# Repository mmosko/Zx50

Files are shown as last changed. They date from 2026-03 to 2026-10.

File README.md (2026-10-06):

# Zx50 Distributed Computer

> **A retro-modern, modular computing platform built around the Zilog Z80 microprocessor — featuring paged virtual
memory, high-speed Shadow DMA, and FPGA coprocessing.**

---

## 1. Welcome to the Zx50

The **Zx50** is a custom, modular computing architecture that marries the classic 8-bit computing ethos of the
late-1970s and 1980s with modern high-speed digital engineering.

At the heart of the system is the **Zilog Z80** microprocessor (inducted into
the [IEEE Spectrum Chip Hall of Fame](https://spectrum.ieee.org/chip-hall-of-fame-zilog-z80-microprocessor),
see the official [Zilog Z80 Datasheet](https://www.zilog.com/docs/z80/um0080.pdf)). 
The Zx50 reimagines the Z80 as a modern distributed computing workstation.

### What makes the Zx50 "Retro-Modern"?

* **Bare-Metal Simplicity**: The CPU executes pure, unadulterated Z80 machine code. You can program it in assembly, C,
  or native BASIC just like classic machines.
* **Breaking the 64KB Limit**: A custom hardware Memory Management Unit (MMU) implemented in a CPLD provides 4KB paged
  virtual memory across 1MB+ of physical SRAM.
* **Dual-Bus Highway**: In addition to the standard Z80 bus, a dedicated **40 MHz Shadow DMA Bus** streams data (network
  packets, disk blocks, and peer-to-peer memory transfers) in the background without halting the Z80.
* **Hardware Acceleration**: A modern FPGA coprocessor offloads 32-bit and 64-bit floating-point math, emulating the
  vintage AMD Am9511 APU with single-cycle lookups.
* **Deep Visibility**: Built-in microcontroller instrumentation (RP2040 and Microchip PIC) allows real-time bus
  snooping, cycle-by-cycle single stepping, and telemetry via an active front panel and bus probe.

Zx50 Bush Architecture

---

## 2. Core Silicon & Chip Manifest

The Zx50 blends period-accurate Zilog NMOS/CMOS silicon with modern programmable logic and companion microcontrollers:

| Chip / Component | Technology | Primary Role in Zx50 |
|:---|:---|:---|
| **Zilog Z84C0020** | CMOS CPU | **Central Processor**: Runs at 8 MHz – 10 MHz with 16-bit addressing and an 8-bit data path. |
| **Zilog Z84C30** | CMOS CTC | **Counter/Timer Circuit**: 4 independent channels generating periodic system ticks and baud rate clocks. |
| **Zilog Z84C40** | CMOS DART/SIO | **Dual Serial Controller**: Dual-channel serial communications (Port 0 for USB console, Port 1 for RS-232) supporting IM 2 vectored interrupts. |
| **Microchip ATF1508** | 5V CPLD | **Memory Controller & MMU**: Address Translation Latch (ATL) mapping 64KB logical address space into 16 independent 4KB pages backed by 1MB+ SRAM. |
| **Lattice MachXO2 / MachXO3** | Flash FPGA | **Math Coprocessor & SmartNIC**: 32-bit/64-bit floating point APU emulation, fast BRAM LUT math, and future LVDS RDMA distributed clustering. |
| **WIZnet W5300** | Hardwired TCP/IP | **10/100 Ethernet Controller**: Memory-mapped window for wire-speed network packet streaming via Z80 `LDIR`/`LDDR` block transfers. |
| **WCH CH376S** | Mass Storage IC | **USB Host & SD Card Controller**: Hardware FAT16/FAT32 file manager mapped into the Z80 I/O space. |
| **Raspberry Pi RP2040** | Dual ARM Cortex-M0+ | **Instrumentation & Display**: Drives the Front Panel display/switches and coordinates circular trace buffers on the Bus Probe. |
| **Microchip PIC18F4620** | 8-bit MCU | **Real-Time Bus Interface**: Works alongside the RP2040 on the Bus Probe for cycle sampling, pin toggling, and non-intrusive bus analysis. |

---

## 3. System Topology & Card Placement

The Zx50 chassis utilizes an 8-slot passive backplane bus.

### Chassis Slot Tour

* **Card 0: Front Panel**: System human interface featuring a 20x4 LCD, step/run switches, bus activity
  LEDs, and an RP2040 controller mapped to I/O port `0x50`.
* **Card 1: CPU, Clock & FPU FPGA**: Houses the 10 MHz Z80 CPU, the Clock Mezzanine (generating system `ZCLK` and
  `MCLK`), and the FPGA floating-point coprocessor.
* **Card 2: Timer + Serial**: Combines the Z80 CTC and Z80 DART with a dedicated 7.3728 MHz baud oscillator, providing
  dual serial channels (FTDI USB and MAX232 RS-232).
* **Card 3: Memory 0 (Boot / Primary)**: Contains the ATF1508 CPLD MMU, 1MB fast 12ns SRAM, 512KB Flash boot ROM (with
  automatic ROM kill-switch upon boot jump), and Shadow Bus DMA interface.
* **Card 4: Memory 1 (Secondary / NUMA)**: Secondary memory card providing an additional 1MB SRAM and participating in
  peer-to-peer Shadow Bus memory transfers.
* **Card 5: NetStorage (Future)**: Dual-purpose network and storage adapter combining W5300 10/100 Ethernet and CH376S
  USB/SD mass storage with direct 40 MHz Shadow DMA support.
* **Card 6: Expansion Slot (Future)**: Dedicated slot for secondary CPU compute tiles, multi-node LVDS RDMA clustering
  (PGAS), or audio/video synthesizers.
* **Card 7: Bus Probe (Rev B)**: Diagnostic and telemetry card featuring CBT3251 high-speed multiplexers for
  non-intrusive bus snooping, an RP2040 trace analyzer, and a color LCD.

---

## 4. The Backplane Bus & Signals

The passive backplane links all cards across a single multi-conductor bus trunk:

| Bus Group | Width | Signals | Description |
|:---|:---|:---|:---|
| **Address** | 16-bit  | `A[15:0]` | Primary Z80 address bus. Snooped by memory card MMUs for 4KB page translations. |
| **Data** | 8-bit | `D[7:0]` | Primary Z80 bidirectional data bus. |
| **Control** | 15-bit  | `C[14:0]` | `~MREQ`, `~IORQ`, `~RD`, `~WR`, `~M1`, `~WAIT`, `~INT`, `~NMI`, `~RESET`, `~BUSRQ`, `~BUSAK`, `~HALT`, `~RFSH`, `IEI`, `IEO`. |
| **Shadow Data** | 9-bit | `SD[8:0]` | High-speed DMA data bus (8 data bits + 1 parity bit). |
| **Shadow Control** | 6-bit | `SC[5:0]` | `~S_EN` (Bus claim), `SRW` (Read/Write), `~SSTB` (Strobe), `~SINC` (Increment), `~S_BUSY` (Target stall), `~S_DONE` (Terminal count). |
| **GPIO** | 16-bit  | `GPIO[15:0]` | General purpose high-speed interconnect and node synchronization lines. |
| **Clocks** | 2 lines | `ZCLK`, `MCLK` | `ZCLK` (8–10 MHz) and `MCLK` (4x ZCLK = 32–40 MHz). |

### AC Bus Termination

To preserve signal integrity at high frequencies without the continuous DC power draw of passive pull-up resistors, all
signal lines are **AC terminated** at both physical ends of the backplane using RC networks tied to GND.

---

## 5. Synchronized Clock Domains

The Zx50 operates across three harmonic clock domains:

```
+-------------------------------------------------------------+
|  Oscillator (32 MHz - 40 MHz)                               |
+-------------------------------------------------------------+
         |                                           |
         v (divide by 4)                             v (direct)
+-------------------------+                 +-------------------------+
|  ZCLK (8 MHz - 10 MHz)  |                 |  MCLK (32 MHz - 40 MHz) |
|  Z80 CPU, CTC, DART     |                 |  Shadow DMA, MMU Timing |
+-------------------------+                 +-------------------------+
                                                         |
                                                         v (PLL / 3x - 4x)
                                            +-------------------------+
                                            |  FPGA (96 MHz - 160 MHz)|
                                            |  FPU Coprocessor Math   |
                                            +-------------------------+
```

1. **`ZCLK` (8 MHz – 10 MHz)**: The fundamental processor clock driving CPU instruction fetch and peripheral cycles.
2. **`MCLK` (32 MHz – 40 MHz = 4x `ZCLK`)**: The synchronous master clock coordinating high-speed burst DMA and CPLD
   state machines.
3. **`FPGA Clock` (96 MHz – 160 MHz = 3x to 4x `MCLK`)**: Synthesized internally inside FPGA coprocessors for
   single-cycle math and DSP acceleration.

---

## 6. High-Speed Shadow DMA

The **Shadow Bus** runs in parallel with the primary Z80 bus to eliminate I/O bottlenecks:

* **Cycle-Stealing Transfers**: Using fast 12ns SRAM, memory cards can service a DMA burst during intervals when the Z80
  is not accessing memory, avoiding `~BUSRQ`/`~BUSAK` pauses.
* **Direct Peer-to-Peer Streaming**: NetStorage can stream Ethernet packets or USB file blocks directly into memory card
  SRAM at **40 MHz** without routing bytes through CPU registers.
* **Deterministic Handshaking**: Uses hardware-level strobes (`~SSTB`, `~SINC`) with target stall flow control
  (`~S_BUSY`).

---

## 7. Software Ecosystem

* **[`zx50_monitor/`](file:///Users/marc/Documents/z80/Zx50/zx50_monitor)**: The self-hosting OS kernel and monitor.
  Transitions from SST39SF040 Flash ROM to SRAM via a hardware "Phantom Jump", featuring interrupt-driven asynchronous
  I/O and lock-free Single-Producer / Single-Consumer (SPSC) ring buffers.
* **[`msbasic/`](file:///Users/marc/Documents/z80/Zx50/msbasic)**: Microsoft BASIC adapted to run natively with full
  terminal, file, and hardware integration.
* **[`z80pack/`](file:///Users/marc/Documents/z80/Zx50/z80pack)**: Full emulator and development testbed for running and
  testing Zx50 software without physical hardware.

---

## 8. Repository Layout

* [`boards/`](file:///Users/marc/Documents/z80/Zx50/boards): KiCad hardware schematics, PCB layouts, and exported
  netlists.
* [`docs/hardware/`](file:///Users/marc/Documents/z80/Zx50/docs/hardware): Detailed hardware subsystem specifications,
  errata, and pinouts.
* [`firmware/`](file:///Users/marc/Documents/z80/Zx50/firmware): Microcontroller firmware for the RP2040 and Microchip
  PIC.
* [`mmu/`](file:///Users/marc/Documents/z80/Zx50/mmu): Verilog HDL code for the ATF1508 CPLD memory controller.
* [`fpu/`](file:///Users/marc/Documents/z80/Zx50/fpu): Verilog HDL and simulation testbenches for the MachXO FPGA math
  coprocessor.
* [`AGENTS.md`](file:///Users/marc/Documents/z80/Zx50/AGENTS.md): Architecture guidelines, design philosophy, and coding
  standards for AI assistants.

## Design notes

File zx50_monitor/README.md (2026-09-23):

# Zx50 Monitor - Session Summary & Resume State

## Programming EEPROM

Remember to add the `-s` flag so minipro will write an undersized ROM image.

```bash
minipro -p SST39SF040 -w monitor.bin -s
```

## 1. Accomplished

We have successfully transitioned from a basic ROM monitor to a stable, self-hosting Operating System kernel capable of downloading, verifying, and executing third-party user-space applications.

* **Dedicated Hardware Clock:** Upgraded the system clock from an Arbitrary Function Generator (AFG) to a dedicated 20MHz oscillator mezzanine. A hardware counter divides this to provide a mathematically perfect 50% duty cycle, 5.000 MHz `ZCLK` baseline.
* **Interrupt-Driven I/O Planning:** Designed a lock-free Single-Producer/Single-Consumer (SPSC) ring buffer architecture to transition the OS from polled serial I/O to fully asynchronous background processing. Engineered a solution to the "Lost Wakeup" race condition using the Z80's native `EI` delay and `HALT` instructions (Detailed in `TTY.md`).
* **Hardware Boot & Memory Paging:** Fixed the `LDIR` register clobbering bug. The physical silicon now successfully maps a 16KB copy window, copies the ROM to SRAM, and executes the "Phantom Jump" to swap out the ROM completely.
* **XMODEM Native File Transfer:** Built a robust, state-machine-driven XMODEM receiver (`apps/xmodem.z80`). It features hardware-accurate polling, adjustable timeout loops to prevent USB NAK-storms, and real-time padding.
* **The PCB & Memory Auditing:** Implemented a Process Control Block (PCB) table in Logical Page 0. When an app is downloaded, the kernel calculates a 16-bit cumulative checksum and logs its exact memory footprint.
* **Kernel Memory Protection:** The XMODEM loader now strictly enforces boundary checks. It actively rejects any attempt to load an executable below `0x2000`, safeguarding the kernel and stack from user-space corruption.
* **The `verify` Command:** Abstracted the checksum math into `pcb_verify.z80`. The CLI `v[erify] <name>` command seamlessly recalculates the payload in SRAM and compares it against the PCB to detect bit-rot or memory corruption before execution.
* **The Zx50 SDK:** Established a formal Page 0 jump table (`syscall.z80`) and wrote the `DEVGUIDE.md`. Developers can write hardware-agnostic standalone `.bin` applications (like `hello.z80`) that compile entirely outside the kernel tree.

## 2. Current System Architecture

### Hardware

Netlists are available under individual card projects in `zx50/boards/`.

| Slot | Card |
|:----:|:---:|
| n/a  | Zx50_Backplane_RevD | 
| n/a  | Zx50_FrontPanelDisplay |
| 1 | Zx50_Cpu_RevB1 + Zx50_Clock_Mezzanine_RevC |
| 2 | Zx50_Serial_RevB |
| 3 | Zx50_MemoryCard_RevA1 (with EEPROM) |
| 4 | (reserved 2nd memory card) |
| 5 | empty |
| 6 | Zx50_FrontPanelCard_RevB |
| 7 | Zx50_Bus_Probe_RevB |
| 8 | empty |

Note: 
- slot 8 has some oscilliscope probes on ZCLK and MCLK. 
- Bus Analyzer is connected to bus probe Z80 Data (J16) and Z80 Contro (J17)l

* **System Clock:** 10.000 MHz `ZCLK` (Divided from 40MHz `MCLK`).
* **Console SIO (Port A):** Command `0x86`, Data `0x84`.
* **Debug SIO (Port B):** Command `0x87`, Data `0x85`. 
* **LCD Front Panel:** Port `0x50`. Mapped to the blue UI display.
* **MMU (Port 0x30):** 4KB physical pages mapped to 16 logical windows.
* **Kernel RAM Layout:** * `0x0000 - 0x0FFF`: The Operating System, PCB Table, and Jump Table API.
  * `0x1000 - 0x1FFF`: The Stack (grows downward from `0x2000`).
  * `0x2000 - 0xFFFF`: User Space / Transient Program Area (TPA).

## 3. Code Layout

The project enforces a strict separation of concerns between the kernel, the shell, built-in apps, and user-space binaries.

```text
zx50_monitor/
├── apps/               # Third-party user-space programs
│   ├── DEVGUIDE.md     # SDK documentation and memory contracts
│   └── hello.z80       # Example standalone application
├── kernel/             # Core OS components
│   ├── apps/           # Built-in kernel utilities
│   │   ├── ddt.z80     # Debugger
│   │   └── xmodem.z80  # Serial file transfer protocol
│   ├── io/             # I/O related activities
│   |   ├── io.z80      # Hardware drivers (SIO, LCD)
│   |   └── ring_buffer.z80 # Lock-free SPSC memory queues
│   ├── pcb/            # Process Control Block logic
│   │   ├── pcb_verify.z80
│   │   └── pcb.z80
│   ├── defines.z80     # System-wide memory & port constants
│   ├── hex.z80         # Hexadecimal parsing & math
│   └── strings.z80     # String manipulation
├── shell/              # Command Line Interface
│   ├── cli.z80         # Main prompt and routing loop
│   ├── cmd_list.z80    # 'l' command
│   ├── cmd_run.z80     # 'r' command
│   ├── cmd_verify.z80  # 'v' command
│   └── readline.z80    # Buffer and backspace handling
├── monitor.z80         # Main bootloader, MMU init, and API Jump Table
├── syscall.z80         # The SDK include file for user apps
├── sio_emulator.js     # DeZog hardware simulation logic
├── sio_ui.html         # DeZog interactive terminal UI
├── README.md           # This file
└── TTY.md              # OS Asynchronous Serial / TTY Architecture Plan
```

## 4. Next Steps (When Resuming)

1. **Implement Ring Buffers:** Integrate the `ring_buffer.z80` logic into the kernel, allocate the 4 instances in Page 0 RAM, and update the syscalls (`Sys_ReadChar`, `Sys_PrintChar`) to use the blocking `HALT` wrappers.
2. **SIO Interrupt Configuration:** Refactor SIO initialization (`io.z80`) to enable IM2 interrupts with the "Status Affects Vector" routing.
3. **ISRs & Line Disciplines:** Write the SIO Rx/Tx Interrupt Service Routines. Implement the Raw/Cooked mode state tracking to allow the Rx ISR to intercept `0x03` (Ctrl+C) and forcibly break infinite loops, returning to the CLI.
4. **PCB Paging (Virtual Memory):** Add a `Page` byte to the `PCB_Entry`. Modify the `xm` and `run` commands to dynamically allocate free physical memory pages, map them into the `0x4000` execution window, and unmap them upon exit to achieve true process isolation.
5. **Multitasking Scheduler:** Leverage the CTC Channel 3 (100Hz) interrupt and the isolated physical pages to implement CP/M 3.0 / UNIX-style preemptive context switching between multiple concurrent applications.

# More on paging

* PCB Paging (Virtual Memory)

This is the holy grail. It turns your simple DOS into a true paged OS (like CP/M 3.0).

How it works: We add a Page byte to PCB_Entry. We write a simple memory manager that knows which of the 16 physical pages are in use.

The architecture: Every single app can be compiled to ORG 0x4000.

When you run xm, the OS finds a free physical page (e.g., Page 4), maps it to the 0x4000 window, downloads the file, and then unmaps it.

When you run the app, the OS looks at the PCB, maps physical Page 4 back into the 0x4000 slot, and CALLs it. When the app RETurns, the OS unmaps it.

The benefit: You never have to worry about memory address collisions again, and apps are completely sandboxed from one another.

## 5. Change History

### 2026-09-13: Serial Driver & Boot Interrupt Fixes
* **Decoupled RTS/CTS Hardware Handshaking:** Removed `SIO_WR3_AUTO_EN` (Auto Enables) from Channel A (Console) and Channel B (Debug) receiver configurations in `kernel/io/serial.z80`. The SIO transmitter now operates freely without requiring an external active-low assertion on `~CTS`, and the receiver does not require `~DCD`.
* **Resolved Premature Boot Interrupts:** Removed `DI` and `EI` instructions from `PrintStringLCD` and `PrintNullStringLCD` in `kernel/io/lcd.z80`. Previously, printing the initial memory boot banner triggered `EI` before the Interrupt Vector Table (`I`), `IM 2`, CTC, and SIO vector base were initialized.
* **Added `SIO_CMD_RST_TX_INT` to `SIO_A_Tx_ISR`:** Added WR0 command `0x28` (`SIO_CMD_RST_TX_INT`) to the `.buffer_empty` handler in `SIO_A_Tx_ISR` to formally reset the SIO's internal transmit interrupt pending latch when the ring buffer runs dry.
* **Dynamic Tx Interrupt Enabling:** Changed `Init_SIO` and `SetTermMode_Inner` so Channel A starts with Tx interrupts disabled in WR1. `Console_Tx` dynamically enables `SIO_WR1_TX_INT_EN` only when bytes are queued in `PORT_A_TX_RB`, and `SIO_A_Tx_ISR` disables it upon draining.
* **Disabled Unused Channel B Tx Interrupts:** Cleared `SIO_WR1_TX_INT_EN` from Channel B, as debug output is synchronously polled via `Debug_Tx`.

## 6. Hardware TODOs & Board Rework

* [ ] **Zx50_Serial_RevB RTS/CTS Handshake Support:**
  * **`DCDA` (Pin 19):** Currently unconnected/floating on `IC2`. Tie to GND or add a 10k pull-down to prevent the receiver from stalling when `Auto Enables` is active.
  * **`CTSA` (Pin 18):** Currently routed only to header `J4 pin 5` and `J3 pin 7` without a pull-down resistor. Add a 10k pull-down so the transmitter remains enabled when connecting via simple 3-wire serial cables (TX/RX/GND).
  * **Firmware Auto-Enables:** Once the pull-downs or jumper options are verified on the board, restore `SIO_WR3_AUTO_EN` in `kernel/io/serial.z80` to re-enable optional hardware flow control.

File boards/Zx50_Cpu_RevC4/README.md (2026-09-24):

# Zx50 CPU Card (Rev C2)

## 1. Overview

This is the primary CPU board for the Zx50 8-slot passive backplane system. It hosts the Z80 microprocessor (running at 5 MHz to 10 MHz) and acts as the master controller for the primary bus.

Revision C2 updates the design with an upgraded **Math and Stack Coprocessor Cluster** mounted on the bottom side beneath the clock mezzanine shield, expanding private coprocessor memory to **32 KB** and introducing a **12 ns high-speed SRAM** to guarantee single-cycle memory operations at 40 MHz.

Crucially, this board coexists with the **Zx50 Shadow Bus** architecture. It features a hardware-level "firewall" that allows a secondary master (like a Pi Pico on the Bus Probe or Front Panel card) to request the bus via `~BUSRQ`. When the Z80 yields (`~BUSAK`), the CPU card instantly severs itself from the backplane, allowing the secondary master to perform high-speed 40 MHz DMA transfers without electrical contention.

---

## 2. Core Architecture & Logic Families

### The CPU

* **Z80 Microprocessor (`U4`):** Zilog `Z84C00xxP` CMOS variant in a 40-pin DIP package (socketed).

### The Transceiver Firewall (`SN74ABT245BN`)

To drive the heavy capacitance of the 8-slot backplane, this board uses four **`SN74ABT245BN`** octal bus transceivers (`U2`, `U3`, `U5`, `U7`) with high-drive capability. A unified BOM of four '245s optimizes PCB trace routing across all 32 backplane lines.

* **Convention:** "A-Ports" face the Z80; "B-Ports" face the Backplane.
* **Address Bus (`U2`, `U3`):** Direction (`DIR`) is hardwired to `+5V` (A $\rightarrow$ B only).
* **Control Bus (`U7`):** Direction (`DIR`) is hardwired to `+5V` (A $\rightarrow$ B only). *(Unused input `A8` is tied to GND via a 10k$\Omega$ resistor `R2` to prevent CMOS floating-gate oscillation)*.
* **Data Bus (`U5`):** Direction (`DIR`) is dynamically controlled by read/acknowledge steering logic (`D_DIR` driven by `U8` / `R8`). This switches the transceiver to an input state (B $\rightarrow$ A) during standard memory/IO reads or Interrupt Acknowledge (`INTA`) cycles.
* **Isolation (`~OE`):** The `~OE` pins of all four transceivers are driven by inverted `~BUSAK` (`/BUSAK` from `U1` pin 4).

### Glue Logic & Bus Coordination

Discrete "Little Logic" and micro-logic ICs handle high-speed signal translation:

* **`74AHC1G14` (`U1` - Schmitt Inverter):** Inverts the Z80's active-low `~BUSAK` signal to drive the active-low `~OE` pins of the transceiver wall.
* **`74AHCT74` (`U9` - Dual D Flip-Flop):** Latches timing states for wait-state generation.
* **`74AHCT132` (`U10` - Quad Schmitt NAND):** Handles pulse shaping and step-logic gating for debugging.
* **`74LVC1G3208` (`U8` - 3-Input OR-AND Combo):** Manages direction and enable logic for auxiliary bus controls.

---

## 3. Hardware Wait-State Generator (`wait_gen`) Subsystem

The board incorporates a dedicated hardware wait-state generator to support single-step debugging and cycle stretching during fast coprocessor or backplane operations:

* **Dual D Flip-Flop (`SN74AHCT74DRG4` / `U9`):** Latches bus cycle transitions relative to `ZCLK` and `~M1`/`~IORQ`/`~MREQ` edges.
* **Quad Schmitt-Trigger NAND (`74AHCT132` / `U10`):** Provides noise-tolerant pulse shaping and single-step gate logic.
* **Open-Drain Output (`2N7002-7-F` N-Channel MOSFET / `Q2`):** Drives the active-low `~WAIT` line without contention, allowing other cards or the CPLD to safely assert `~WAIT`.
* **Modes Supported:**
1. **Single-Step Execution:** Holds `~WAIT` low at $T_2$/$T_3$ until a manual step pulse is received from the Clock Mezzanine (`J3`) or Front Panel (`J4`).
2. **Programmable Cycle Stretching:** Generates accurate 1-cycle hold states for memory or I/O windows.

---

## 4. Integrated Math & Stack Coprocessor Cluster (Bottom Layer)

Mounted entirely on the back side of the board beneath the Clock Mezzanine copper shield, a high-performance CPLD cluster operates on a dedicated private memory bus.

```text
                  +-----------------------------------+
                  |   ATF1508AS CPLD (PLCC-84 / U11)  |
                  |   Dual Clocks: 20MHz MCLK / 5MHz ZCLK|
                  +-----+-----------------------+-----+
                        |                       |
           CA0-CA14     |                       |  CD0-CD7
         Private Address|                       |  Private Data
                        v                       v
            +-----------+-----------------------+-----------+
            |                                               |
            |   +-------------------+   +---------------+   |
            |   | SST39SF040 Flash  |   | IS61C256AL    |   |
            |   | 32KB Active (55ns)|   | 32KB Active   |   |
            |   | PLCC-32 (U13)     |   | SRAM 28-TSOP1 |   |
            |   +---------+---------+   +-------+-------+   |
            |             |                     |           |
            |             |     ~C_OE / ~C_WE   |           |
            |             +----------+----------+           |
            |                        |                      |
            |               ~F_CE <--+--> ~M_CE             |
            +-----------------------------------------------+

```

### 1. Central Controller (`ATF1508ASx-xxJx84` / `U11`)

* **Package:** 128-macrocell CPLD in an 84-pin PLCC surface-mount socket.
* **Dual Clock Architecture:** Driven by both **20/40 MHz `MCLK**` (`GCLK1`, Pin 83) and **5/10 MHz `ZCLK**` (`CLK`, Pin 2) from the clock mezzanine (`J3`). The internal state machine executes at `MCLK` speed, enabling sub-cycle arithmetic and table lookups before the Z80 samples data.
* **Features:** Hardware multiplication (Quarter-Square algorithm), fast division seed generation, 16.16 fixed-point ALU, trigonometric LUT queries, and custom DMA/stack frame acceleration.

### 2. Private Memory Architecture (Zero `~BUSREQ` Contention)

The CPLD manages its own dedicated private address (`CA0`–`CA14`) and data (`CD0`–`CD7`) buses, isolating coprocessor memory operations from the primary Z80 system bus:

* **Expanded Private Address Space (32 KB):** A full 15-bit address bus (`CA0`–`CA14`) provides **32 KB** of addressable private memory. Upper unused address lines (`A15`–`A18`) on the Flash ROM (`U13`) are tied directly to **`GND`** to guarantee static CMOS levels.
* **Private Flash/EEPROM (`SST39SF040` / `U13`):** 32 KB active window (55 ns NOR Flash) in a 32-pin PLCC footprint (`CONN_PLCC-32-AT-SMT_ADM`). Stores non-volatile lookup tables (Quarter-Square $f(n)=\lfloor n^2/4 \rfloor$, sine/cosine maps, logarithmic tables, reciprocal seeds).
* **Private High-Speed SRAM (`IS61C256AL-12TLI` / `U12`):** 32 KB active window (12 ns High-Speed Static RAM) in a 28-pin TSOP-I footprint. Operates as a private scratchpad, hardware stack frame storage, or modifiable shadow RAM.
* **Consolidated Control Busses:** Read enable (`~C_OE`, Pin 45) and write strobe (`~C_WE`, Pin 46) are shared across both memory ICs. Access targeting is handled via dedicated Chip Enable lines (`~M_CE` on Pin 44 for SRAM; `~F_CE` on Pin 68 for Flash).
* **Pull-Up Protection:** `~M_CE` and `~F_CE` lines are fitted with $10\text{ k}\Omega$ pull-up resistors (`R7`, `R10`) to $+5\text{V}$ to keep both memory chips deselected and High-Z during power-up or CPLD JTAG re-programming.

### 3. Private Memory Access Speed Selector (`J8` - `MEM SPD`)

To support both 20 MHz and 40 MHz `MCLK` speeds without requiring CPLD bitstream re-flashing:

* **Header (`J8`):** 2-pin (1x2) 2.54mm pin header connected to CPLD Pin 81 (`I/O/GCLK3`) with a $10\text{ k}\Omega$ pull-up resistor (`R5`) to $+5\text{V}$.
* **Jumper Open (High / Default):** Standard mode.
* **Jumper Shorted to GND (Low):** High-speed 1-cycle pipeline selection.

### 4. JTAG In-System Programming

* **Header (`J7`):** 6-pin (1x6) 2.54mm male header.
* **Pinout:** $+5\text{V}$ (Pin 1), `GND` (Pin 2), `TMS` (Pin 3), `TDO` (Pin 4), `TDI` (Pin 5), `TCLK` (Pin 6). Compatible with Waveshare USB-JTAG converters and OpenOCD.
* **Offline Option:** The PLCC-32 Flash chip can be extracted and programmed offline using a T48 / TL866-3G universal programmer.

---

## 5. Power-On Reset (POR) Subsystem

Handled by a **Microchip `MCP1316MT-46LE/OT**` Supervisor IC (SOT-23-5, `U6`).

* **Boot Delay:** Imposes a ~200 ms delay on power-up to allow bulk capacitors ($100\,\mu\text{F}$ `C9`) to charge and peripheral clock sources/Picos to initialize before releasing `~RESET`.
* **Threshold:** 4.6V trip point for brown-out protection.
* **Open-Drain Output:** Safely drives the shared `~RESET` rail (`Pin 1`).
* **Manual Reset (`SW1`):** Tactile button connected to `~MR` (`Pin 3`) for debounced hardware reset during bench testing.

---

## 6. 6-Layer Stackup & PCB Routing Strategy

Revision C2 uses a **6-layer stackup** to accommodate the high-density coprocessor cluster beneath the top-side clock shield without interfering with front-side copper:

| Layer | Type | Dedicated Function |
| --- | --- | --- |
| **Layer 1 (Top)** | Signal / Plane | Primary Z80 component traces, Clock Mezzanine RF shield copper ground pour |
| **Layer 2 (GND)** | Power Plane | Continuous $GND$ reference plane |
| **Layer 3 (Inner 1)** | Signal | **Private Coprocessor Bus:** `CA0`–`CA14`, `CD0`–`CD7`, and private control lines (`~M_CE`, `~F_CE`, `~C_OE`, `~C_WE`) |
| **Layer 4 (Inner 2)** | Signal | **Z80 Bus Ingest:** Taps `A0`–`A15`, `D0`–`D7`, and control lines from `U4` to the CPLD |
| **Layer 5 (VCC)** | Power Plane | Continuous $+5\text{V}$ power distribution plane |
| **Layer 6 (Bottom)** | Signal / SMT | Bottom-mounted SMT footprints: ATF1508AS PLCC-84 (`U11`), SST39SF040 PLCC-32 (`U13`), IS61C256AL TSOP-I-28 (`U12`) |

---

## 7. Interfaces & Connectors

| Connector | Type | Description |
| --- | --- | --- |
| **`J1` - Backplane** | 80-Pin Edge Connector | Standard Zx50 2.54mm bus interface. |
| **`J2` - Bus Connect / Step Tap** | 2x2 Pin Socket | Tap for `AUX` (Pin 80), `GPIO15`, `~STEP`, and `~RUN` signals. |
| **`J3` - Clock Mezzanine** | 2x5 Socket (2.54mm) | Ingests `MCLK` (20/40 MHz), `CLK` (5/10 MHz ZCLK), and `~STEP` signals. |
| **`J4` - Front Panel** | 2x5 Right-Angle IDC | Interfaces status LEDs (`RUN`, `HALT`), `~RESET`, `~STEP`, and power lines. |
| **`J5` - TP_D_DIR Debug** | 1x2 Header (2.54mm) | Hardware tap for Data Bus Direction monitoring and GND test point. |
| **`J6` - TP_BUSAK Debug** | 1x2 Header (2.54mm) | Hardware tap for `~BUSAK` signal observation. |
| **`J7` - Coprocessor JTAG** | 1x6 Header (2.54mm) | In-System Programming header for the ATF1508AS CPLD (`+5V`, `GND`, `TMS`, `TDO`, `TDI`, `TCLK`). |
| **`J8` - MEM SPD Jumper** | 1x2 Header (2.54mm) | Hardware jumper for private memory access speed selection (`Pin 81` / `R5`). |

---

## 8. Estimated Power Consumption Analysis

Operating at $5\text{V}$, the Rev C2 CPU card draws a typical active current of **~170 mA (~0.85 W)** and a worst-case peak switching current of **~280 mA (~1.40 W)**. The power load is split between the primary Z80 CPU subsystem and the high-speed coprocessor cluster.

### A. Primary CPU & Bus Interface Subsystem

| Component | Part Number | Qty | Typ. Current | Max Current | Notes |
| --- | --- | --- | --- | --- | --- |
| **Z80 CPU (10 MHz)** | `Z84C00xxP` | 1 | 10 mA | 20 mA | CMOS low-power core |
| **Bus Transceivers** | `SN74ABT245BN` | 4 | 15 mA | 40 mA | Drives 8-slot backplane capacitance |
| **Wait-State Logic** | `74AHCT74` / `132` | 2 | 8 mA | 15 mA | Dual D-FF & Schmitt NAND gates |
| **Glue Logic & Supervisor** | `74AHC1Gxx` / `MCP1316` | 5 | 3 mA | 5 mA | SOT-23 micro-logic & reset controller |
| **Status LEDs & Pull-ups** | `PWR`, `HALT` LEDs | 2 | 8 mA | 10 mA | ~$470\Omega$ current limiting |
| **Subtotal (CPU Side)** |  |  | **~44 mA** | **~90 mA** | **~0.22 W Typ / 0.45 W Max** |

### B. Coprocessor Cluster Subsystem (Bottom Layer)

| Component | Part Number | Qty | Typ. Current | Max Current | Notes |
| --- | --- | --- | --- | --- | --- |
| **CPLD (20/40 MHz MCLK)** | `ATF1508ASx-xxJx84` | 1 | 65 mA | 100 mA | Dynamic $I_{CC}$ scales with MCLK frequency |
| **Private SRAM (12 ns)** | `IS61C256AL-12TLI` | 1 | 15 mA | 30 mA | Active read/write state |
| **Private Flash (55 ns)** | `SST39SF040` | 1 | 15 mA | 30 mA | Active table read state |
| **Subtotal (Coprocessor)** |  |  | **~95 mA** | **~160 mA** | **~0.48 W Typ / 0.80 W Max** |

### C. Total Card Power Summary

* **Typical Active Load:** **139 mA – 170 mA** (~0.70 W – 0.85 W @ 5V)
* **Maximum Peak Load:** **250 mA – 280 mA** (~1.25 W – 1.40 W @ 5V)

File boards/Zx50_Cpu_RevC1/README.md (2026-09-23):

# Zx50 CPU Card (Rev C1)

## 1. Overview

This is the primary CPU board for the Zx50 8-slot passive backplane system. It hosts the Z80 microprocessor (running at 5 MHz to 10 MHz) and acts as the master controller for the primary bus.

Revision C1 updates the design to a **6-layer stackup**, integrating a high-performance **Math and Stack Coprocessor Cluster** mounted on the bottom side beneath the clock mezzanine shield, along with a dedicated hardware **Wait-State Generator (`wait_gen`)**.

Crucially, this board coexists with the **Zx50 Shadow Bus** architecture. It features a hardware-level "firewall" that allows a secondary master (like a Pi Pico on the Bus Probe or Front Panel card) to request the bus via `~BUSRQ`. When the Z80 yields (`~BUSAK`), the CPU card instantly severs itself from the backplane, allowing the secondary master to perform high-speed 40 MHz DMA transfers without electrical contention.

---

## 2. Core Architecture & Logic Families

### The CPU
* **Z80 Microprocessor (`U4`):** Zilog `Z84C00xxP` CMOS variant in a 40-pin DIP package (socketed).

### The Transceiver Firewall (`SN74ABT245BN`)
To drive the heavy capacitance of the 8-slot backplane, this board uses four **`SN74ABT245BN`** octal bus transceivers (`U2`, `U3`, `U5`, `U7`) with high-drive capability. A unified BOM of four '245s optimizes PCB trace routing across all 32 backplane lines.
* **Convention:** "A-Ports" face the Z80; "B-Ports" face the Backplane.
* **Address Bus (`U2`, `U3`):** Direction (`DIR`) is hardwired to `+5V` (A $\rightarrow$ B only).
* **Control Bus (`U7`):** Direction (`DIR`) is hardwired to `+5V` (A $\rightarrow$ B only). *(Unused input `A8` is tied to GND via a 10k$\Omega$ resistor `R2` to prevent CMOS floating-gate oscillation)*.
* **Data Bus (`U5`):** Direction (`DIR`) is dynamically controlled by read/acknowledge steering logic (`D_DIR` driven by `U8` / `R8`). This switches the transceiver to an input state (B $\rightarrow$ A) during standard memory/IO reads or Interrupt Acknowledge (`INTA`) cycles.
* **Isolation (`~OE`):** The `~OE` pins of all four transceivers are driven by inverted `~BUSAK` (`/BUSAK` from `U1` pin 4).

### Glue Logic & Bus Coordination
Discrete "Little Logic" and micro-logic ICs handle high-speed signal translation:
* **`74AHC1G14` (`U1` - Schmitt Inverter):** Inverts the Z80's active-low `~BUSAK` signal to drive the active-low `~OE` pins of the transceiver wall.
* **`74AHCT74` (`U9` - Dual D Flip-Flop):** Latches timing states for wait-state generation.
* **`74AHCT132` (`U10` - Quad Schmitt NAND):** Handles pulse shaping and step-logic gating for debugging.
* **`74LVC1G3208` (`U8` - 3-Input OR-AND Combo):** Manages direction and enable logic for auxiliary bus controls.

---

## 3. Hardware Wait-State Generator (`wait_gen`) Subsystem

The board incorporates a dedicated hardware wait-state generator to support single-step debugging and cycle stretching during fast coprocessor or backplane operations:
* **Dual D Flip-Flop (`SN74AHCT74DRG4` / `U9`):** Latches bus cycle transitions relative to `ZCLK` and `~M1`/`~IORQ`/`~MREQ` edges.
* **Quad Schmitt-Trigger NAND (`74AHCT132` / `U10`):** Provides noise-tolerant pulse shaping and single-step gate logic.
* **Open-Drain Output (`2N7002-7-F` N-Channel MOSFET / `Q2`):** Drives the active-low `~WAIT` line without contention, allowing other cards or the CPLD to safely assert `~WAIT`.
* **Modes Supported:**
  1. **Single-Step Execution:** Holds `~WAIT` low at $T_2$/$T_3$ until a manual step pulse is received from the Clock Mezzanine (`J3`) or Front Panel (`J4`).
  2. **Programmable Cycle Stretching:** Generates accurate 1-cycle hold states for memory or I/O windows.

---

## 4. Integrated Math & Stack Coprocessor Cluster (Bottom Layer)

Mounted entirely on the back side of the board beneath the Clock Mezzanine copper shield, a high-performance CPLD cluster operates on a dedicated private memory bus.

```text
                  +-----------------------------------+
                  |   ATF1508AS CPLD (PLCC-84 / U11)  |
                  |   Dual Clocks: 20MHz MCLK / 5MHz ZCLK|
                  +-----+-----------------------+-----+
                        |                       |
           CA0-CA13     |                       |  CD0-CD7
         Private Address|                       |  Private Data
                        v                       v
            +-----------+-----------------------+-----------+
            |                                               |
            |   +-------------------+   +---------------+   |
            |   | SST39SF040 Flash  |   | IS61C5128AS   |   |
            |   | 16KB Active (55ns)|   | 16KB Active   |   |
            |   | PLCC-32 (U13)     |   | SRAM 32-SOP   |   |
            |   +---------+---------+   +-------+-------+   |
            |             |                     |           |
            |             | ~F_CE / ~F_OE / ~F_WE| ~M_CE / ~M_OE / ~M_WE
            +-------------+---------------------+-----------+
```

### 1. Central Controller (`ATF1508ASx-xxJx84` / `U11`)
* **Package:** 128-macrocell CPLD in an 84-pin PLCC surface-mount socket.
* **Dual Clock Architecture:** Driven by both **20/40 MHz `MCLK`** (`GCLK1`, Pin 83) and **5/10 MHz `ZCLK`** (`CLK`, Pin 2) from the clock mezzanine (`J3`). The internal state machine executes at `MCLK` speed, enabling sub-cycle arithmetic and table lookups before the Z80 samples data.
* **Features:** Hardware multiplication (Quarter-Square algorithm), fast division seed generation, 16.16 fixed-point ALU, trigonometric LUT queries, and custom DMA/stack frame acceleration.

### 2. Private Memory Architecture (Zero `~BUSREQ` Contention)
The CPLD manages its own dedicated private address (`CA0`–`CA13`) and data (`CD0`–`CD7`) buses, isolating coprocessor memory operations from the primary Z80 system bus:
* **Private Address Space (16 KB):** A 14-bit address bus (`CA0`–`CA13`) provides 16 KB of addressable private memory space. Upper address lines (`A14`–`A18`) on both memory ICs are tied directly to **`GND`** to guarantee static CMOS levels and prevent floating pin oscillations.
* **Private Flash/EEPROM (`SST39SF040` / `U13`):** 16 KB active window (55 ns NOR Flash) in a 32-pin PLCC socket. Stores non-volatile lookup tables (Quarter-Square $f(n)=\lfloor n^2/4 \rfloor$, sine/cosine maps, logarithmic tables, reciprocal seeds).
* **Private SRAM (`IS61C5128AS-25QLI` / `U12`):** 16 KB active window (25 ns High-Speed Static RAM) in a 32-pin SOP footprint. Serves as private scratchpad, hardware stack frame storage, or modifiable shadow RAM.
* **Pull-up Protection:** `~M_CE` and `~F_CE` lines are fitted with $10\text{ k}\Omega$ pull-up resistors (`R7`, `R10`) to $+5\text{V}$ to keep both memory chips deselected and High-Z during power-up or CPLD JTAG re-programming.

### 3. Private Memory Access Speed Selector (`J8` - `MEM SPD`)
To support both 20 MHz and 40 MHz `MCLK` speeds without requiring CPLD bitstream re-flashing:
* **Header (`J8`):** 2-pin (1x2) 2.54mm pin header connected to CPLD Pin 81 (`I/O/GCLK3`) with a $10\text{ k}\Omega$ pull-up resistor (`R5`) to $+5\text{V}$.
* **Jumper Open (High / Default):** Selects **2-cycle private access pipeline** (safe access window for 40 MHz `MCLK` with 25 ns SRAM).
* **Jumper Shorted to GND (Low):** Selects **1-cycle private access pipeline** (fast mode for 20 MHz `MCLK`).

### 4. JTAG In-System Programming
* **Header (`J7`):** 6-pin (1x6) 2.54mm male header.
* **Pinout:** $+5\text{V}$ (Pin 1), `GND` (Pin 2), `TMS` (Pin 3), `TDO` (Pin 4), `TDI` (Pin 5), `TCLK` (Pin 6). Compatible with Waveshare USB-JTAG converters and OpenOCD.
* **Offline Option:** The PLCC-32 Flash chip can be extracted and programmed offline using a T48 / TL866-3G universal programmer.

---

## 5. Power-On Reset (POR) Subsystem

Handled by a **Microchip `MCP1316MT-46LE/OT`** Supervisor IC (SOT-23-5, `U6`).
* **Boot Delay:** Imposes a ~200 ms delay on power-up to allow bulk capacitors ($100\,\mu\text{F}$ `C9`) to charge and peripheral clock sources/Picos to initialize before releasing `~RESET`.
* **Threshold:** 4.6V trip point for brown-out protection.
* **Open-Drain Output:** Safely drives the shared `~RESET` rail (`Pin 1`).
* **Manual Reset (`SW1`):** Tactile button connected to `~MR` (`Pin 3`) for debounced hardware reset during bench testing.

---

## 6. 6-Layer Stackup & PCB Routing Strategy

Revision C1 uses a **6-layer stackup** to accommodate the high-density coprocessor cluster beneath the top-side clock shield without interfering with front-side copper:

| Layer | Type | Dedicated Function |
| :--- | :--- | :--- |
| **Layer 1 (Top)** | Signal / Plane | Primary Z80 component traces, Clock Mezzanine RF shield copper ground pour |
| **Layer 2 (GND)** | Power Plane | Continuous $GND$ reference plane |
| **Layer 3 (Inner 1)** | Signal | **Private Coprocessor Bus:** `CA0`–`CA13`, `CD0`–`CD7`, and private control lines (`~M_CE`, `~M_OE`, `~M_WE`, `~F_CE`, `~F_OE`, `~F_WE`) |
| **Layer 4 (Inner 2)** | Signal | **Z80 Bus Ingest:** Taps `A0`–`A15`, `D0`–`D7`, and control lines from `U4` to the CPLD |
| **Layer 5 (VCC)** | Power Plane | Continuous $+5\text{V}$ power distribution plane |
| **Layer 6 (Bottom)** | Signal / SMT | Bottom-mounted SMT footprints: ATF1508AS PLCC-84 (`U11`), SST39SF040 PLCC-32 (`U13`), IS61C5128AS SOP-32 (`U12`) |

---

## 7. Interfaces & Connectors

| Connector | Type | Description |
| :--- | :--- | :--- |
| **`J1` - Backplane** | 80-Pin Edge Connector | Standard Zx50 2.54mm bus interface. |
| **`J2` - Bus Connect / Step Tap** | 2x2 Pin Socket | Tap for `AUX` (Pin 80), `GPIO15`, `~STEP`, and `~RUN` signals. |
| **`J3` - Clock Mezzanine** | 2x5 Socket (2.54mm) | Ingests `MCLK` (20/40 MHz), `CLK` (5/10 MHz ZCLK), and `~STEP` signals. |
| **`J4` - Front Panel** | 2x5 Right-Angle IDC | Interfaces status LEDs (`RUN`, `HALT`), `~RESET`, `~STEP`, and power lines. |
| **`J5` - TP_D_DIR Debug** | 1x2 Header (2.54mm) | Hardware tap for Data Bus Direction monitoring and GND test point. |
| **`J6` - TP_BUSAK Debug** | 1x2 Header (2.54mm) | Hardware tap for `~BUSAK` signal observation. |
| **`J7` - Coprocessor JTAG** | 1x6 Header (2.54mm) | In-System Programming header for the ATF1508AS CPLD (`+5V`, `GND`, `TMS`, `TDO`, `TDI`, `TCLK`). |
| **`J8` - MEM SPD Jumper** | 1x2 Header (2.54mm) | Hardware jumper for 1-cycle vs 2-cycle private memory access speed selection (`Pin 81` / `R5`). |

---

## 8. Estimated Power Consumption Analysis

Operating at $5\text{V}$, the Rev C1 CPU card draws a typical active current of **~170 mA (~0.85 W)** and a worst-case peak switching current of **~280 mA (~1.40 W)**. The power load is split between the primary Z80 CPU subsystem and the high-speed coprocessor cluster.

### A. Primary CPU & Bus Interface Subsystem

| Component | Part Number | Qty | Typ. Current | Max Current | Notes |
| :--- | :--- | :---: | :---: | :---: | :--- |
| **Z80 CPU (10 MHz)** | `Z84C00xxP` | 1 | 10 mA | 20 mA | CMOS low-power core |
| **Bus Transceivers** | `SN74ABT245BN` | 4 | 15 mA | 40 mA | Drives 8-slot backplane capacitance |
| **Wait-State Logic** | `74AHCT74` / `132` | 2 | 8 mA | 15 mA | Dual D-FF & Schmitt NAND gates |
| **Glue Logic & Supervisor** | `74AHC1Gxx` / `MCP1316` | 5 | 3 mA | 5 mA | SOT-23 micro-logic & reset controller |
| **Status LEDs & Pull-ups** | `PWR`, `HALT` LEDs | 2 | 8 mA | 10 mA | ~$470\Omega$ current limiting |
| **Subtotal (CPU Side)** | | | **~44 mA** | **~90 mA** | **~0.22 W Typ / 0.45 W Max** |

### B. Coprocessor Cluster Subsystem (Bottom Layer)

| Component | Part Number | Qty | Typ. Current | Max Current | Notes |
| :--- | :--- | :---: | :---: | :---: | :--- |
| **CPLD (20/40 MHz MCLK)** | `ATF1508ASx-xxJx84` | 1 | 65 mA | 100 mA | Dynamic $I_{CC}$ scales with MCLK frequency |
| **Private SRAM (25 ns)** | `IS61C5128AS-25QLI` | 1 | 15 mA | 30 mA | Active read/write state |
| **Private Flash (55 ns)** | `SST39SF040` | 1 | 15 mA | 30 mA | Active table read state |
| **Subtotal (Coprocessor)** | | | **~95 mA** | **~160 mA** | **~0.48 W Typ / 0.80 W Max** |

### C. Total Card Power Summary
* **Typical Active Load:** **139 mA – 170 mA** (~0.70 W – 0.85 W @ 5V)
* **Maximum Peak Load:** **250 mA – 280 mA** (~1.25 W – 1.40 W @ 5V)

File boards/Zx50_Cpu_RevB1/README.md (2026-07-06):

# Zx50 CPU Card

## 1. Overview

This is the primary CPU board for the Zx50 8-slot passive backplane system. It hosts the Z80 microprocessor (running at
8 to 10 MHz) and acts as the master controller for the primary bus.

Crucially, this board is designed to coexist with the **Zx50 Shadow Bus** architecture. It features a hardware-level "
firewall" that allows a coprocessor (like a Pi Pico on the Bus Probe or Front Panel card) to request the bus via
`~BUSRQ`. When the Z80 yields (`~BUSAK`), the CPU card instantly severs itself from the backplane, allowing the Pico to
perform high-speed 40MHz DMA transfers without electrical contention.

## 2. Core Architecture & Logic Families

### The CPU

* **Z80 Microprocessor:** Zilog `Z84C00xxP` CMOS variant in a 40-pin DIP package.

### The Transceiver Firewall (`74AHCT245`)

To drive the heavy capacitance of the 8-slot backplane, standard `74HC` logic is insufficient. This board uses *
*`74AHCT245`** octal bus transceivers (±8mA drive current) for all bus interfacing.
To optimize PCB trace routing, a unified BOM of four '245s is used (rather than mixing in '244s).

* **Convention:** "A-Ports" face the Z80; "B-Ports" face the Backplane.
* **Address Bus (x2):** `DIR` is hardwired to `+5V` (A -> B only).
* **Control Bus (x1):** `DIR` is hardwired to `+5V` (A -> B only). *(Note: The unused `A8` input on this buffer is tied
  to GND via a 10kΩ pull-up to prevent CMOS floating-gate oscillation)*.
* **Data Bus (x1):** `DIR` is dynamically controlled by a dedicated read/acknowledge logic steering circuit. This
  ensures that the transceiver switches to an input state (B -> A) during standard memory/IO reads **or** during an
  Interrupt Acknowledge (INTA) cycle, preventing backplane bus contention.
* **Isolation (`~OE`):** The `~OE` pins of all four transceivers are driven by an inverted `~BUSAK` signal.

### Glue Logic & Bus Coordination

"Little Logic" SOT-23-5 discrete gates are used to handle high-speed bus control signal translation without the
footprint of full-sized DIP packages:

* **`74AHC1G14` (Schmitt-Trigger Inverter):** Inverts the Z80's active-low `~BUSAK` signal to correctly drive the
  active-low `~OE` pins of the transceiver wall.
* **`74AHC1G32` (2-Input OR Gate):** Monitors `~M1` and `~IORQ`. Its output drops LOW exclusively during an Interrupt
  Acknowledge (INTA) cycle.
* **`74AHC1G08` (2-Input AND Gate):** Compares the INTA state with the Z80's `~RD` line. The output connects directly to
  Pin 1 (`DIR`) of the Data Bus Transceiver, dropping the bus into Input mode whenever a hardware vector or memory read
  is requested.

## 3. Power-On Reset (POR) Subsystem

The Master Reset logic is completely handled by a **Microchip `MCP1318MT-46LE/OT`** Supervisor IC (SOT-23-5, Digi-Key:
`MCP1318MT-46LE/OTCT-ND`).

* **The Boot Delay:** It imposes a strict ~200ms delay on power-up. This guarantees the 1000µF backplane bulk
  capacitance is fully charged, the clock oscillators are stable, and the Pi Pico bootloaders on the peripheral cards
  have fully initialized before the Z80 takes its first step.
* **Voltage Threshold:** Trips at 4.6V to prevent brown-out corruption.
* **Open-Drain Output:** Safely shares the backplane's `~RESET` line with other cards that may pull the line low.
* **No Watchdog:** The `1318M` specifically omits the hardware watchdog timer (unlike the 1316M), preventing accidental
  Z80 reboots during extended Pi Pico DMA operations.
* **Local Button:** A right-angle tactile switch (`Omron B3F` / Digi-Key: `SW402-ND`) is wired to the `~MR` (Manual
  Reset) pin, providing perfect, capacitor-free hardware debouncing for bench testing.

## 4. Interfaces

* **J1 - Backplane:** Standard Zx50 80-pin Edge Connector.
* **J3 - Clock Mezzanine (2x5 Socket):** Receives `MCLK` (40MHz), `CLK` (10MHz ZCLK), and manages the async-latched
  `~STEP` signals from the Zx50 Clock Mezzanine module.
* **J4 - Front Panel (2x5 Header):** Mirrors the signals sent to the system Front Panel. Includes `RUN`, `~STEP`,
  `~RESET`, and `TX`/`RX` paths. The `~STEP` signal is routed down to the backplane's `AUX` pin (Pin 80) to coordinate
  with the Clock Mezzanine and Bus Probe.

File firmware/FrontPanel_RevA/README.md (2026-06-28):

# Zx50 Front Panel Firmware

## 1. Overview

This directory contains the MicroPython firmware for the Raspberry Pi Pico on the Zx50 Front Panel Controller card.

The firmware's primary responsibilities are:

- **Passive Bus Monitoring:** Reading the Z80's address, data, and status buses without halting the CPU and displaying
  this information in real-time on the front panel's dot-matrix displays.
- **Active I/O Device:** Acting as a target for Z80 `OUT` instructions, specifically capturing high-speed `OTIR` block
  transfers to a FIFO buffer for display on the character LCD.
- **Hardware Control:** Managing the front panel switches (`RUN`, `STEP`, `DISP_EN`) to control the display's behavior
  and, in the future, to control the Z80's `~WAIT` and `~RESET` lines.

## 2. Code Structure

The firmware is organized into several modules:

- `main.py`: The main application entry point. It contains the primary control loop, state management for the front
  panel switches, and orchestrates calls to the other modules.
- `pins.py`: Centralized definitions for all GPIO pin assignments and SPI bus configurations. This is the canonical
  source for hardware connections.
- `lcd.py`: Driver for the 4x20 character LCD. It handles the unique, bit-reversed, LSB-first SPI protocol required by
  the EA DIP205G-4NLED display.
- `leds.py`: Driver for the HCMS dot-matrix displays and the discrete status LEDs (driven by a 74HC595 shift register).
- `font.py`: Contains the 5x7 font data for rendering both standard ASCII characters and custom status glyphs on the
  HCMS displays.
- `z80_io.py`: Manages the high-speed interaction with the Z80 bus. It contains the interrupt service routine (`IRQ`)
  that captures data from `OTIR` instructions and places it into a shared FIFO.

## 3. Key Implementation Details & Maintenance Notes

This firmware has several particularities that are critical for maintenance and future development:

### Dynamic SPI Bus Configuration

The SPI bus (`SPI(0)`) is shared by two devices with incompatible SPI modes:

1. **LCD Display:** Requires `baudrate=500,000`, `polarity=1`, `phase=1`.
2. **HCMS Displays & LED Driver:** Require `baudrate=5,000,000`, `polarity=0`, `phase=0`.

To solve this, the `pins.py` module contains two functions, `setup_spi_for_lcd()` and `setup_spi_for_hcms_and_leds()`.
The respective driver modules (`lcd.py`, `leds.py`) are responsible for calling the appropriate setup function **before
** every SPI transaction to ensure the bus is in the correct mode.

### LCD Bit-Reversal Logic

The EA DIP205G-4NLED character display uses a non-standard, LSB-first serial protocol. The `lcd.py` driver emulates this
in software by using a pre-computed lookup table (`BIT_REVERSE_TABLE`) to reverse the bits of every byte before sending
it to the Pico's standard MSB-first SPI hardware. This is a critical piece of "twisted logic" that must be preserved for
the LCD to function.

### Switch-Based Display Logic

The main loop in `main.py` implements specific rules for updating the passive bus monitor displays:

- The `~DISP_EN` switch acts as a master enable. If high, no updates occur.
- When the `~RUN` switch is active (low), the display updates at a regular interval (`passive_update_interval`).
- When the `~RUN` switch is inactive (high), the system is in "Step Mode". The display updates only once when the mode
  is first entered, and thereafter only when the momentary `~STEP` switch is pressed.

## 4. Current Status

**Firmware Version:** 0.7

The firmware is considered feature-complete for its initial goals and is ready for hardware testing.

- **Immediate Next Step:** Board assembly needs to be completed to load and test the firmware on the physical hardware.

## 5. Future Work & Ideas

- **Remote Bus Monitoring via Wi-Fi:**
    - Enable the Pico's Wi-Fi module to connect to the local network.
    - Stream the bus status over a simple TCP socket (e.g., for `nc` or a custom client) or create a small embedded web
      page that mirrors the physical LCD and LEDs. This would allow for remote, headless monitoring of the Z80 system.
- **Z80 Control Implementation:**
    - Implement the logic to drive the Z80's `~WAIT` line based on the `RUN`/`STEP` switches to allow for true
      single-stepping and pausing of the CPU.
- **Full HCMS Display Implementation:**
    - Expand the `leds.py` and `font.py` modules to render the full Z80 address and data bus values on the dot-matrix
      displays, not just the status codes.

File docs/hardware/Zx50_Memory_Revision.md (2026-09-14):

# Architecture Transition: Moving to Lattice MachXO2

For a "V2" board revision, transitioning from a legacy 5V CPLD (like the Atmel ATF1508AS) to a modern 3.3V FPGA
architecture provides massive benefits in logic capacity, routing resources, and toolchain reliability. The recommended
upgrade path is the **Lattice MachXO2** family.

## 1. The Hardware: Lattice MachXO2

* **Target Part:** LCMXO2-1200HC (or similar).
* **Footprint:** Available in hand-solderable TQFP-100 or TQFP-144 packages, keeping PCB assembly accessible.
* **Logic Capacity:** Provides thousands of LUTs (Look-Up Tables) compared to the 128 macrocells of the ATF1508AS. This
  eliminates the routing congestion and pin-starvation issues encountered with the full DMA/Arbiter architecture.

## 2. 5V to 3.3V Level Shifting

The MachXO2 is strictly a **3.3V** device and is *not* 5V tolerant on its own.

* **The Solution:** Because the design already isolates the Z80 bus using 74ABT245 transceivers, transitioning to 3.3V
  is straightforward.
* By swapping the `74ABT245` chips for **`74LVC245`** or **`74ALVC164245`** transceivers, the buffers natively handle
  the 5V (Z80) to 3.3V (FPGA/SRAM) level translation. The FPGA safely operates entirely within a 3.3V domain.

## 3. The Toolchain: Open-Source Perfection

Moving to Lattice completely eliminates the reliance on 20-year-old proprietary DOS executables and Wine wrappers.

* **Synthesis & Routing:** The MachXO2 is fully supported by the modern open-source **Yosys + NextPNR (Project Trellis)
  ** toolchain.
* **Environment:** Native support for Linux and macOS.
* **Speed:** Lightning-fast synthesis and predictable, modern routing algorithms that do not crash on undefined states (
  `1'x`).

## 4. Architectural Consolidation (Bonus Benefit)

Because the MachXO2 contains dedicated internal Block RAM (BRAM), **the external ISSI SRAM chip used for the MMU Page
LUT can be completely eliminated**.

* The MMU translation tables can be mapped directly into the FPGA's internal memory.
* This frees up significant PCB real estate, removes an entire parallel memory bus (the `atl_data` and `atl_addr`
  traces), and dramatically simplifies the internal multiplexing logic.

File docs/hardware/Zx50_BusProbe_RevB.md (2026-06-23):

# Zx50 Bus Probe Rev B: Hardware Evolution & Optimization

This document outlines the transition from the Rev A "Breadboard-style" prototype to a high-performance Rev B production
card. The primary goals are to resolve the **10 MHz signal collapse** caused by high-resistance multiplexers and to
optimize the board footprint using Surface Mount Technology (SMT).

---

## 1. The Core Performance Fix: 5 $\Omega$ Switching

The Rev A prototype used **74HC4051** multiplexers, which exhibit an internal "On-Resistance" ($R_{on}$) of
approximately **80–100 $\Omega$**. When combined with bus and cable capacitance, this created an $RC$ low-pass filter
that "rounded" 10 MHz square waves into unusable "shark fins".

**Rev B Solution:**

* **Component:** **SN74CBT3251** (Digital Bus Switch).
* **Impact:** Reduces $R_{on}$ to **5 $\Omega$**, effectively eliminating the bottleneck and restoring sharp signal
  edges at 10 MHz.

---

## 2. Option A: The "Hand-Solder" Rev B

Designed for manual assembly using a standard soldering iron. This option uses **SOIC** packages with a **1.27mm pin
pitch**, which are significantly easier to handle than the high-density TQFP or QFN alternatives.

### Chip Selection (Hand-Solder)

| Function | Component | Package | Note |
|:---|:---|:---|:---|
| **Main MCU** | **PIC18F27Q43-I/SO** | 28-SOIC | 64MHz, Master Clock Generator, DMA. |
| **I/O Expander** | **MCP23S17-E/SO** | 28-SOIC | Uses 3 units to offload Z80 Address and Data buses. |
| **Bus MUX** | **SN74CBT3251DR** | 16-SOIC | Provides 5 $\Omega$ high-speed signal path. |
| **Transceiver**  | **74ABT245DW** | 20-SOIC | SOIC version of the ABT logic used in Rev A. |

**Architecture Change:** Since the 28-pin SOIC PIC has fewer pins than the 40-pin DIP, the **Z80 Data Bus**
is moved to a third SPI-based MCP23S17 expander.

---

## 3. Option B: The "Ultra-Compact" Rev B (JLC PCBA)

If utilizing professional PCBA services (like JLC), we can exploit high-density packaging to drastically reduce the card
size and potentially eliminate the need for multiple I/O expanders.

### Chip Selection (PCBA Optimized)

| Function | Component | Package | Advantage |
|:---|:---|:---|:---|
| **Main MCU** | **PIC18F47Q43-I/PT** | **44-TQFP**  | Restores full 40+ I/O pins in a 10x10mm area; eliminates 3rd expander. |
| **I/O Expander** | **MCP23S17-E/SS** | **28-SSOP**  | 0.65mm pitch; roughly 50% smaller than the SOIC version. |
| **Bus MUX** | **SN74CBT3251PWR** | **16-TSSOP** | Ultra-thin package; allows MUXes to be grouped tightly near the bus. |
| **Passives** | **0603 Metric** | SMD | Replaces bulky axial resistors/tantalums. |

**Size Reduction:** This move reduces the vertical height of the card by $\sim$40% and allows for a 4-layer PCB design,
providing a dedicated ground plane to further reduce the "Ghost Mode" ringing observed in Rev A.

---

## 4. Hardware Logic & Master Clock Master

In Rev B, the PIC moves from a "passive listener" to a **Clock Master**.

* **NCO/PWM:** The PIC generates `MCLK` and `CLK` natively, allowing the Python host to request "Step" or "Slo-Mo"
  execution.
* **Wait-State Insertion:** The PIC can monitor `~WAIT` and hold the clock automatically during slow SPI
  snapshots.

---

## 5. Software Compatibility

The MicroPython `Zx50Console` class remains largely the same, with minor adjustments to the `pin_map.py` to reflect the
new SPI Chip Select (CS) logic for the third expander (in the SOIC version).

```python
# Revised SPI Map for Rev B (SOIC Option)
CS_PINS = {
    "ADDR_LOW": "GPA0",  # Expander 1
    "ADDR_HIGH": "GPA1",  # Expander 2
    "DATA_BUS": "GPA2",  # Expander 3 (New)
    "DISPLAY":   "GPIO17"  # Pico Native [cite: 222]
}
```

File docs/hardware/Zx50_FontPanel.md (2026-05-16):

# Zx50 Front Panel & Controller Card Architecture

## 1. Introduction

### What It Is

The Zx50 Front Panel system is a modular, microcontroller-driven diagnostic and display interface for a custom Z80-based
retrocomputer. It consists of two physical printed circuit boards:

1. **The Brain Card:** A Raspberry Pi Pico-based controller that interfaces directly with the 5V Z80 bus via high-speed
   logic level shifters and transceivers.
2. **The Faceplate:** A "dead-front" aesthetic UI board featuring vintage HCMS dot-matrix displays, an EA DIP205 LCD,
   discrete LEDs, and heavy-duty NKK toggle switches.

### Purpose

The system provides real-time visibility into the Z80's internal state without imposing wait states or halting the CPU
during normal execution. It acts as both a passive bus monitor (displaying current addresses and data) and an active I/O
peripheral capable of receiving high-speed block data transfers (`OTIR`) directly from the Z80 for terminal output.
Additionally, it provides hardware-level debugging controls (Run/Halt/Step) via the front panel switches.

### Overview of Operation

Because the Pi Pico lacks the physical pins required to monitor the entire Z80 bus simultaneously, the Brain Card
utilizes a **Multiplexed 8-bit Data Bus**. Three 74LVC245 transceivers isolate the Z80's lower address, upper address,
and data lines. The Pico systematically toggles the Output Enable (`~OE`) lines of these transceivers to read or write
specific segments of the bus onto its own internal GP0-GP7 pins.

---

## 2. Hardware Architecture

The core of the design relies on safely bridging the 5V Z80 backplane to the 3.3V Pi Pico while managing pin
constraints.

```plantuml
@startuml
skinparam componentStyle rectangle

node "Z80 CPU Backplane (5V)" {
  [A0-A7 (Lower Addr)] as AL
  [A8-A15 (Upper Addr)] as AH
  [D0-D7 (Data Bus)] as D
  [Control (IORQ, WR, RD...)] as CTRL
}

node "Brain Card (3.3V Translation)" {
  [U1: 74LVC245] as U1
  [U3: 74LVC245] as U3
  [U4: 74LVC245] as U4
  [U5: Level Shifters] as U5
  
  component "Pi Pico Controller" as Pico {
    portin "GP0-GP7 (Shared Bus)" as P_BUS
    portin "GP12-GP16" as P_CTRL
    portout "GP8-GP11" as P_OE
  }
}

node "Faceplate (UI)" {
  [SPI Displays & LEDs] as DISP
  [Hardware Switches] as SW
}

AL --> U1
AH --> U3
D <--> U4
CTRL --> U5

U1 ..> P_BUS : OE = ~RD_AL
U3 ..> P_BUS : OE = ~RD_AH
U4 <..> P_BUS : OE = ~RD_D\nDIR = DIR_D
U5 --> P_CTRL : 3.3V Priority Interrupts
P_OE --> U1
P_OE --> U3
P_OE --> U4

Pico --> DISP : SPI (MOSI, SCLK, CS, Latch)
SW --> Pico : ~RUN, ~STEP
Pico --> CTRL : ~WAIT (Pause CPU)
@enduml
```

---

## 3. Operation Modes & Workflow

The Pi Pico firmware utilizes two distinct operational modes to balance high-speed Z80 communication with visual UI
updates.

### Mode A: Priority Transfer Mode (`OTIR` Catch)

When the Z80 executes an `OUT` or block `OTIR` instruction, the Pico relies on Programmable I/O (PIO) or high-speed
hardware interrupts to catch the data at full bus speed. During an `OTIR` block transfer, the Z80 places the I/O port
address on the lower address bus (`C` register) and the remaining byte count on the upper address bus (`B` register).

### Mode B: Passive Polling & Display Updates

Outside of priority data bursts, the Pico acts as a classic front-panel observer. The logic for updating the HCMS and LED displays is governed by the front panel switches.

1.  **Display Enable (`~DISP_EN`):** This signal acts as a master gate. If it is inactive (high), no display updates are performed at all.
2.  **Run Mode (`~RUN` is active/low):** When the Z80 is running, a timer triggers updates at a regular frequency (e.g., 10Hz). On each tick, the Pico latches a snapshot of the Z80 buses and sends it to the displays.
3.  **Halt Mode (`~RUN` is inactive/high):** When the Z80 is halted, the display logic changes significantly:
    *   An immediate, single update is performed the moment the system enters the halt state to show the exact state at the time of the halt.
    *   After that, updates only occur when the user manually triggers a `~STEP` signal. This allows for single-stepping the Z80 and seeing the result of each instruction on the display.

### Mode C: Switch State Monitoring

In the background, the Pico monitors the physical Faceplate switches (`~RUN`, `~STEP`). State changes trigger immediate
updates to the Z80 control lines (e.g., pulling `~WAIT` low) to pause, step, or release the CPU execution.

## 4. Pi Pico GPIO Pin Mapping

This table reflects the final netlist routing on the Brain Card (`Zx50_FrontPanelCard.net`).

| Pico Pin | GPIO | Net Name | Function | Hardware Routing |
|:---|:---|:---|:---|:---|
| 1, 2, 4-7, 9, 10 | GP0-GP7 | `D0`-`D7`  | Multiplexed Shared Bus  | U1, U3, U4 (B-Sides) |
| 11 | GP8 | `~RD_AL` | Read Lower Address | `~OE` for U1 (A0-A7) |
| 12 | GP9 | `~RD_AH` | Read Upper Address | `~OE` for U3 (A8-A15) |
| 14 | GP10 | `~RD_D` | Read Data Bus | `~OE` for U4 (Z80_D0-D7) |
| 15 | GP11 | `DIR_D` | Data Bus Direction | `DIR` for U4 (Low = Read Z80) |
| 16 | GP12 | `~WR_3V` | Z80 Write (3.3V) | U5 Level Shifter |
| 17 | GP13 | `~RD_3V` | Z80 Read (3.3V) | U5 Level Shifter |
| 19 | GP14 | `~IORQ_3V` | Z80 I/O Request (3.3V)  | U5 Level Shifter |
| 20 | GP15 | `~M1_3V` | Z80 Machine Cycle 1 | U5 Level Shifter |
| 21 | GP16 | `~MREQ_3V` | Z80 Mem Request (3.3V)  | U5 Level Shifter |
| 22 | GP17 | `REG_SEL`  | SPI Reg Select (LCD RS) | to Faceplate J3 |
| 24 | GP18 | `~LCD_CS`  | SPI Chip Select (LCD) | to Faceplate J3 |
| 25 | GP19 | `MOSI` | SPI Data Out | to Faceplate J3 |
| 26 | GP20 | `~LED_CE`  | SPI Latch (595 RCLK) | to Faceplate J3 |
| 27 | GP21 | `SCLK` | SPI Clock | to Faceplate J3 |
| 29 | GP22 | `~RUN` | Switch Input (RUN) | to Faceplate J4 |
| 31 | GP26 | `~STEP` | Switch Input (STEP) | to Faceplate J4 |
| 32 | GP27 | `~DISP_EN` | Z80 IO Address Select | to Faceplate J4 |
| 34 | GP28 | `~WAIT` | Z80 Wait (Output) | to Faceplate J4 |

## 5. Physical Connectors (Faceplate to Brain Card)

The system uses two 10-pin (2x5) 2.54mm pitch IDC ribbon cables to bridge the Faceplate to the Brain Card and Z80
backplane.

### J3: Display & SPI Bus Cable

This cable strictly handles the 3.3V logic SPI bus and the isolated power domains for the displays to prevent noise from
polluting the Z80 logic.

| Pin | Signal | Source / Destination | Description |
|:---|:---|:---|:---|
| **1**  | `+3.3V_SW` | Faceplate LDO | Clean 3.3V logic power |
| **2**  | `+5VD` | Brain Card / PSU | Isolated Display & Backlight Power |
| **3**  | `GND` | Common Ground | Reference |
| **4**  | `SCLK` | Pico **GP21** | SPI Clock |
| **5**  | `MOSI` | Pico **GP19** | SPI Data Out (to HCMS & 595) |
| **6**  | `~LCD_CS`  | Pico **GP18** | EA DIP205 Chip Select (Active Low) |
| **7**  | `REG_SEL`  | Pico **GP17** | EA DIP205 Register Select (0=Cmd, 1=Data) |
| **8**  | `~LED_CE`  | Pico **GP20** | 74HC595 Latch / RCLK (Active Low) |
| **9**  | *Open* | - | - |
| **10** | `GND` | Common Ground | Ground shield / Reference |

### J4: Switches & Z80 Control Cable

This cable mirrors the standard Zx50 CPU card front-panel header. It handles the 5V system power and the physical UI
switch states.

| Pin | Signal | Source / Destination | Description |
|:---|:---|:---|:---|
| **1**  | `+5VA` | Z80 Backplane | Raw system 5V power (Feeds Faceplate LDO) |
| **2**  | `GND` | Common Ground | Reference |
| **3**  | `~DISP_EN` | Z80 IO Decoder / Pico **GP27** | Faceplate Update Enable (Active Low) |
| **4**  | `~WAIT` | Pico **GP28** -> Z80 | Pauses CPU execution (Active Low) |
| **5**  | `~RUN` | Faceplate Switch -> Pico **GP22** | Run/Stop Toggle |
| **6**  | `~STEP` | Faceplate Switch -> Pico **GP26** | Single-step clock trigger |
| **7**  | `~RESET` | Faceplate Switch -> Z80 | System Reset |
| **8**  | *Open* | - | - |
| **9**  | *Open* | - | - |
| **10** | `GND` | Common Ground | Ground shield / Reference |

---

## 6. Transceiver Multiplexing Map (U1, U3, U4)

To facilitate the shared 8-bit bus, three 74LVC245 octal bus transceivers sit between the 5V Z80 bus (A-Side) and the
3.3V Pi Pico (B-Side).

* **U1 (Lower Address):** `~OE` controlled by Pico **GP8** (`~RD_AL`). `DIR` hardwired to `B` (Z80 -> Pico).
* **U3 (Upper Address):** `~OE` controlled by Pico **GP9** (`~RD_AH`). `DIR` hardwired to `B` (Z80 -> Pico).
* **U4 (Data Bus):** `~OE` controlled by Pico **GP10** (`~RD_D`). `DIR` controlled by Pico **GP11** (`DIR_D`).

### Shared GP0-GP7 Pin Mapping

| Pico Shared Bus | GP0 | GP1 | GP2 | GP3 | GP4 | GP5 | GP6 | GP7 |
|:---|:---|:---|:---|:---|:---|:---|:---|:---|
| **LVC245 B-Side Pin**  | Pin 18 | Pin 17 | Pin 16 | Pin 15 | Pin 14 | Pin 13 | Pin 12 | Pin 11 |
| **U1 Signal (Addr L)** | `A0` | `A1` | `A2` | `A3` | `A4` | `A5` | `A6` | `A7` |
| **U3 Signal (Addr H)** | `A8` | `A9` | `A10`  | `A11`  | `A12`  | `A13`  | `A14`  | `A15`  |
| **U4 Signal (Data)** | `D0` | `D1` | `D2` | `D3` | `D4` | `D5` | `D6` | `D7` |
| **LVC245 A-Side Pin**  | Pin 2  | Pin 3  | Pin 4  | Pin 5  | Pin 6  | Pin 7  | Pin 8  | Pin 9  |

*(Note: During an `OTIR` burst, U1 holds the Target I/O Port, U3 holds the remaining byte counter, and U4 holds the
payload data).*

## 7. HCMS Display Layout

The front panel features two separate dot-matrix displays for at-a-glance status.

*   **U1 (Green, 8-Char):** Displays the primary Z80 Bus information.
*   **U2 (Red, 4-Char):** Displays the status of the secondary Shadow Bus.

### U1 - Z80 Bus Display

This 8-character display is formatted to show the most critical Z80 signals during passive monitoring.

`[Data] [St] [Addr]`

*   **Data:** `D0-D7` shown as a 2-digit hexadecimal value (e.g., `3E`).
*   **St (Status):** A 2-character field showing the state of `~RD`, `~WR`, `~MREQ`, and `~IORQ`.
*   **Addr:** `A0-A15` shown as a 4-digit hexadecimal value (e.g., `F00D`).

**Example:** `3E RM F00D`

#### Z80 Status Codes

The two-character status field displays a human-readable code representing the current machine cycle.

| Code | Meaning | Signals Active |
| :--- | :--- | :--- |
| **RM** | Read Memory | `~RD` and `~MREQ` |
| **WM** | Write Memory | `~WR` and `~MREQ` |
| **RI** | Read I/O | `~RD` and `~IORQ` |
| **WI** | Write I/O | `~WR` and `~IORQ` |
| **HL** | Halted | `~HALT` |
| **(space)** | Idle / Other | None of the above |

*Note: `~RESET` is not displayed, as this signal resets the Pico controller itself.*

### U2 - Shadow Bus Display

This 4-character display shows the state of the high-speed shadow bus used for out-of-band data transfers.

`[St] [Data]`

*   **St (Status):** A 2-character field showing the state of the 6 shadow bus control lines.
*   **Data:** The `SD0-SD7` value as a 2-digit hexadecimal value.

#### Shadow Bus Status Glyphs

The two status characters are divided into quadrants and halves to represent the 6 control signals. A lit block indicates the signal is active.

**Left Character (2x3 Quadrants):**
```
  C1  C2   C4  C5
+---+---+ +---+---+  (Row A)
| 1 | 1 | | 2 | 2 |  (Row B)
+---+---+ +---+---+  (Row C)
                     (Row D)
+---+---+ +---+---+  (Row E)
| 3 | 3 | | 4 | 4 |  (Row F)
+---+---+ +---+---+  (Row G)

1: SH_EN_N (Active Low)
2: SH_BUSY_N (Active Low)
3: WRITE (Active High)
4: SH_DONE_N (Active Low)
```

**Right Character (2x3 Halves):**
```
  C1  C2  C3  C4  C5
+---+---+---+---+---+ (Row A)
| 5 | 5 | 5 | 5 | 5 | (Row B)
+---+---+---+---+---+ (Row C)
                      (Row D)
+---+---+---+---+---+ (Row E)
| 6 | 6 | 6 | 6 | 6 | (Row F)
+---+---+---+---+---+ (Row G)

5: SH_STB_N (Active Low)
6: SH_INC_N (Active Low)
```

### A. Bill of Materials (Front Panel Bus Card)

To safely interface the 3.3V Pi Pico with the 5V Zx50 backplane and supply enough current for the faceplate displays,
the card requires the following core components:

**Logic & Control:**

1. **1x Raspberry Pi Pico** (The core state machine and SPI master).
2. **7x 74LVC573A** (Octal Transparent D-Type Latches). *Must be LVC family for 5V input tolerance while powered at
   3.3V.*
3. **1x 74AHCT1G04** (Optional single inverter for hardware interrupt conditioning, if needed).

**Power Supply:**
Because the HCMS-39xx dot-matrix displays on the faceplate can draw upwards of 150mA at full brightness, the system
bypasses the Pico's internal 300mA regulator in favor of a dedicated high-current LDO.

4. **1x AMS1117-3.3** (or equivalent 3.3V, 1A LDO Linear Regulator in SOT-223).
    * **Input:** Powered directly from the Zx50 5V rail.
    * **Output:** Supplies the 3.3V rail for the Pi Pico (`VSYS`), the seven `74LVC573A` latches, and Pin 1 of the SPI
      Ribbon Cable.
5. **Capacitors:**
    * 1x `100µF` to `220µF` Electrolytic (Bulk input decoupling on the 5V rail).
    * 1x `10µF` Ceramic (LDO Input stability).
    * 1x `22µF` Ceramic (LDO Output stability).
    * 8x `0.1µF` Ceramic (Bypass capacitors for the Pico and the 7 latches).

**Connectors:**

6. **1x Zx50 Edge Connector** (Backplane interface).
7. **2x 2x5 IDC Headers** (Ribbon cable interfaces to the Faceplate).

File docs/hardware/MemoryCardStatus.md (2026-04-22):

# Project Checkpoint: Z80 Universal Shadow Bus CPLD

## 1. The Hardware Status: VERIFIED
* **The Problem:** The CPLD was pulling 0.5A, getting dangerously hot, and causing bus contention.
* **The Fix:** The 0805 LEDs on the `~CE` lines were preventing the 10k pull-ups from pulling the bus to a solid 5V. We bodged 10k resistors directly across the outermost pads of the LED/Resistor pairs, bypassing the diode drop.
* **The Litmus Test:** Flashing a "blank slate" (all pins input/tri-stated) dropped the board's current draw to a cool, healthy **114mA**. The physical hardware, memory chips, and CPLD silicon are 100% healthy.

## 2. The Logic Pivot: Centralized Master State Machine
* **The Old Architecture:** Decentralized logic. The DMA, MMU, and Bus Arbiter were independent modules using combinatorial flags (`dma_is_active`, `sh_busy_n`) to negotiate control.
* **The Bug:** This caused nanosecond race conditions (e.g., the "Elevator Deadlock," where yielding the local bus accidentally cancelled the backplane request), leading to the transceivers staying closed and yielding `0xFF` data corruption during card-to-card DMA transfers.
* **The New Architecture:** We are abandoning whack-a-mole patching. We are building a strict, top-down **Master State Machine (Moore Machine)**. The sub-modules (DMA, MMU) will be stripped of their internal state machines and reduced to "dumb" datapaths. A single top-level controller will dictate exactly what every transceiver and memory pin is doing at any given time.

## 3. The State Table Rules
We are defining a CSV matrix of pin invariants *before* writing any Verilog.
* **No Blanks:** Every cell must be explicitly defined to prevent the synthesizer from inferring latches.
* **`OUT (value)` vs. `OUT`:** * `OUT (1b0)` means the pin is hardcoded to `0` for that entire state.
    * `OUT` means the Master State Machine claims ownership of the pin, but delegates the exact value (0, 1, or Z) to the underlying datapath logic.
* **Break-Before-Make:** Transitions between bus owners must pass through `MUTE` states to prevent physical transceiver shoot-through.

## 4. Current Matrix Progress: Group 1 (Locked)
We have successfully defined the **Open-Drain / Backplane Control Group** (`INT_N`, `WAIT_N`, `SH_BUSY_N`):
* **`MUTE_PASSIVE`:** All open-drain lines yield to `Z`. The card drops off the bus silently and instantly.
* **`MUTE_ACTIVE`:** The card asserts `WAIT_N = 0` and `SH_BUSY_N = 0` (the "brick wall") to freeze the Z80 and the Shadow Bus while its transceivers spin up.
* **Master vs. Slave Handoff:** During a DMA transfer, the Master listens (`IN`) to `SH_BUSY_N`, while the Slave drives (`OUT`) `SH_BUSY_N` to stall the Master if it needs to refresh or wait.
* **Interrupts:** `INT_N` is asserted via `OUT (1b0)` and cleanly released via `Z`.

## 5. Next Steps (Upon Resume)
When we return to the CSV, we need to fill in the invariant states for the remaining pin groups:
1.  **Group 2 (Address & LUT Routing):** `L_A`, `ATL_A`, `ATL_D`, `ATL_OE_N`. Define when the Z80 drives the addresses versus when the internal DMA counter drives them.
2.  **Group 3 (Local Memory Controls):** `CE_N`, `OE_N`, `WE_N`. Define exact chip-select logic to ensure internal SRAMs don't fight the backplane transceivers.

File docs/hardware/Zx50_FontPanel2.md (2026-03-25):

Here is the complete, consolidated `Zx50_FrontPanel.md` file. I have removed the redundancies, added a clear introductory overview, mapped out the system architecture with a PlantUML diagram, and included the pseudo-code for the high-speed `OTIR` state machine.

```markdown
# Zx50 Front Panel & Controller Card Architecture

## 1. Introduction

### What It Is
The Zx50 Front Panel system is a modular, microcontroller-driven diagnostic and display interface for a custom Z80-based retrocomputer. It consists of two physical printed circuit boards:
1. **The Brain Card:** A Raspberry Pi Pico-based controller that interfaces directly with the 5V Z80 bus via high-speed logic level shifters and transceivers.
2. **The Faceplate:** A "dead-front" aesthetic UI board featuring vintage HCMS dot-matrix displays, an EA DIP205 LCD, discrete LEDs, and heavy-duty NKK toggle switches.

### Purpose
The system provides real-time visibility into the Z80's internal state without imposing wait states or halting the CPU during normal execution. It acts as both a passive bus monitor (displaying current addresses and data) and an active I/O peripheral capable of receiving high-speed block data transfers (`OTIR`) directly from the Z80 for terminal output. Additionally, it provides hardware-level debugging controls (Run/Halt/Step) via the front panel switches.

### Overview of Operation
Because the Pi Pico lacks the physical pins required to monitor the entire Z80 bus simultaneously, the Brain Card utilizes a **Multiplexed 8-bit Data Bus**. Three 74LVC245 transceivers isolate the Z80's lower address, upper address, and data lines. The Pico systematically toggles the Output Enable (`~OE`) lines of these transceivers to read or write specific segments of the bus onto its own internal GP0-GP7 pins. 

---

## 2. Hardware Architecture

The core of the design relies on safely bridging the 5V Z80 backplane to the 3.3V Pi Pico while managing pin constraints.

```plantuml
@startuml
skinparam componentStyle rectangle

node "Z80 CPU Backplane (5V)" {
  [A0-A7 (Lower Addr)] as AL
  [A8-A15 (Upper Addr)] as AH
  [D0-D7 (Data Bus)] as D
  [Control (IORQ, WR, RD...)] as CTRL
}

node "Brain Card (3.3V Translation)" {
  [U1: 74LVC245] as U1
  [U3: 74LVC245] as U3
  [U4: 74LVC245] as U4
  [U5: Level Shifters] as U5
  
  component "Pi Pico Controller" as Pico {
    portin "GP0-GP7 (Shared Bus)" as P_BUS
    portin "GP12-GP16" as P_CTRL
    portout "GP8-GP11" as P_OE
  }
}

node "Faceplate (UI)" {
  [SPI Displays & LEDs] as DISP
  [Hardware Switches] as SW
}

AL --> U1
AH --> U3
D <--> U4
CTRL --> U5

U1 ..> P_BUS : OE = ~RD_AL
U3 ..> P_BUS : OE = ~RD_AH
U4 <..> P_BUS : OE = ~RD_D\nDIR = DIR_D
U5 --> P_CTRL : 3.3V Priority Interrupts
P_OE --> U1
P_OE --> U3
P_OE --> U4

Pico --> DISP : SPI (MOSI, SCLK, CS, Latch)
SW --> Pico : ~RUN, ~STEP
Pico --> CTRL : ~WAIT (Pause CPU)
@enduml
```

---

## 3. Operation Modes & Workflow

The Pi Pico firmware utilizes two distinct operational modes to balance high-speed Z80 communication with visual UI updates.

### Mode A: Priority Transfer Mode (`OTIR` Catch)
When the Z80 executes an `OUT` or block `OTIR` instruction, the Pico relies on Programmable I/O (PIO) or high-speed hardware interrupts to catch the data at full bus speed. During an `OTIR` block transfer, the Z80 places the I/O port address on the lower address bus (`C` register) and the remaining byte count on the upper address bus (`B` register).

```python
# Pseudo-code for PIO / Interrupt High-Speed Catch
def handle_z80_write_irq():
    # Triggered by FALLING edge of ~WR (while ~IORQ is low)
    
    # 1. Verify target Port (Read A0-A7)
    assert_low(OE_U1_RD_AL)
    target_port = read_shared_bus(GP0_GP7)
    assert_high(OE_U1_RD_AL)
    
    if target_port != PICO_PORT_ADDRESS:
        return # Ignore, not for us
        
    # 2. Enter High-Speed Block Transfer Loop
    while True:
        # Read the Data Bus (D0-D7)
        assert_low(OE_U4_RD_D)
        data_byte = read_shared_bus(GP0_GP7)
        assert_high(OE_U4_RD_D)
        
        fifo_buffer.push(data_byte)
        
        # Read the Upper Address Bus (A8-A15) to check the B-Register Counter
        assert_low(OE_U3_RD_AH)
        bytes_remaining = read_shared_bus(GP0_GP7)
        assert_high(OE_U3_RD_AH)
        
        # OTIR completes when the B register hits 0
        if bytes_remaining == 0:
            break
            
        wait_for_next_WR_falling_edge()
```

### Mode B: Passive Polling (10Hz - 20Hz)
Outside of priority data bursts, the Pico acts as a classic front-panel observer.
1. A timer interrupt triggers 10 to 20 times per second.
2. The Pico sequentially latches `U1`, `U3`, and `U4` to capture a snapshot of the current Address and Data buses.
3. If the `~DISP_EN` control signal is active, the Pico formats this snapshot and shifts it out over the SPI bus to the Faceplate's HCMS displays and discrete LEDs.

### Mode C: Switch State Monitoring
In the background, the Pico monitors the physical Faceplate switches (`~RUN`, `~STEP`). State changes trigger immediate updates to the Z80 control lines (e.g., pulling `~WAIT` low) to pause, step, or release the CPU execution.

---

## 4. Pi Pico GPIO Pin Mapping

This table reflects the final netlist routing on the Brain Card (`Zx50_FrontPanelCard.net`).

| Pico Pin | GPIO | Net Name | Function | Hardware Routing |
| :--- | :--- | :--- | :--- | :--- |
| 1, 2, 4-7, 9, 10 | GP0-GP7 | `D0`-`D7` | Multiplexed Shared Bus | U1, U3, U4 (B-Sides) |
| 11 | GP8 | `~RD_AL` | Read Lower Address | `~OE` for U1 (A0-A7) |
| 12 | GP9 | `~RD_AH` | Read Upper Address | `~OE` for U3 (A8-A15) |
| 14 | GP10 | `~RD_D` | Read Data Bus | `~OE` for U4 (Z80_D0-D7) |
| 15 | GP11 | `DIR_D` | Data Bus Direction | `DIR` for U4 (Low = Read Z80) |
| 16 | GP12 | `~WR_3V` | Z80 Write (3.3V) | U5 Level Shifter |
| 17 | GP13 | `~RD_3V` | Z80 Read (3.3V) | U5 Level Shifter |
| 19 | GP14 | `~IORQ_3V` | Z80 I/O Request (3.3V) | U5 Level Shifter |
| 20 | GP15 | `~M1_3V` | Z80 Machine Cycle 1 | U5 Level Shifter |
| 21 | GP16 | `~MREQ_3V`| Z80 Mem Request (3.3V) | U5 Level Shifter |
| 22 | GP17 | `REG_SEL` | SPI Reg Select (LCD RS) | to Faceplate J3 |
| 24 | GP18 | `~LCD_CS` | SPI Chip Select (LCD) | to Faceplate J3 |
| 25 | GP19 | `MOSI` | SPI Data Out | to Faceplate J3 |
| 26 | GP20 | `~LED_CE` | SPI Latch (595 RCLK) | to Faceplate J3 |
| 27 | GP21 | `SCLK` | SPI Clock | to Faceplate J3 |
| 29 | GP22 | `~RUN` | Switch Input (RUN) | to Faceplate J4 |
| 31 | GP26 | `~STEP` | Switch Input (STEP) | to Faceplate J4 |
| 32 | GP27 | `~DISP_EN`| Z80 IO Address Select | to Faceplate J4 |
| 34 | GP28 | `~WAIT` | Z80 Wait (Output) | to Faceplate J4 |
```

## 5. Physical Connectors (Faceplate to Brain Card)

The system uses two 10-pin (2x5) 2.54mm pitch IDC ribbon cables to bridge the Faceplate to the Brain Card and Z80 backplane. 

### J3: Display & SPI Bus Cable
This cable strictly handles the 3.3V logic SPI bus and the isolated power domains for the displays to prevent noise from polluting the Z80 logic.

| Pin | Signal | Source / Destination | Description |
| :--- | :--- | :--- | :--- |
| **1** | `+3.3V_SW`| Faceplate LDO | Clean 3.3V logic power |
| **2** | `+5VD` | Brain Card / PSU | Isolated Display & Backlight Power |
| **3** | `GND` | Common Ground | Reference |
| **4** | `SCLK` | Pico **GP21** | SPI Clock |
| **5** | `MOSI` | Pico **GP19** | SPI Data Out (to HCMS & 595) |
| **6** | `~LCD_CS` | Pico **GP18** | EA DIP205 Chip Select (Active Low) |
| **7** | `REG_SEL` | Pico **GP17** | EA DIP205 Register Select (0=Cmd, 1=Data) |
| **8** | `~LED_CE` | Pico **GP20** | 74HC595 Latch / RCLK (Active Low) |
| **9** | *Open* | - | - |
| **10**| `GND` | Common Ground | Ground shield / Reference |

### J4: Switches & Z80 Control Cable
This cable mirrors the standard Zx50 CPU card front-panel header. It handles the 5V system power and the physical UI switch states.

| Pin | Signal | Source / Destination | Description |
| :--- | :--- | :--- | :--- |
| **1** | `+5VA` | Z80 Backplane | Raw system 5V power (Feeds Faceplate LDO) |
| **2** | `GND` | Common Ground | Reference |
| **3** | `~DISP_EN`| Z80 IO Decoder / Pico **GP27**| Faceplate Update Enable (Active Low) |
| **4** | `~WAIT` | Pico **GP28** -> Z80 | Pauses CPU execution (Active Low) |
| **5** | `~RUN` | Faceplate Switch -> Pico **GP22**| Run/Stop Toggle |
| **6** | `~STEP` | Faceplate Switch -> Pico **GP26**| Single-step clock trigger |
| **7** | `~RESET` | Faceplate Switch -> Z80 | System Reset |
| **8** | *Open* | - | - |
| **9** | *Open* | - | - |
| **10**| `GND` | Common Ground | Ground shield / Reference |

---

## 6. Transceiver Multiplexing Map (U1, U3, U4)

To facilitate the shared 8-bit bus, three 74LVC245 octal bus transceivers sit between the 5V Z80 bus (A-Side) and the 3.3V Pi Pico (B-Side). 

* **U1 (Lower Address):** `~OE` controlled by Pico **GP8** (`~RD_AL`). `DIR` hardwired to `B` (Z80 -> Pico).
* **U3 (Upper Address):** `~OE` controlled by Pico **GP9** (`~RD_AH`). `DIR` hardwired to `B` (Z80 -> Pico).
* **U4 (Data Bus):** `~OE` controlled by Pico **GP10** (`~RD_D`). `DIR` controlled by Pico **GP11** (`DIR_D`).

### Shared GP0-GP7 Pin Mapping

| Pico Shared Bus | GP0 | GP1 | GP2 | GP3 | GP4 | GP5 | GP6 | GP7 |
| :--- | :--- | :--- | :--- | :--- | :--- | :--- | :--- | :--- |
| **LVC245 B-Side Pin**| Pin 18 | Pin 17 | Pin 16 | Pin 15 | Pin 14 | Pin 13 | Pin 12 | Pin 11 |
| **U1 Signal (Addr L)**| `A0` | `A1` | `A2` | `A3` | `A4` | `A5` | `A6` | `A7` |
| **U3 Signal (Addr H)**| `A8` | `A9` | `A10` | `A11` | `A12` | `A13` | `A14` | `A15` |
| **U4 Signal (Data)** | `D0` | `D1` | `D2` | `D3` | `D4` | `D5` | `D6` | `D7` |
| **LVC245 A-Side Pin**| Pin 2 | Pin 3 | Pin 4 | Pin 5 | Pin 6 | Pin 7 | Pin 8 | Pin 9 |

*(Note: During an `OTIR` burst, U1 holds the Target I/O Port, U3 holds the remaining byte counter, and U4 holds the payload data).*

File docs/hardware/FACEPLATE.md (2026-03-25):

# Zx50 Enclosure & Faceplate Fabrication Guide

## 1. The KiCad to VCarve Pipeline
To guarantee your physical faceplate perfectly matches your PCB, the design must originate in KiCad.

* **Prep the KiCad Canvas:** Switch to the `User.Drawings` layer. Draw exact rectangles over your HCMS and LCD displays. Draw 3mm circles over every single LED. Add your UI text labels. 
* **Add Alignment Dowel Holes:** Place four 1/4" (or 6mm) circles outside the main 7x7" faceplate boundary. These will be your alignment dowel holes for the CNC "flip jig."
* **Export the DXF:** Go to `File -> Export -> DXF`. Select *only* the `Edge.Cuts` and `User.Drawings` layers. Check the box for **"Use drill/place file origin"**.
* **Import to VCarve:** Import the DXF. Double-check the dimensions to ensure it imported at exactly 100% scale (no metric/imperial conversion scaling errors).
* **Set Up the Two-Sided Job:** Use VCarve’s two-sided machining setup. Center the job on your dowel hole vectors so the front and back toolpaths are mathematically locked together.

## 2. Faceplate Fabrication (Smoked Acrylic)
*Material: 7" x 7" Smoked Cast Acrylic (1/8" or 1/4" thick)*

### Front-Side Machining (The Stealth UI)
* **Masking:** Apply standard blue painter's tape or paper transfer tape across the entire top surface.
* **Alignment Holes:** Mill the 4 outer dowel holes completely through the stock and into your CNC spoilboard. 
* **V-Carving:** Use a 60° or 90° V-bit to engrave your UI text (`RUN`, `STEP`, `POWER`, etc.) right through the tape, about 0.5mm to 1.0mm deep.
* **Paint Fill:** Before removing the tape, smear white acrylic paint or enamel into the engraved text. Scrape the excess off with a plastic card. Let it dry, then peel the tape.

### Rear-Side Machining (The Pockets & Mounting)
* **The Flip:** Remove the acrylic, tap your wooden dowels into the spoilboard, flip the acrylic left-to-right, and press it onto the dowels.
* **Display Windows:** Use a flat-bottom end mill to cut the rectangular pockets for the HCMS and LCD displays. **Cut 1.0mm deep** into the rear. *Leave the bottom frosted—it acts as a perfect light diffuser!*
* **LED Locking Pockets:** Use a 3.0mm end mill (or standard 1/8" bit) to plunge a 1.0mm deep pocket for each of your THT LEDs. 
* **Through-Holes:** Drill the 6.5mm (1/4") holes for the four NKK switches, and the 3.2mm (1/8") holes for the left-side M3 standoffs.
* **Perimeter Cut:** Run the final profile cutout to free the 7x7" faceplate from the stock.

## 3. Chassis Fabrication (Clear Acrylic)
*Material: Clear Cast Acrylic*

### Bottom Plate (The Foundation)
* **Cut Outline:** Mill the bottom plate to accommodate your 6.75" internal width requirement (final width depends on your chosen wall thickness). Target a minimum internal depth of 10.0".
* **Backplane Mounting:** Mill the M3 standoff mounting holes for the 8.5" x 6.5" backplane. Ensure the front edge of the backplane is offset at least 1.5" from the faceplate to allow the IDC ribbon cable to make its "U-turn."

### Side & Rear Plates
* **Interlocking:** If using the CNC, design box joints or tab-and-slot geometry in VCarve to make the clear acrylic box self-squaring.
* **Rear I/O:** Mill the cutout for your Mean Well power entry connector and any external serial/expansion ports. 
* **Top Clearance:** Verify the side walls are tall enough that a 5" tall CPU card sitting in the backplane slot clears the roof of the enclosure (target ~6.0" internal height).

## 4. CNC Pro-Tips for Acrylic
1.  **Use an O-Flute Bit:** Standard wood end-mills will melt acrylic, wrapping molten plastic around the bit until it snaps. Use a **Single-Flute O-Flute upcut bit**. 
2.  **Cast vs. Extruded:** Always buy *Cast* acrylic for CNC routing. Extruded acrylic has a lower melting point and cuts terribly. 
3.  **Feeds and Speeds:** Acrylic needs a high chip load to carry heat away from the cut. Keep your spindle RPM relatively low (10k-14k) and your feed rate fast (60-100 inches per minute) to ensure you are making chips, not dust or melted slag.

***

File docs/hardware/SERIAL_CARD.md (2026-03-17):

# Zx50 Serial I/O & Timer Card (CTC + DART)

**Current Status:** Schematic and netlist verified. PCB trace routing in progress.

## 1. Overview
This card provides the Zx50 system with its primary human-machine interface (via two serial ports) and precision hardware timing. It combines a **Z80 DART** (Dual Asynchronous Receiver/Transmitter) for serial communications and a **Z80 CTC** (Counter/Timer Circuit) for programmable baud rate generation and system tick interrupts.

## 2. Core Chip Manifest
1. **Z80 DART (Z84C4010PEC):** 10MHz CMOS dual serial controller.
2. **Z80 CTC (Z84C30):** The 4-channel timer (provides baud rate clocks to the DART and system ticks).
3. **74AHCT138:** 3-to-8 line decoder (Address slicing for the Z80 I/O space).
4. **MAX232ACPE+:** High-speed RS-232 level shifter charge-pump (Requires only 0.1 µF caps; dedicated to Serial Port 1).
5. **7.3728 MHz Oscillator:** A standard 4-pin active crystal oscillator can (feeds the CTC's clock inputs for baud rate division).
6. **FTDI DB9-USB-D5:** Standalone USB-to-TTL module (Physical connector and level translator for Serial Port 0).

## 3. The Output Stages (The Split Design)
* **Serial 0 (USB via FTDI):**
  * **Source:** Z80 DART Channel A.
  * **Connector:** FTDI DB9-USB-D5 module (`J3`).
  * **Voltages:** 5V TTL logic. The DART's logic lines are crossed over to interface correctly with the module: `TXDA` connects to `RXD`, `RXDA` connects to `TXD`, `RTSA` connects to `CTS`, and `CTSA` connects to `RTS`.
* **Serial 1 (Classic RS-232):**
  * **Source:** Z80 DART Channel B.
  * **Connector:** Standard Right-Angle DB9 Female (PCB Mount, wired as DCE).
  * **Voltages:** True RS-232 (±10V). The DART's `TxDB`, `RxDB`, `~RTSB~`, and `~CTSB~` pins route through the `MAX232ACPE+` level-shifting IC before hitting the DB9.
  * **Charge Pump:** Uses standard charge-pump topology with unpolarized 0.1 µF ceramic capacitors (DigiKey BC1101CT-ND).

## 4. Hardware Activity LEDs
To provide immediate visual feedback during data transmission, the board features hardware-driven activity LEDs:
* **Implementation:** High-efficiency LEDs (`D1`, `D2`) are connected to the `TxDA` and `TxDB` output pins of the DART, pulled to ground through 1KΩ current-limiting resistors (`R1`, `R2`).
* **Result:** The LEDs will naturally flicker exactly when bytes are being shifted out of the UART, requiring zero software overhead.

## 5. The Direct-Drive Baud Rate Engine
Because the system backplane runs at 8-10 MHz, the 7.3728 MHz oscillator connects directly to the CTC without violating Zilog timing limits.
* **The Clock:** The 7.3728 MHz oscillator feeds the CTC's clock inputs (`CLK/TRG0` and `CLK/TRG1`). 
* **The Routing:** * CTC Channel 0 Output (`ZC/TO0`) -> DART Channel A `RxCA` and `TxCA` pins.
  * CTC Channel 1 Output (`ZC/TO1`) -> DART Channel B `RxTxCB` pin.
* **Software Math:** By placing the CTC in "Counter Mode" and the DART in x16 multiplier mode, a CTC divisor of 4 yields 115,200 baud, and a divisor of 48 yields 9,600 baud.

## 6. Interrupt Priority & The Daisy Chain
Both the CTC and the DART utilize Z80 Mode 2 Vectored Interrupts. Because they sit on the same physical card, their interrupt priority is hardwired using the Zx50 Backplane's `IEI` and `IEO` lines.
* **Routing Path:** Backplane `IEI` -> CTC `IEI` | CTC `IEO` -> DART `IEI` | DART `IEO` -> Backplane `IEO`.
* **Priority:** The CTC has a higher interrupt priority than the DART. 

## 7. Addressing Configuration
Both chips connect directly to the unbuffered `D0-D7` backplane data bus, tri-stating themselves automatically.
* **Decoder (74AHCT138):** Slices the lower 8 bits of the address bus using `A2`, `A3`, and `A4`. Assuming a base address of `0x80`:
  * `0x80 - 0x83`: Mapped to the CTC `~CE`.
  * `0x84 - 0x87`: Mapped to the DART `~CE`.
* **Sub-Addressing:** `A0` and `A1` connect directly to the CTC (`CS0`, `CS1`) and DART (`B/~A`, `C/~D`) to select internal registers.
* **Address Mirroring Note:** Because address line `A5` is not connected to the decoder, it acts as a "don't care" bit. As a result, the CTC and DART will also mirror their addresses at `0xA0 - 0xA7`.

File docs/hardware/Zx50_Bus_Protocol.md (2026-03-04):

# Zx50 Shadow Bus Protocol Specification

The Shadow Bus is a secondary, high-speed DMA (Direct Memory Access) backplane designed to operate parallel to the primary Z80 bus. It allows coprocessors (Masters) to rapidly stream data to and from memory or peripherals (Targets) using a hardware-level cycle-stealing and burst protocol.

## 1. Signal Definitions

| Signal | Name | Direction | Active | Description |
| :--- | :--- | :--- | :--- | :--- |
| `~S_EN` | Shadow Enable | Master -> Target | LOW | Claims the bus and wakes up the Target. |
| `SRW` | Shadow Read/Write | Master -> Target | HIGH/LOW | Defines data direction (0 = Write to Target, 1 = Read from Target). |
| `~SSTB` | Shadow Strobe | Master -> Target | LOW | The primary data clock. Validates data on the bus. |
| `~SINC` | Shadow Increment | Master -> Target | LOW | Commands the Target to advance its internal address pointer. |
| `~S_BUSY` | Shadow Busy | Target -> Master | LOW | Asynchronous stall. Tells the Master to freeze its strobes. |
| `~S_DONE` | Shadow Done | Master -> Target | LOW | Terminal count flag. Indicates the current byte is the final byte. |

---

## 2. Phases of a Transfer

### Phase 1: The Setup (Master Driven)
To initiate a transfer, the Master must physically claim the bus:
1. The Master drives the initial address onto the Shadow Address bus.
2. The Master asserts `SRW` to declare the direction of the burst.
3. The Master asserts `~S_EN` LOW. It remains LOW for the entire duration of the burst block.

### Phase 2: The Data Pump (Master Driven)
Once the bus is claimed, the Master dictates the speed of the transfer using the strobe pins.
* **On a DMA Write (`SRW=0`):** The Master places data on the bus, then pulses `~SSTB` LOW to signal the Target to latch the data.
* **On a DMA Read (`SRW=1`):** The Master pulses `~SSTB` LOW to command the Target to drive data onto the bus. The Master latches the data on the rising edge of `~SSTB`.
* **Pointer Math:** The Master pulses `~SINC` LOW to tell the Target to increment its internal address tracker for the next byte. *(Note: `~SSTB` and `~SINC` can be pulsed simultaneously, but keeping them independent allows for error recovery or repeated reads).*

### Phase 3: Flow Control (Target Driven)
The Target uses `~S_BUSY` to prevent the Master from overrunning it (e.g., if the Target is a memory card currently serving a Z80 read cycle).
* **The Master's Golden Rule:** The Master MUST continuously sample `~S_BUSY`. 
* If `~S_BUSY` is pulled LOW by the Target, the Master must instantly freeze its state machine. It cannot issue any further `~SSTB` or `~SINC` pulses until the Target releases `~S_BUSY` back to HIGH.

### Phase 4: Termination (Master Driven)
When the Master reaches the end of its programmed transfer block:
1. During the `~SSTB` pulse of the **final byte**, the Master concurrently asserts `~S_DONE` LOW.
2. The Target latches the final byte, detects the `~S_DONE` flag, and triggers any necessary internal interrupts (e.g., "Buffer Full").
3. The Master releases `~S_EN` HIGH, returning the Shadow Bus to an idle (High-Z) state.

---

## 3. The Rules of Engagement (Summary)
1. **The Master dictates the pace, but the Target grants permission.** 2. A Master must never step on an active `~S_BUSY` line.
3. Transceivers on inactive cards must yield all Shadow Bus lines to `Z` (High-Impedance) to allow the backplane pull-up resistors to hold the bus in a clean, idle HIGH state.

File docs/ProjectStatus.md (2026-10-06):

# ZX50 Project Status & Architecture Checkpoint

*Last Updated: October 5, 2026*

---

## 1. Executive Summary

The Zx50 project is a custom, multi-node Z80 distributed computing cluster featuring custom KiCad hardware cards, CPLD/FPGA memory controllers, a microcoded floating-point coprocessor, and a self-hosting modular operating system.

Since the March 2026 checkpoint, major milestones have been achieved across hardware, firmware, and emulation:
- **Physical Silicon Bring-Up**: The physical backplane (`RevD`), CPU (`RevB1`), clock mezzanine (`RevC`), memory card (`RevA1`), serial card (`RevB`), front panel (`RevB`), and bus probe (`RevB`) are operational in the chassis.
- **Operating System Kernel**: The Z80 monitor has evolved into a self-hosting OS with interrupt-driven ring buffers, an XMODEM binary loader, Process Control Block (PCB) memory auditing, and a formal Page 0 syscall SDK.
- **Microcoded FPU Architecture (`fpu_rev2`)**: Designed and fully verified a custom 32/64-bit IEEE-754 floating-point coprocessor emulator in Python with **486 unit/integration tests** and **98% code coverage**, complete with 3-operand instruction execution and an assembler specification (`SystemAssembler.md`).

---

## 2. Live System Configuration & Physical Slot Map

The active hardware test chassis is populated as follows:

| Slot | Card / Module | Status / Notes |
|:---:|:---|:---|
| **Backplane** | `Zx50_Backplane_RevD` | Operational; updated resistive termination. |
| **Display** | `Zx50_FrontPanelDisplay` | Blue LCD + rotary/switches driven by Front Panel Card. |
| **Slot 1** | `Zx50_Cpu_RevB1` + `Zx50_Clock_Mezzanine_RevC` | Z80 CPU running at 5.0 MHz / 10.0 MHz (divided from 20MHz/40MHz oscillator). |
| **Slot 2** | `Zx50_Serial_RevB` | Dual Z80 SIO channels: Port A (Console 0x84/0x86) and Port B (Debug 0x85/0x87). |
| **Slot 3** | `Zx50_MemoryCard_RevA1` | 512KB SST39SF040 Flash + SRAM; ATF1508 CPLD with boot bypass & write protection. |
| **Slot 4** | *(Reserved)* | Reserved for secondary memory card / NUMA node. |
| **Slot 5** | *(Reserved)* | Target slot for FPGA FPU Coprocessor card. |
| **Slot 6** | `Zx50_FrontPanelCard_RevB` | RP2040-driven front panel bus interface (Port 0x50). |
| **Slot 7** | `Zx50_BusProbe_RevB` | RP2040 Pico + PIC18F4620 dual-core real-time bus snooper and injector. |
| **Slot 8** | *(Empty / Probing)* | Oscilloscope probes attached to `ZCLK`, `MCLK`, and bus analyzer. |

---

## 3. Subsystem Achievements & Current Status

### 3.1 Zx50 Operating System & Monitor Kernel (`zx50_monitor`)
- **Self-Hosting OS Kernel**: Transitions seamlessly from SST39SF040 boot ROM to SRAM via a 16KB copy window and a hardware "Phantom Jump" that trips the MMU ROM kill-switch.
- **Interrupt-Driven Asynchronous I/O**:
  - IM 2 vector table with SIO Channel A/B and CTC channels.
  - Single-Producer / Single-Consumer (SPSC) lock-free ring buffers (`ring_buffer.z80`) for low-overhead serial RX and TX.
  - Dynamically enabled SIO TX interrupts (`SIO_WR1_TX_INT_EN`) and formal TX buffer reset (`SIO_CMD_RST_TX_INT`).
- **File Transfer & Application Loading**:
  - Native XMODEM receiver (`apps/xmodem.z80`) with hardware polling and timeout protection.
  - Kernel memory protection preventing loads below `0x2000`.
- **Process Control Block (PCB) & Auditing**:
  - Process table in Page 0 tracking binary names, execution entry points, page mappings, and 16-bit cumulative checksums.
  - CLI `verify <name>` command (`pcb_verify.z80`) validates in-memory integrity against bit rot before execution.
- **Developer SDK**:
  - Formal jump table (`syscall.z80`) providing OS services (`Sys_PrintString`, `Sys_ReadChar`, `Sys_PrintChar`, `Sys_Yield`, etc.).
  - Standalone app development documentation (`DEVGUIDE.md`) with example binaries (`hello.z80`).

### 3.2 FPU Math Coprocessor Subsystem (`fpu/fpu_rev2`)
- **Architecture**: Custom microcoded 32-bit / 64-bit coprocessor modeled for Lattice MachXO3 / MachXO2 FPGA implementation.
- **Python Hardware Emulator (`fpu_emu`)**:
  - **486 passed tests** with **98% overall line coverage**.
  - Cycle-accurate models for all hardware blocks:
    - **ALU Block (`adder_block.py`)**: 32-bit adder/subtractor, signed/unsigned comparisons, Booth 32x32 multiplier (`booth_mul.py`), non-restoring divider (`div_core.py`), and exponent add/subtract (`EXP_ADD`, `EXP_SUB`).
    - **Shifter Block (`shifter_block.py`)**: 64-bit barrel shifter (`LSL`, `LSR`, `ASR`), leading zero counter / priority encoder (`LZC`), float `PACK` and `UNPACK`.
    - **Logic Block (`logic_block.py`)**: 32-bit AND, OR, XOR, NOT, ABS, and CHS.
    - **Memory/Stack Block (`memory_block.py`)**: 32-bit hardware stack (`PUSH`, `POP`, `SWAP`), scratch SRAM transfer (`_LD`, `_STO`, `CP_MEM`).
    - **Control Block (`control_block.py`)**: Sequencer, `UPC`, flag branching (`JZ`, `JNZ`, `DJNZ`), and 1-level hardware `CALL` / `RET` subroutine mechanism.
- **Instruction Set Enhancements**:
  - Widened `ha_mux` to 8 inputs (including `BL` and `BH`).
  - Widened `reg_file.instr` to 21 bits (`inst_21[20:0]`), supporting canonical 3-address operations (e.g. `EXP_SUB C, EA, EB` executing $C \leftarrow EA - EB$ in 1 cycle without register destruction).
  - Floating-point microcode routines for IEEE-754 single-precision operations (`ADD_F32`, `SUB_F32`, `MUL_F32`, `DIV_F32`).
- **Assembler Specification (`SystemAssembler.md`)**:
  - Detailed design for the microcode assembler (`fasm`).
  - Always-ternary machine word synthesis (`assign ha_mux_sel = instr_reg[13:11]` in pure FPGA wires).
  - Automatic branch delay-slot `NOP` insertion and instruction scheduling.
  - Decoupled `User.<Name>` labels with an external `user_opcodes.def` mapping to initialize the EBR 7 dispatch lookup table.
  - Outputs: `.hex` (Verilog `$readmemh`), `.bin`, `.sym` (symbol & opcode dispatch tables), and `.map`.

### 3.3 Memory Subsystem Generations
- **RevA1 (Current Physical Hardware)**:
  - ATF1508AS CPLD fitted at 96% macrocell utilization (124/128).
  - Bodge fix applied to LED pull-up drops, dropping standby current from 500mA to a healthy 114mA.
  - Linear 32KB boot ROM bypass and hardware EEPROM write protection verified.
- **RevB (Lattice MachXO2 Design)**:
  - Transition to 3.3V FPGA in TQFP-100/144 package using 74LVC245 level translators.
  - Eliminates external ISSI SRAM by placing the MMU page table directly into FPGA Block RAM (BRAM).
  - Supported by open-source Yosys + NextPNR (Project Trellis) toolchain.
- **RevC (Lattice MachXO3 NUMA/PGAS Architecture)**:
  - Fast-path data plane: Zero-contention cycle-stealing DMA over 12ns SRAM, ~WAIT generation, custom 8b/10b physical packet framing over LVDS.
  - Control plane: Embedded RISC-V softcore SmartNIC managing dynamic PGAS routing, mailbox interrupts, and lock arbitration.

### 3.4 Bus Probe & Diagnostics (`Zx50_BusProbe_RevB`)
- **Hardware**: RP2040 Pico paired with PIC18F4620 interface chip snooping backplane buses via high-speed multiplexers.
- **Firmware**:
  - Modular Pico firmware (`bus.py`, `pic18_link.py`, `pins.py`) with non-blocking interactive command REPL.
  - 1 Mbps binary RPC UART link to the PIC18F4620 supporting single-step, bus sniffing, and memory snapshot commands.
  - Direct memory access (`machine.mem32[0xd0000004]`) for single-cycle 8-bit bus acquisition.
- **Host Software & RF Analysis**:
  - SCPI control driver (`scope_control.py`) over LAN for Tektronix MDO3034 oscilloscope.
  - Automated sweep orchestrator (`test_runner.py`) logging voltage and phase sweeps across TX/RX lines.
  - Jupyter workflow (`backplane_analysis.ipynb`) analyzing signal integrity and crosstalk against TTL thresholds.

---

## 4. Hardware Rework & Board Tasks

### 4.1 Zx50_Serial_RevB
- [ ] **DCDA (Pin 19):** Pull down to GND (or add 10k resistor) on `IC2` to allow enabling `Auto Enables` without receiver stalling.
- [ ] **CTSA (Pin 18):** Add 10k pull-down so transmissions flow when using standard 3-wire serial cables (TX/RX/GND).
- [ ] **Firmware Flow Control:** Re-enable `SIO_WR3_AUTO_EN` in `kernel/io/serial.z80` once physical pull-downs are confirmed.

### 4.2 Zx50_BusProbe_RevB
- [ ] **Display Integration:** Complete `display.py` integration to drive the onboard OLED/LCD diagnostics readout.
- [ ] **Live Backplane Sweep:** Execute `test_runner.py` across all slots on `Zx50_Backplane_RevD` to measure RF crosstalk under high-speed switching.

---

## 5. Next Steps & Active Development

### Phase 1: FPU Microcode Assembler (`fasm`)
1. Implement the multi-pass microcode assembler in Python using a maintainable grammar parser (`lark` / `ply`) per [SystemAssembler.md](file:///Users/marc/Documents/z80/Zx50/fpu/fpu_rev2/SystemAssembler.md).
2. Support decoupled `user_opcodes.def` mapping to automatically generate the EBR 7 dispatch lookup table.
3. Implement delay slot management (automatic `NOP` insertion after `JMP`, `JZ`, `JNZ`, `DJNZ`, `CALL`, `RET`).
4. Emit `.hex`, `.bin`, `.sym`, and `.map` files, and test with the existing test suite and `fpu_emu`.

### Phase 2: FPU Status Save/Restore (`SSAV` / `SRES`) & Microcode Optimization
1. Implement 1-depth status register save (`SSAV`) and restore (`SRES`) opcodes in `ControlBlock` and `Registers`.
2. Optimize the `ADD_F32` microcode sequence in `micro_code.py` using 3-address `EXP_SUB C, EA, EB` (saving 4 cycles and eliminating `FL` register stashing).
3. Port complete transcendental and floating-point subroutines (`MUL_F32`, `DIV_F32`) to `.fasm` source files.

### Phase 3: Zx50 OS Kernel Virtual Memory & Multitasking
1. **Paging Manager**: Add `Page` allocation tracking in `PCB_Entry` to dynamically assign physical 4KB memory pages to transient applications.
2. **Standard Application Window (`0x4000`)**: Compile all user applications to `ORG 0x4000`; map application pages into `0x4000` on launch and unmap on exit.
3. **Preemptive Multitasking**: Connect CTC Channel 3 timer interrupts (100 Hz) to a context-switching scheduler to run concurrent isolated tasks.

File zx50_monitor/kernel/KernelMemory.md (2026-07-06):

# Zx50 Kernel Memory Architecture

N.B. This is a design document, not what is currently implemented

This document defines the memory management system for the Zx50 Operating System, including physical page allocation, MMU hardware interaction, and context switching.

## 1. Hardware MMU & Physical Addressing

The Zx50 utilizes a hardware Memory Management Unit (MMU) capable of mapping 4KB physical memory pages into any 4KB logical window of the Z80's 64KB address space.

To future-proof the OS for up to 16 expansion cards (16MB total RAM), physical pages are identified internally as a 16-bit `WORD`:
* **Upper Byte (Port):** The hardware I/O port of the memory card (`0x30` to `0x3F`). 
* **Lower Byte (Page):** The specific physical page on that card (`0x00` to `0xFF`).

*Note: The ROM card is permanently assigned to port `0x30`.*

## 2. Logical Memory Map

The Z80's 64KB logical address space is divided strictly between Kernel Space and User Space.

* **`0x0000 - 0x3FFF` (16KB Kernel Space):** Reserved for the OS ROM, Kernel RAM, OS Variables, and the Kernel Stack. 
  * Physical pages `0x3000` through `0x3003` are permanently reserved for this space.
* **`0x4000 - 0xFFFF` (48KB User Space):** The application execution window. Apps are compiled with `ORG 0x4000` and are swapped in and out of this space by the scheduler.

## 3. The Allocator (`PAGE_OWNERSHIP`)

The OS tracks physical memory usage via a flat 1KB byte-array named `PAGE_OWNERSHIP`. This table tracks 1024 physical pages (representing 4 memory cards).

**Byte Values:**
* `0x00` = Free
* `0xFF` = System / Kernel Reserved
* `0x01` to `0x0A` = Owned by a specific application (represented by its `PROG_TABLE` PID).

### Allocation Strategies
* **Version 1 (Current): Linear Scan.** The OS uses the Z80's hardware-accelerated `CPIR` instruction to perform a rapid linear scan of `PAGE_OWNERSHIP` to find the first `0x00` byte, claim it with the requesting PID, and calculate the resulting Port/Page `WORD`.
* **Version 2 (Future): Free-List Ring Buffer.** To achieve `O(1)` allocation, the OS will eventually maintain a 2KB FIFO ring buffer of free physical pages. 

## 4. Application Tracking (PCB)

The Program Control Block (`PCB_Entry`) manages the execution state and physical memory footprint of each loaded application.

```assembly
; Run States
STATE_EMPTY     EQU 0x00
STATE_ACTIVE    EQU 0x01
STATE_PAUSED    EQU 0x02    ; Swapped out

STRUCT PCB_Entry
    Name        TEXT 8      ; App Name
    Base        WORD        ; Logical entry address (e.g., 0x4000)
    Size        WORD        ; App footprint in bytes
    Chksum      WORD        ; 16-bit validation checksum
    RunState    BYTE        ; EMPTY, ACTIVE, or PAUSED
    AppSP       WORD        ; Saved Stack Pointer
    PageMap     BLOCK 24    ; Array of up to 12 physical Port/Page WORDs
ENDS
```
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

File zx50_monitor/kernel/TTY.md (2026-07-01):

# Zx50 Operating System: Interrupt-Driven Serial I/O Architecture

This document outlines the architectural plan for transitioning the Zx50 OS from a blocking, polled serial I/O model to a fully interrupt-driven, non-blocking asynchronous model. This design supports dual independent serial ports (Port A and Port B) and abstracts the hardware from user-space applications using memory-based ring buffers.

---

## 1. Core Concepts
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

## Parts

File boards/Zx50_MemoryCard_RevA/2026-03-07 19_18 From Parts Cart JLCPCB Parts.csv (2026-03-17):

Parts Type | JLCPCB Part # | MFR Part # | Description | Unit Price | Qty | Total Price
stock | C14663 | CC0603KRX7R9BB104 | 100nF 50V X7R ±10% 0603 Multilayer Ceramic Capacitors MLCC - SMD/SMT ROHS | 0.0026 | 24 | 0.07
stock | C2062861 | IS61C256AL-12JLI-TR | -40℃~+85℃ 12ns 256Kbit 4.5V~5.5V 40mA 450uA Parallel Port (Parallel) SOJ-28 SRAM ROHS | 1.7867 | 1 | 1.79
stock | C3018881 | CY7C1049DV33-10ZSXIT | -40℃~+85℃ 10mA 10ns 3V~3.6V 4Mbit 90mA TSOPII-44-10.2mm SRAM ROHS | 9.0217 | 2 | 18.05
stock | C131956 | SN74ABT541BPWR | -40℃~+85℃ 1 250uA 2ns@5V,50pF 32mA 4.5V~5.5V 64mA 74ABT 8 Tri-State TSSOP-20 Buffers, Drivers, Receivers, Transceivers ROHS | 1.0957 | 2 | 2.2
stock | C1548132 | SN74ABT245BDW | -40℃~+85℃ 250uA 2ns@5V,50pF 32mA 4.5V~5.5V 64mA 74ABT Bidirectional Tri-State SOIC-20-300mil Buffers, Drivers, Receivers, Transceivers ROHS | 0.8491 | 3 | 2.55
stock | C2676105 | SN74ABT16244ADGGR | -40℃~+85℃ 32mA 3mA 4 4 4.5V~5.5V 64mA 74ABT Tri-State TSSOP-48-6.1mm Buffers, Drivers, Receivers, Transceivers ROHS | 1.3661 | 1 | 1.37
stock | C31179 | ATF1508AS-10AU100 | TQFP-100(14x14) Programmable Logic Device (CPLDs/FPGAs) ROHS | 20.8308 | 1 | 20.84

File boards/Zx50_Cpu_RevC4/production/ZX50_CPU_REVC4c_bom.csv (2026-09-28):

Designator | Footprint | Quantity | Value | LCSC Part #
C1, C10, C11, C12, C2, C3, C4, C5, C6, C7, C8 | 0805 | 11 | 0.1uF | C1525
C13 | CP_EIA-3216-10_Kemet-I_HandSolder | 1 | 10u | C7171
C14, C15, C16, C18, C19, C20, C21, C22, C23, C25, C26, C27, C28, C29, C30, C31 | 0805 | 16 | 100nF | C28233
C17 | 0805 | 1 | 100n | C1525
C24 | 1206 | 1 | 10u | C7171
C33 | 0805 | 1 | 100n | C49678
C9 | C_Radial_D8.0mm_H7.0mm_P3.50mm | 1 | 100uF
D1 | LED_D5.0mm | 1 | PWR
D2 | LED_D5.0mm | 1 | HALT
D4 | 0805 | 1 | DONE | C2297
J1 | PinHeader_2x40_P2.54mm_Horizontal_Edge | 1 | Zx50_EdgeConnector
J2 | PinHeader_1x02_P2.54mm_Vertical | 1 | STEP_N
J3 | PinSocket_2x05_P2.54mm_Horizontal | 1 | Clock Mezzanine
J4 | IDC-Header_2x05_P2.54mm_Horizontal_Edge | 1 | Front Panel
J5 | PinHeader_1x02_P2.54mm_Vertical | 1 | TP_D_DIR
J6 | PinHeader_1x02_P2.54mm_Vertical | 1 | TP_BUSAK
J7 | PinHeader_1x06_P2.54mm_Vertical | 1 | JTAG
J8 | PinHeader_1x02_P2.54mm_Vertical | 1 | DBG_EN
J9 | PinHeader_1x06_P2.54mm_Vertical | 1 | DEBUG
Q1 | SOT-23 | 1 | BSS84
Q2, Q4 | SOT-23-3 | 2 | 2N7002-7-F | C8545
R1, R4 | 0805 | 2 | 470 | C17710
R10, R11, R15, R16, R17, R19, R6, R9 | 0805 | 8 | 4k7 | C17713
R12, R13, R14, R2, R7 | 0805 | 5 | 10k | C17414
R3 | 0805 | 1 | 47K | C17713
R8 | 0805 | 1 | 33R | C17634
SW1 | SW_PUSH_6mm_H7.3mm | 1 | RESET
SW2 | SW_SPST_PTS645Sx43SMTR92 | 1 | RESET
U1 | SOT-23-5_HandSoldering | 1 | 74AHC1G14
U10 | SOIC-14_3.9x8.7mm_P1.27mm | 1 | 74ACHT132
U11 | SOT-223-3_TabPin2 | 1 | AMS1117-3.3 | C6186
U12, U13, U14 | DB24 | 3 | 74CBTD3861 | C11617
U15, U16 | SOT-753 | 2 | 74LVC1G17 | C7836
U17 | TQFP100_LAT | 1 | LCMXO2-2000HC-4TG100I | C1521620
U18 | SOP50P1400X120-32N | 1 | IS61WV1288EEBLL-10HLI | C1349956
U19 | SOIC127P600X88-8N | 1 | IS25LP080D-JNLE-TR | C521286
U2, U3, U5, U7 | SOIC-20W_7.5x12.8mm_P1.27mm | 4 | SN74ABT245BN
U4 | DIP-40_W15.24mm | 1 | Z84C00xxP
U6 | SOT-23-5_HandSoldering | 1 | MCP1316MT-46LE/OT
U8 | SOT-23-6_Handsoldering | 1 | 74LVC1G3208
U9 | SOIC-14_3.9x8.7mm_P1.27mm | 1 | SN74AHCT74DRG4

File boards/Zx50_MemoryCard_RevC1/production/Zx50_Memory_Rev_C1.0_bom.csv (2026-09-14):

Designator | Footprint | Quantity | Value | LCSC Part #
C1, C2, C3, C6, C77, C78, C79, C8, C80, C85 | 1206 | 10 | 10u | C7171
C10, C11, C12, C13, C14, C15, C16, C17, C18, C22, C23, C24, C28, C29, C30, C31, C32, C33, C34, C35, C36, C37, C38, C39, C4, C40, C41, C42, C43, C48, C49, C5, C54, C58, C59, C60, C61, C62, C63, C64, C65, C66, C67, C68, C7, C74, C75, C76, C81, C82, C83, C84, C9 | 0402 | 53 | 100n | C1525
C44, C45, C46, C47, C50, C51, C52, C53 | 0402 | 8 | 220nF | C16772
C55 | 0402 | 1 | 200n | C1525
C56, C57 | 1206 | 2 | 1n 2kV | C9196
C69 | 0402 | 1 | 1uF | C52923
D10 | LED_D3.0mm | 1 | DONE
D11 | LED_D3.0mm | 1 | JTAG ACT
D12 | LED_D3.0mm | 1 | RS232 ACT
D7 | LED_D3.0mm | 1 | INIT
D8, D9 | D_SOD-323 | 2 | 1N5819 | C191023
FB1 | 0805 | 1 | 600R | C1017
J1 | PinHeader_1x01_P2.54mm_Vertical | 1 | 2.5V
J10 | IDC-Header_2x03_P2.54mm_Horizontal | 1 | RS232 5V
J11, J12 | HANRUN_HR911130A | 2 | RJ45_RB1-125B8G1A | C50933
J2 | PinHeader_1x01_P2.54mm_Vertical | 1 | 3.3V
J3 | PinSocket_2x40_P2.54mm_Horizontal_Edge | 1 | Zx50_EdgeConnector
J4 | PinHeader_1x01_P2.54mm_Vertical | 1 | TP_CLK
J5 | PinHeader_1x01_P2.54mm_Vertical | 1 | TP_MCLK
J6, J7 | PinHeader_1x01_P2.54mm_Vertical | 2 | GND
J8 | IDC-Header_2x09_P2.54mm_Vertical | 1 | DEBUG
J9 | IDC-Header_2x06_P2.54mm_Horizontal | 1 | JTAG 5V
R1, R2, R3, R68, R69, R70, R71, R72, R73, R76 | 0805 | 10 | 10k | C17414
R102, R107, R108, R113, R118, R119, R120, R121, R122, R123, R124, R125, R23, R28, R30, R32, R35, R40, R66, R74, R75, R84, R85, R86, R87 | 0402 | 25 | 10k | C25744
R24, R25, R26, R27, R29, R31, R34, R37 | 0402 | 8 | 4k7 | C25900
R38, R39 | 0805 | 2 | 470R | C17710
R4, R5 | 0603 | 2 | 33R | C23140
RN1 | R_Array_SIP6 | 1 | 10K | 4606X-AP1-103LF
RN2, RN3, RN4 | R_Array_Convex_8x0602 | 3 | 33R | C422182
SW1 | SW_DIP_SPSTx05_Slide_9.78x14.88mm_W7.62mm_P2.54mm | 1 | SW_DIP_x05 | 208-5
U1 | SOT-223-3_TabPin2 | 1 | AMS1117-2.5 | C347221
U10 | VSSOP-8_2.3x2mm_P0.5mm | 1 | 74LVC3G07 | C131955
U11, U21, U23, U24, U3, U4, U5, U6, U9 | TSSOP-20_4.4x6.5mm_P0.65mm | 9 | 74LVC245 | C7848
U12 | CABGA400_LAT | 1 | LCMXO3LF-6900C-5BG400C
U13 | TSSOP14_PW_TEX | 1 | TXU0204PWR | C4363888
U14 | TSSOP14_PW_TEX | 1 | TXU0304PWR | C4364118
U15, U16, U17, U18 | TSOP-44_11P9X18P5_ISI | 4 | IS61WV10248EDBLL | C1349228
U19, U20 | SOIC127P600X88-8N | 2 | IS25LP080D-JNLE-TR | C521286
U2 | SOT-223-3_TabPin2 | 1 | AMS1117-3.3 | C6186
U22 | SOT-753 | 1 | SN74LVC1G17DBVR | SN74LVC1G17DBVR
U7, U8 | SOT-753 | 2 | 74LVC1G17 | C7836
Y1 | Crystal_SMD_3225-4Pin_3.2x2.5mm | 1 | 25 MHz | C669088

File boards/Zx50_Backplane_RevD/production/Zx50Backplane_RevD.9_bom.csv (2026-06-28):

Designator | Footprint | Quantity | Value | LCSC Part #
C10, C12, C13, C14 | 0805 | 4 | 47pF | C14857
C11 | 0805 | 1 | 27pF | C49326673
C2, C3, C4, C5, C6, C7, C8, C9 | 0805 | 8 | 0.1uF | C28233
CN1, CN10, CN11, CN12, CN13, CN14, CN15, CN16, CN2, CN3, CN4, CN5, CN6, CN7, CN8, CN9 | CAP_CA0612_3P2X1P6_YAG | 16 | 47pF | C22446551
R1, R11, R12, R5, R6, R7 | 0805 | 6 | 10K | C237755
R10, R2, R3, R8, R9 | 0805 | 5 | 100R | C17408
R4 | 0805 | 1 | 470 | C17710
RN1, RN11, RN13, RN15, RN3, RN4, RN8, RN9 | SOIC-16W_5.3x10.2mm_P1.27mm | 8 | 100R | C1358123

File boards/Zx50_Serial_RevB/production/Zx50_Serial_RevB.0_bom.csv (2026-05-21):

Designator | Footprint | Quantity | Value | LCSC Part #
C1, C10, C11, C12, C13, C2, C3_2, C3, C6, C8 | C_Disc_D5.0mm_W2.5mm_P5.00mm | 10 | 0.1uF
C9 | CP_Radial_Tantal_D5.0mm_P2.50mm | 1 | 10uF
D1 | LED_D5.0mm | 1 | TXB
D2 | LED_D5.0mm | 1 | TXA
IC1 | DIP-28_W15.24mm_Socket | 1 | Z80CTC
IC2 | DIP-40_W15.24mm_Socket | 1 | Z80DART
J1 | PinSocket_2x40_P2.54mm_Vertical_Oval | 1 | Zx50_EdgeConnector
J2 | DSUB-9_Receptical_A-DF_09_A_KG-T2S | 1 | DE9_Socket
J3 | DSUB-9_Receptical_A-DF_09_A_KG-T2S | 1 | DB9-USB-D5-F
J4 | PinHeader_1x05_P2.54mm_Horizontal | 1 | PortA
J5 | PinHeader_1x05_P2.54mm_Horizontal | 1 | PortB
R1, R2 | R_Axial_DIN0207_L6.3mm_D2.5mm_P10.16mm_Horizontal | 2 | 1K
U1 | DIP-16_W7.62mm_Socket | 1 | 74AHCT138
U4 | DIP-16_W7.62mm_Socket | 1 | MAX232ACPE
Y1 | Oscillator_DIP-8 | 1 | 7.3728 MHz

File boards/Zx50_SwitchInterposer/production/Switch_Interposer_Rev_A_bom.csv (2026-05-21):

Designator | Footprint | Quantity | Value | LCSC Part #
C2 | C_Disc_D5.0mm_W2.5mm_P5.00mm | 1 | 0.1uF
J1 | PinSocket_2x05_P2.54mm_Vertical | 1 | To Switches
J2 | PinHeader_1x06_P2.54mm_Horizontal_EDGE | 1 | PIC PGM
J3 | IDC-Header_2x05_P2.54mm_Vertical | 1 | To CPU
R1 | R_Axial_DIN0207_L6.3mm_D2.5mm_P10.16mm_Horizontal | 1 | 10k
U1 | DIP-8_W7.62mm | 1 | PIC16F18015-I/P
U2 | SOT-23-5 | 1 | TLV73333PDBV

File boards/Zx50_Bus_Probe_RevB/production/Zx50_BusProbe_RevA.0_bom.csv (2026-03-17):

Designator | Footprint | Quantity | Value | LCSC Part #
A1 | RaspberryPi_Pico_Common_Unspecified | 1 | RaspberryPi_Pico
C1, C10, C11, C12, C13, C14, C15, C16, C17, C18, C19, C2, C20, C3, C4, C5, C6, C7, C8, C9 | C_Disc_D5.0mm_W2.5mm_P2.50mm | 20 | .1uF
C21 | CP_Radial_Tantal_D5.0mm_P2.50mm | 1 | 10uF
D1 | LED_D5.0mm_Horizontal_O1.27mm_Z3.0mm | 1 | MCLK
D2 | LED_D5.0mm_Horizontal_O1.27mm_Z3.0mm | 1 | CLK
D3 | LED_D5.0mm_Horizontal_O1.27mm_Z3.0mm | 1 | PWR
J1 | PinSocket_2x40_P2.54mm_Horizontal_Edge | 1 | Zx50_EdgeConnector
J10 | PinHeader_1x03_P2.54mm_Vertical | 1 | CH1
J11 | PinHeader_1x03_P2.54mm_Vertical | 1 | CH2
J12 | PinHeader_1x03_P2.54mm_Vertical | 1 | CH3
J15 | PinHeader_2x16_P2.54mm_Vertical_Row_Letter_Last | 1 | Z80_Addr
J16 | PinHeader_2x08_P2.54mm_Vertical_Row_Letter_Last | 1 | Z80_Data
J17 | PinHeader_2x08_P2.54mm_Vertical_Row_Letter_Last | 1 | Z80_Ctrl
J18 | PinHeader_2x02_P2.54mm_Vertical_Row_Letter_Last | 1 | Clock
J19 | PinHeader_2x08_P2.54mm_Vertical_Row_Letter_Last | 1 | SH_Data
J2 | BNC_Amphenol_B6252HB-NPP3G-50_Horizontal | 1 | OUT
J20 | PinHeader_2x08_P2.54mm_Vertical_Row_Letter_Last | 1 | SH_Ctrl
J3 | BNC_Amphenol_B6252HB-NPP3G-50_Horizontal | 1 | IN
J4 | PinHeader_1x06_P2.54mm_Horizontal_EDGE | 1 | PIC PGM
J5 | PinHeader_1x03_P2.54mm_Vertical | 1 | P0
J6 | PinHeader_1x03_P2.54mm_Vertical | 1 | P1
J7 | PinHeader_1x03_P2.54mm_Vertical | 1 | P2
J8 | IDC-Header_2x05_P2.54mm_Horizontal_Edge | 1 | Send/Recv Card
J9 | PinHeader_1x03_P2.54mm_Vertical | 1 | CH0
LCD1 | EA_DIG205G-4NLED | 1 | EA 205G-4NLED
R1, R2 | R_Axial_DIN0207_L6.3mm_D2.5mm_P10.16mm_Horizontal | 2 | 49.9R 1W 1%
R10 | R_Axial_DIN0207_L6.3mm_D2.5mm_P5.08mm_Vertical | 1 | 33R
R3, R4 | R_Axial_DIN0207_L6.3mm_D2.5mm_P10.16mm_Horizontal | 2 | 10k
R5 | R_Axial_DIN0207_L6.3mm_D2.5mm_P10.16mm_Horizontal | 1 | 2.2k
R6 | R_Axial_DIN0207_L6.3mm_D2.5mm_P10.16mm_Horizontal | 1 | 3.3k
R7, R8 | R_Axial_DIN0207_L6.3mm_D2.5mm_P5.08mm_Vertical | 2 | 2.2K
R9 | R_Axial_DIN0207_L6.3mm_D2.5mm_P5.08mm_Vertical | 1 | 470
U1, U13 | DIP-28_W7.62mm_Socket | 2 | MCP23S17_SP
U10, U11, U12, U2, U3, U4, U5, U8, U9 | DIP-16_W7.62mm_Socket | 9 | CD74HC4051E
U14 | SOIC-24W_7.5x15.4mm_P1.27mm | 1 | CD74HC154M96
U15, U16 | SOIC-8_3.9x4.9mm_P1.27mm | 2 | OPA356xxD
U17 | DIP-40_W15.24mm_Socket | 1 | PIC18F4620-I_P
U18 | DIP-20_W7.62mm_Socket | 1 | 74AHCT541
U6, U7 | DIP-20_W7.62mm_Socket | 2 | SN74ABT245BN

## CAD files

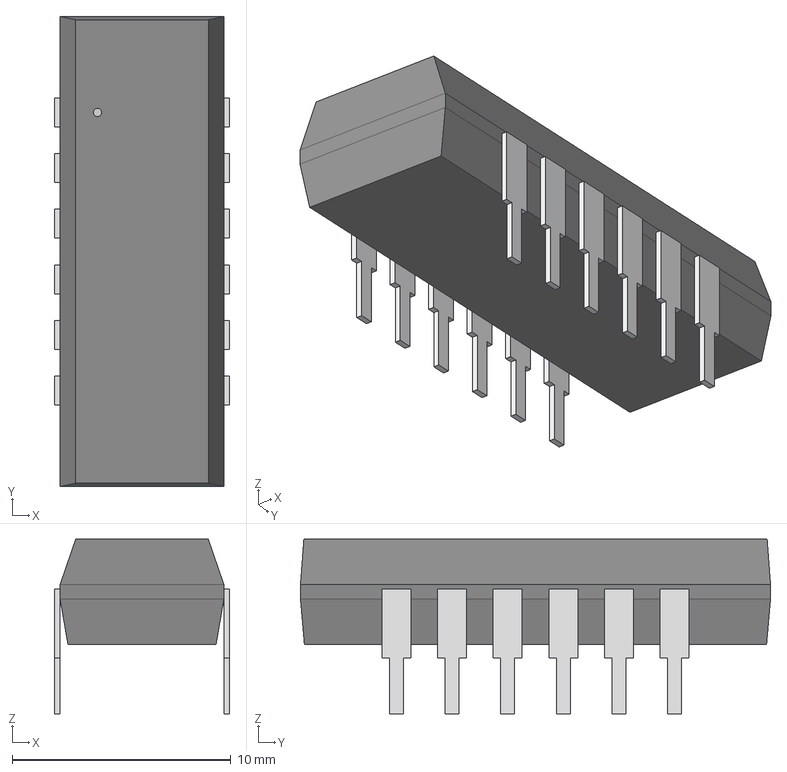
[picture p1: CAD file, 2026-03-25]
boards/3dmodels/DIP12_HCMS-396X_BRA.step
7.99 x 21.5 x 7.98 mm

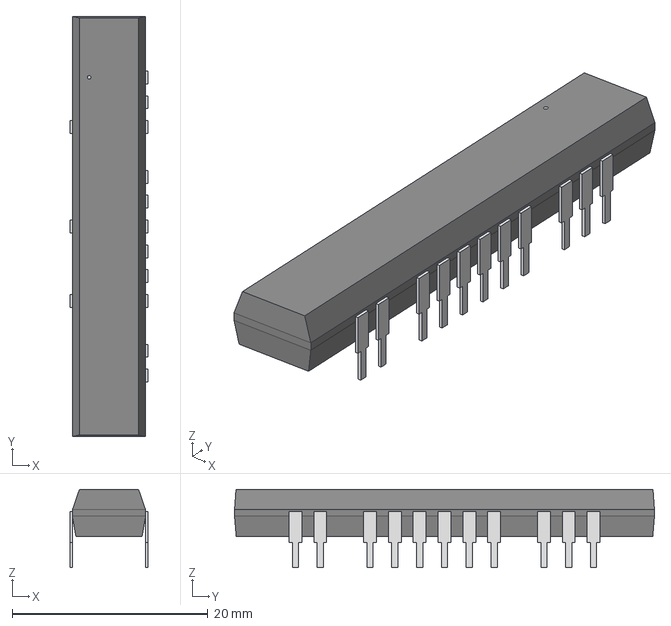
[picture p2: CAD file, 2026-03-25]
boards/3dmodels/DIP12_HCMS-397X_BRA.step
7.99 x 42.9 x 7.98 mm

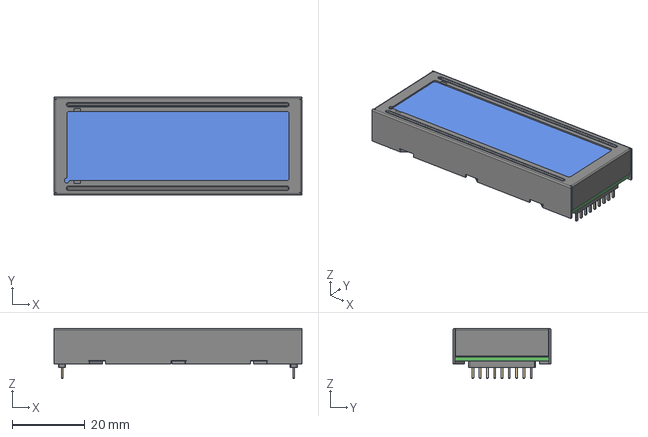
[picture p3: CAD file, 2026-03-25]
boards/3dmodels/EA_DIP205G-4NLED.stp
68.0 x 26.8 x 13.8 mm

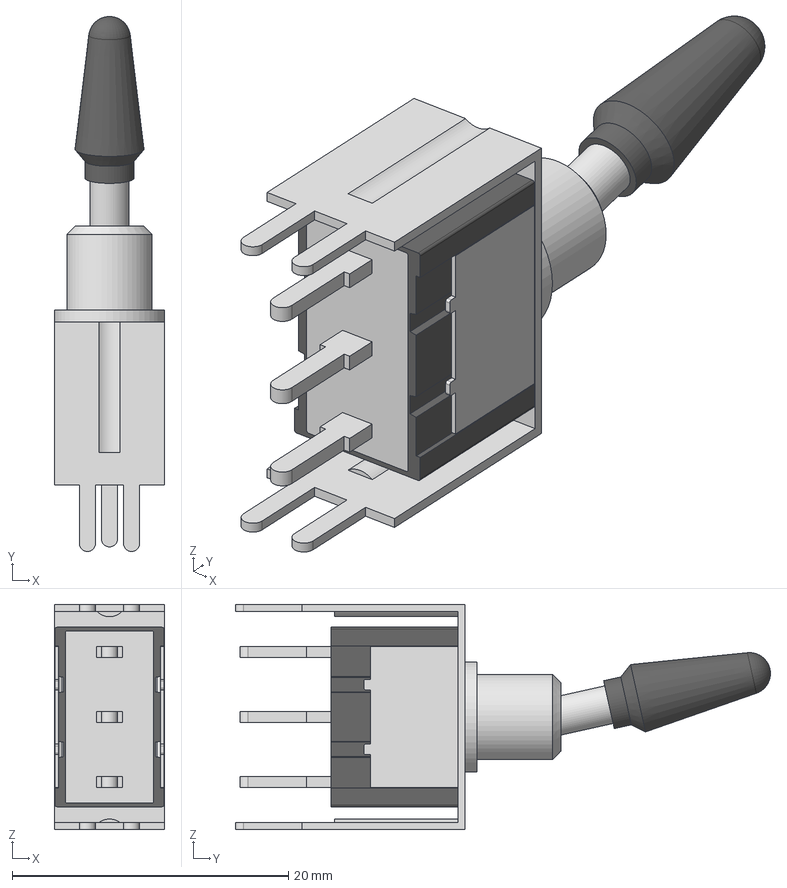
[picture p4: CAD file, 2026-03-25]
boards/3dmodels/MN15SA2W13-BA.stp
8.00 x 38.8 x 16.3 mm
M20151SA2W13-BABR-switch
BBRACKET13
M201A2M201BR-bushing
M201503BR-terminals
M20S-toggles
M20SBA-caps

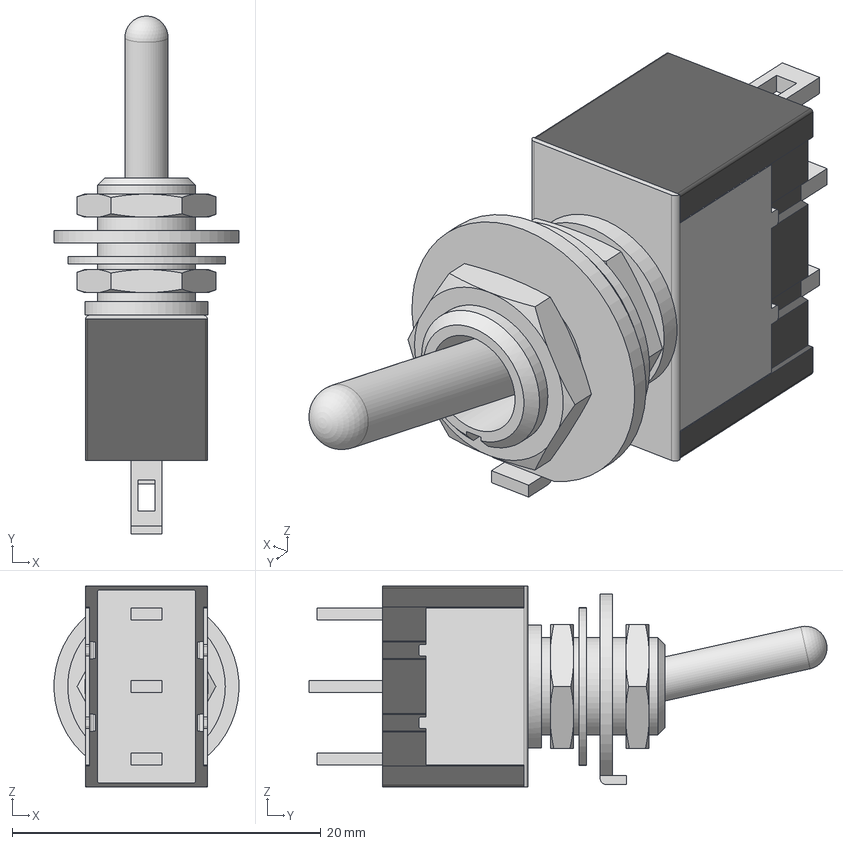
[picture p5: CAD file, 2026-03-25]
boards/3dmodels/MN15SS1W01.stp
12.0 x 33.6 x 13.0 mm
M20151SS1W01-switch
M201S1M201-bushing
AT513H x 2
AT507H
AT509
M201501-terminals
M20S-toggles
M20S-caps

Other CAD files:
boards/3dmodels/MN11SS1W01.stp

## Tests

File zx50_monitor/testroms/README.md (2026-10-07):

# Zx50 Diagnostic Test ROMs

Graduated, minimal test ROMs designed to isolate hardware subsystems one by one directly from EEPROM. None of these test ROMs use interrupts, stacks, or complex paging initially, making them ideal for single-stepping or logic analyzer debugging.

All commands below should be run from the repository root (`zx50_monitor/`).

### Quick Build: Assemble All Test ROMs
```bash
for rom in testroms/*.z80; do sjasmplus --fullpath --lst="${rom%.z80}.lst" --sld="${rom%.z80}.sld" --sym="${rom%.z80}.sym" "$rom"; done
```

---

## 1. `1-lcd_only.z80` (`1-lcd_only.bin`, 35 bytes)
* **Goal:** Verify CPU execution from EEPROM and Front Panel LCD communication.
* **Dependencies:** None (No RAM, No Stack, No Interrupts, No SIO, No CTC).
* **Behavior:**
  1. Executes `DI` at `0x0000`.
  2. Waits ~170ms for the Raspberry Pi Pico Front Panel to finish cold boot.
  3. Uses `OTIR` to send `"Hello Zx50\n"` to LCD Port `0x50`.
  4. Executes `HALT` (CPU halts and asserts `~HALT` low).
* **Assemble Command:**
  ```bash
  sjasmplus --fullpath --lst=testroms/1-lcd_only.lst --sld=testroms/1-lcd_only.sld --sym=testroms/1-lcd_only.sym testroms/1-lcd_only.z80
  ```
* **Flash Command:**
  ```bash
  minipro -p SST39SF040 -w 1-lcd_only.bin -s
  ```

---

## 2. `2-serial_tx_polled.z80` (`2-serial_tx_polled.bin`, 171 bytes)
* **Goal:** Verify CTC Channel 0 baud rate generation and SIO Channel A transmit to the FTDI USB console.
* **Dependencies:** None (Pure polled I/O, No RAM, No Stack, No Interrupts).
* **Behavior:**
  1. Displays `"Serial Tx Test...\n"` on Front Panel LCD.
  2. Programs CTC Channel 0 (`0x80`) in Counter Mode with `TC = 1` (divides onboard 1.8432 MHz oscillator to 1.8432 MHz).
  3. Programs SIO Channel A (`0x86`) for 115200 Baud 8N1 (x16 clock factor, 1 stop bit, no parity, no auto-enables).
  4. Repeatedly streams `"Hello from Zx50 Serial Port A (115200 8N1)!\r\n"` with a ~0.5s pause between bursts.
* **Assemble Command:**
  ```bash
  sjasmplus --fullpath --lst=testroms/2-serial_tx_polled.lst --sld=testroms/2-serial_tx_polled.sld --sym=testroms/2-serial_tx_polled.sym testroms/2-serial_tx_polled.z80
  ```
* **Flash Command:**
  ```bash
  minipro -p SST39SF040 -w 2-serial_tx_polled.bin -s
  ```
* **Terminal Settings:** 115200 Baud, 8N1, Flow Control: None.

---

## 3. `3-serial_echo_polled.z80` (`3-serial_echo_polled.bin`, 238 bytes)
* **Goal:** Verify bidirectional serial communication (Rx and Tx) over FTDI USB.
* **Dependencies:** None (Pure polled I/O, No RAM, No Stack, No Interrupts).
* **Behavior:**
  1. Displays `"Serial Echo ON...\n"` on Front Panel LCD.
  2. Initializes CTC Ch0 and SIO ChA for 115200 8N1.
  3. Sends initial greeting prompt to the serial terminal.
  4. Enters an infinite polled loop: whenever a character is received in SIO RR0, reads it from Data Port `0x84` and echoes it back immediately.
* **Assemble Command:**
  ```bash
  sjasmplus --fullpath --lst=testroms/3-serial_echo_polled.lst --sld=testroms/3-serial_echo_polled.sld --sym=testroms/3-serial_echo_polled.sym testroms/3-serial_echo_polled.z80
  ```
* **Flash Command:**
  ```bash
  minipro -p SST39SF040 -w 3-serial_echo_polled.bin -s
  ```

---

## 4. `4-ram_mmu_test.z80` (`4-ram_mmu_test.bin`, 191 bytes)
* **Goal:** Verify the CPLD MMU mapping and physical SRAM read/write operations.
* **Dependencies:** MMU Port `0x30`, LCD Port `0x50` (Code executes from ROM at `0x0000`, testing RAM at `0x8000`).
* **Behavior:**
  1. Displays `"RAM Testing...\n"` on LCD.
  2. Uses MMU Port `0x30` to map Physical RAM Page 0 to Logical Window 8 (`0x8000 - 0x8FFF`).
  3. Fills 4KB with `0xAA` and verifies every byte.
  4. Fills 4KB with `0x55` and verifies every byte.
  5. Fills 4KB with an address pattern (low byte of address) and verifies every byte.
  6. If all patterns match, displays `"RAM TEST PASS!\n"` on LCD.
  7. If any mismatch occurs, displays `"RAM TEST FAIL!\n"` on LCD.
  8. Executes `HALT`.
* **Assemble Command:**
  ```bash
  sjasmplus --fullpath --lst=testroms/4-ram_mmu_test.lst --sld=testroms/4-ram_mmu_test.sld --sym=testroms/4-ram_mmu_test.sym testroms/4-ram_mmu_test.z80
  ```
* **Flash Command:**
  ```bash
  minipro -p SST39SF040 -w 4-ram_mmu_test.bin -s
  ```

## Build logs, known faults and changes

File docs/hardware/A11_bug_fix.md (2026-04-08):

### 1. Code Organization: Use Compiler Macros (`` `ifdef ``)

I highly recommend **against** creating a separate `src_a11` directory. If you find a bug in the Arbiter's state machine
three months from now, having to remember to patch it in two different source trees is a nightmare.

Instead, we should use the Verilog preprocessor. We will wrap the specific wiring changes in an
`` `ifdef HW_REV_A11_BUG `` block.

In your Makefile, you can simply add a second build target (e.g., `make run-tests-a11`) that passes the
`-DHW_REV_A11_BUG` flag to the `iverilog` compiler. The testbenches above the card level won't even know the hardware
changed, and you maintain a single "source of truth" for your logic.

### 2. The Design Theory: Isolating the Bug

I have fantastic news: **The DMA and MMU state machines do not need to change at all.** We want to keep the DMA module
generating a pure, clean, linear 20-bit physical address. We will absorb 100% of the hardware complexity inside the
`zx50_cpld_core.v` routing matrix.

Here is exactly how the CPLD must manipulate the address bits to satisfy the physical wiring of the faulty boards:

**The RAM Rule (The 2K Stripe)**
Because `A11` is physically wired to the SRAM Chip Selects, a 4KB logical page is split in half: the bottom 2KB lives on
RAM0, and the top 2KB lives on RAM1.

* **Bank Select:** Driven by the active master's bit 11 (`dma_phys_addr[11]` or `z80_addr[11]`).
* **ATL Data Bus:** For the RAM, the `atl_data` bus represents the 4KB block number. So, the CPLD just passes the pure
  upper bits: `atl_data = dma_phys_addr[19:12]`. As the DMA address linearly increments, it seamlessly crosses the `A11`
  chip boundary while keeping the 4K block pointer stable.

**The ROM Rule (The Linear Bypass)**
The Flash ROM is a single chip. It ignores the Chip Select toggle and just wants to see a linear address bus. But
because `A11` was stolen for the RAM, the ROM's `A11` pin is physically wired to `atl_data[0]`.

* **If Z80 hits ROM:** The Z80 provides `A[15:0]`. The CPLD must shift the upper bits down to fill the missing `A11`
  gap. `atl_data` becomes `{3'b000, z80_addr[15:11]}`.
* **If DMA hits ROM:** The DMA provides `A[19:0]`. The CPLD must shift the physical address down by exactly one bit.
  `atl_data` becomes `dma_phys_addr[18:11]`.

### The Execution

By wrapping the `bank_select` assignment and the `atl_data_out` multiplexer inside an `` `ifdef HW_REV_A11_BUG `` block
in the top-level CPLD core, the CPLD acts as a translation layer. It takes the clean, logical intents of the DMA and
Z80, and violently shifts and twists them at the very last nanosecond to match the physical copper on your Rev A boards.

Does this align with your understanding of the physical traces? If you are good with this architecture, we can write the
macro logic!

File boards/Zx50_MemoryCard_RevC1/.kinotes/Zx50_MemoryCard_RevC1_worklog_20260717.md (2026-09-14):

# Work Log — Zx50_MemoryCard_RevC1
**Total: 0h 0m**

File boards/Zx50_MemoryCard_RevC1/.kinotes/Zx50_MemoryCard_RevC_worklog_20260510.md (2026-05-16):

# Work Log — Zx50_MemoryCard_RevC
**Total: 0h 0m**

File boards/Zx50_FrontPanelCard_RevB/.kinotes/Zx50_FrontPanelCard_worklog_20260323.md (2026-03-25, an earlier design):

# Work Log — Zx50_FrontPanelCard
**Total: 0h 0m**

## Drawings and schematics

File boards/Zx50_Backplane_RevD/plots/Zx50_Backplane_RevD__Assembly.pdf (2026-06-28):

CN6 *

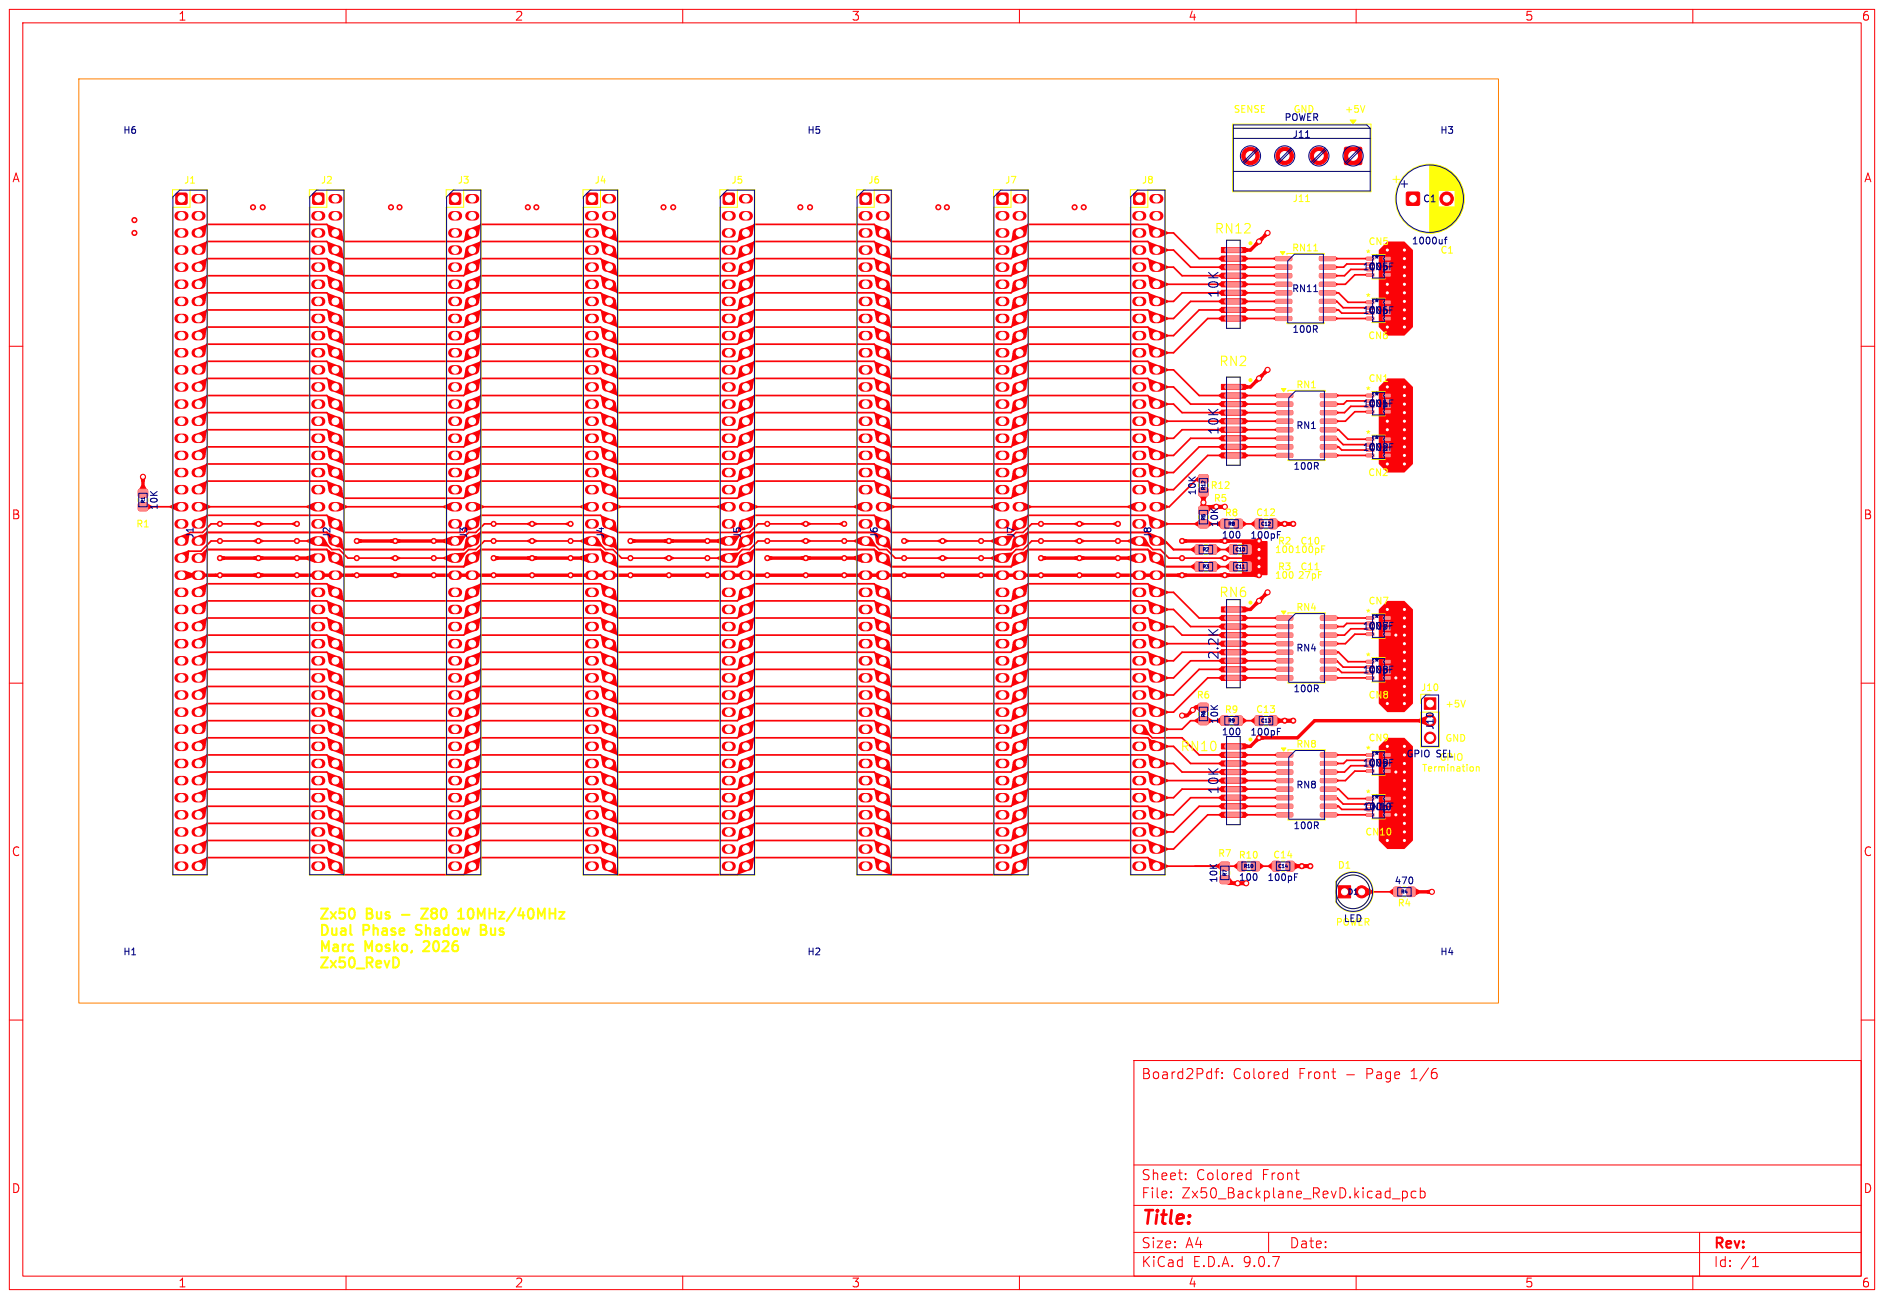
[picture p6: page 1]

Dual Phase Shadow Bus
Marc Mosko, 2026
Zx50_RevD

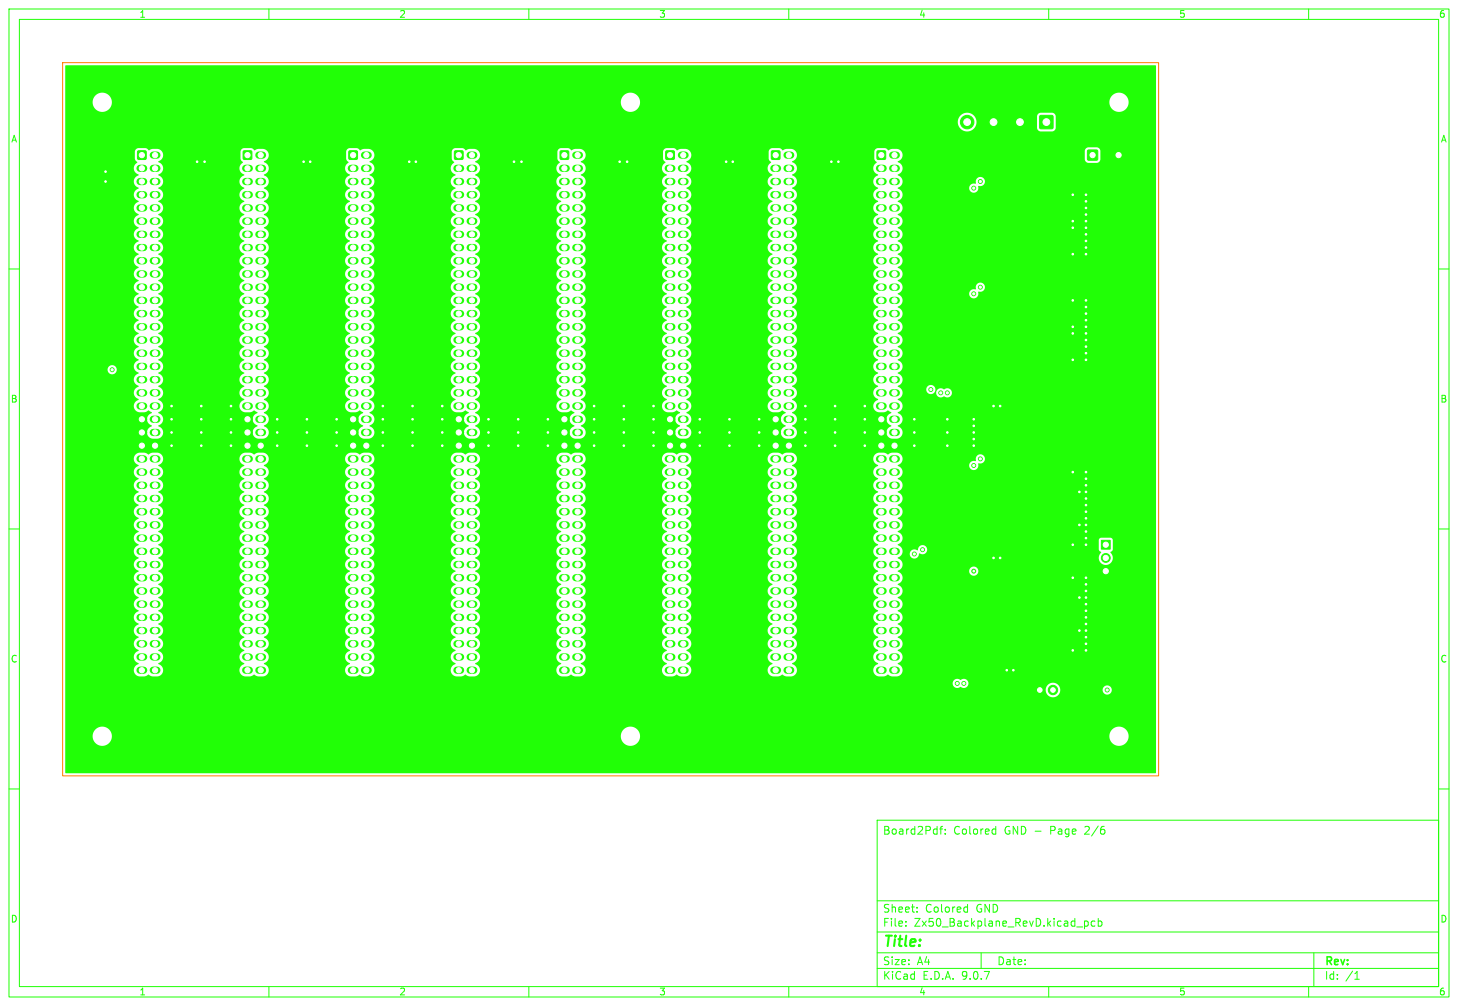
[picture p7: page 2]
Title:; File: Zx50_Backplane_RevD.kicad_pcb; Sheet: Colored; GND; Board2Pdf:; Colored; GND -; Page 2/6

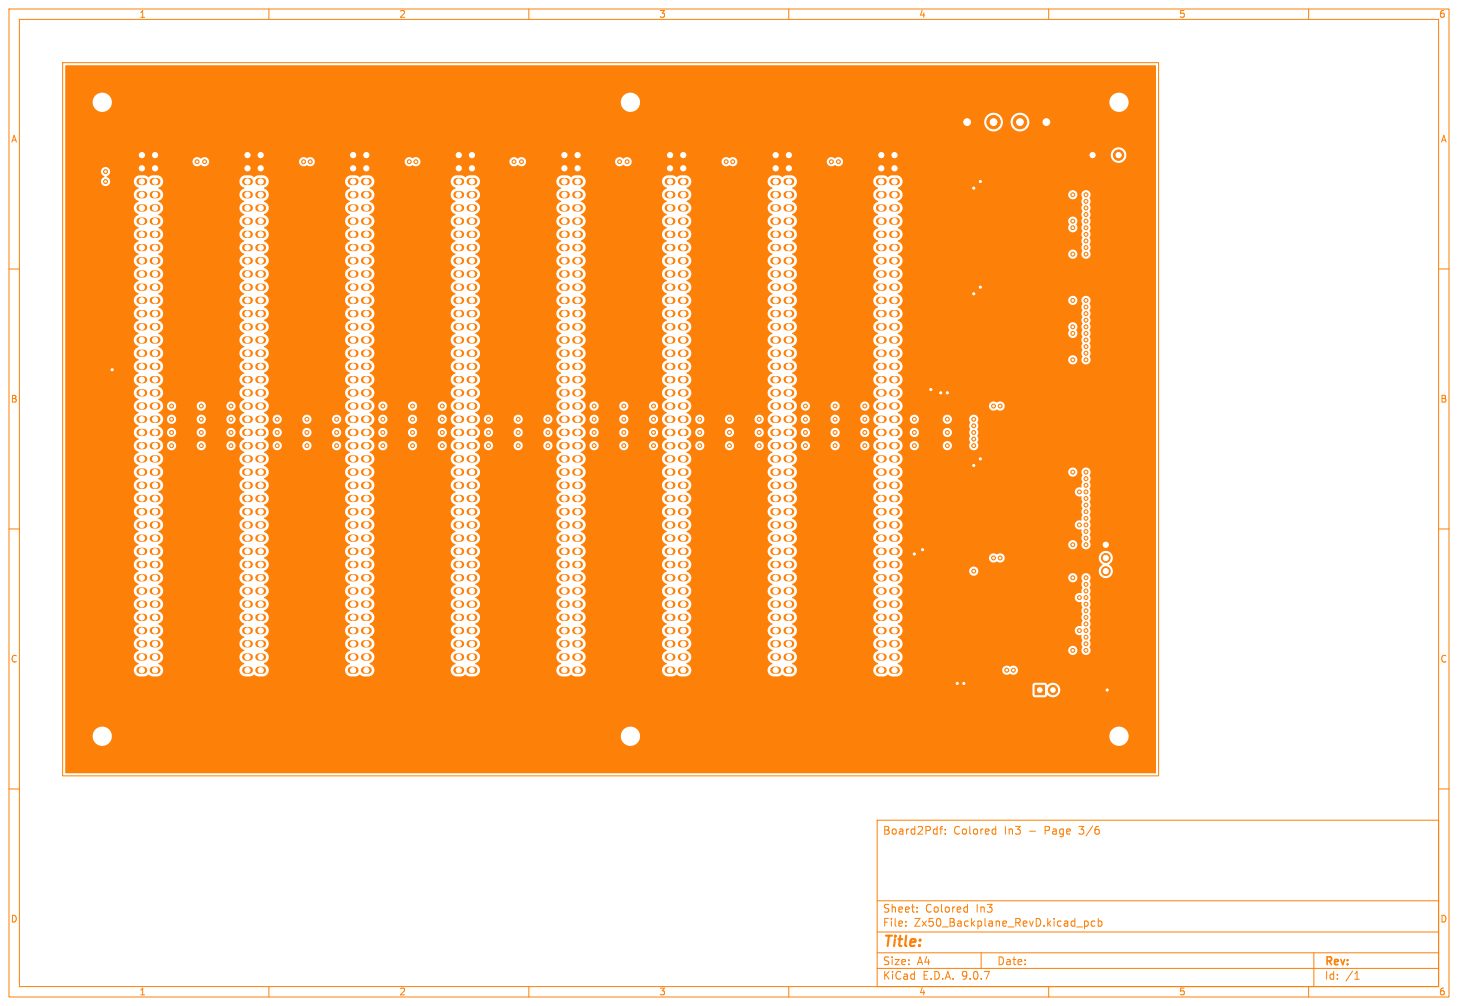
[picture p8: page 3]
Title:; File: Zx50_Backplane_RevD.kicad_pcb; Sheet: Colored; Board2Pdf:; Colored; Page 3/6

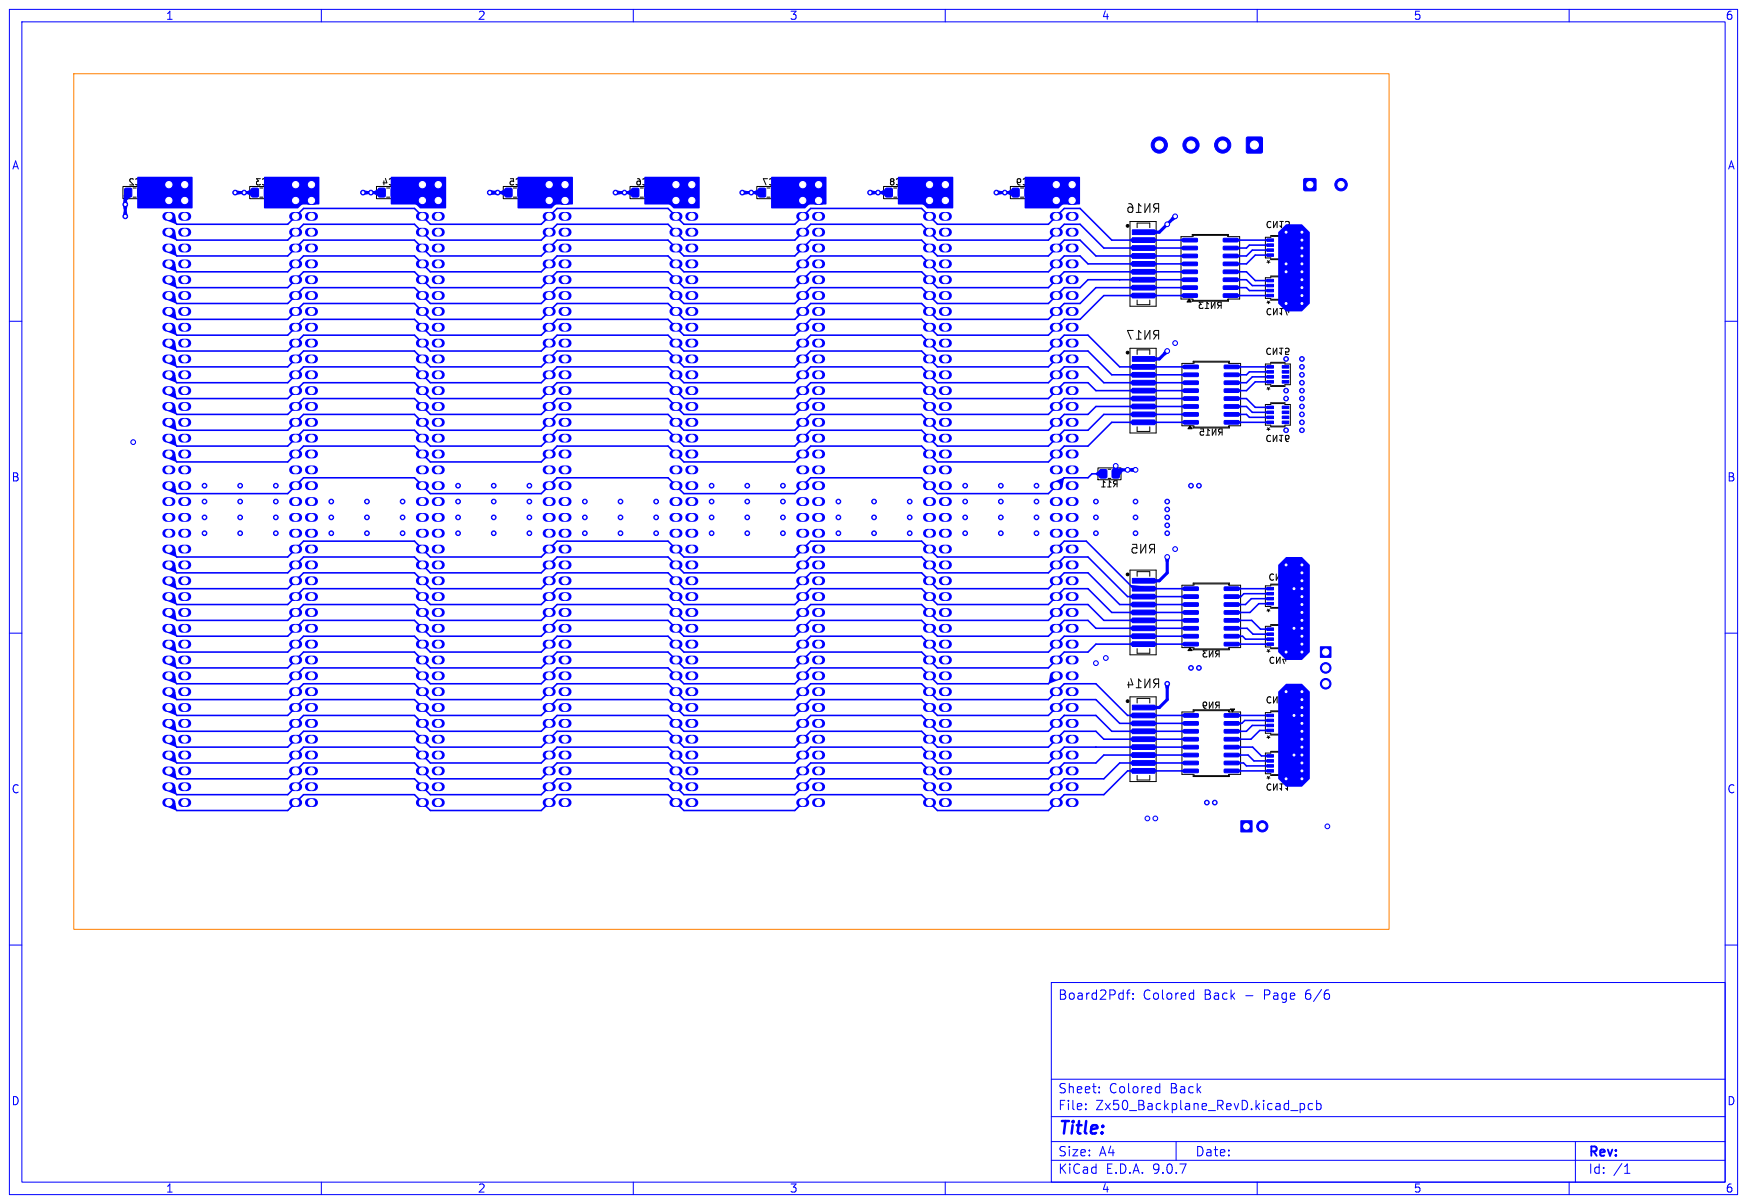
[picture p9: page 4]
Title:; File: Zx50_Backplane_RevD.kicad_pcb; Sheet: Colored; Back; Board2Pdf:; Colored; Back -; Page 6/6

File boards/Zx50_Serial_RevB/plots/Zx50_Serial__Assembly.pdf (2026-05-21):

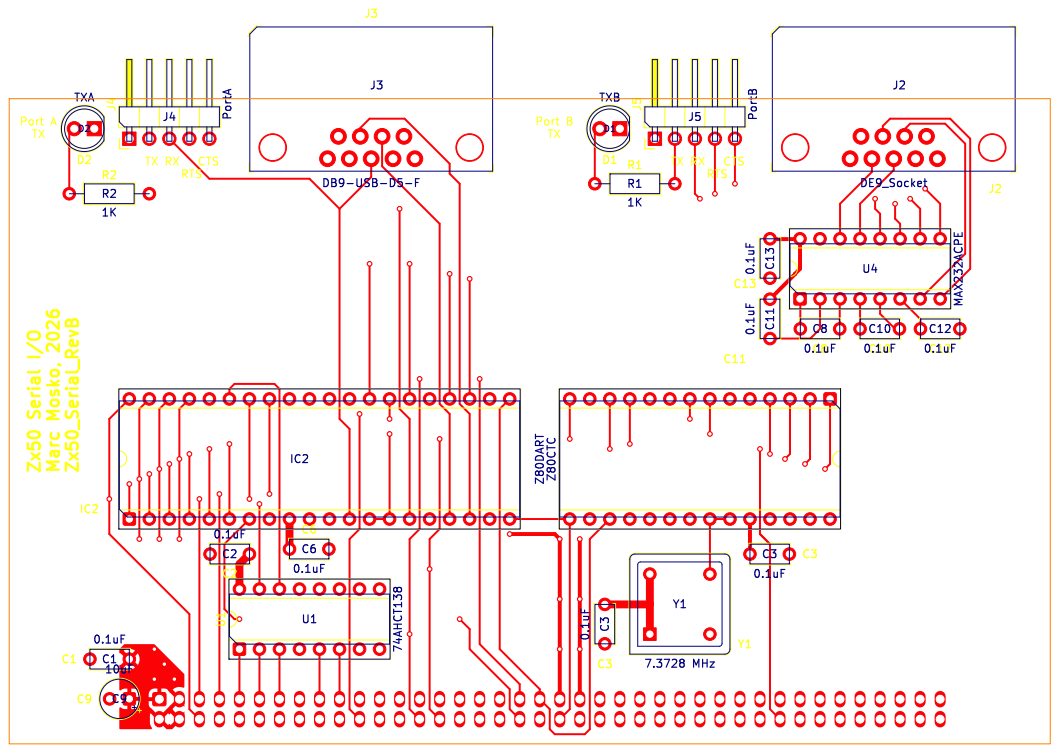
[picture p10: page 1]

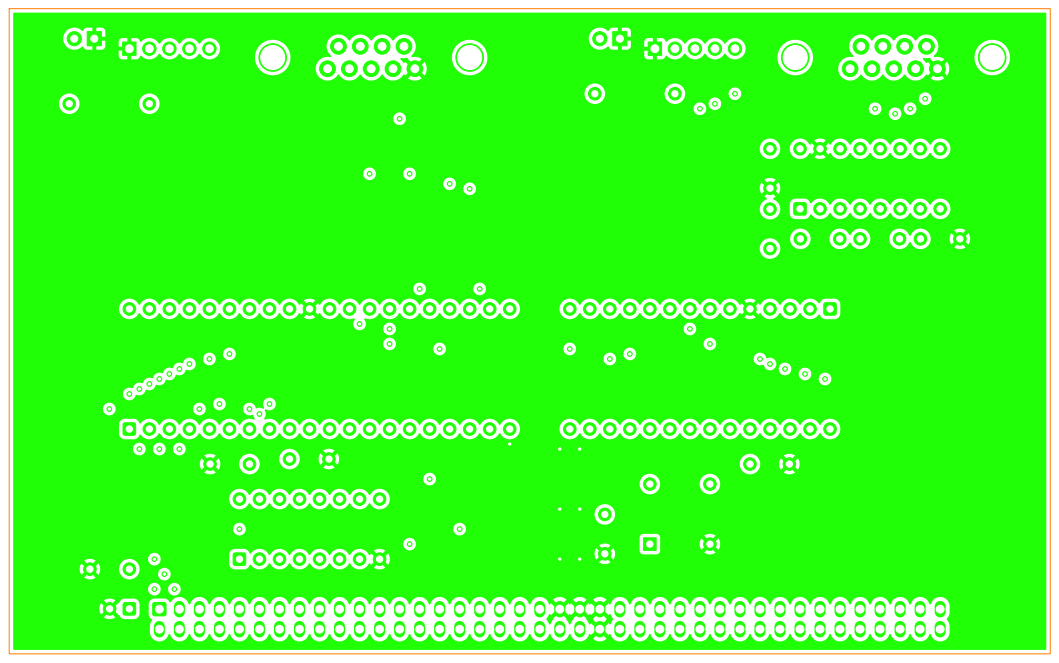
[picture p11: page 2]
Title:; File: Zx50_Serial.kicad_pcb; Sheet: Colored; GND; Board2Pdf:; Colored; GND -; Page 2/6

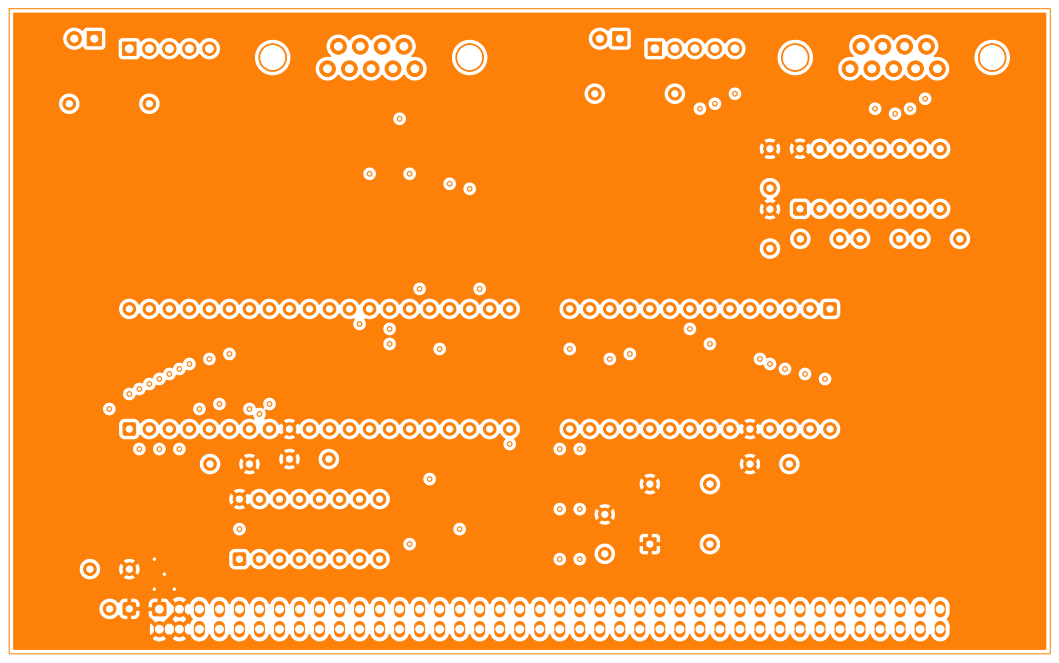
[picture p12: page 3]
Title:; File: Zx50_Serial.kicad_pcb; Sheet: Colored; Board2Pdf:; Colored; Page 3/6

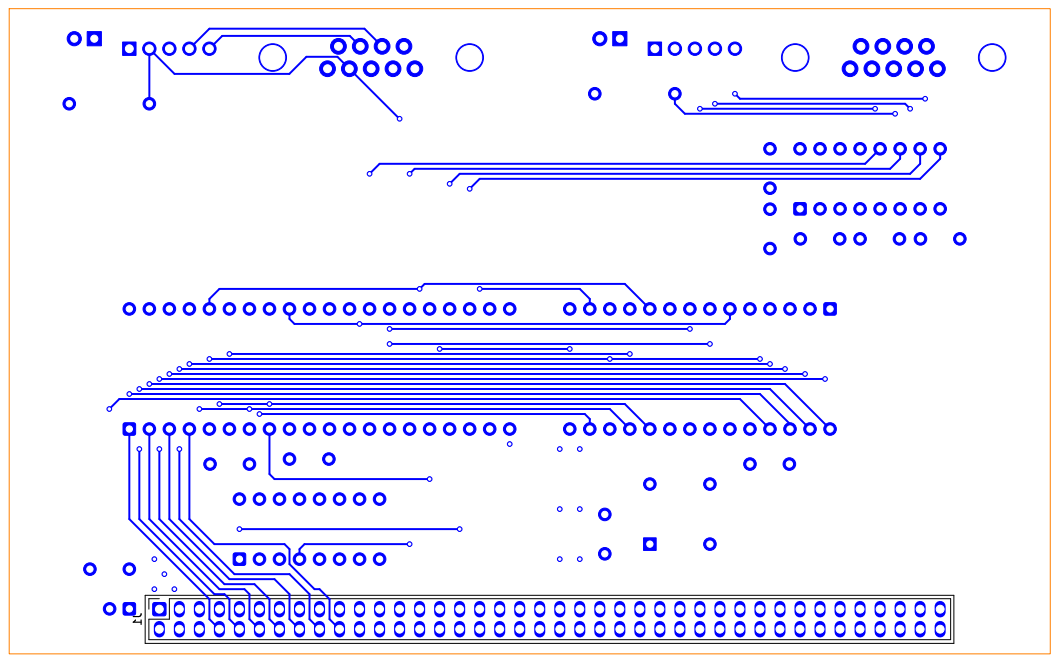
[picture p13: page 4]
Title:; File: Zx50_Serial.kicad_pcb; Sheet: Colored; Back; Board2Pdf:; Colored; Back -; Page 6/6

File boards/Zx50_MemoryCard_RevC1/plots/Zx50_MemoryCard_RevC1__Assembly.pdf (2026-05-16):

1 | 2 | 3 | 4 | 5 | 6 1 | 2 | 3 | 4 | 5 | 6 ABCD | ABCD Date: KiCad | E.D.A. 9.0.7 Size: A4 | Rev:

C27 330

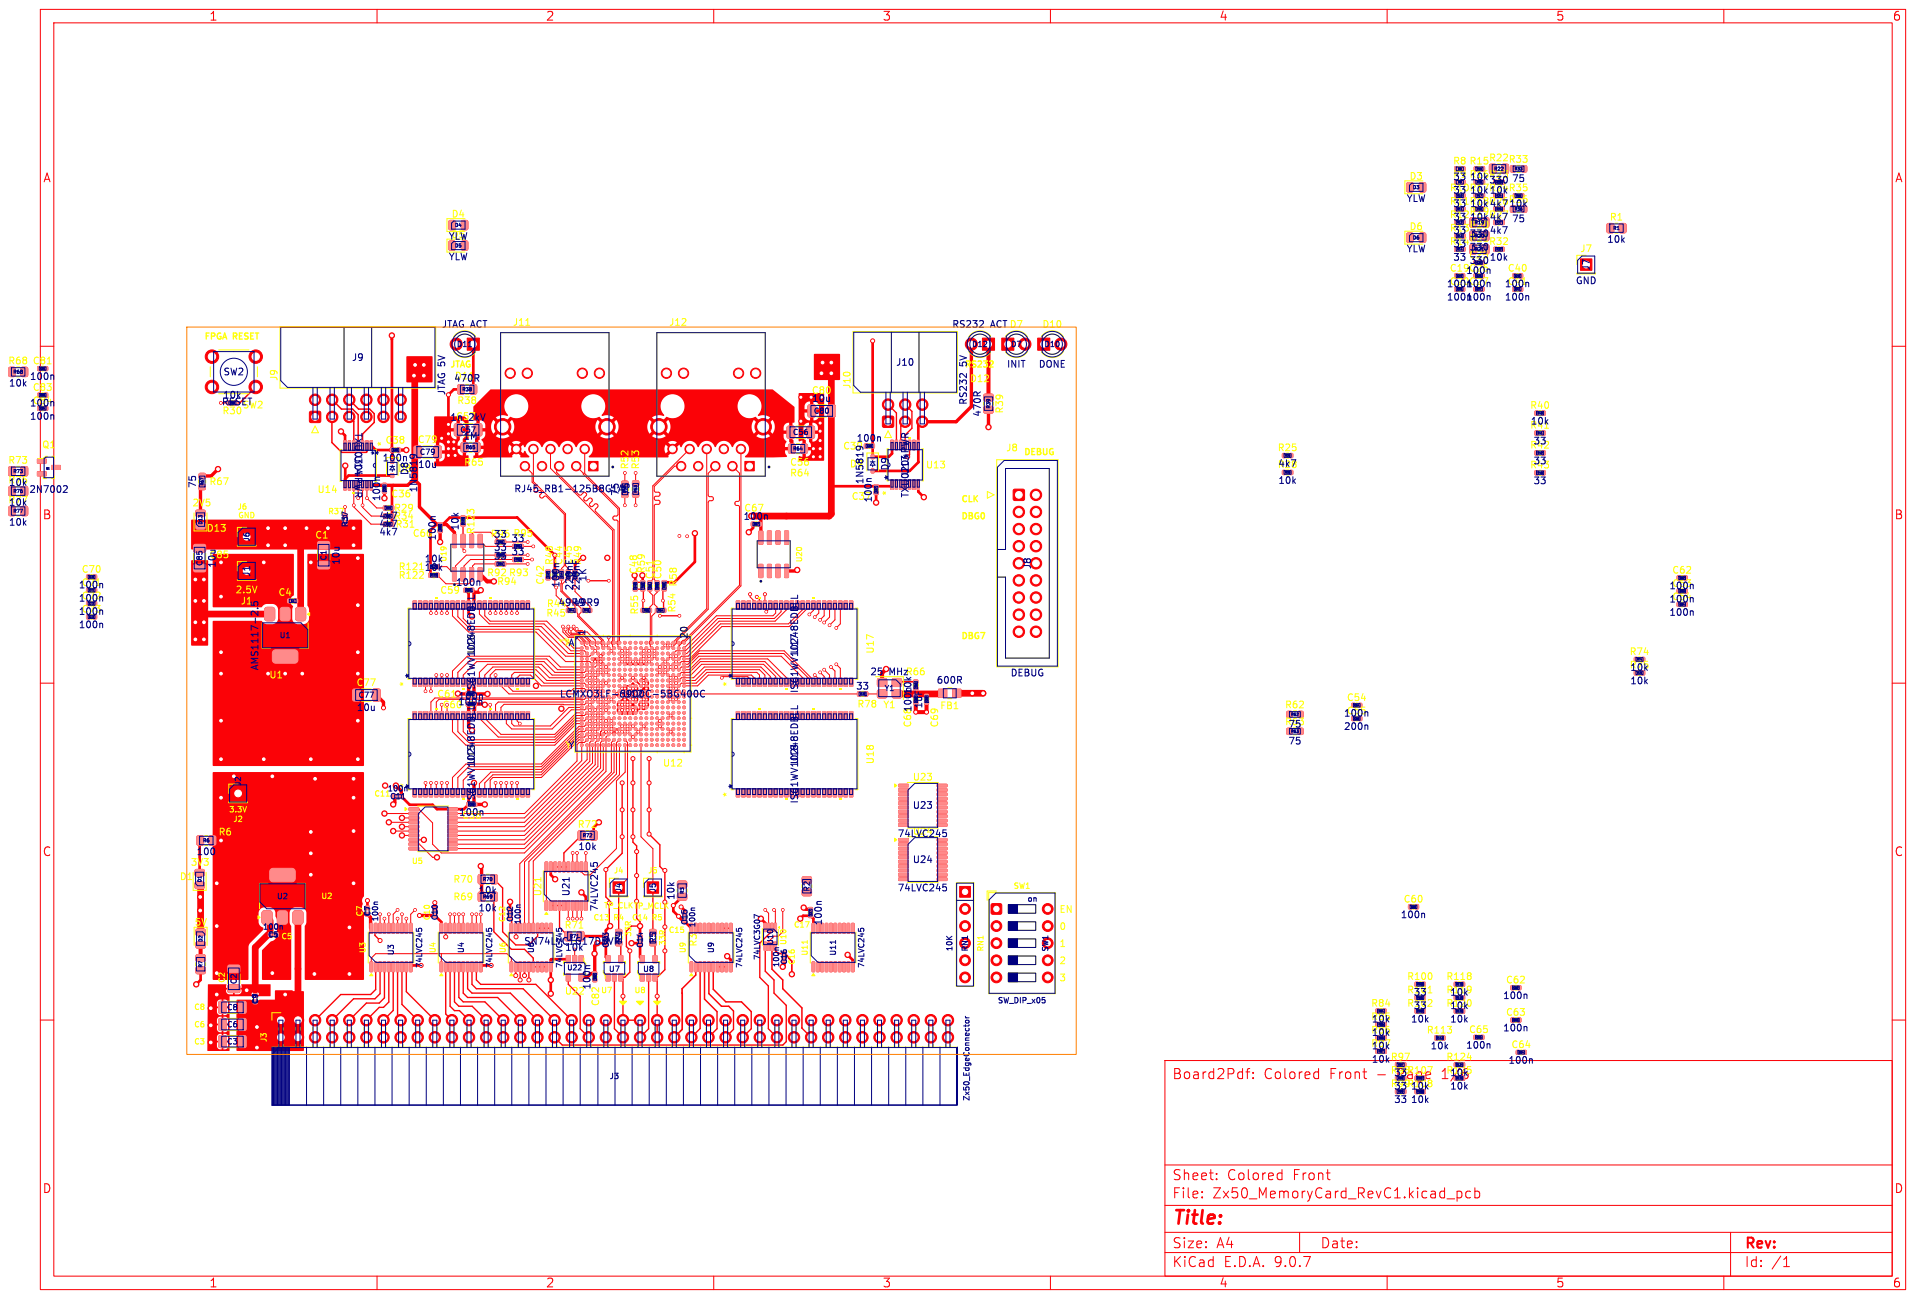
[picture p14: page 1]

1 | 2 | 3 | 4 | 5 | 6

A

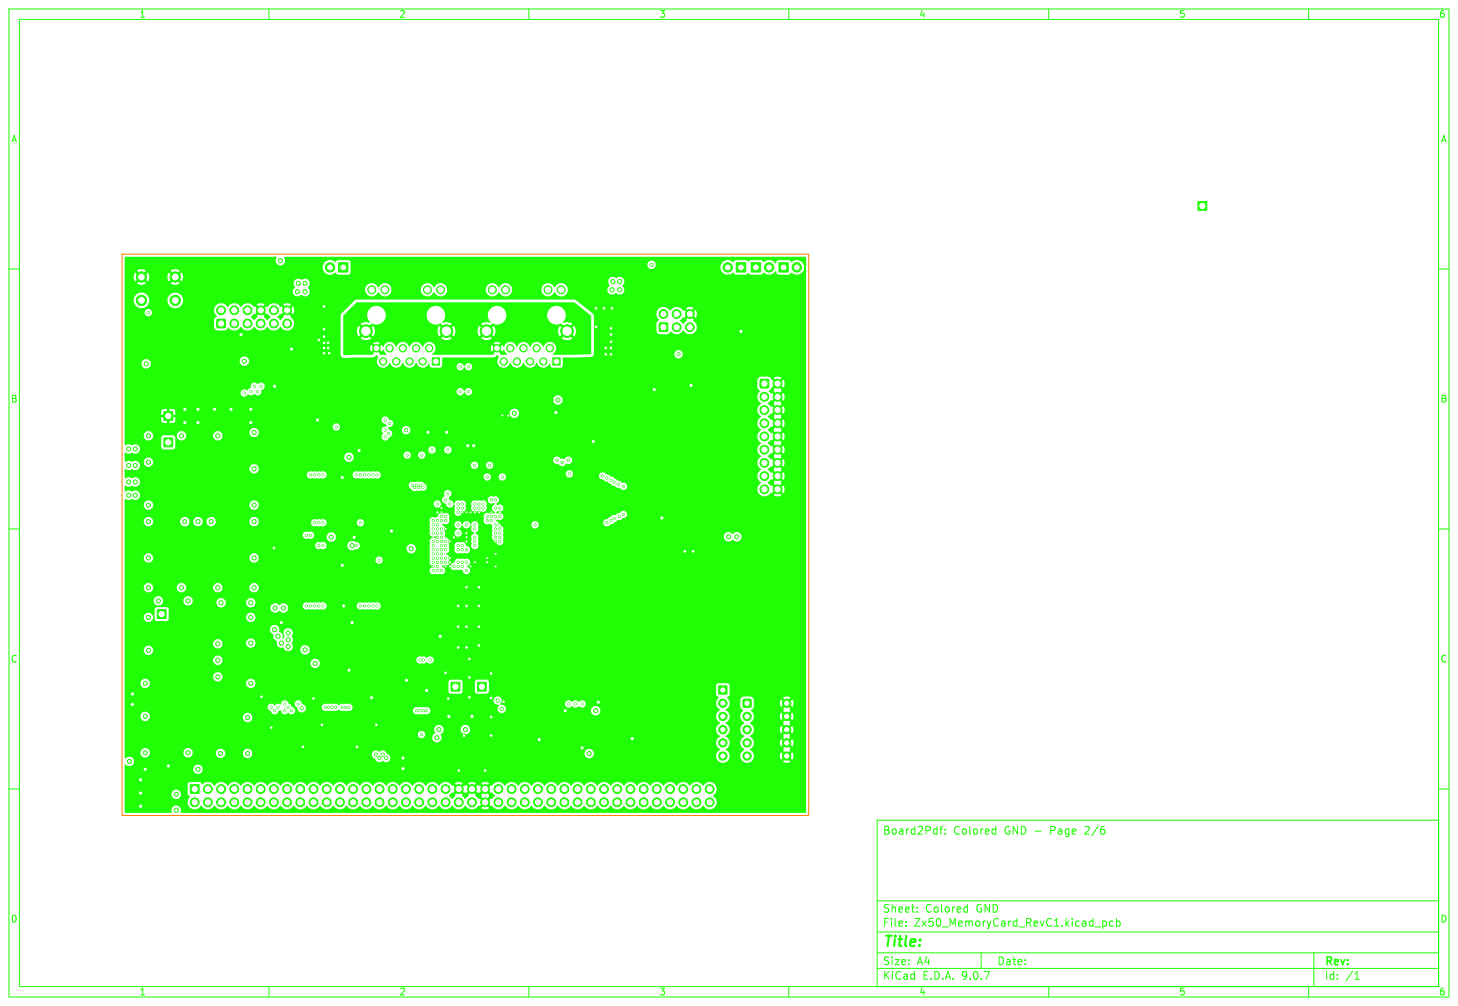
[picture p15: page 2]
D Date: KiCad; E.D.A. 9.0.7 Size: A4; Rev:; Id: /1 Title: File: Zx50_MemoryCard_RevC1.kicad_pcb Sheet: Colored; GND; Board2Pdf:; Colored; GND -; Page 2/6

A

A

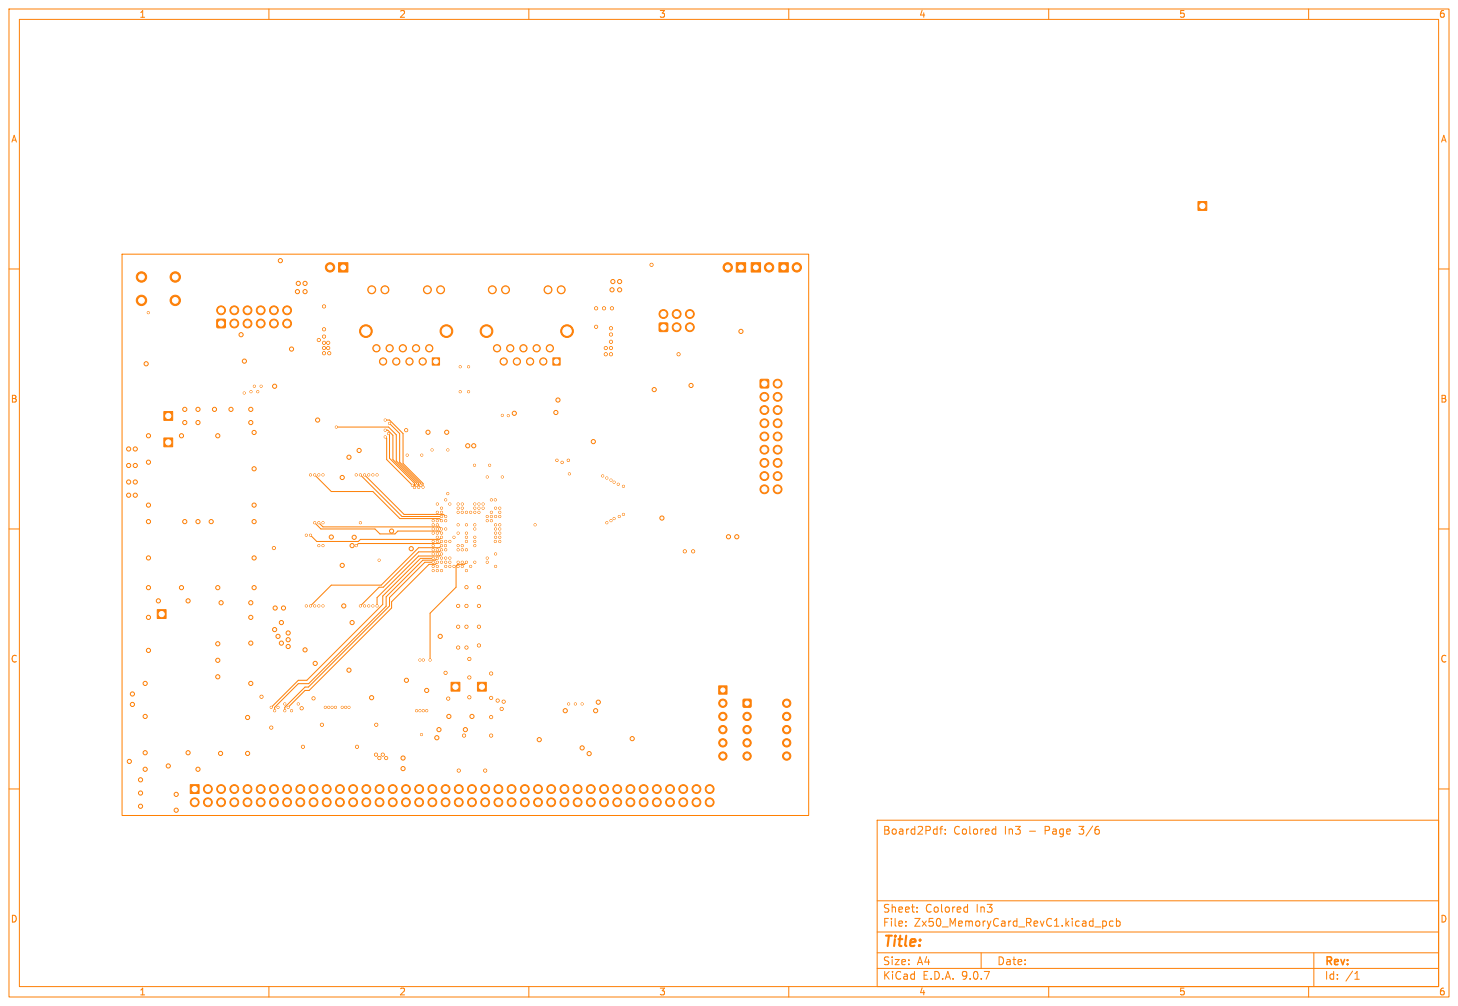
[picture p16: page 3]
D Date: KiCad; E.D.A. 9.0.7 Size: A4; Rev:; Id: /1 Title: File: Zx50_MemoryCard_RevC1.kicad_pcb Sheet: Colored; In3 Board2Pdf:; Colored; Page 3/6

A

A

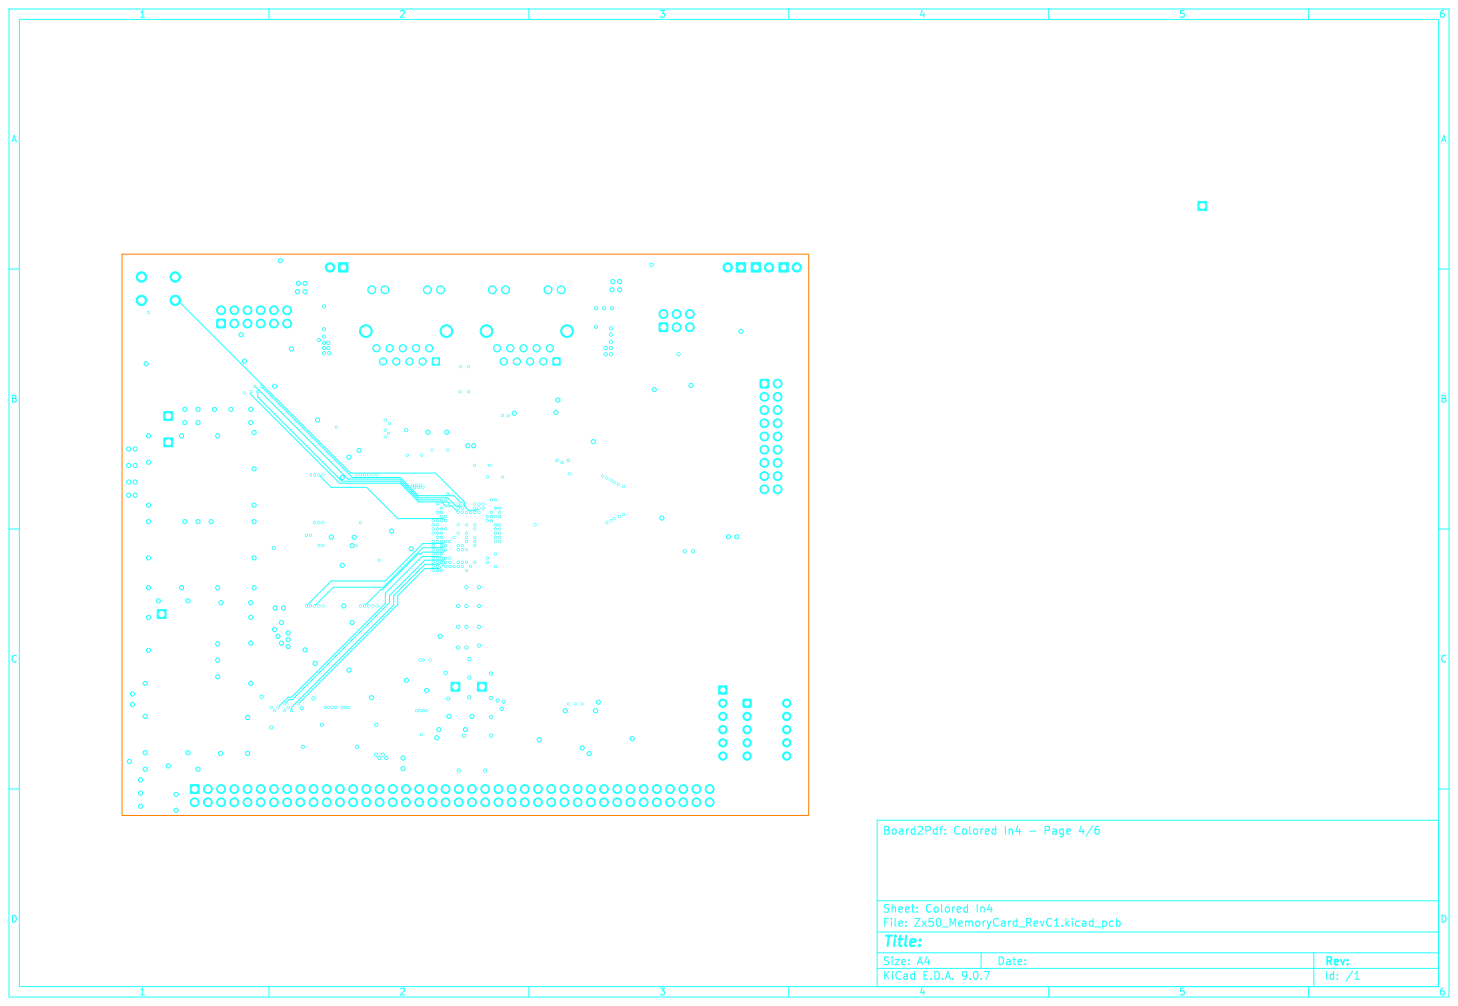
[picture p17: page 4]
D Date: KiCad; E.D.A. 9.0.7 Size: A4; Rev:; Id: /1 Title: File: Zx50_MemoryCard_RevC1.kicad_pcb Sheet: Colored; In4 Board2Pdf:; Colored; Page 4/6

A

A

D Date: KiCad; E.D.A. 9.0.7 Size: A4; Rev:; Id: /1 Title: File: Zx50_MemoryCard_RevC1.kicad_pcb Sheet: Colored; Vdd Board2Pdf:; Colored; Vdd; Page 5/6

A

A


5V GND TDO GND GND 5V RTS TMS GND TCLK TXD CTS RXD PGRM_N TDI A





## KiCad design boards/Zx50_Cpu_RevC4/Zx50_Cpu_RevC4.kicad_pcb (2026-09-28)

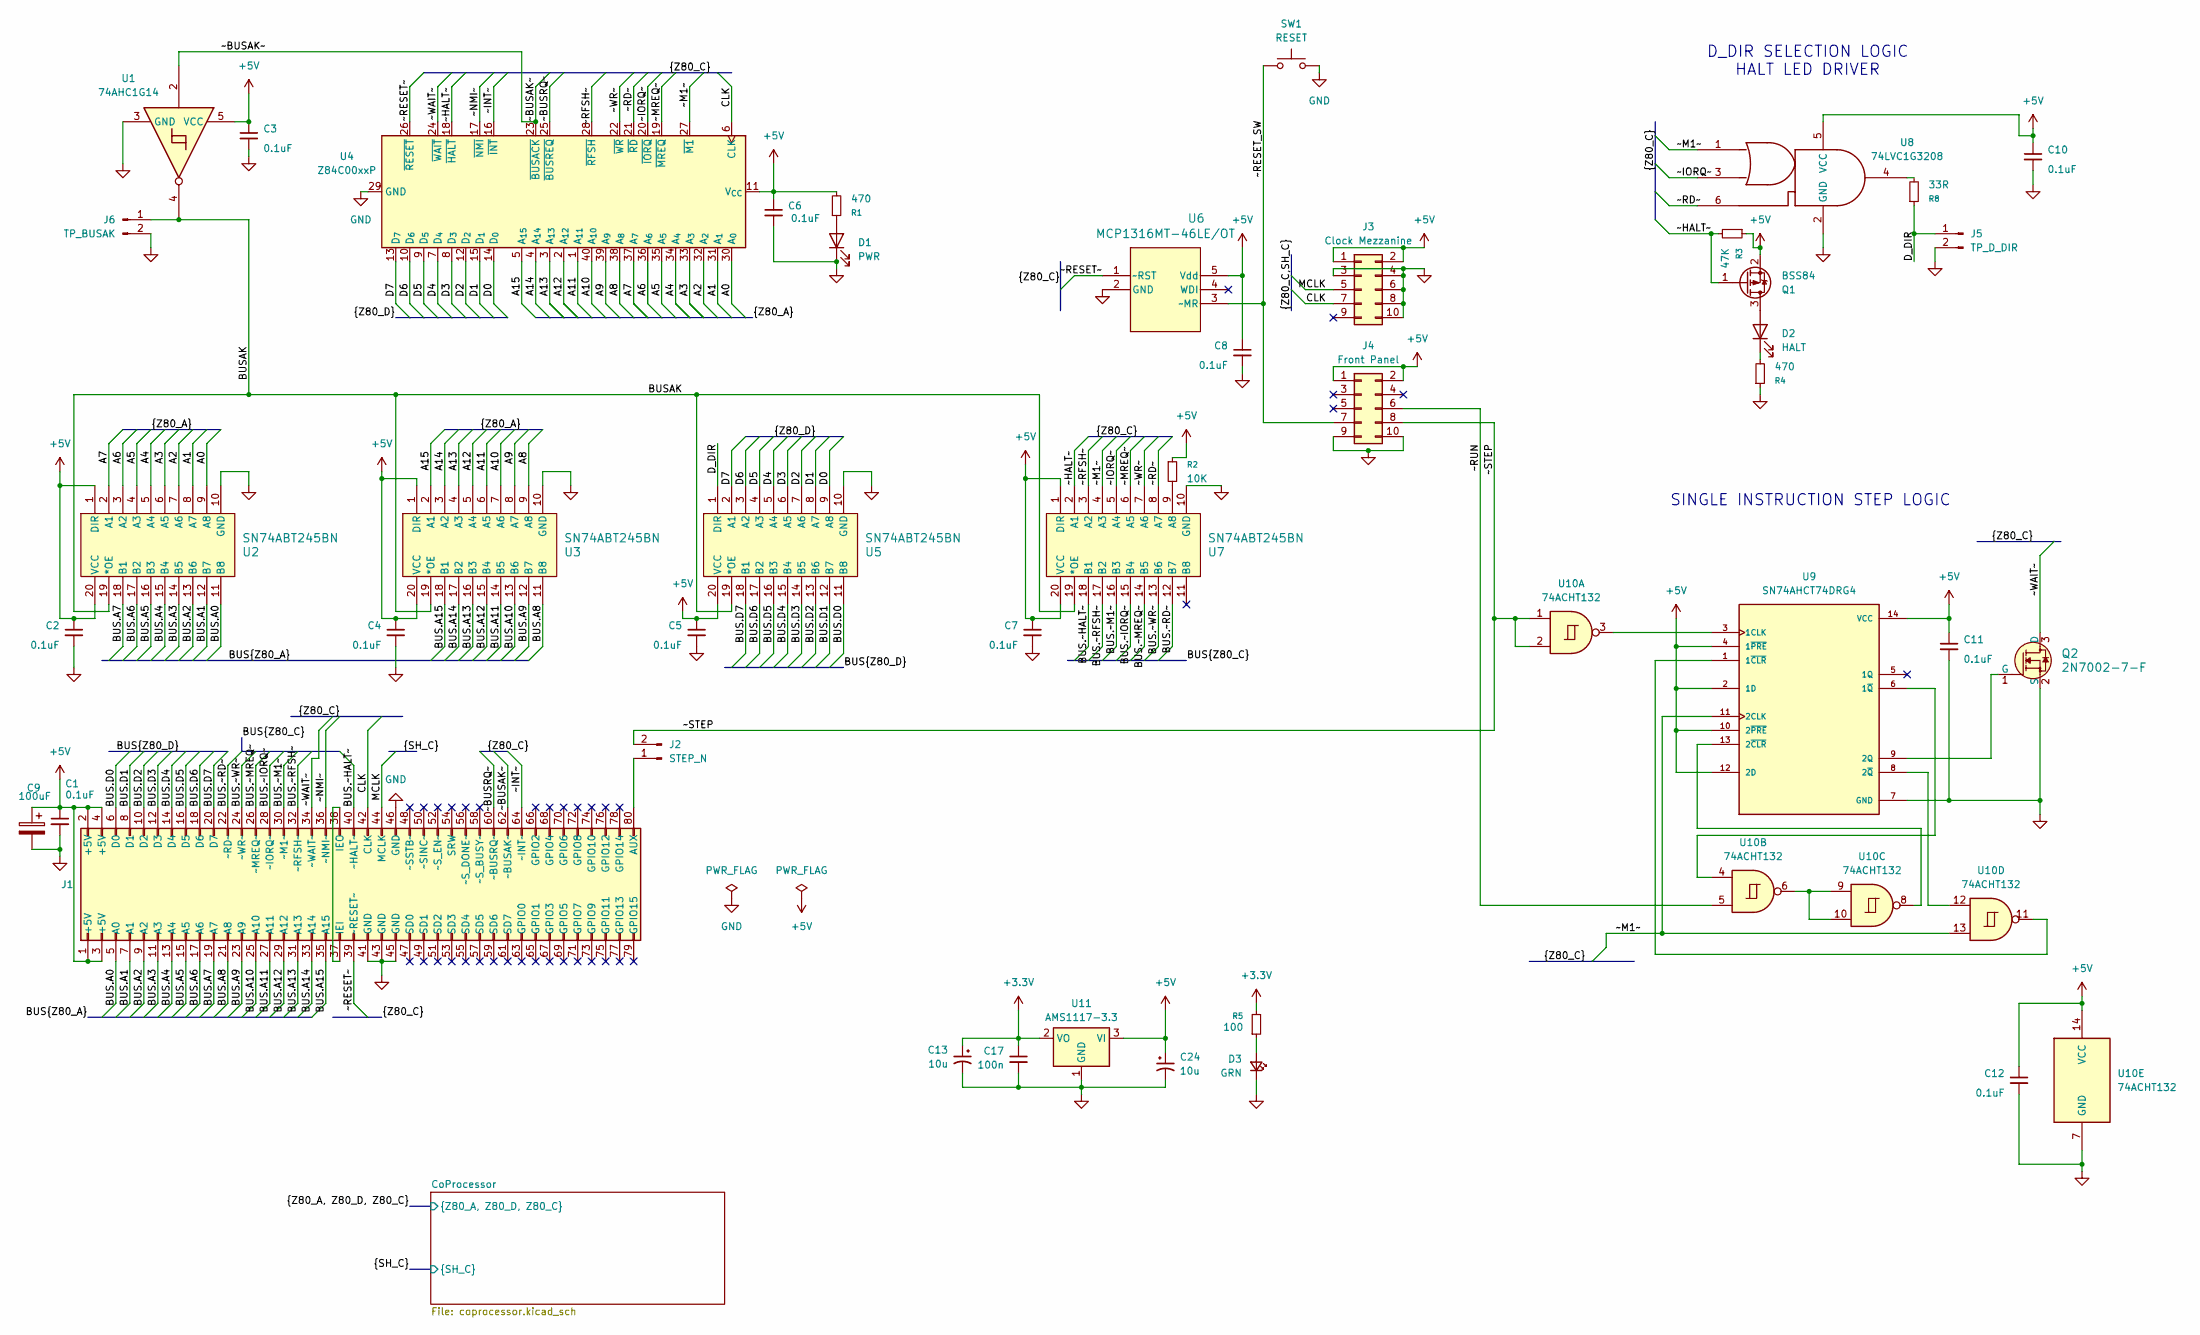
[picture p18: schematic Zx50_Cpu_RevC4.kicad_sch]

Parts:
C1, C2, C3, C4, C5, C6, C7, C8, C10, C11, C12: 0.1uF; C_0805_2012Metric_Pad1.18x1.45mm_HandSolder; Mouser_PN 603-CC805KRX7R9BB104; DigiKey_PN 311-1140-1-ND
C9: 100uF; C_Radial_D8.0mm_H7.0mm_P3.50mm
C13: 10u; CP_EIA-3216-10_Kemet-I_HandSolder; MFG PN AVX TAJA106K016RNJ Tantalinium; LCSC C7171
C17: 100n; C_0805_2012Metric_Pad1.18x1.45mm_HandSolder; LCSC C1525
C24: 10u; C_1206_3216Metric; MFG PN AVX Tantalinium; LCSC C7171
D1: PWR; LED_D5.0mm
D2: HALT; LED_D5.0mm
D3: GRN; LED_0805_2012Metric; MFG_PN KT-0805G; LCSC C2297
J1: Zx50_EdgeConnector; PinSocket_2x40_P2.54mm_Vertical_Oval; DigiKey_PN A34273-40-ND
J2: STEP_N; PinHeader_1x02_P2.54mm_Vertical
J3: Clock Mezzanine; PinSocket_2x05_P2.54mm_Horizontal; DigiKey_PN S5558-ND
J4: Front Panel; IDC-Header_2x05_P2.54mm_Horizontal_Edge; DigiKey_PN 732-2098-ND
J5: TP_D_DIR; PinHeader_1x02_P2.54mm_Vertical
J6: TP_BUSAK; PinHeader_1x02_P2.54mm_Vertical
Q1: BSS84; SOT-23
Q2: 2N7002-7-F; SOT-23-3; MPN 2N7002-7-F; Digi-Key_PN 2N7002-FDICT-ND
R1, R4: 470; R_0805_2012Metric_Pad1.20x1.40mm_HandSolder; Mouser_PN 603-RC0805FR-07470RP; DigiKey_PN 311-33.0CRCT-ND
R2: 10K; R_0805_2012Metric_Pad1.20x1.40mm_HandSolder; Mouser_PN 603-RC0805FR-0710KL; DigiKey_PN =
R3: 47K; R_0805_2012Metric_Pad1.20x1.40mm_HandSolder; Mouser_PN 603-RC0805FR-0747KL
R5: 100; R_0805_2012Metric; MFG_PN 0805W8F1000T5E; LCSC C17408
R8: 33R; R_0805_2012Metric_Pad1.20x1.40mm_HandSolder; Mouser_PN 603-RC0805FR-0733RL; DigiKey_PN 311-33.0CRCT-ND
SW1: RESET; SW_PUSH_6mm_H7.3mm; DigiKey_PN SW402-ND
U1: 74AHC1G14; SOT-23-5_HandSoldering; DigiKey_PN 296-1088-1-ND
U2, U3, U5, U7: SN74ABT245BN; SOIC-20W_7.5x12.8mm_P1.27mm
U4: Z84C00xxP; DIP-40_W15.24mm
U6: MCP1316MT-46LE/OT; SOT-23-5_HandSoldering; Digikey_PN MCP1316MT-46LE/OTCT-ND
U8: 74LVC1G3208; SOT-23-6_Handsoldering
U9: SN74AHCT74DRG4; SOIC-14_3.9x8.7mm_P1.27mm; PARTREV O
U10: 74ACHT132; SOIC-14_3.9x8.7mm_P1.27mm
U11: AMS1117-3.3; SOT-223-3_TabPin2; Mouser_PN 926-LM1117MPX3.3NOPB

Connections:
+3.3V: C13.1, C17.1, R5.2, U11.2 (VO); also elsewhere on the board
+5V: C1.1, C2.1, C3.1, C4.1, C5.1, C6.1, C7.1, C8.1, C9.1, C10.1, C11.1, C12.1, C24.1, J1.1 (+5V), J1.2 (+5V), J1.3 (+5V), J1.4 (+5V), J3.1, J3.2, J4.1, J4.2, Q1.2 (S), R1.2, R2.1, R3.1, U1.5 (VCC), U2.1 (DIR), U2.20 (VCC), U3.1 (DIR), U3.20 (VCC), U4.11 (V_{CC}), U5.20 (VCC), U6.5 (Vdd), U7.1 (DIR), U7.20 (VCC), U8.5 (VCC), U9.2 (1D), U9.4 (1~PRE), U9.10 (2~PRE), U9.12 (2D), U9.14 (VCC), U10.14 (VCC), U11.3 (VI); also elsewhere on the board
/A0: U2.9 (A8), U4.30 (A_{0}); also elsewhere on the board
/A1: U2.8 (A7), U4.31 (A_{1}); also elsewhere on the board
/A2: U2.7 (A6), U4.32 (A_{2}); also elsewhere on the board
/A3: U2.6 (A5), U4.33 (A_{3}); also elsewhere on the board
/A4: U2.5 (A4), U4.34 (A_{4}); also elsewhere on the board
/A5: U2.4 (A3), U4.35 (A_{5}); also elsewhere on the board
/A6: U2.3 (A2), U4.36 (A_{6}); also elsewhere on the board
/A7: U2.2 (A1), U4.37 (A_{7}); also elsewhere on the board
/A8: U3.9 (A8), U4.38 (A_{8}); also elsewhere on the board
/A9: U3.8 (A7), U4.39 (A_{9}); also elsewhere on the board
/A10: U3.7 (A6), U4.40 (A_{10}); also elsewhere on the board
/A11: U3.6 (A5), U4.1 (A_{11}); also elsewhere on the board
/A12: U3.5 (A4), U4.2 (A_{12}); also elsewhere on the board
/A13: U3.4 (A3), U4.3 (A_{13}); also elsewhere on the board
/A14: U3.3 (A2), U4.4 (A_{14}); also elsewhere on the board
/A15: U3.2 (A1), U4.5 (A_{15}); also elsewhere on the board
/BUS.A0: J1.5 (A0), U2.11 (B8)
/BUS.A1: J1.7 (A1), U2.12 (B7)
/BUS.A2: J1.9 (A2), U2.13 (B6)
/BUS.A3: J1.11 (A3), U2.14 (B5)
/BUS.A4: J1.13 (A4), U2.15 (B4)
/BUS.A5: J1.15 (A5), U2.16 (B3)
/BUS.A6: J1.17 (A6), U2.17 (B2)
/BUS.A7: J1.19 (A7), U2.18 (B1)
/BUS.A8: J1.21 (A8), U3.11 (B8)
/BUS.A9: J1.23 (A9), U3.12 (B7)
/BUS.A10: J1.25 (A10), U3.13 (B6)
/BUS.A11: J1.27 (A11), U3.14 (B5)
/BUS.A12: J1.29 (A12), U3.15 (B4)
/BUS.A13: J1.31 (A13), U3.16 (B3)
/BUS.A14: J1.33 (A14), U3.17 (B2)
/BUS.A15: J1.35 (A15), U3.18 (B1)
/BUS.D0: J1.6 (D0), U5.11 (B8)
/BUS.D1: J1.8 (D1), U5.12 (B7)
/BUS.D2: J1.10 (D2), U5.13 (B6)
/BUS.D3: J1.12 (D3), U5.14 (B5)
/BUS.D4: J1.14 (D4), U5.15 (B4)
/BUS.D5: J1.16 (D5), U5.16 (B3)
/BUS.D6: J1.18 (D6), U5.17 (B2)
/BUS.D7: J1.20 (D7), U5.18 (B1)
/BUS.~HALT~: J1.40 (~HALT~), U7.18 (B1)
/BUS.~IORQ~: J1.28 (~IORQ~), U7.15 (B4)
/BUS.~M1~: J1.30 (~M1~), U7.16 (B3)
/BUS.~MREQ~: J1.26 (~MREQ~), U7.14 (B5)
/BUS.~RD~: J1.22 (~RD~), U7.12 (B7)
/BUS.~RFSH~: J1.32 (~RFSH~), U7.17 (B2)
/BUS.~WR~: J1.24 (~WR~), U7.13 (B6)
/BUSAK: J6.1, U1.4, U2.19 (*OE), U3.19 (*OE), U5.19 (*OE), U7.19 (*OE)
/CLK: J1.42 (CLK), J3.7, U4.6 (CLK); also elsewhere on the board
/D0: U4.14 (D_{0}), U5.9 (A8); also elsewhere on the board
/D1: U4.15 (D_{1}), U5.8 (A7); also elsewhere on the board
/D2: U4.12 (D_{2}), U5.7 (A6); also elsewhere on the board
/D3: U4.8 (D_{3}), U5.6 (A5); also elsewhere on the board
/D4: U4.7 (D_{4}), U5.5 (A4); also elsewhere on the board
/D5: U4.9 (D_{5}), U5.4 (A3); also elsewhere on the board
/D6: U4.10 (D_{6}), U5.3 (A2); also elsewhere on the board
/D7: U4.13 (D_{7}), U5.2 (A1); also elsewhere on the board
/D_DIR: J5.1, R8.1, U5.1 (DIR)
/MCLK: J1.44 (MCLK), J3.5; also elsewhere on the board
/~BUSAK~: J1.62 (~BUSAK~), U1.2, U4.23 (~BUSACK)
/~BUSRQ~: J1.60 (~BUSRQ~), U4.25 (~BUSREQ)
/~HALT~: Q1.1 (G), R3.2, U4.18 (~HALT), U7.2 (A1)
/~INT~: J1.64 (~INT~), U4.16 (~INT)
/~IORQ~: U4.20 (~IORQ), U7.5 (A4), U8.3; also elsewhere on the board
/~M1~: U4.27 (~M1), U7.4 (A3), U8.1, U9.11 (2CLK), U10.13; also elsewhere on the board
/~MREQ~: U4.19 (~MREQ), U7.6 (A5); also elsewhere on the board
/~NMI~: J1.36 (~NMI~), U4.17 (~NMI)
/~RD~: U4.21 (~RD), U7.8 (A7), U8.6; also elsewhere on the board
/~RESET_SW: J4.7, SW1.1, U6.3 (~MR)
/~RESET~: J1.39 (~RESET~), U4.26 (~RESET), U6.1 (~RST); also elsewhere on the board
/~RFSH~: U4.28 (~RFSH), U7.3 (A2)
/~RUN: J4.6, U10.5
/~STEP: J2.2, J4.8, U10.1, U10.2
/~WAIT~: J1.34 (~WAIT~), Q2.3 (D), U4.24 (~WAIT); also elsewhere on the board
/~WR~: U4.22 (~WR), U7.7 (A6); also elsewhere on the board
GND: C1.2, C2.2, C3.2, C4.2, C5.2, C6.2, C7.2, C8.2, C9.2, C10.2, C11.2, C12.2, C13.2, C17.2, C24.2, D1.1 (K), D3.1 (K), J1.41 (GND), J1.43 (GND), J1.45 (GND), J1.46 (GND), J3.3, J3.4, J3.6, J3.8, J3.10, J4.9, J4.10, J5.2, J6.2, Q2.2 (S), R4.1, SW1.2, U1.3 (GND), U2.10 (GND), U3.10 (GND), U4.29 (GND), U5.10 (GND), U6.2 (GND), U7.10 (GND), U8.2 (GND), U9.7 (GND), U10.7 (GND), U11.1 (GND); also elsewhere on the board
unnamed: D1.2 (A), R1.1
unnamed: D2.2 (A), Q1.3 (D)
unnamed: D2.1 (K), R4.2
unnamed: D3.2 (A), R5.1
unnamed: J1.80 (AUX), J2.1
unnamed: J1.37 (IEI), J1.38 (IEO)
unnamed: Q2.1 (G), U9.9 (2Q)
unnamed: R8.2, U8.4
unnamed: R2.2, U7.9 (A8)
unnamed: U9.3 (1CLK), U10.3
unnamed: U9.1 (1~CLR), U10.11
unnamed: U9.6 (1~Q), U10.4
unnamed: U9.13 (2~CLR), U10.8
unnamed: U9.8 (2~Q), U10.12
unnamed: U10.6, U10.9, U10.10

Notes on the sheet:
D_DIR SELECTION LOGIC HALT LED DRIVER
SINGLE INSTRUCTION STEP LOGIC

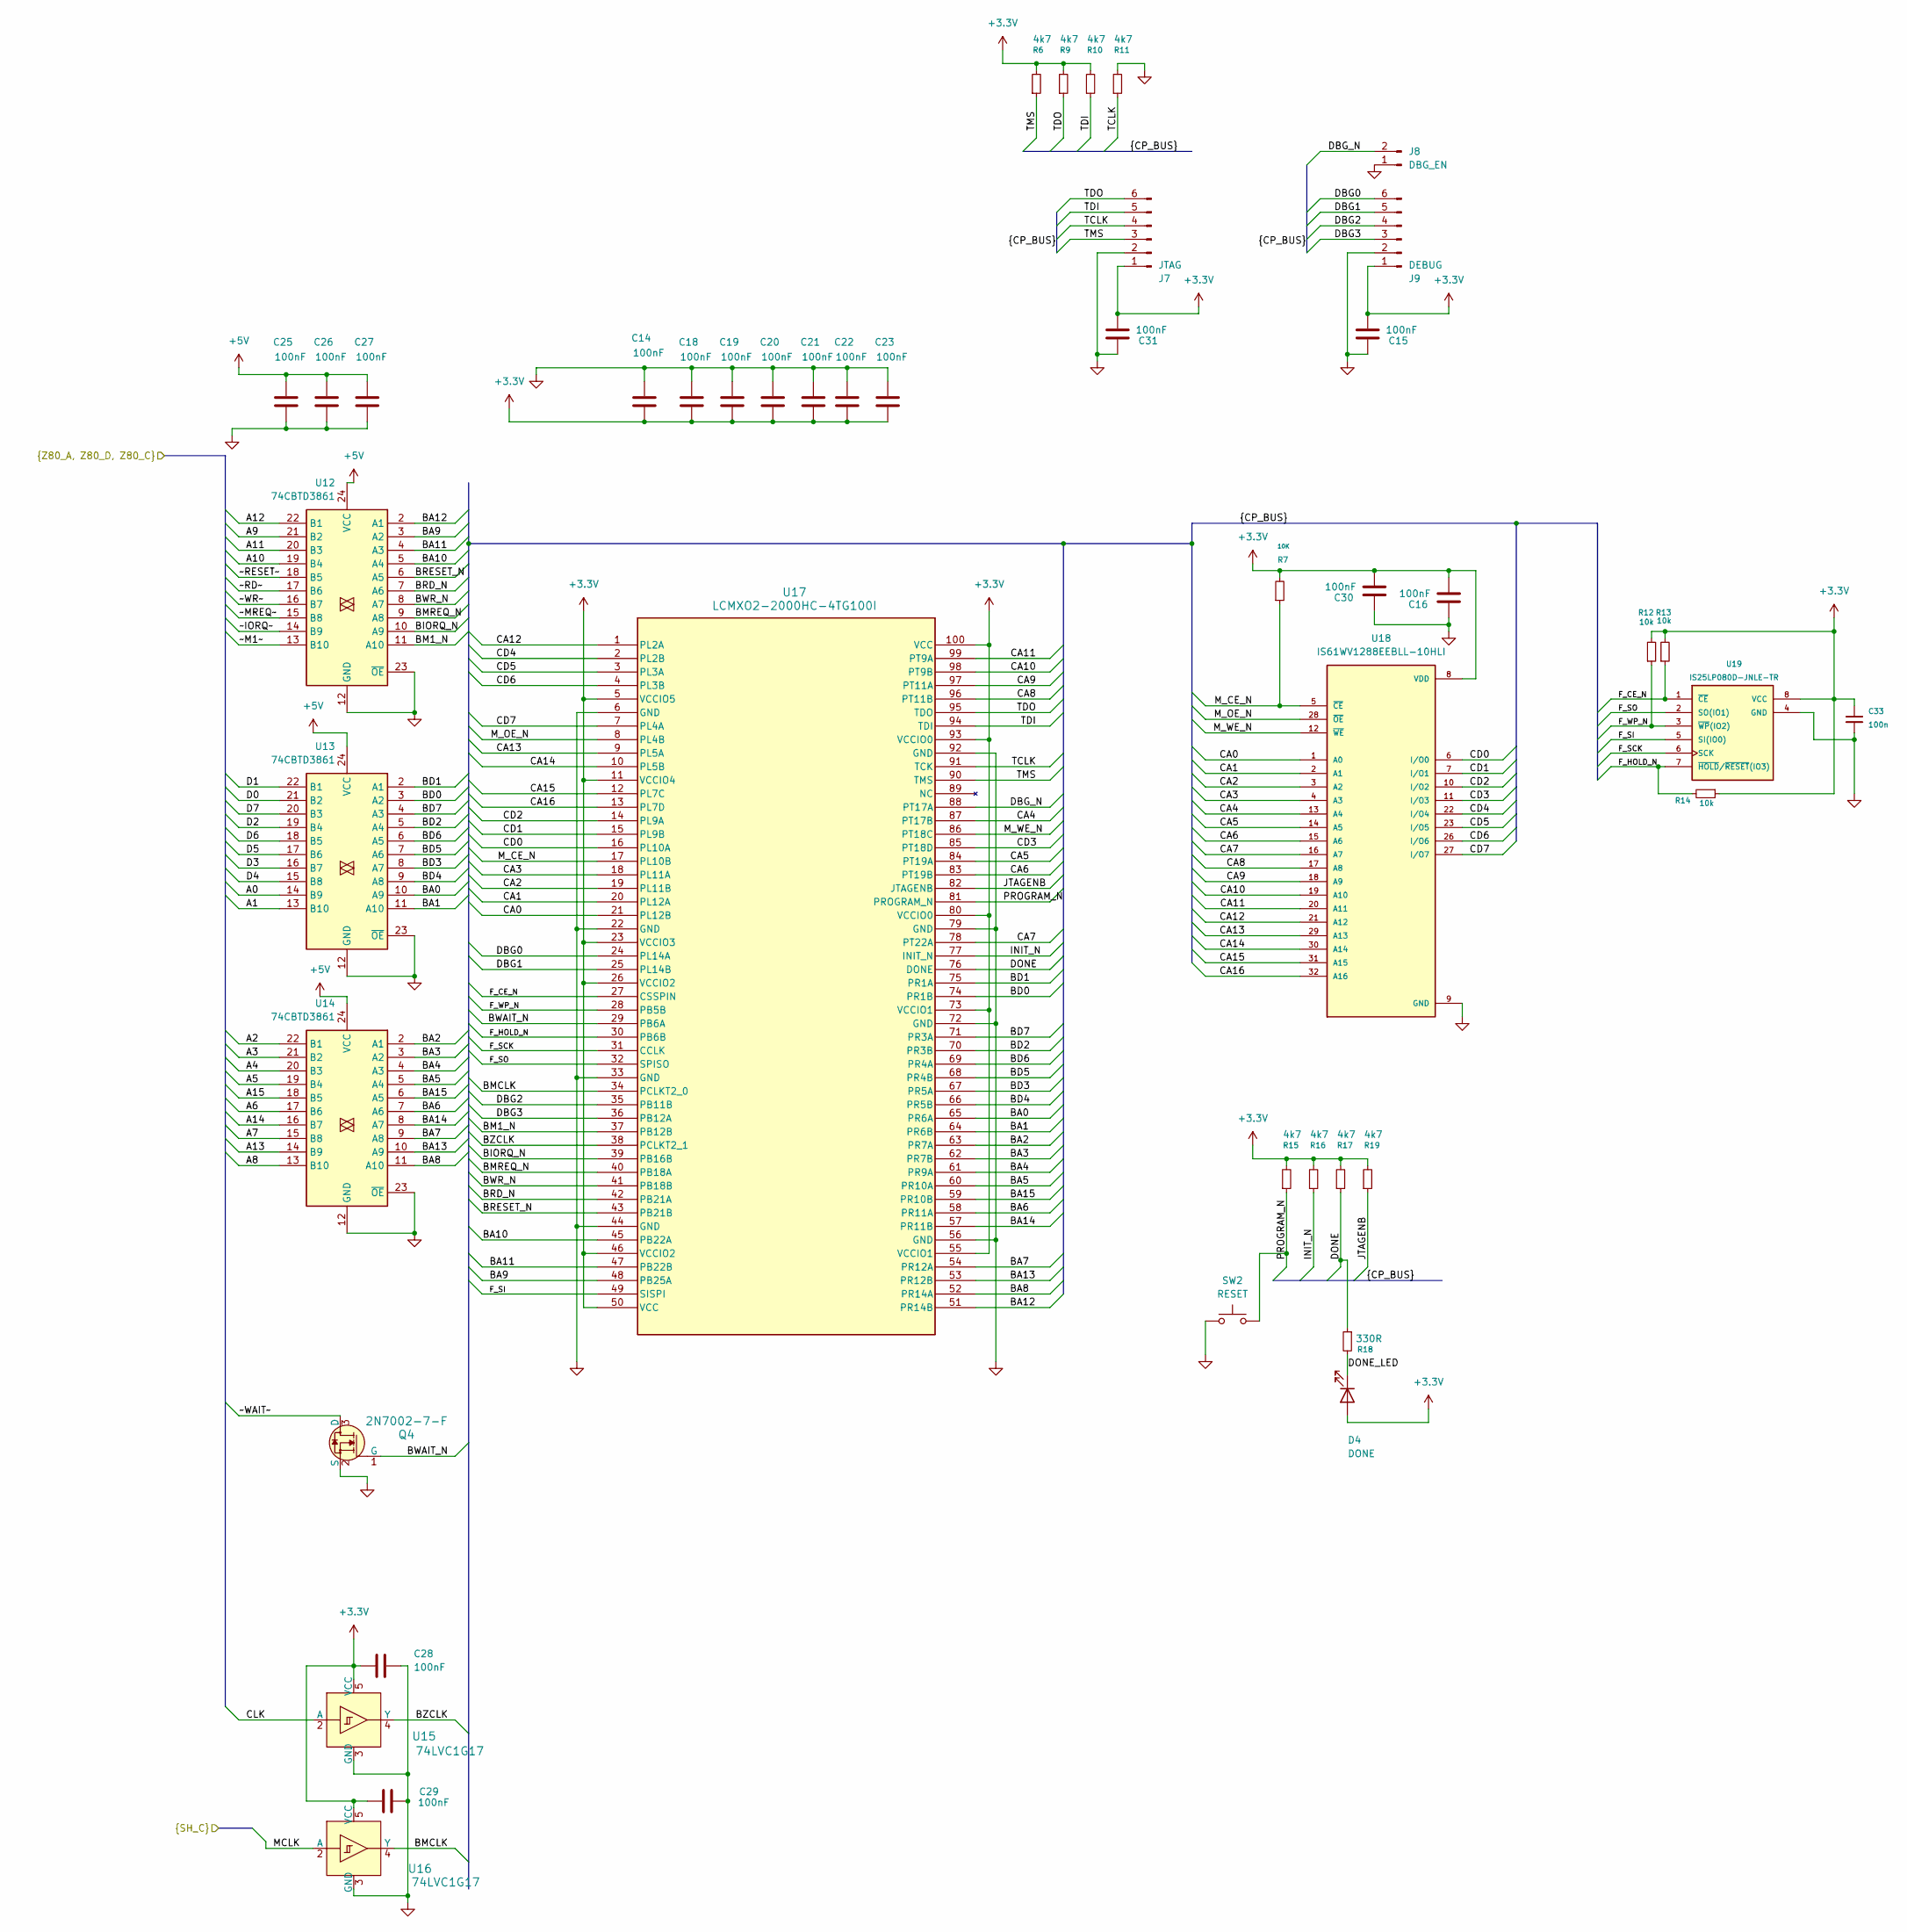
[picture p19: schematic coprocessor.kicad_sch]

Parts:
C14, C15, C16, C18, C19, C20, C21, C22, C23, C25, C26, C27, C28, C29, C30, C31: 100nF; C_0805_2012Metric; LCSC C28233
C33: 100n; C_0805_2012Metric; LCSC C49678
D4: DONE; LED_0805_2012Metric; MFG_PN SM0805GCL; LCSC C2297
J7: JTAG; PinHeader_1x06_P2.54mm_Vertical
J8: DBG_EN; PinHeader_1x02_P2.54mm_Vertical
J9: DEBUG; PinHeader_1x06_P2.54mm_Vertical
Q4: 2N7002-7-F; SOT-23-3; MPN 2N7002-7-F; Digi-Key_PN 2N7002-FDICT-ND
R6, R9, R10, R11, R15, R16, R17, R19: 4k7; R_0805_2012Metric; MFG_PN AA0805FR-134K7L; LCSC C17713
R7: 10K; R_0805_2012Metric_Pad1.20x1.40mm_HandSolder; DigiKey_PN =
R12, R13, R14: 10k; R_0805_2012Metric; LCSC C17414
R18: 330R; R_0805_2012Metric_Pad1.20x1.40mm_HandSolder; MFG_PN AC0805JR-13330RL; LCSC C17630
SW2: RESET; SW_SPST_PTS645Sx43SMTR92
U12, U13, U14: 74CBTD3861; DB24; LCSC C11617
U15, U16: 74LVC1G17; SOT-753; MPN SN74LVC1G17DBVR; Digi-Key_PN 296-11933-1-ND
U17: LCMXO2-2000HC-4TG100I; TQFP100_LAT; LCSC C1521620
U18: IS61WV1288EEBLL-10HLI; SOP50P1400X120-32N; PARTREV Rev. B1; LCSC C1349956
U19: IS25LP080D-JNLE-TR; SOIC127P600X88-8N; DigiKey_PN 706-1581-1-ND

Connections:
+3.3V: C14.2, C15.2, C16.2, C18.2, C19.2, C20.2, C21.2, C22.2, C23.2, C28.2, C29.2, C30.2, C31.2, C33.1, D4.2 (A), J7.1, J9.1, R6.2, R7.2, R9.2, R10.2, R12.2, R13.2, R14.1, R15.2, R16.2, R17.2, R19.2, U15.5 (VCC), U16.5 (VCC), U17.5 (VCCIO5), U17.11 (VCCIO4), U17.23 (VCCIO3), U17.26 (VCCIO2), U17.46 (VCCIO2), U17.50 (VCC), U17.55 (VCCIO1), U17.73 (VCCIO1), U17.80 (VCCIO0), U17.93 (VCCIO0), U17.100 (VCC), U18.8 (VDD), U18.24 (VDD), U19.8 (VCC); also elsewhere on the board
+5V: C25.1, C26.1, C27.1, U12.24 (VCC), U13.24 (VCC), U14.24 (VCC); also elsewhere on the board
/A0: U13.14 (B9); also elsewhere on the board
/A1: U13.13 (B10); also elsewhere on the board
/A2: U14.22 (B1); also elsewhere on the board
/A3: U14.21 (B2); also elsewhere on the board
/A4: U14.20 (B3); also elsewhere on the board
/A5: U14.19 (B4); also elsewhere on the board
/A6: U14.17 (B6); also elsewhere on the board
/A7: U14.15 (B8); also elsewhere on the board
/A8: U14.13 (B10); also elsewhere on the board
/A9: U12.21 (B2); also elsewhere on the board
/A10: U12.19 (B4); also elsewhere on the board
/A11: U12.20 (B3); also elsewhere on the board
/A12: U12.22 (B1); also elsewhere on the board
/A13: U14.14 (B9); also elsewhere on the board
/A14: U14.16 (B7); also elsewhere on the board
/A15: U14.18 (B5); also elsewhere on the board
/CLK: U15.2 (A); also elsewhere on the board
/CoProcessor/BA0: U13.10 (A9), U17.65 (PR6A)
/CoProcessor/BA1: U13.11 (A10), U17.64 (PR6B)
/CoProcessor/BA2: U14.2 (A1), U17.63 (PR7A)
/CoProcessor/BA3: U14.3 (A2), U17.62 (PR7B)
/CoProcessor/BA4: U14.4 (A3), U17.61 (PR9A)
/CoProcessor/BA5: U14.5 (A4), U17.60 (PR10A)
/CoProcessor/BA6: U14.7 (A6), U17.58 (PR11A)
/CoProcessor/BA7: U14.9 (A8), U17.54 (PR12A)
/CoProcessor/BA8: U14.11 (A10), U17.52 (PR14A)
/CoProcessor/BA9: U12.3 (A2), U17.48 (PB25A)
/CoProcessor/BA10: U12.5 (A4), U17.45 (PB22A)
/CoProcessor/BA11: U12.4 (A3), U17.47 (PB22B)
/CoProcessor/BA12: U12.2 (A1), U17.51 (PR14B)
/CoProcessor/BA13: U14.10 (A9), U17.53 (PR12B)
/CoProcessor/BA14: U14.8 (A7), U17.57 (PR11B)
/CoProcessor/BA15: U14.6 (A5), U17.59 (PR10B)
/CoProcessor/BD0: U13.3 (A2), U17.74 (PR1B)
/CoProcessor/BD1: U13.2 (A1), U17.75 (PR1A)
/CoProcessor/BD2: U13.5 (A4), U17.70 (PR3B)
/CoProcessor/BD3: U13.8 (A7), U17.67 (PR5A)
/CoProcessor/BD4: U13.9 (A8), U17.66 (PR5B)
/CoProcessor/BD5: U13.7 (A6), U17.68 (PR4B)
/CoProcessor/BD6: U13.6 (A5), U17.69 (PR4A)
/CoProcessor/BD7: U13.4 (A3), U17.71 (PR3A)
/CoProcessor/BIORQ_N: U12.10 (A9), U17.39 (PB16B)
/CoProcessor/BM1_N: U12.11 (A10), U17.37 (PB12B)
/CoProcessor/BMCLK: U16.4 (Y), U17.34 (PCLKT2_0)
/CoProcessor/BMREQ_N: U12.9 (A8), U17.40 (PB18A)
/CoProcessor/BRD_N: U12.7 (A6), U17.42 (PB21A)
/CoProcessor/BRESET_N: U12.6 (A5), U17.43 (PB21B)
/CoProcessor/BWAIT_N: Q4.1 (G), U17.29 (PB6A)
/CoProcessor/BWR_N: U12.8 (A7), U17.41 (PB18B)
/CoProcessor/BZCLK: U15.4 (Y), U17.38 (PCLKT2_1)
/CoProcessor/CA0: U17.21 (PL12B), U18.1 (A0)
/CoProcessor/CA1: U17.20 (PL12A), U18.2 (A1)
/CoProcessor/CA2: U17.19 (PL11B), U18.3 (A2)
/CoProcessor/CA3: U17.18 (PL11A), U18.4 (A3)
/CoProcessor/CA4: U17.87 (PT17B), U18.13 (A4)
/CoProcessor/CA5: U17.84 (PT19A), U18.14 (A5)
/CoProcessor/CA6: U17.83 (PT19B), U18.15 (A6)
/CoProcessor/CA7: U17.78 (PT22A), U18.16 (A7)
/CoProcessor/CA8: U17.96 (PT11B), U18.17 (A8)
/CoProcessor/CA9: U17.97 (PT11A), U18.18 (A9)
/CoProcessor/CA10: U17.98 (PT9B), U18.19 (A10)
/CoProcessor/CA11: U17.99 (PT9A), U18.20 (A11)
/CoProcessor/CA12: U17.1 (PL2A), U18.21 (A12)
/CoProcessor/CA13: U17.9 (PL5A), U18.29 (A13)
/CoProcessor/CA14: U17.10 (PL5B), U18.30 (A14)
/CoProcessor/CA15: U17.12 (PL7C), U18.31 (A15)
/CoProcessor/CA16: U17.13 (PL7D), U18.32 (A16)
/CoProcessor/CD0: U17.16 (PL10A), U18.6 (I/O0)
/CoProcessor/CD1: U17.15 (PL9B), U18.7 (I/O1)
/CoProcessor/CD2: U17.14 (PL9A), U18.10 (I/O2)
/CoProcessor/CD3: U17.85 (PT18D), U18.11 (I/O3)
/CoProcessor/CD4: U17.2 (PL2B), U18.22 (I/O4)
/CoProcessor/CD5: U17.3 (PL3A), U18.23 (I/O5)
/CoProcessor/CD6: U17.4 (PL3B), U18.26 (I/O6)
/CoProcessor/CD7: U17.7 (PL4A), U18.27 (I/O7)
/CoProcessor/DBG0: J9.6, U17.24 (PL14A)
/CoProcessor/DBG1: J9.5, U17.25 (PL14B)
/CoProcessor/DBG2: J9.4, U17.35 (PB11B)
/CoProcessor/DBG3: J9.3, U17.36 (PB12A)
/CoProcessor/DBG_N: J8.2, U17.88 (PT17A)
/CoProcessor/DONE: R17.1, R18.1, U17.76 (DONE)
/CoProcessor/DONE_LED: D4.1 (K), R18.2
/CoProcessor/F_CE_N: R13.1, U17.27 (CSSPIN), U19.1 (~CE)
/CoProcessor/F_HOLD_N: R14.2, U17.30 (PB6B), U19.7 (~HOLD/~RESET(IO3))
/CoProcessor/F_SCK: U17.31 (CCLK), U19.6 (SCK)
/CoProcessor/F_SI: U17.49 (SISPI), U19.5 (SI(IO0))
/CoProcessor/F_SO: U17.32 (SPISO), U19.2 (SO(IO1))
/CoProcessor/F_WP_N: R12.1, U17.28 (PB5B), U19.3 (~WP(IO2))
/CoProcessor/INIT_N: R16.1, U17.77 (INIT_N)
/CoProcessor/JTAGENB: R19.1, U17.82 (JTAGENB)
/CoProcessor/M_CE_N: R7.1, U17.17 (PL10B), U18.5 (~CE)
/CoProcessor/M_OE_N: U17.8 (PL4B), U18.28 (~OE)
/CoProcessor/M_WE_N: U17.86 (PT18C), U18.12 (~WE)
/CoProcessor/PROGRAM_N: R15.1, SW2.2, U17.81 (PROGRAM_N)
/CoProcessor/TCLK: J7.4, R11.1, U17.91 (TCK)
/CoProcessor/TDI: J7.5, R10.1, U17.94 (TDI)
/CoProcessor/TDO: J7.6, R9.1, U17.95 (TDO)
/CoProcessor/TMS: J7.3, R6.1, U17.90 (TMS)
/D0: U13.21 (B2); also elsewhere on the board
/D1: U13.22 (B1); also elsewhere on the board
/D2: U13.19 (B4); also elsewhere on the board
/D3: U13.16 (B7); also elsewhere on the board
/D4: U13.15 (B8); also elsewhere on the board
/D5: U13.17 (B6); also elsewhere on the board
/D6: U13.18 (B5); also elsewhere on the board
/D7: U13.20 (B3); also elsewhere on the board
/MCLK: U16.2 (A); also elsewhere on the board
/~IORQ~: U12.14 (B9); also elsewhere on the board
/~M1~: U12.13 (B10); also elsewhere on the board
/~MREQ~: U12.15 (B8); also elsewhere on the board
/~RD~: U12.17 (B6); also elsewhere on the board
/~RESET~: U12.18 (B5); also elsewhere on the board
/~WAIT~: Q4.3 (D); also elsewhere on the board
/~WR~: U12.16 (B7); also elsewhere on the board
GND: C14.1, C15.1, C16.1, C18.1, C19.1, C20.1, C21.1, C22.1, C23.1, C25.2, C26.2, C27.2, C28.1, C29.1, C30.1, C31.1, C33.2, J7.2, J8.1, J9.2, Q4.2 (S), R11.2, SW2.1, U12.12 (GND), U12.23 (~OE), U13.12 (GND), U13.23 (~OE), U14.12 (GND), U14.23 (~OE), U15.3 (GND), U16.3 (GND), U17.6 (GND), U17.22 (GND), U17.33 (GND), U17.44 (GND), U17.56 (GND), U17.72 (GND), U17.79 (GND), U17.92 (GND), U18.9 (GND), U18.25 (GND), U19.4 (GND); also elsewhere on the board

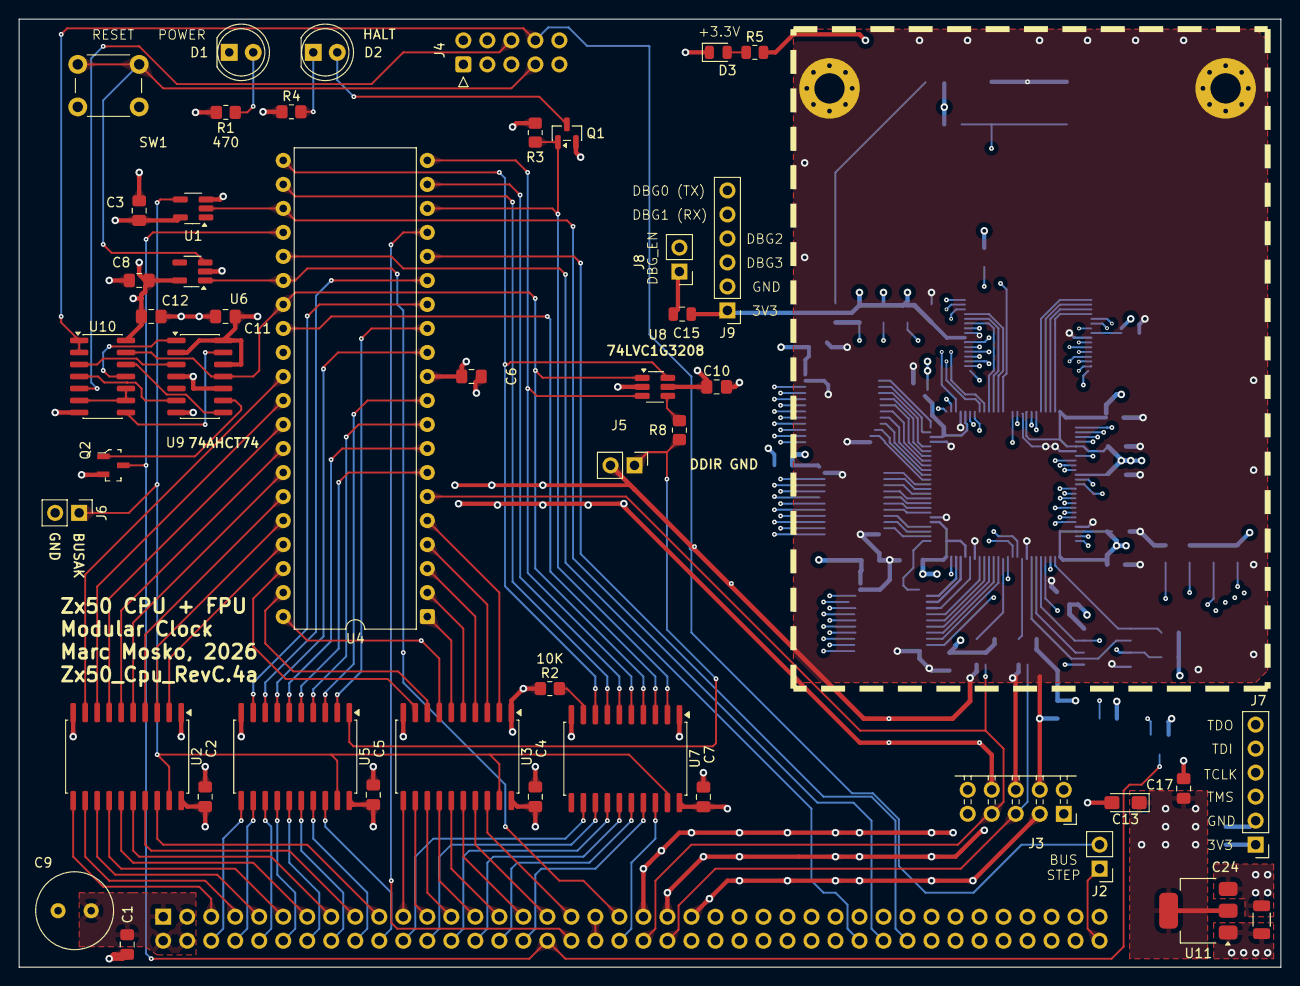
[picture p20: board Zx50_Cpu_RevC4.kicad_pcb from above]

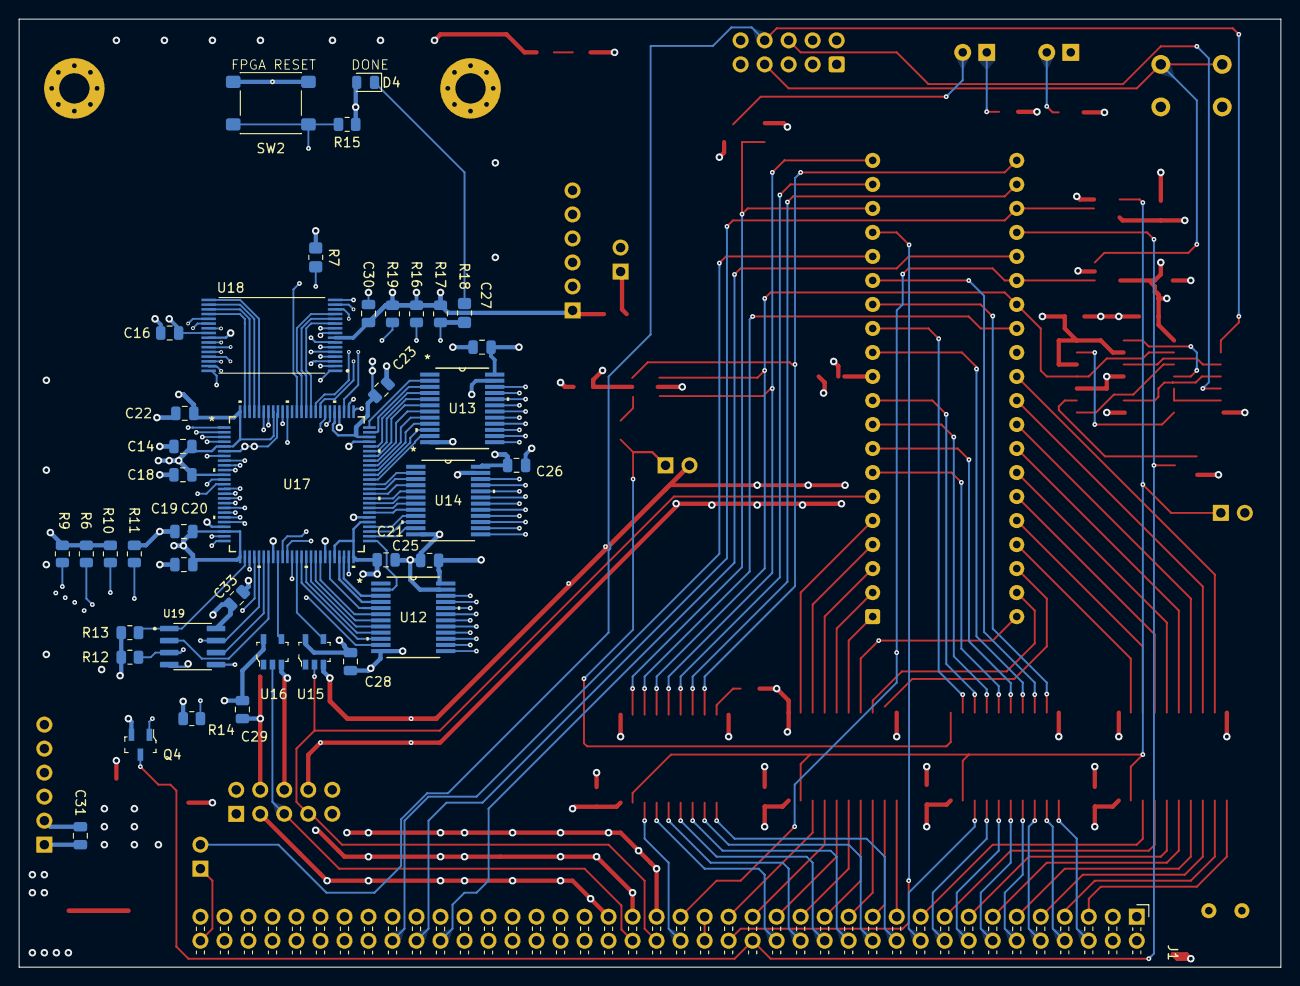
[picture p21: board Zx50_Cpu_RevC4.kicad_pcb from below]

Board: 6 copper layers, 133.5 x 100.3 mm, 88 parts (41 on the bottom side), 174 nets.

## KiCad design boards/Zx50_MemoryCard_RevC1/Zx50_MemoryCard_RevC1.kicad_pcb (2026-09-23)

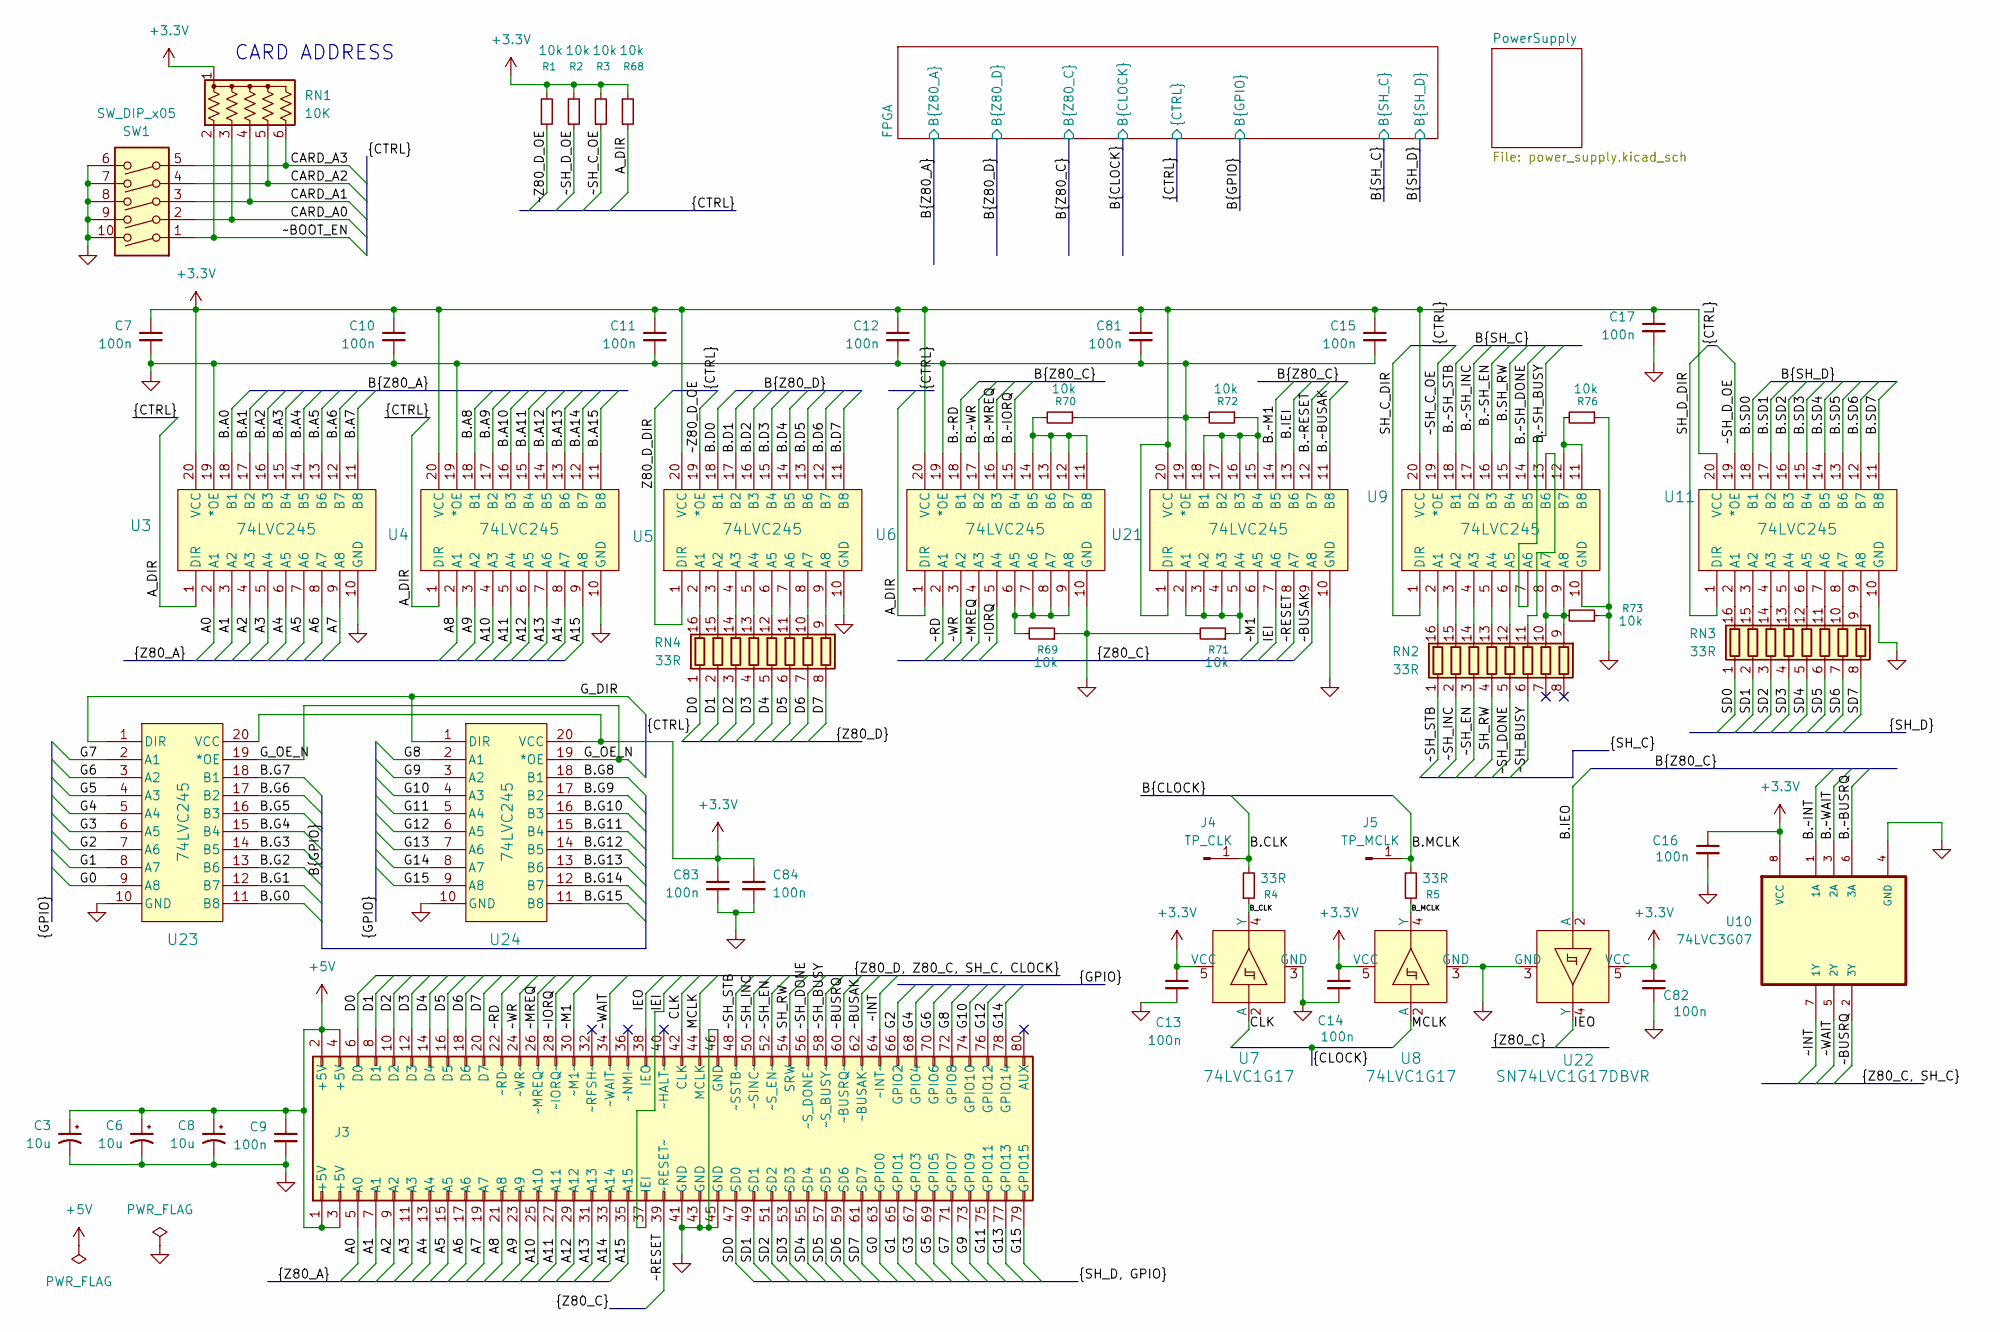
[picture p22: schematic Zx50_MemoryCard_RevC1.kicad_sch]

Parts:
C3, C6, C8: 10u; C_1206_3216Metric; MFG PN AVX TAJA106K016RNJ Tantalinium; LCSC C7171
C7, C9, C10, C11, C12, C13, C14, C15, C16, C17, C81, C82, C83, C84: 100n; C_0402_1005Metric; LCSC C1525
J3: Zx50_EdgeConnector; PinSocket_2x40_P2.54mm_Horizontal_Edge; DigiKey_PN 2057-PH2RA-80-UA-ND
J4: TP_CLK; PinHeader_1x01_P2.54mm_Vertical
J5: TP_MCLK; PinHeader_1x01_P2.54mm_Vertical
R1, R2, R3, R68, R69, R70, R71, R72, R73, R76: 10k; R_0805_2012Metric; MFG_PN 0805W8F1002T5E; LCSC C17414
R4, R5: 33R; R_0603_1608Metric; MFG_PN 0603WAF330JT5E; LCSC C23140
RN1: 10K; R_Array_SIP6; LCSC 4606X-AP1-103LF
RN2, RN3, RN4: 33R; R_Array_Convex_8x0602; LCSC C422182
SW1: SW_DIP_x05; SW_DIP_SPSTx05_Slide_9.78x14.88mm_W7.62mm_P2.54mm; LCSC 208-5
U3, U4, U5, U6, U9, U11, U21, U23, U24: 74LVC245; TSSOP-20_4.4x6.5mm_P0.65mm; MFG_PART SN74LVC245APWR; LCSC C7848
U7, U8: 74LVC1G17; SOT-753; MPN SN74LVC1G17DBVR; Digi-Key_PN 296-11933-1-ND
U10: 74LVC3G07; VSSOP-8_2.3x2mm_P0.5mm; MFG_PN SN74LVC3G07DCUR; LCSC C131955
U22: SN74LVC1G17DBVR; SOT-753; MPN SN74LVC1G17DBVR; Digi-Key_PN 296-11933-1-ND

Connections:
+3.3V: C7.1, C10.1, C11.1, C12.1, C13.1, C14.1, C15.1, C16.1, C17.1, C81.1, C82.1, C83.1, C84.1, R1.2, R2.2, R3.2, R68.2, RN1.1 (common), U3.20 (VCC), U4.20 (VCC), U5.20 (VCC), U6.20 (VCC), U7.5 (VCC), U8.5 (VCC), U9.20 (VCC), U10.8 (VCC), U11.20 (VCC), U21.1 (DIR), U21.20 (VCC), U22.5 (VCC), U23.20 (VCC), U24.20 (VCC); also elsewhere on the board
+5V: C3.1, C6.1, C8.1, C9.1, J3.1 (+5V), J3.2 (+5V), J3.3 (+5V), J3.4 (+5V); also elsewhere on the board
/A0: J3.5 (A0), U3.2 (A1)
/A1: J3.7 (A1), U3.3 (A2)
/A2: J3.9 (A2), U3.4 (A3)
/A3: J3.11 (A3), U3.5 (A4)
/A4: J3.13 (A4), U3.6 (A5)
/A5: J3.15 (A5), U3.7 (A6)
/A6: J3.17 (A6), U3.8 (A7)
/A7: J3.19 (A7), U3.9 (A8)
/A8: J3.21 (A8), U4.2 (A1)
/A9: J3.23 (A9), U4.3 (A2)
/A10: J3.25 (A10), U4.4 (A3)
/A11: J3.27 (A11), U4.5 (A4)
/A12: J3.29 (A12), U4.6 (A5)
/A13: J3.31 (A13), U4.7 (A6)
/A14: J3.33 (A14), U4.8 (A7)
/A15: J3.35 (A15), U4.9 (A8)
/A_DIR: R68.1, U3.1 (DIR), U4.1 (DIR), U6.1 (DIR); also elsewhere on the board
/B.A0: U3.18 (B1); also elsewhere on the board
/B.A1: U3.17 (B2); also elsewhere on the board
/B.A2: U3.16 (B3); also elsewhere on the board
/B.A3: U3.15 (B4); also elsewhere on the board
/B.A4: U3.14 (B5); also elsewhere on the board
/B.A5: U3.13 (B6); also elsewhere on the board
/B.A6: U3.12 (B7); also elsewhere on the board
/B.A7: U3.11 (B8); also elsewhere on the board
/B.A8: U4.18 (B1); also elsewhere on the board
/B.A9: U4.17 (B2); also elsewhere on the board
/B.A10: U4.16 (B3); also elsewhere on the board
/B.A11: U4.15 (B4); also elsewhere on the board
/B.A12: U4.14 (B5); also elsewhere on the board
/B.A13: U4.13 (B6); also elsewhere on the board
/B.A14: U4.12 (B7); also elsewhere on the board
/B.A15: U4.11 (B8); also elsewhere on the board
/B.CLK: J4.1, R4.2; also elsewhere on the board
/B.D0: U5.18 (B1); also elsewhere on the board
/B.D1: U5.17 (B2); also elsewhere on the board
/B.D2: U5.16 (B3); also elsewhere on the board
/B.D3: U5.15 (B4); also elsewhere on the board
/B.D4: U5.14 (B5); also elsewhere on the board
/B.D5: U5.13 (B6); also elsewhere on the board
/B.D6: U5.12 (B7); also elsewhere on the board
/B.D7: U5.11 (B8); also elsewhere on the board
/B.G0: U23.11 (B8); also elsewhere on the board
/B.G1: U23.12 (B7); also elsewhere on the board
/B.G2: U23.13 (B6); also elsewhere on the board
/B.G3: U23.14 (B5); also elsewhere on the board
/B.G4: U23.15 (B4); also elsewhere on the board
/B.G5: U23.16 (B3); also elsewhere on the board
/B.G6: U23.17 (B2); also elsewhere on the board
/B.G7: U23.18 (B1); also elsewhere on the board
/B.G8: U24.18 (B1); also elsewhere on the board
/B.G9: U24.17 (B2); also elsewhere on the board
/B.G10: U24.16 (B3); also elsewhere on the board
/B.G11: U24.15 (B4); also elsewhere on the board
/B.G12: U24.14 (B5); also elsewhere on the board
/B.G13: U24.13 (B6); also elsewhere on the board
/B.G14: U24.12 (B7); also elsewhere on the board
/B.G15: U24.11 (B8); also elsewhere on the board
/B.IEI: U21.13 (B6); also elsewhere on the board
/B.IEO: U22.2 (A); also elsewhere on the board
/B.MCLK: J5.1, R5.2; also elsewhere on the board
/B.SD0: U11.18 (B1); also elsewhere on the board
/B.SD1: U11.17 (B2); also elsewhere on the board
/B.SD2: U11.16 (B3); also elsewhere on the board
/B.SD3: U11.15 (B4); also elsewhere on the board
/B.SD4: U11.14 (B5); also elsewhere on the board
/B.SD5: U11.13 (B6); also elsewhere on the board
/B.SD6: U11.12 (B7); also elsewhere on the board
/B.SD7: U11.11 (B8); also elsewhere on the board
/B.SH_RW: U9.15 (B4); also elsewhere on the board
/B.~BUSAK: U21.11 (B8); also elsewhere on the board
/B.~BUSRQ: U10.6 (3A); also elsewhere on the board
/B.~INT: U10.1 (1A); also elsewhere on the board
/B.~IORQ: U6.15 (B4); also elsewhere on the board
/B.~M1: U21.14 (B5); also elsewhere on the board
/B.~MREQ: U6.16 (B3); also elsewhere on the board
/B.~RD: U6.18 (B1); also elsewhere on the board
/B.~RESET: U21.12 (B7); also elsewhere on the board
/B.~SH_BUSY: U9.7 (A6); also elsewhere on the board
/B.~SH_DONE: U9.14 (B5); also elsewhere on the board
/B.~SH_EN: U9.16 (B3); also elsewhere on the board
/B.~SH_INC: U9.17 (B2); also elsewhere on the board
/B.~SH_STB: U9.18 (B1); also elsewhere on the board
/B.~WAIT: U10.3 (2A); also elsewhere on the board
/B.~WR: U6.17 (B2); also elsewhere on the board
/B_CLK: R4.1, U7.4 (Y)
/B_MCLK: R5.1, U8.4 (Y)
/CARD_A0: RN1.3 (R2), SW1.2; also elsewhere on the board
/CARD_A1: RN1.4 (R3), SW1.3; also elsewhere on the board
/CARD_A2: RN1.5 (R4), SW1.4; also elsewhere on the board
/CARD_A3: RN1.6 (R5), SW1.5; also elsewhere on the board
/CLK: J3.42 (CLK), U7.2 (A)
/D0: J3.6 (D0), RN4.1 (R1.1)
/D1: J3.8 (D1), RN4.2 (R2.1)
/D2: J3.10 (D2), RN4.3 (R3.1)
/D3: J3.12 (D3), RN4.4 (R4.1)
/D4: J3.14 (D4), RN4.5 (R5.1)
/D5: J3.16 (D5), RN4.6 (R6.1)
/D6: J3.18 (D6), RN4.7 (R7.1)
/D7: J3.20 (D7), RN4.8 (R8.1)
/G0: J3.63 (GPIO0), U23.9 (A8)
/G1: J3.65 (GPIO1), U23.8 (A7)
/G2: J3.66 (GPIO2), U23.7 (A6)
/G3: J3.67 (GPIO3), U23.6 (A5)
/G4: J3.68 (GPIO4), U23.5 (A4)
/G5: J3.69 (GPIO5), U23.4 (A3)
/G6: J3.70 (GPIO6), U23.3 (A2)
/G7: J3.71 (GPIO7), U23.2 (A1)
/G8: J3.72 (GPIO8), U24.2 (A1)
/G9: J3.73 (GPIO9), U24.3 (A2)
/G10: J3.74 (GPIO10), U24.4 (A3)
/G11: J3.75 (GPIO11), U24.5 (A4)
/G12: J3.76 (GPIO12), U24.6 (A5)
/G13: J3.77 (GPIO13), U24.7 (A6)
/G14: J3.78 (GPIO14), U24.8 (A7)
/G15: J3.79 (GPIO15), U24.9 (A8)
/G_DIR: U23.1 (DIR), U24.1 (DIR); also elsewhere on the board
/G_OE_N: U23.19 (*OE), U24.19 (*OE); also elsewhere on the board
/IEI: J3.37 (IEI), U21.7 (A6)
/IEO: J3.38 (IEO), U22.4 (Y)
/MCLK: J3.44 (MCLK), U8.2 (A)
/SD0: J3.47 (SD0), RN3.1 (R1.1)
/SD1: J3.49 (SD1), RN3.2 (R2.1)
/SD2: J3.51 (SD2), RN3.3 (R3.1)
/SD3: J3.53 (SD3), RN3.4 (R4.1)
/SD4: J3.55 (SD4), RN3.5 (R5.1)
/SD5: J3.57 (SD5), RN3.6 (R6.1)
/SD6: J3.59 (SD6), RN3.7 (R7.1)
/SD7: J3.61 (SD7), RN3.8 (R8.1)
/SH_C_DIR: U9.1 (DIR); also elsewhere on the board
/SH_D_DIR: U11.1 (DIR); also elsewhere on the board
/SH_RW: J3.54 (SRW), RN2.4 (R4.1)
/Z80_D_DIR: U5.1 (DIR); also elsewhere on the board
/~BOOT_EN: RN1.2 (R1), SW1.1; also elsewhere on the board
/~BUSAK: J3.62 (~BUSAK~), U21.9 (A8)
/~BUSRQ: J3.60 (~BUSRQ~), U10.2 (3Y)
/~INT: J3.64 (~INT~), U10.7 (1Y)
/~IORQ: J3.28 (~IORQ~), U6.5 (A4)
/~M1: J3.30 (~M1~), U21.6 (A5)
/~MREQ: J3.26 (~MREQ~), U6.4 (A3)
/~RD: J3.22 (~RD~), U6.2 (A1)
/~RESET: J3.39 (~RESET~), U21.8 (A7)
/~SH_BUSY: J3.58 (~S_BUSY~), RN2.6 (R6.1)
/~SH_C_OE: R3.1, U9.19 (*OE); also elsewhere on the board
/~SH_DONE: J3.56 (~S_DONE~), RN2.5 (R5.1)
/~SH_D_OE: R2.1, U11.19 (*OE); also elsewhere on the board
/~SH_EN: J3.52 (~S_EN~), RN2.3 (R3.1)
/~SH_INC: J3.50 (~SINC~), RN2.2 (R2.1)
/~SH_STB: J3.48 (~SSTB~), RN2.1 (R1.1)
/~WAIT: J3.34 (~WAIT~), U10.5 (2Y)
/~WR: J3.24 (~WR~), U6.3 (A2)
/~Z80_D_OE: R1.1, U5.19 (*OE); also elsewhere on the board
GND: C3.2, C6.2, C7.2, C8.2, C9.2, C10.2, C11.2, C12.2, C13.2, C14.2, C15.2, C16.2, C17.2, C81.2, C82.2, C83.2, C84.2, J3.41 (GND), J3.43 (GND), J3.45 (GND), J3.46 (GND), R69.1, R70.1, R71.2, R72.2, R73.1, R76.1, SW1.6, SW1.7, SW1.8, SW1.9, SW1.10, U3.10 (GND), U3.19 (*OE), U4.10 (GND), U4.19 (*OE), U5.10 (GND), U6.10 (GND), U6.19 (*OE), U7.3 (GND), U8.3 (GND), U9.10 (GND), U10.4 (GND), U11.10 (GND), U21.10 (GND), U21.19 (*OE), U22.3 (GND), U23.10 (GND), U24.10 (GND); also elsewhere on the board
unnamed: RN2.16 (R1.2), U9.2 (A1)
unnamed: RN2.15 (R2.2), U9.3 (A2)
unnamed: RN2.14 (R3.2), U9.4 (A3)
unnamed: RN2.13 (R4.2), U9.5 (A4)
unnamed: RN2.12 (R5.2), U9.6 (A5)
unnamed: RN2.11 (R6.2), U9.13 (B6)
unnamed: R73.2, RN2.9 (R8.2), RN2.10 (R7.2), U9.8 (A7), U9.9 (A8)
unnamed: RN3.16 (R1.2), U11.2 (A1)
unnamed: RN3.15 (R2.2), U11.3 (A2)
unnamed: RN3.14 (R3.2), U11.4 (A3)
unnamed: RN3.13 (R4.2), U11.5 (A4)
unnamed: RN3.12 (R5.2), U11.6 (A5)
unnamed: RN3.11 (R6.2), U11.7 (A6)
unnamed: RN3.10 (R7.2), U11.8 (A7)
unnamed: RN3.9 (R8.2), U11.9 (A8)
unnamed: RN4.16 (R1.2), U5.2 (A1)
unnamed: RN4.15 (R2.2), U5.3 (A2)
unnamed: RN4.14 (R3.2), U5.4 (A3)
unnamed: RN4.13 (R4.2), U5.5 (A4)
unnamed: RN4.12 (R5.2), U5.6 (A5)
unnamed: RN4.11 (R6.2), U5.7 (A6)
unnamed: RN4.10 (R7.2), U5.8 (A7)
unnamed: RN4.9 (R8.2), U5.9 (A8)
unnamed: R69.2, U6.6 (A5), U6.7 (A6), U6.8 (A7), U6.9 (A8)
unnamed: R70.2, U6.11 (B8), U6.12 (B7), U6.13 (B6), U6.14 (B5)
unnamed: R76.2, U9.11 (B8), U9.12 (B7)
unnamed: R71.1, U21.2 (A1), U21.3 (A2), U21.4 (A3), U21.5 (A4)
unnamed: R72.1, U21.15 (B4), U21.16 (B3), U21.17 (B2), U21.18 (B1)

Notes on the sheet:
CARD ADDRESS

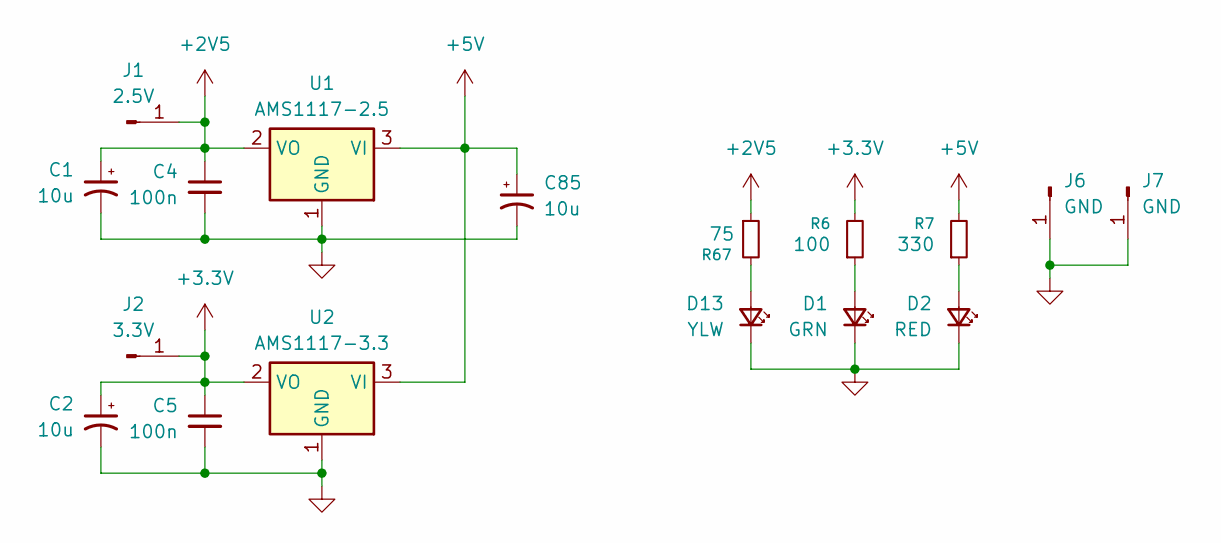
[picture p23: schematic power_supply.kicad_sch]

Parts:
C1, C2, C85: 10u; C_1206_3216Metric; MFG PN AVX TAJA106K016RNJ Tantalinium; LCSC C7171
C4, C5: 100n; C_0402_1005Metric; LCSC C1525
D1: GRN; LED_0805_2012Metric; MFG_PN KT-0805G; LCSC C2297
D2: RED; LED_0805_2012Metric; MFG_PN NCD0805R1; LCSC C84256
D13: YLW; LED_0805_2012Metric; MFG_PN KT-0805G; LCSC C2297
J1: 2.5V; PinHeader_1x01_P2.54mm_Vertical
J2: 3.3V; PinHeader_1x01_P2.54mm_Vertical
J6, J7: GND; PinHeader_1x01_P2.54mm_Vertical
R6: 100; R_0805_2012Metric; MFG_PN 0805W8F1000T5E; LCSC C17408
R7: 330; R_0805_2012Metric; MFG_PN 0805W8F3300T5E; LCSC C17630
R67: 75; R_0603_1608Metric; MFG_PN 0603WAF750JT5E; LCSC C4275
U1: AMS1117-2.5; SOT-223-3_TabPin2; Mouser_PN 926-LM1117MPX2.5NOPB
U2: AMS1117-3.3; SOT-223-3_TabPin2; Mouser_PN 926-LM1117MPX3.3NOPB

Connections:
+2V5: C1.1, C4.1, J1.1, R67.1, U1.2 (VO); also elsewhere on the board
+3.3V: C2.1, C5.1, J2.1, R6.2, U2.2 (VO); also elsewhere on the board
+5V: C85.1, R7.2, U1.3 (VI), U2.3 (VI); also elsewhere on the board
GND: C1.2, C2.2, C4.2, C5.2, C85.2, D1.1 (K), D2.1 (K), D13.1 (K), J6.1, J7.1, U1.1 (GND), U2.1 (GND); also elsewhere on the board
unnamed: D1.2 (A), R6.1
unnamed: D2.2 (A), R7.1
unnamed: D13.2 (A), R67.2

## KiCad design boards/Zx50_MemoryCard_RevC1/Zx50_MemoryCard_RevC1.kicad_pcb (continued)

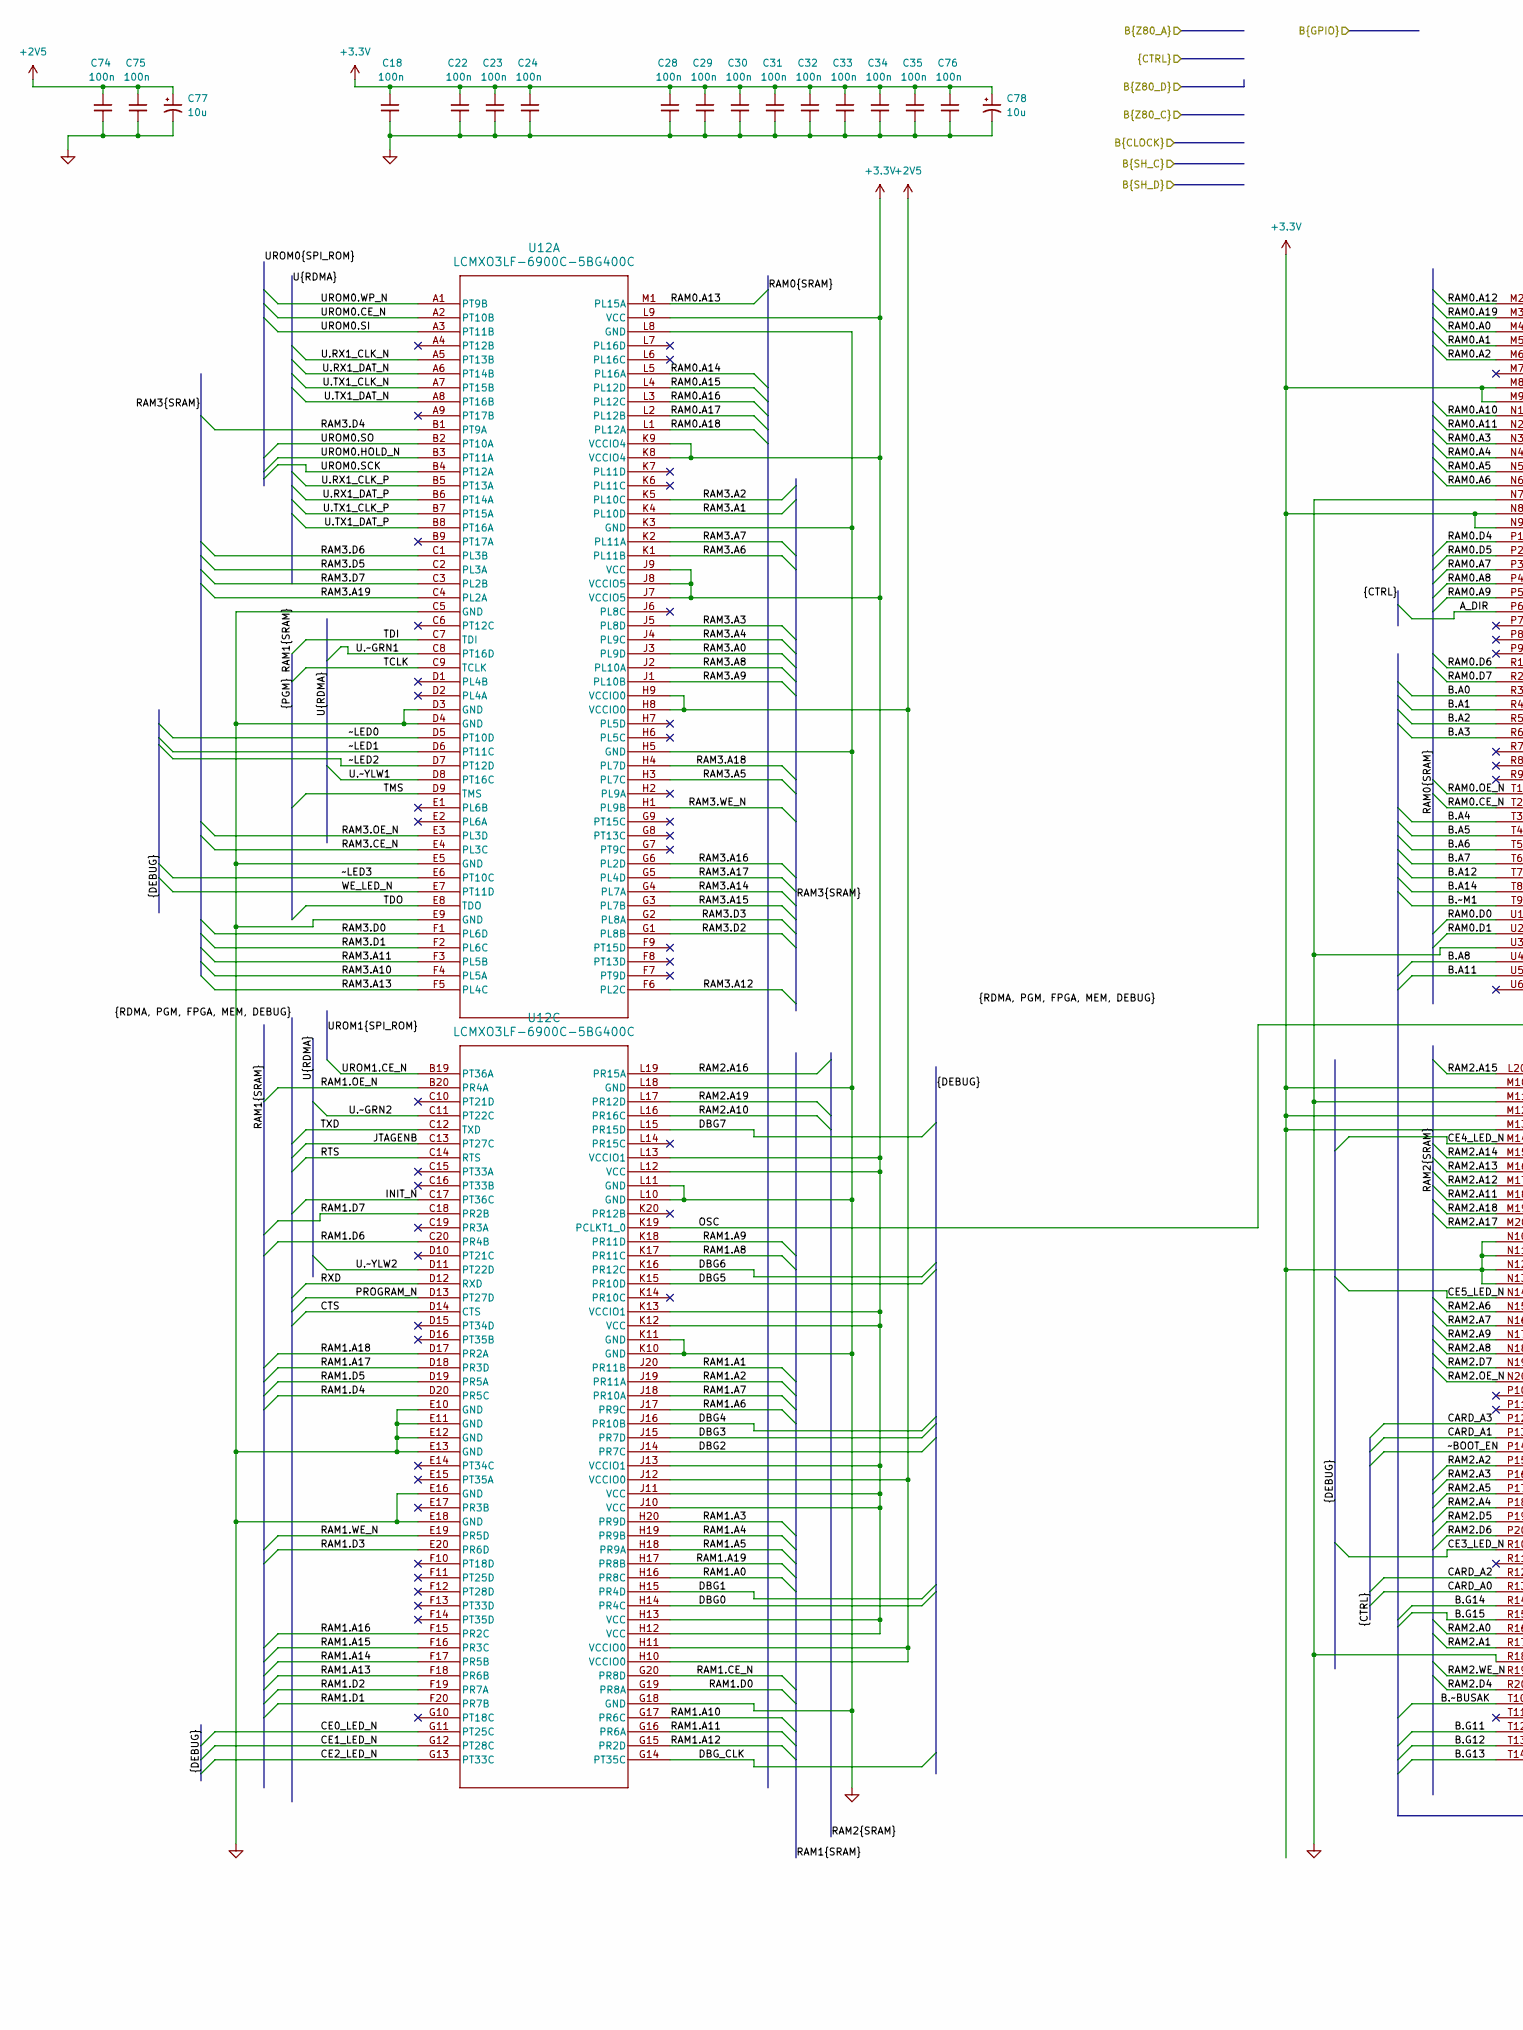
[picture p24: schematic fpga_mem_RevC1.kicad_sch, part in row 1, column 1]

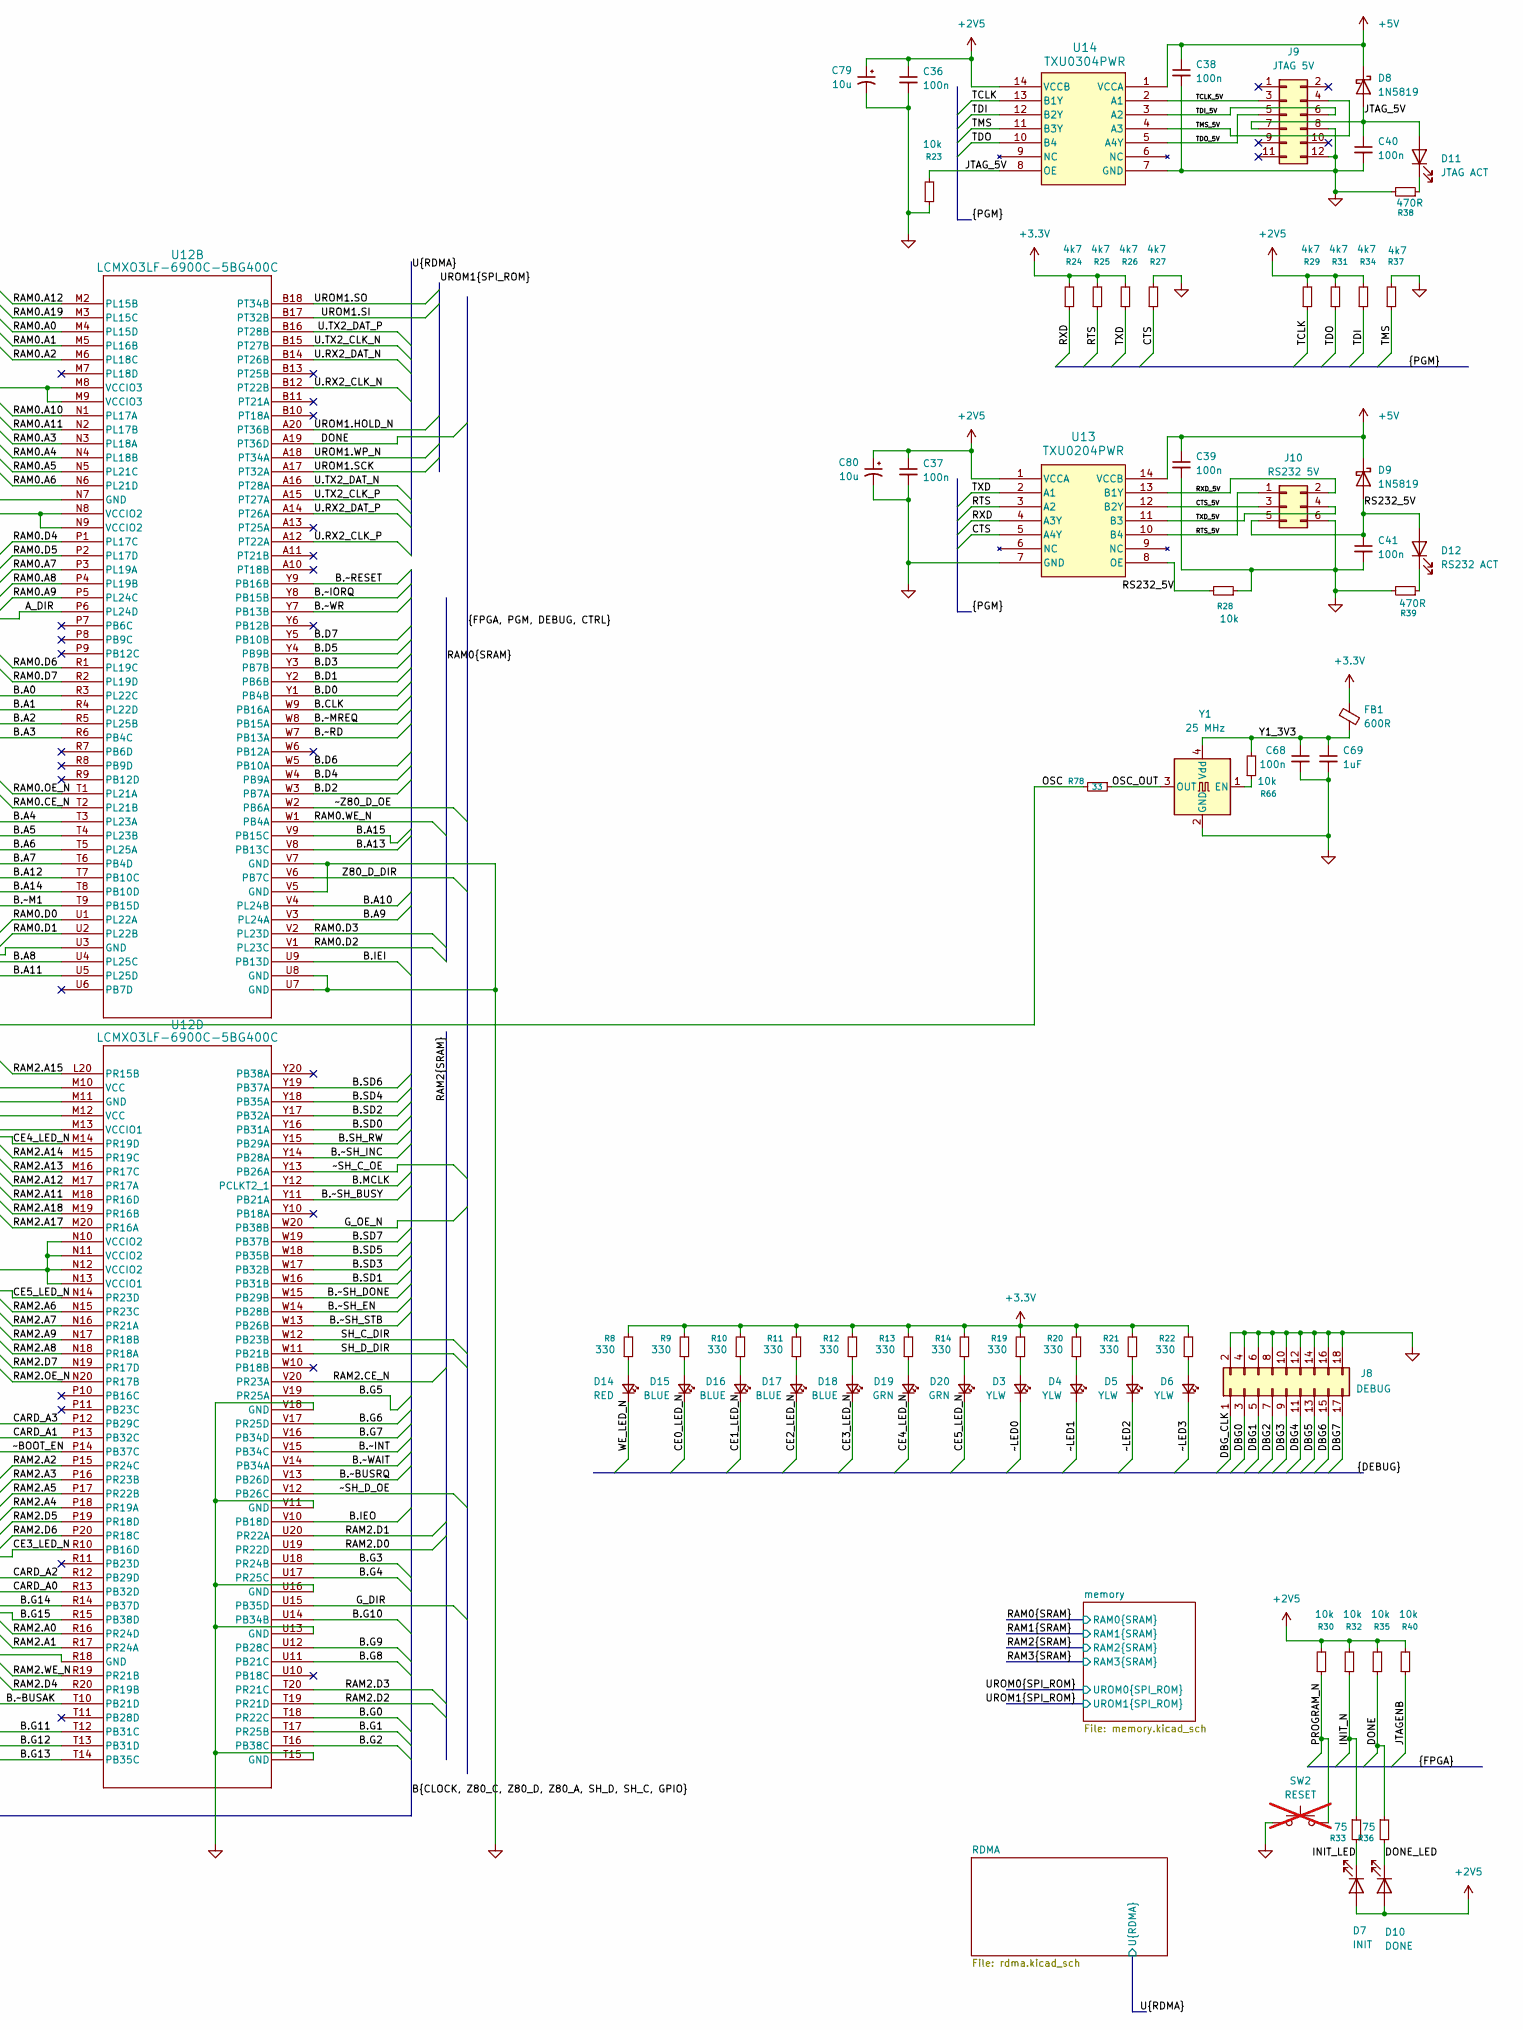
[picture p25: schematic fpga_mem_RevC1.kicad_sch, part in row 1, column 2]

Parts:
C18, C22, C23, C24, C28, C29, C30, C31, C32, C33, C34, C35, C36, C37, C38, C39, C40, C41, C68, C74, C75, C76: 100n; C_0402_1005Metric; LCSC C1525
C69: 1uF; C_0402_1005Metric; LCSC C52923
C77, C78, C79, C80: 10u; C_1206_3216Metric; MFG PN AVX TAJA106K016RNJ Tantalinium; LCSC C7171
D3, D4, D5, D6: YLW; LED_0805_2012Metric; MFG_PN KT-0805Y; LCSC C2296
D7: INIT; LED_D3.0mm
D8, D9: 1N5819; D_SOD-323; LCSC C191023
D10: DONE; LED_D3.0mm
D11: JTAG ACT; LED_D3.0mm
D12: RS232 ACT; LED_D3.0mm
D14: RED; LED_0805_2012Metric; MFG_PN NCD0805R1; LCSC C84256
D15, D16, D17, D18: BLUE; LED_0805_2012Metric; MFG_PN KT-0805B; LCSC C2293
D19, D20: GRN; LED_0805_2012Metric; MFG_PN KT-0805G; LCSC C2297
FB1: 600R; 0805; LCSC C1017
J8: DEBUG; IDC-Header_2x09_P2.54mm_Vertical
J9: JTAG 5V; IDC-Header_2x06_P2.54mm_Horizontal
J10: RS232 5V; IDC-Header_2x03_P2.54mm_Horizontal
R8, R9, R10, R11, R12, R13, R14, R19, R20, R21, R22: 330; R_0805_2012Metric; MFG_PN 0805W8F3300T5E; LCSC C17630
R23, R28, R30, R32, R35, R40, R66: 10k; R_0402_1005Metric; MFG_PN 0402WGF1002TCE; LCSC C25744
R24, R25, R26, R27, R29, R31, R34, R37: 4k7; R_0402_1005Metric; MFG_PN 0402WGF4701TCE; LCSC C25900
R33, R36: 75; R_0603_1608Metric; MFG_PN 0603WAF750JT5E; LCSC C4275
R38, R39: 470R; R_0805_2012Metric; MFG_PN 0805W8F4700T5E; LCSC C17710
R78: 33; R_0402_1005Metric; MFG_PN 0402WGF1000TCE; LCSC C25076
SW2: RESET; SW_PUSH_6mm_H7.3mm; DigiKey_PN SW402-ND; not fitted
U12: LCMXO3LF-6900C-5BG400C; CABGA400_LAT
U13: TXU0204PWR; TSSOP14_PW_TEX; LCSC C4363888
U14: TXU0304PWR; TSSOP14_PW_TEX; LCSC C4364118
Y1: 25 MHz; Crystal_SMD_3225-4Pin_3.2x2.5mm; LCSC C669088

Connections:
+2V5: C36.1, C37.1, C74.1, C75.1, C77.1, C79.1, C80.1, D7.2 (A), D10.2 (A), R29.2, R30.2, R31.2, R32.2, R34.2, R35.2, R40.2, U12.H8 (VCCIO0), U12.H9 (VCCIO0), U12.H10 (VCCIO0), U12.H11 (VCCIO0), U12.J12 (VCCIO0), U13.1 (VCCA), U14.14 (VCCB); also elsewhere on the board
+3.3V: C18.1, C22.1, C23.1, C24.1, C28.1, C29.1, C30.1, C31.1, C32.1, C33.1, C34.1, C35.1, C76.1, C78.1, FB1.1, R8.2, R9.2, R10.2, R11.2, R12.2, R13.2, R14.2, R19.2, R20.2, R21.2, R22.2, R24.2, R25.2, R26.2, U12.H12 (VCC), U12.H13 (VCC), U12.J7 (VCCIO5), U12.J8 (VCCIO5), U12.J9 (VCC), U12.J10 (VCC), U12.J11 (VCC), U12.J13 (VCCIO1), U12.K8 (VCCIO4), U12.K9 (VCCIO4), U12.K12 (VCC), U12.K13 (VCCIO1), U12.L9 (VCC), U12.L12 (VCC), U12.L13 (VCCIO1), U12.M8 (VCCIO3), U12.M9 (VCCIO3), U12.M10 (VCC), U12.M12 (VCC), U12.M13 (VCCIO1), U12.N8 (VCCIO2), U12.N9 (VCCIO2), U12.N10 (VCCIO2), U12.N11 (VCCIO2), U12.N12 (VCCIO2), U12.N13 (VCCIO1); also elsewhere on the board
+5V: C38.1, C39.1, D8.1 (K), D9.1 (K), U13.14 (VCCB), U14.1 (VCCA); also elsewhere on the board
/A_DIR: U12.P6 (PL24D); also elsewhere on the board
/B.A0: U12.R3 (PL22C); also elsewhere on the board
/B.A1: U12.R4 (PL22D); also elsewhere on the board
/B.A2: U12.R5 (PL25B); also elsewhere on the board
/B.A3: U12.R6 (PB4C); also elsewhere on the board
/B.A4: U12.T3 (PL23A); also elsewhere on the board
/B.A5: U12.T4 (PL23B); also elsewhere on the board
/B.A6: U12.T5 (PL25A); also elsewhere on the board
/B.A7: U12.T6 (PB4D); also elsewhere on the board
/B.A8: U12.U4 (PL25C); also elsewhere on the board
/B.A9: U12.V3 (PL24A); also elsewhere on the board
/B.A10: U12.V4 (PL24B); also elsewhere on the board
/B.A11: U12.U5 (PL25D); also elsewhere on the board
/B.A12: U12.T7 (PB10C); also elsewhere on the board
/B.A13: U12.V8 (PB13C); also elsewhere on the board
/B.A14: U12.T8 (PB10D); also elsewhere on the board
/B.A15: U12.V9 (PB15C); also elsewhere on the board
/B.CLK: U12.W9 (PB16A); also elsewhere on the board
/B.D0: U12.Y1 (PB4B); also elsewhere on the board
/B.D1: U12.Y2 (PB6B); also elsewhere on the board
/B.D2: U12.W3 (PB7A); also elsewhere on the board
/B.D3: U12.Y3 (PB7B); also elsewhere on the board
/B.D4: U12.W4 (PB9A); also elsewhere on the board
/B.D5: U12.Y4 (PB9B); also elsewhere on the board
/B.D6: U12.W5 (PB10A); also elsewhere on the board
/B.D7: U12.Y5 (PB10B); also elsewhere on the board
/B.G0: U12.T18 (PR22C); also elsewhere on the board
/B.G1: U12.T17 (PR25B); also elsewhere on the board
/B.G2: U12.T16 (PB38C); also elsewhere on the board
/B.G3: U12.U18 (PR24B); also elsewhere on the board
/B.G4: U12.U17 (PR25C); also elsewhere on the board
/B.G5: U12.V19 (PR25A); also elsewhere on the board
/B.G6: U12.V17 (PR25D); also elsewhere on the board
/B.G7: U12.V16 (PB34D); also elsewhere on the board
/B.G8: U12.U11 (PB21C); also elsewhere on the board
/B.G9: U12.U12 (PB28C); also elsewhere on the board
/B.G10: U12.U14 (PB34B); also elsewhere on the board
/B.G11: U12.T12 (PB31C); also elsewhere on the board
/B.G12: U12.T13 (PB31D); also elsewhere on the board
/B.G13: U12.T14 (PB35C); also elsewhere on the board
/B.G14: U12.R14 (PB37D); also elsewhere on the board
/B.G15: U12.R15 (PB38D); also elsewhere on the board
/B.IEI: U12.U9 (PB13D); also elsewhere on the board
/B.IEO: U12.V10 (PB18D); also elsewhere on the board
/B.MCLK: U12.Y12 (PCLKT2_1); also elsewhere on the board
/B.SD0: U12.Y16 (PB31A); also elsewhere on the board
/B.SD1: U12.W16 (PB31B); also elsewhere on the board
/B.SD2: U12.Y17 (PB32A); also elsewhere on the board
/B.SD3: U12.W17 (PB32B); also elsewhere on the board
/B.SD4: U12.Y18 (PB35A); also elsewhere on the board
/B.SD5: U12.W18 (PB35B); also elsewhere on the board
/B.SD6: U12.Y19 (PB37A); also elsewhere on the board
/B.SD7: U12.W19 (PB37B); also elsewhere on the board
/B.SH_RW: U12.Y15 (PB29A); also elsewhere on the board
/B.~BUSAK: U12.T10 (PB21D); also elsewhere on the board
/B.~BUSRQ: U12.V13 (PB26D); also elsewhere on the board
/B.~INT: U12.V15 (PB34C); also elsewhere on the board
/B.~IORQ: U12.Y8 (PB15B); also elsewhere on the board
/B.~M1: U12.T9 (PB15D); also elsewhere on the board
/B.~MREQ: U12.W8 (PB15A); also elsewhere on the board
/B.~RD: U12.W7 (PB13A); also elsewhere on the board
/B.~RESET: U12.Y9 (PB16B); also elsewhere on the board
/B.~SH_BUSY: U12.Y11 (PB21A); also elsewhere on the board
/B.~SH_DONE: U12.W15 (PB29B); also elsewhere on the board
/B.~SH_EN: U12.W14 (PB28B); also elsewhere on the board
/B.~SH_INC: U12.Y14 (PB28A); also elsewhere on the board
/B.~SH_STB: U12.W13 (PB26B); also elsewhere on the board
/B.~WAIT: U12.V14 (PB34A); also elsewhere on the board
/B.~WR: U12.Y7 (PB13B); also elsewhere on the board
/CARD_A0: U12.R13 (PB32D); also elsewhere on the board
/CARD_A1: U12.P13 (PB32C); also elsewhere on the board
/CARD_A2: U12.R12 (PB29D); also elsewhere on the board
/CARD_A3: U12.P12 (PB29C); also elsewhere on the board
/FPGA/CE0_LED_N: D15.1 (K), U12.G11 (PT25C)
/FPGA/CE1_LED_N: D16.1 (K), U12.G12 (PT28C)
/FPGA/CE2_LED_N: D17.1 (K), U12.G13 (PT33C)
/FPGA/CE3_LED_N: D18.1 (K), U12.R10 (PB16D)
/FPGA/CE4_LED_N: D19.1 (K), U12.M14 (PR19D)
/FPGA/CE5_LED_N: D20.1 (K), U12.N14 (PR23D)
/FPGA/CTS: R27.1, U12.D14 (CTS), U13.5 (A4Y)
/FPGA/CTS_5V: J10.3, U13.12 (B2Y)
/FPGA/DBG0: J8.3, U12.H14 (PR4C)
/FPGA/DBG1: J8.5, U12.H15 (PR4D)
/FPGA/DBG2: J8.7, U12.J14 (PR7C)
/FPGA/DBG3: J8.9, U12.J15 (PR7D)
/FPGA/DBG4: J8.11, U12.J16 (PR10B)
/FPGA/DBG5: J8.13, U12.K15 (PR10D)
/FPGA/DBG6: J8.15, U12.K16 (PR12C)
/FPGA/DBG7: J8.17, U12.L15 (PR15D)
/FPGA/DBG_CLK: J8.1, U12.G14 (PT35C)
/FPGA/DONE: R35.1, R36.1, U12.A19 (PT36D)
/FPGA/DONE_LED: D10.1 (K), R36.2
/FPGA/INIT_LED: D7.1 (K), R33.2
/FPGA/INIT_N: R32.1, R33.1, U12.C17 (PT36C)
/FPGA/JTAGENB: R40.1, U12.C13 (PT27C)
/FPGA/JTAG_5V: C40.1, D8.2 (A), D11.2 (A), J9.7, R23.2, U14.8 (OE)
/FPGA/OSC: R78.2, U12.K19 (PCLKT1_0)
/FPGA/OSC_OUT: R78.1, Y1.3 (OUT)
/FPGA/PROGRAM_N: R30.1, SW2.2, U12.D13 (PT27D)
/FPGA/RAM0.A0: U12.M4 (PL15D); also elsewhere on the board
/FPGA/RAM0.A1: U12.M5 (PL16B); also elsewhere on the board
/FPGA/RAM0.A2: U12.M6 (PL18C); also elsewhere on the board
/FPGA/RAM0.A3: U12.N3 (PL18A); also elsewhere on the board
/FPGA/RAM0.A4: U12.N4 (PL18B); also elsewhere on the board
/FPGA/RAM0.A5: U12.N5 (PL21C); also elsewhere on the board
/FPGA/RAM0.A6: U12.N6 (PL21D); also elsewhere on the board
/FPGA/RAM0.A7: U12.P3 (PL19A); also elsewhere on the board
/FPGA/RAM0.A8: U12.P4 (PL19B); also elsewhere on the board
/FPGA/RAM0.A9: U12.P5 (PL24C); also elsewhere on the board
/FPGA/RAM0.A10: U12.N1 (PL17A); also elsewhere on the board
/FPGA/RAM0.A11: U12.N2 (PL17B); also elsewhere on the board
/FPGA/RAM0.A12: U12.M2 (PL15B); also elsewhere on the board
/FPGA/RAM0.A13: U12.M1 (PL15A); also elsewhere on the board
/FPGA/RAM0.A14: U12.L5 (PL16A); also elsewhere on the board
/FPGA/RAM0.A15: U12.L4 (PL12D); also elsewhere on the board
/FPGA/RAM0.A16: U12.L3 (PL12C); also elsewhere on the board
/FPGA/RAM0.A17: U12.L2 (PL12B); also elsewhere on the board
/FPGA/RAM0.A18: U12.L1 (PL12A); also elsewhere on the board
/FPGA/RAM0.A19: U12.M3 (PL15C); also elsewhere on the board
/FPGA/RAM0.CE_N: U12.T2 (PL21B); also elsewhere on the board
/FPGA/RAM0.D0: U12.U1 (PL22A); also elsewhere on the board
/FPGA/RAM0.D1: U12.U2 (PL22B); also elsewhere on the board
/FPGA/RAM0.D2: U12.V1 (PL23C); also elsewhere on the board
/FPGA/RAM0.D3: U12.V2 (PL23D); also elsewhere on the board
/FPGA/RAM0.D4: U12.P1 (PL17C); also elsewhere on the board
/FPGA/RAM0.D5: U12.P2 (PL17D); also elsewhere on the board
/FPGA/RAM0.D6: U12.R1 (PL19C); also elsewhere on the board
/FPGA/RAM0.D7: U12.R2 (PL19D); also elsewhere on the board
/FPGA/RAM0.OE_N: U12.T1 (PL21A); also elsewhere on the board
/FPGA/RAM0.WE_N: U12.W1 (PB4A); also elsewhere on the board
/FPGA/RAM1.A0: U12.H16 (PR8C); also elsewhere on the board
/FPGA/RAM1.A1: U12.J20 (PR11B); also elsewhere on the board
/FPGA/RAM1.A2: U12.J19 (PR11A); also elsewhere on the board
/FPGA/RAM1.A3: U12.H20 (PR9D); also elsewhere on the board
/FPGA/RAM1.A4: U12.H19 (PR9B); also elsewhere on the board
/FPGA/RAM1.A5: U12.H18 (PR9A); also elsewhere on the board
/FPGA/RAM1.A6: U12.J17 (PR9C); also elsewhere on the board
/FPGA/RAM1.A7: U12.J18 (PR10A); also elsewhere on the board
/FPGA/RAM1.A8: U12.K17 (PR11C); also elsewhere on the board
/FPGA/RAM1.A9: U12.K18 (PR11D); also elsewhere on the board
/FPGA/RAM1.A10: U12.G17 (PR6C); also elsewhere on the board
/FPGA/RAM1.A11: U12.G16 (PR6A); also elsewhere on the board
/FPGA/RAM1.A12: U12.G15 (PR2D); also elsewhere on the board
/FPGA/RAM1.A13: U12.F18 (PR6B); also elsewhere on the board
/FPGA/RAM1.A14: U12.F17 (PR5B); also elsewhere on the board
/FPGA/RAM1.A15: U12.F16 (PR3C); also elsewhere on the board
/FPGA/RAM1.A16: U12.F15 (PR2C); also elsewhere on the board
/FPGA/RAM1.A17: U12.D18 (PR3D); also elsewhere on the board
/FPGA/RAM1.A18: U12.D17 (PR2A); also elsewhere on the board
/FPGA/RAM1.A19: U12.H17 (PR8B); also elsewhere on the board
/FPGA/RAM1.CE_N: U12.G20 (PR8D); also elsewhere on the board
/FPGA/RAM1.D0: U12.G19 (PR8A); also elsewhere on the board
/FPGA/RAM1.D1: U12.F20 (PR7B); also elsewhere on the board
/FPGA/RAM1.D2: U12.F19 (PR7A); also elsewhere on the board
/FPGA/RAM1.D3: U12.E20 (PR6D); also elsewhere on the board
/FPGA/RAM1.D4: U12.D20 (PR5C); also elsewhere on the board
/FPGA/RAM1.D5: U12.D19 (PR5A); also elsewhere on the board
/FPGA/RAM1.D6: U12.C20 (PR4B); also elsewhere on the board
/FPGA/RAM1.D7: U12.C18 (PR2B); also elsewhere on the board
/FPGA/RAM1.OE_N: U12.B20 (PR4A); also elsewhere on the board
/FPGA/RAM1.WE_N: U12.E19 (PR5D); also elsewhere on the board
/FPGA/RAM2.A0: U12.R16 (PR24D); also elsewhere on the board
/FPGA/RAM2.A1: U12.R17 (PR24A); also elsewhere on the board
/FPGA/RAM2.A2: U12.P15 (PR24C); also elsewhere on the board
/FPGA/RAM2.A3: U12.P16 (PR23B); also elsewhere on the board
/FPGA/RAM2.A4: U12.P18 (PR19A); also elsewhere on the board
/FPGA/RAM2.A5: U12.P17 (PR22B); also elsewhere on the board
/FPGA/RAM2.A6: U12.N15 (PR23C); also elsewhere on the board
/FPGA/RAM2.A7: U12.N16 (PR21A); also elsewhere on the board
/FPGA/RAM2.A8: U12.N18 (PR18A); also elsewhere on the board
/FPGA/RAM2.A9: U12.N17 (PR18B); also elsewhere on the board
/FPGA/RAM2.A10: U12.L16 (PR16C); also elsewhere on the board
/FPGA/RAM2.A11: U12.M18 (PR16D); also elsewhere on the board
/FPGA/RAM2.A12: U12.M17 (PR17A); also elsewhere on the board
/FPGA/RAM2.A13: U12.M16 (PR17C); also elsewhere on the board
/FPGA/RAM2.A14: U12.M15 (PR19C); also elsewhere on the board
/FPGA/RAM2.A15: U12.L20 (PR15B); also elsewhere on the board
/FPGA/RAM2.A16: U12.L19 (PR15A); also elsewhere on the board
/FPGA/RAM2.A17: U12.M20 (PR16A); also elsewhere on the board
/FPGA/RAM2.A18: U12.M19 (PR16B); also elsewhere on the board
/FPGA/RAM2.A19: U12.L17 (PR12D); also elsewhere on the board
/FPGA/RAM2.CE_N: U12.V20 (PR23A); also elsewhere on the board
/FPGA/RAM2.D0: U12.U19 (PR22D); also elsewhere on the board
/FPGA/RAM2.D1: U12.U20 (PR22A); also elsewhere on the board
/FPGA/RAM2.D2: U12.T19 (PR21D); also elsewhere on the board
/FPGA/RAM2.D3: U12.T20 (PR21C); also elsewhere on the board
/FPGA/RAM2.D4: U12.R20 (PR19B); also elsewhere on the board
/FPGA/RAM2.D5: U12.P19 (PR18D); also elsewhere on the board
/FPGA/RAM2.D6: U12.P20 (PR18C); also elsewhere on the board
/FPGA/RAM2.D7: U12.N19 (PR17D); also elsewhere on the board
/FPGA/RAM2.OE_N: U12.N20 (PR17B); also elsewhere on the board
/FPGA/RAM2.WE_N: U12.R19 (PR21B); also elsewhere on the board
/FPGA/RAM3.A0: U12.J3 (PL9D); also elsewhere on the board
/FPGA/RAM3.A1: U12.K4 (PL10D); also elsewhere on the board
/FPGA/RAM3.A2: U12.K5 (PL10C); also elsewhere on the board
/FPGA/RAM3.A3: U12.J5 (PL8D); also elsewhere on the board
/FPGA/RAM3.A4: U12.J4 (PL9C); also elsewhere on the board
/FPGA/RAM3.A5: U12.H3 (PL7C); also elsewhere on the board
/FPGA/RAM3.A6: U12.K1 (PL11B); also elsewhere on the board
/FPGA/RAM3.A7: U12.K2 (PL11A); also elsewhere on the board
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

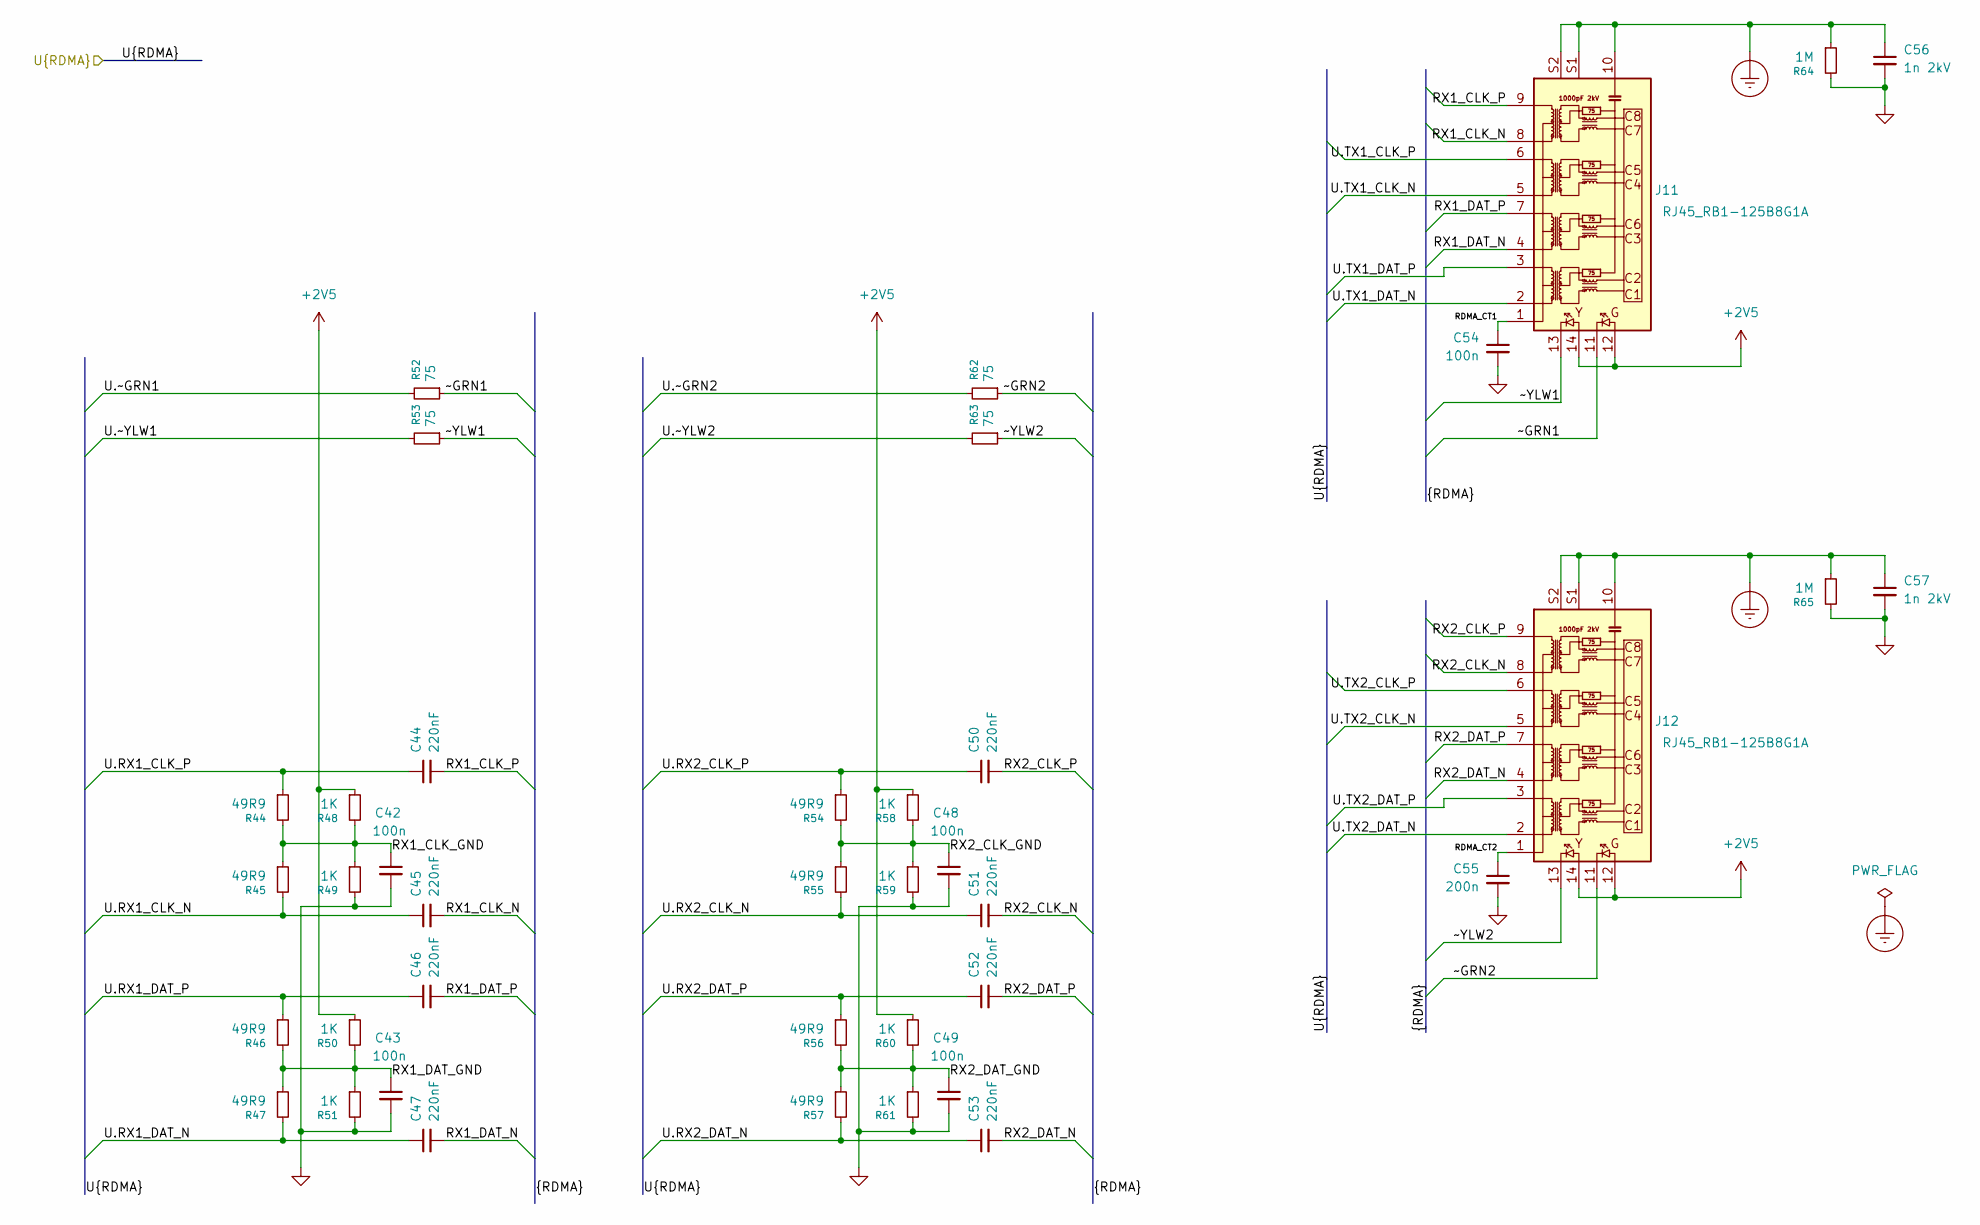
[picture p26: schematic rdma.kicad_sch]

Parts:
C42, C43, C48, C49, C54: 100n; C_0402_1005Metric; LCSC C1525
C44, C45, C46, C47, C50, C51, C52, C53: 220nF; C_0402_1005Metric; LCSC C16772
C55: 200n; C_0402_1005Metric; LCSC C1525
C56, C57: 1n 2kV; C_1206_3216Metric; LCSC C9196
J11, J12: RJ45_RB1-125B8G1A; HANRUN_HR911130A; MFG_PN HR911130C; LCSC C50933
R44, R45, R46, R47, R54, R55, R56, R57: 49R9; R_0402_1005Metric; MFG_PN 0402WGF499JTCE; LCSC C25120
R48, R49, R50, R51, R58, R59, R60, R61: 1K; R_0402_1005Metric; MFG_PN 0402WGF1001TCE; LCSC C11702
R52, R53, R62, R63: 75; R_0603_1608Metric; MFG_PN 0603WAF750JT5E; LCSC C4275
R64, R65: 1M; R_0805_2012Metric; MFG_PN 0805W8F1004T5E; LCSC C17514

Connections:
+2V5: J11.12, J11.14, J12.12, J12.14, R48.1, R50.1, R58.1, R60.1; also elsewhere on the board
/FPGA/RDMA/RDMA_CT1: C54.1, J11.1 (CT)
/FPGA/RDMA/RDMA_CT2: C55.1, J12.1 (CT)
/FPGA/RDMA/RX1_CLK_GND: C42.1, R44.2, R45.1, R48.2, R49.1
/FPGA/RDMA/RX1_CLK_N: C45.2, J11.8 (TD4+)
/FPGA/RDMA/RX1_CLK_P: C44.2, J11.9 (TD4-)
/FPGA/RDMA/RX1_DAT_GND: C43.1, R46.2, R47.1, R50.2, R51.1
/FPGA/RDMA/RX1_DAT_N: C47.2, J11.4 (TD2+)
/FPGA/RDMA/RX1_DAT_P: C46.2, J11.7 (TD2-)
/FPGA/RDMA/RX2_CLK_GND: C48.1, R54.2, R55.1, R58.2, R59.1
/FPGA/RDMA/RX2_CLK_N: C51.2, J12.8 (TD4+)
/FPGA/RDMA/RX2_CLK_P: C50.2, J12.9 (TD4-)
/FPGA/RDMA/RX2_DAT_GND: C49.1, R56.2, R57.1, R60.2, R61.1
/FPGA/RDMA/RX2_DAT_N: C53.2, J12.4 (TD2+)
/FPGA/RDMA/RX2_DAT_P: C52.2, J12.7 (TD2-)
/FPGA/RDMA/~GRN1: J11.11, R52.1
/FPGA/RDMA/~GRN2: J12.11, R62.1
/FPGA/RDMA/~YLW1: J11.13, R53.1
/FPGA/RDMA/~YLW2: J12.13, R63.1
/FPGA/U.RX1_CLK_N: C45.1, R45.2; also elsewhere on the board
/FPGA/U.RX1_CLK_P: C44.1, R44.1; also elsewhere on the board
/FPGA/U.RX1_DAT_N: C47.1, R47.2; also elsewhere on the board
/FPGA/U.RX1_DAT_P: C46.1, R46.1; also elsewhere on the board
/FPGA/U.RX2_CLK_N: C51.1, R55.2; also elsewhere on the board
/FPGA/U.RX2_CLK_P: C50.1, R54.1; also elsewhere on the board
/FPGA/U.RX2_DAT_N: C53.1, R57.2; also elsewhere on the board
/FPGA/U.RX2_DAT_P: C52.1, R56.1; also elsewhere on the board
/FPGA/U.TX1_CLK_N: J11.5 (TD3+); also elsewhere on the board
/FPGA/U.TX1_CLK_P: J11.6 (TD3-); also elsewhere on the board
/FPGA/U.TX1_DAT_N: J11.2 (TD1+); also elsewhere on the board
/FPGA/U.TX1_DAT_P: J11.3 (TD1-); also elsewhere on the board
/FPGA/U.TX2_CLK_N: J12.5 (TD3+); also elsewhere on the board
/FPGA/U.TX2_CLK_P: J12.6 (TD3-); also elsewhere on the board
/FPGA/U.TX2_DAT_N: J12.2 (TD1+); also elsewhere on the board
/FPGA/U.TX2_DAT_P: J12.3 (TD1-); also elsewhere on the board
/FPGA/U.~GRN1: R52.2; also elsewhere on the board
/FPGA/U.~GRN2: R62.2; also elsewhere on the board
/FPGA/U.~YLW1: R53.2; also elsewhere on the board
/FPGA/U.~YLW2: R63.2; also elsewhere on the board
Earth_Protective: C56.1, C57.1, J11.10 (GND), J11.S1, J11.S2, J12.10 (GND), J12.S1, J12.S2, R64.1, R65.1
GND: C42.2, C43.2, C48.2, C49.2, C54.2, C55.2, C56.2, C57.2, R49.2, R51.2, R59.2, R61.2, R64.2, R65.2; also elsewhere on the board

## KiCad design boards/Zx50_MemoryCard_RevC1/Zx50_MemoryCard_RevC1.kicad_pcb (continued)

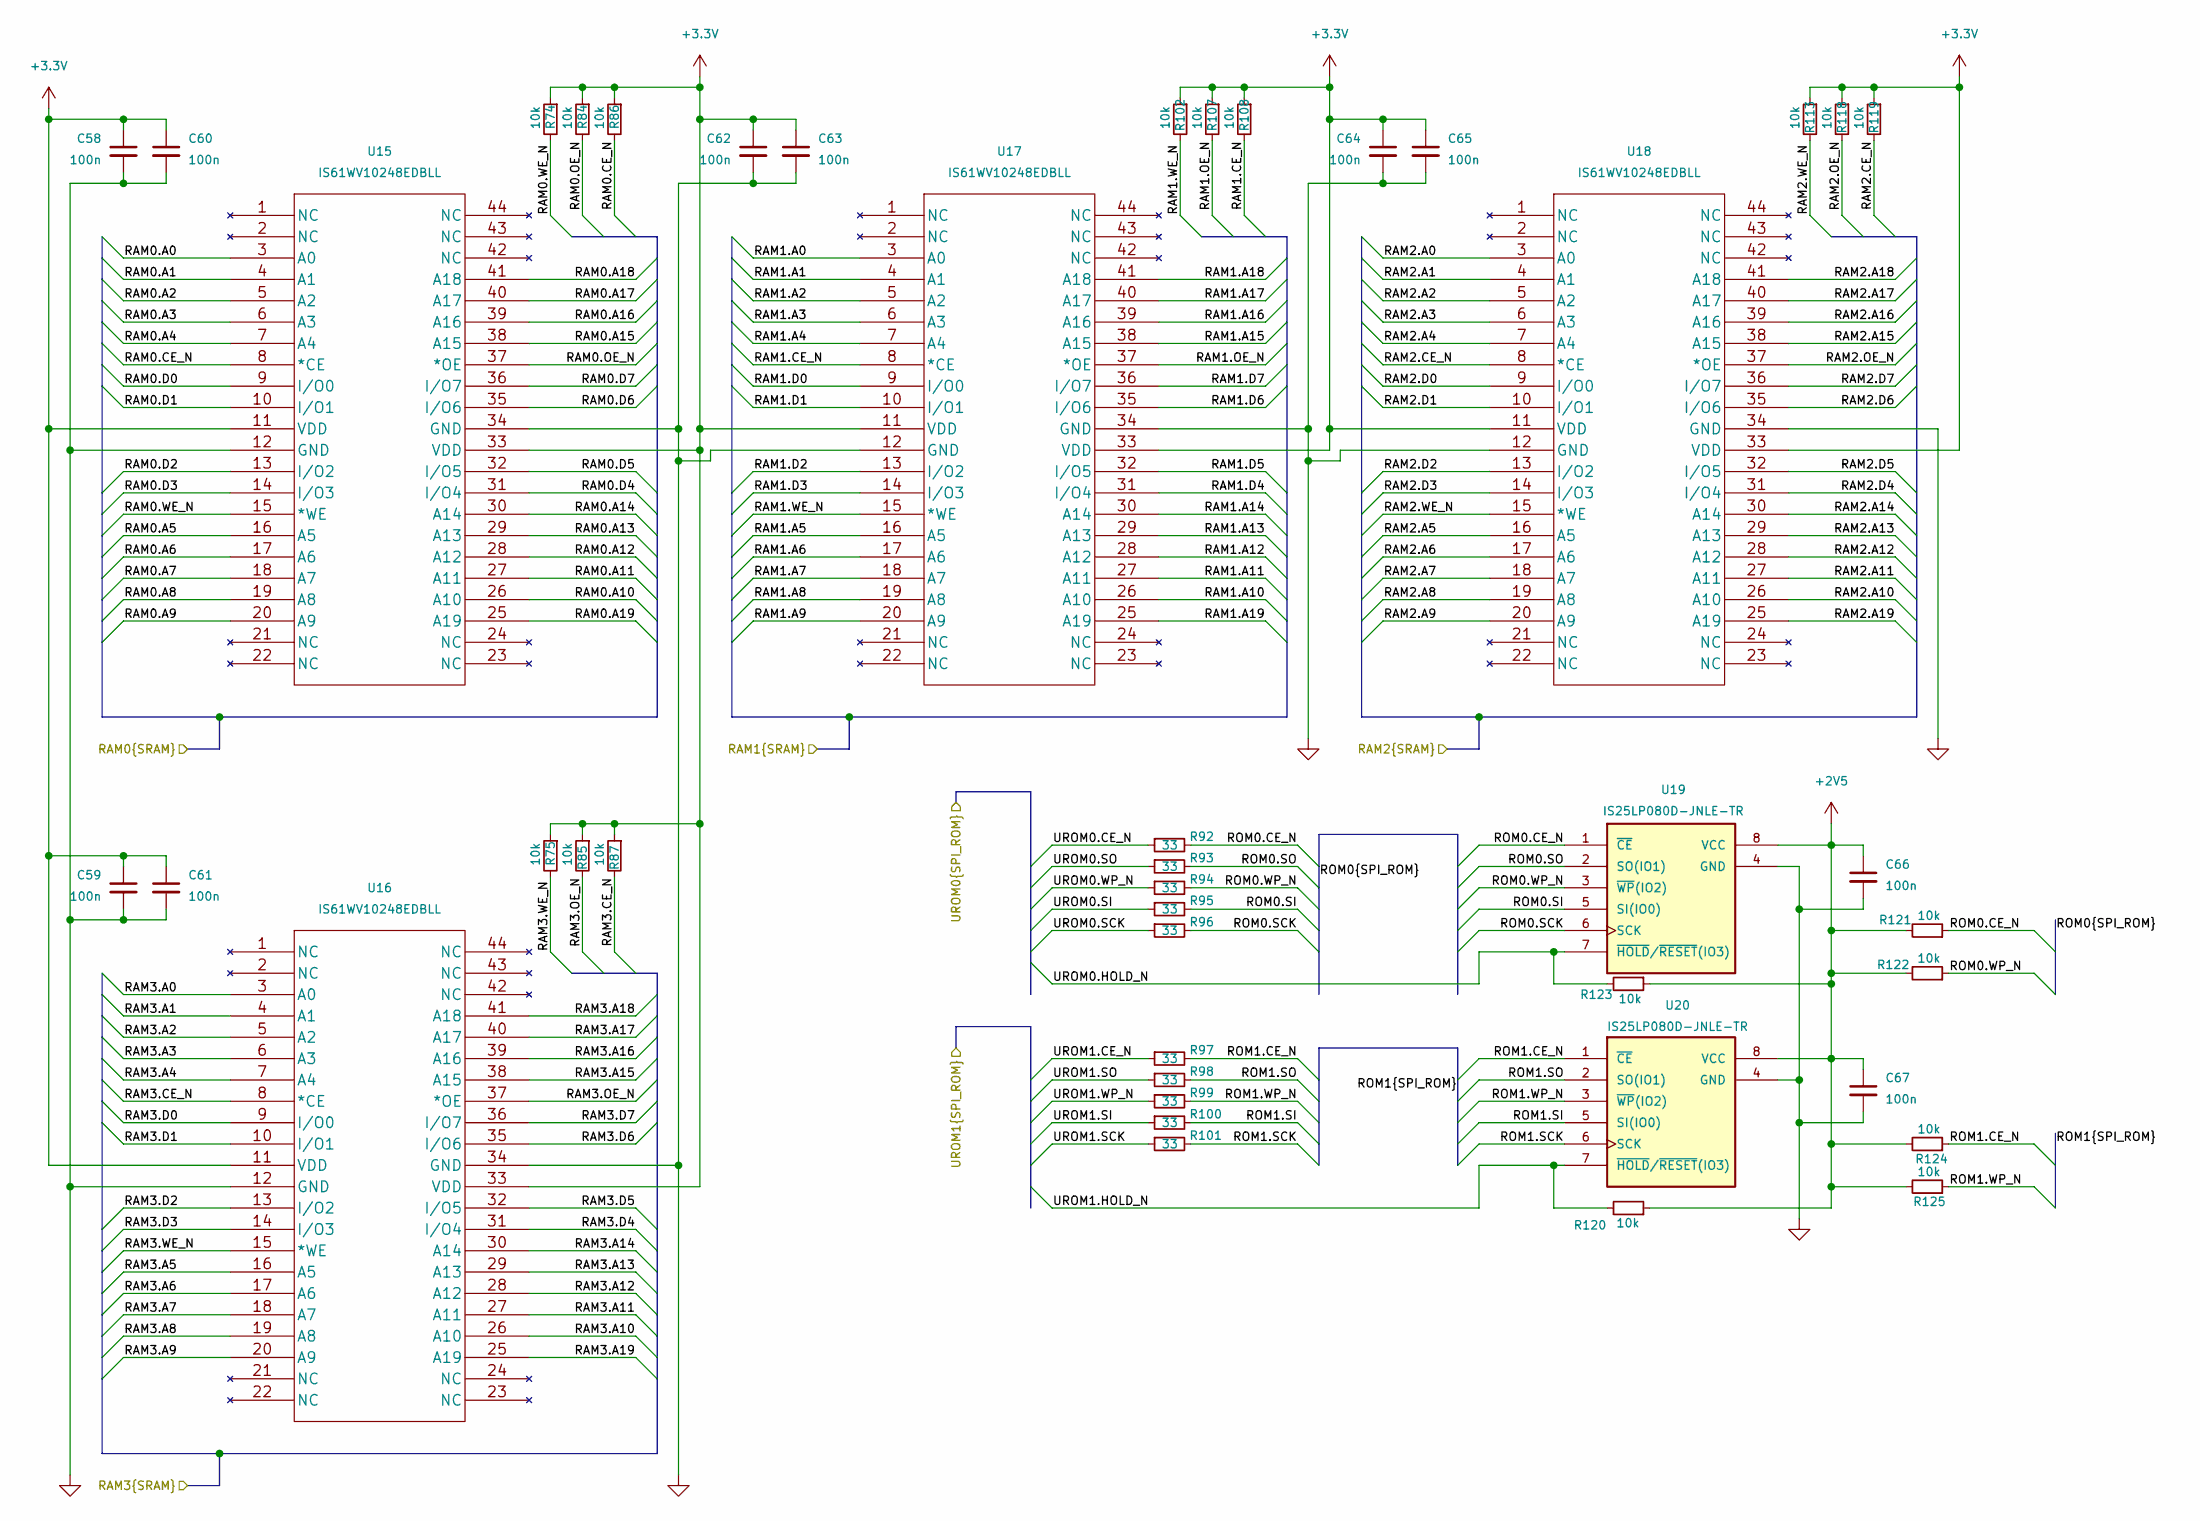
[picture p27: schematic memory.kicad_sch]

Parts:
C58, C59, C60, C61, C62, C63, C64, C65, C66, C67: 100n; C_0402_1005Metric; LCSC C1525
R74, R75, R84, R85, R86, R87, R102, R107, R108, R113, R118, R119, R120, R121, R122, R123, R124, R125: 10k; R_0402_1005Metric; MFG_PN 0402WGF1002TCE; LCSC C25744
R92, R93, R94, R95, R96, R97, R98, R99, R100, R101: 33; R_0402_1005Metric; MFG_PN 0402WGF1000TCE; LCSC C25076
U15, U16, U17, U18: IS61WV10248EDBLL; TSOP-44_11P9X18P5_ISI; LCSC C1349228
U19, U20: IS25LP080D-JNLE-TR; SOIC127P600X88-8N; DigiKey_PN 706-1581-1-ND

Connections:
+2V5: C66.1, C67.1, R120.1, R121.2, R122.2, R123.1, R124.2, R125.2, U19.8 (VCC), U20.8 (VCC); also elsewhere on the board
+3.3V: C58.1, C59.1, C60.1, C61.1, C62.1, C63.1, C64.1, C65.1, R74.1, R75.1, R84.1, R85.1, R86.1, R87.1, R102.1, R107.1, R108.1, R113.1, R118.1, R119.1, U15.11 (VDD), U15.33 (VDD), U16.11 (VDD), U16.33 (VDD), U17.11 (VDD), U17.33 (VDD), U18.11 (VDD), U18.33 (VDD); also elsewhere on the board
/FPGA/RAM0.A0: U15.3 (A0); also elsewhere on the board
/FPGA/RAM0.A1: U15.4 (A1); also elsewhere on the board
/FPGA/RAM0.A2: U15.5 (A2); also elsewhere on the board
/FPGA/RAM0.A3: U15.6 (A3); also elsewhere on the board
/FPGA/RAM0.A4: U15.7 (A4); also elsewhere on the board
/FPGA/RAM0.A5: U15.16 (A5); also elsewhere on the board
/FPGA/RAM0.A6: U15.17 (A6); also elsewhere on the board
/FPGA/RAM0.A7: U15.18 (A7); also elsewhere on the board
/FPGA/RAM0.A8: U15.19 (A8); also elsewhere on the board
/FPGA/RAM0.A9: U15.20 (A9); also elsewhere on the board
/FPGA/RAM0.A10: U15.26 (A10); also elsewhere on the board
/FPGA/RAM0.A11: U15.27 (A11); also elsewhere on the board
/FPGA/RAM0.A12: U15.28 (A12); also elsewhere on the board
/FPGA/RAM0.A13: U15.29 (A13); also elsewhere on the board
/FPGA/RAM0.A14: U15.30 (A14); also elsewhere on the board
/FPGA/RAM0.A15: U15.38 (A15); also elsewhere on the board
/FPGA/RAM0.A16: U15.39 (A16); also elsewhere on the board
/FPGA/RAM0.A17: U15.40 (A17); also elsewhere on the board
/FPGA/RAM0.A18: U15.41 (A18); also elsewhere on the board
/FPGA/RAM0.A19: U15.25 (A19); also elsewhere on the board
/FPGA/RAM0.CE_N: R86.2, U15.8 (*CE); also elsewhere on the board
/FPGA/RAM0.D0: U15.9 (I/O0); also elsewhere on the board
/FPGA/RAM0.D1: U15.10 (I/O1); also elsewhere on the board
/FPGA/RAM0.D2: U15.13 (I/O2); also elsewhere on the board
/FPGA/RAM0.D3: U15.14 (I/O3); also elsewhere on the board
/FPGA/RAM0.D4: U15.31 (I/O4); also elsewhere on the board
/FPGA/RAM0.D5: U15.32 (I/O5); also elsewhere on the board
/FPGA/RAM0.D6: U15.35 (I/O6); also elsewhere on the board
/FPGA/RAM0.D7: U15.36 (I/O7); also elsewhere on the board
/FPGA/RAM0.OE_N: R84.2, U15.37 (*OE); also elsewhere on the board
/FPGA/RAM0.WE_N: R74.2, U15.15 (*WE); also elsewhere on the board
/FPGA/RAM1.A0: U17.3 (A0); also elsewhere on the board
/FPGA/RAM1.A1: U17.4 (A1); also elsewhere on the board
/FPGA/RAM1.A2: U17.5 (A2); also elsewhere on the board
/FPGA/RAM1.A3: U17.6 (A3); also elsewhere on the board
/FPGA/RAM1.A4: U17.7 (A4); also elsewhere on the board
/FPGA/RAM1.A5: U17.16 (A5); also elsewhere on the board
/FPGA/RAM1.A6: U17.17 (A6); also elsewhere on the board
/FPGA/RAM1.A7: U17.18 (A7); also elsewhere on the board
/FPGA/RAM1.A8: U17.19 (A8); also elsewhere on the board
/FPGA/RAM1.A9: U17.20 (A9); also elsewhere on the board
/FPGA/RAM1.A10: U17.26 (A10); also elsewhere on the board
/FPGA/RAM1.A11: U17.27 (A11); also elsewhere on the board
/FPGA/RAM1.A12: U17.28 (A12); also elsewhere on the board
/FPGA/RAM1.A13: U17.29 (A13); also elsewhere on the board
/FPGA/RAM1.A14: U17.30 (A14); also elsewhere on the board
/FPGA/RAM1.A15: U17.38 (A15); also elsewhere on the board
/FPGA/RAM1.A16: U17.39 (A16); also elsewhere on the board
/FPGA/RAM1.A17: U17.40 (A17); also elsewhere on the board
/FPGA/RAM1.A18: U17.41 (A18); also elsewhere on the board
/FPGA/RAM1.A19: U17.25 (A19); also elsewhere on the board
/FPGA/RAM1.CE_N: R108.2, U17.8 (*CE); also elsewhere on the board
/FPGA/RAM1.D0: U17.9 (I/O0); also elsewhere on the board
/FPGA/RAM1.D1: U17.10 (I/O1); also elsewhere on the board
/FPGA/RAM1.D2: U17.13 (I/O2); also elsewhere on the board
/FPGA/RAM1.D3: U17.14 (I/O3); also elsewhere on the board
/FPGA/RAM1.D4: U17.31 (I/O4); also elsewhere on the board
/FPGA/RAM1.D5: U17.32 (I/O5); also elsewhere on the board
/FPGA/RAM1.D6: U17.35 (I/O6); also elsewhere on the board
/FPGA/RAM1.D7: U17.36 (I/O7); also elsewhere on the board
/FPGA/RAM1.OE_N: R107.2, U17.37 (*OE); also elsewhere on the board
/FPGA/RAM1.WE_N: R102.2, U17.15 (*WE); also elsewhere on the board
/FPGA/RAM2.A0: U18.3 (A0); also elsewhere on the board
/FPGA/RAM2.A1: U18.4 (A1); also elsewhere on the board
/FPGA/RAM2.A2: U18.5 (A2); also elsewhere on the board
/FPGA/RAM2.A3: U18.6 (A3); also elsewhere on the board
/FPGA/RAM2.A4: U18.7 (A4); also elsewhere on the board
/FPGA/RAM2.A5: U18.16 (A5); also elsewhere on the board
/FPGA/RAM2.A6: U18.17 (A6); also elsewhere on the board
/FPGA/RAM2.A7: U18.18 (A7); also elsewhere on the board
/FPGA/RAM2.A8: U18.19 (A8); also elsewhere on the board
/FPGA/RAM2.A9: U18.20 (A9); also elsewhere on the board
/FPGA/RAM2.A10: U18.26 (A10); also elsewhere on the board
/FPGA/RAM2.A11: U18.27 (A11); also elsewhere on the board
/FPGA/RAM2.A12: U18.28 (A12); also elsewhere on the board
/FPGA/RAM2.A13: U18.29 (A13); also elsewhere on the board
/FPGA/RAM2.A14: U18.30 (A14); also elsewhere on the board
/FPGA/RAM2.A15: U18.38 (A15); also elsewhere on the board
/FPGA/RAM2.A16: U18.39 (A16); also elsewhere on the board
/FPGA/RAM2.A17: U18.40 (A17); also elsewhere on the board
/FPGA/RAM2.A18: U18.41 (A18); also elsewhere on the board
/FPGA/RAM2.A19: U18.25 (A19); also elsewhere on the board
/FPGA/RAM2.CE_N: R119.2, U18.8 (*CE); also elsewhere on the board
/FPGA/RAM2.D0: U18.9 (I/O0); also elsewhere on the board
/FPGA/RAM2.D1: U18.10 (I/O1); also elsewhere on the board
/FPGA/RAM2.D2: U18.13 (I/O2); also elsewhere on the board
/FPGA/RAM2.D3: U18.14 (I/O3); also elsewhere on the board
/FPGA/RAM2.D4: U18.31 (I/O4); also elsewhere on the board
/FPGA/RAM2.D5: U18.32 (I/O5); also elsewhere on the board
/FPGA/RAM2.D6: U18.35 (I/O6); also elsewhere on the board
/FPGA/RAM2.D7: U18.36 (I/O7); also elsewhere on the board
/FPGA/RAM2.OE_N: R118.2, U18.37 (*OE); also elsewhere on the board
/FPGA/RAM2.WE_N: R113.2, U18.15 (*WE); also elsewhere on the board
/FPGA/RAM3.A0: U16.3 (A0); also elsewhere on the board
/FPGA/RAM3.A1: U16.4 (A1); also elsewhere on the board
/FPGA/RAM3.A2: U16.5 (A2); also elsewhere on the board
/FPGA/RAM3.A3: U16.6 (A3); also elsewhere on the board
/FPGA/RAM3.A4: U16.7 (A4); also elsewhere on the board
/FPGA/RAM3.A5: U16.16 (A5); also elsewhere on the board
/FPGA/RAM3.A6: U16.17 (A6); also elsewhere on the board
/FPGA/RAM3.A7: U16.18 (A7); also elsewhere on the board
/FPGA/RAM3.A8: U16.19 (A8); also elsewhere on the board
/FPGA/RAM3.A9: U16.20 (A9); also elsewhere on the board
/FPGA/RAM3.A10: U16.26 (A10); also elsewhere on the board
/FPGA/RAM3.A11: U16.27 (A11); also elsewhere on the board
/FPGA/RAM3.A12: U16.28 (A12); also elsewhere on the board
/FPGA/RAM3.A13: U16.29 (A13); also elsewhere on the board
/FPGA/RAM3.A14: U16.30 (A14); also elsewhere on the board
/FPGA/RAM3.A15: U16.38 (A15); also elsewhere on the board
/FPGA/RAM3.A16: U16.39 (A16); also elsewhere on the board
/FPGA/RAM3.A17: U16.40 (A17); also elsewhere on the board
/FPGA/RAM3.A18: U16.41 (A18); also elsewhere on the board
/FPGA/RAM3.A19: U16.25 (A19); also elsewhere on the board
/FPGA/RAM3.CE_N: R87.2, U16.8 (*CE); also elsewhere on the board
/FPGA/RAM3.D0: U16.9 (I/O0); also elsewhere on the board
/FPGA/RAM3.D1: U16.10 (I/O1); also elsewhere on the board
/FPGA/RAM3.D2: U16.13 (I/O2); also elsewhere on the board
/FPGA/RAM3.D3: U16.14 (I/O3); also elsewhere on the board
/FPGA/RAM3.D4: U16.31 (I/O4); also elsewhere on the board
/FPGA/RAM3.D5: U16.32 (I/O5); also elsewhere on the board
/FPGA/RAM3.D6: U16.35 (I/O6); also elsewhere on the board
/FPGA/RAM3.D7: U16.36 (I/O7); also elsewhere on the board
/FPGA/RAM3.OE_N: R85.2, U16.37 (*OE); also elsewhere on the board
/FPGA/RAM3.WE_N: R75.2, U16.15 (*WE); also elsewhere on the board
/FPGA/UROM0.CE_N: R92.1; also elsewhere on the board
/FPGA/UROM0.HOLD_N: R123.2, U19.7 (~HOLD/~RESET(IO3)); also elsewhere on the board
/FPGA/UROM0.SCK: R96.1; also elsewhere on the board
/FPGA/UROM0.SI: R95.1; also elsewhere on the board
/FPGA/UROM0.SO: R93.1; also elsewhere on the board
/FPGA/UROM0.WP_N: R94.1; also elsewhere on the board
/FPGA/UROM1.CE_N: R97.1; also elsewhere on the board
/FPGA/UROM1.HOLD_N: R120.2, U20.7 (~HOLD/~RESET(IO3)); also elsewhere on the board
/FPGA/UROM1.SCK: R101.1; also elsewhere on the board
/FPGA/UROM1.SI: R100.1; also elsewhere on the board
/FPGA/UROM1.SO: R98.1; also elsewhere on the board
/FPGA/UROM1.WP_N: R99.1; also elsewhere on the board
/FPGA/memory/ROM0.CE_N: R92.2, R121.1, U19.1 (~CE)
/FPGA/memory/ROM0.SCK: R96.2, U19.6 (SCK)
/FPGA/memory/ROM0.SI: R95.2, U19.5 (SI(IO0))
/FPGA/memory/ROM0.SO: R93.2, U19.2 (SO(IO1))
/FPGA/memory/ROM0.WP_N: R94.2, R122.1, U19.3 (~WP(IO2))
/FPGA/memory/ROM1.CE_N: R97.2, R124.1, U20.1 (~CE)
/FPGA/memory/ROM1.SCK: R101.2, U20.6 (SCK)
/FPGA/memory/ROM1.SI: R100.2, U20.5 (SI(IO0))
/FPGA/memory/ROM1.SO: R98.2, U20.2 (SO(IO1))
/FPGA/memory/ROM1.WP_N: R99.2, R125.1, U20.3 (~WP(IO2))
GND: C58.2, C59.2, C60.2, C61.2, C62.2, C63.2, C64.2, C65.2, C66.2, C67.2, U15.12 (GND), U15.34 (GND), U16.12 (GND), U16.34 (GND), U17.12 (GND), U17.34 (GND), U18.12 (GND), U18.34 (GND), U19.4 (GND), U20.4 (GND); also elsewhere on the board

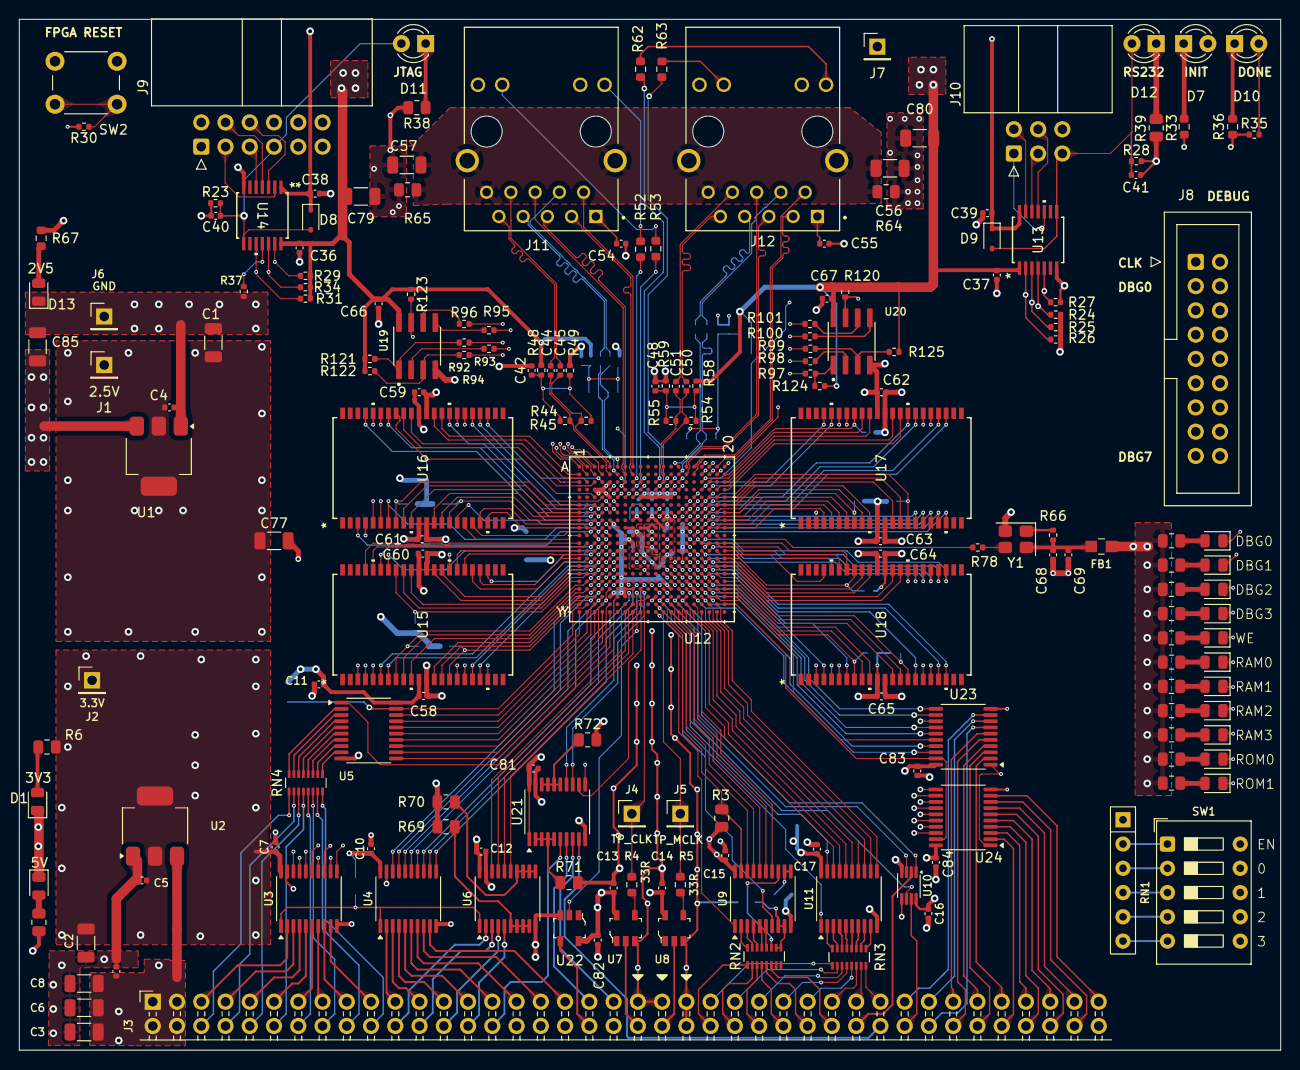
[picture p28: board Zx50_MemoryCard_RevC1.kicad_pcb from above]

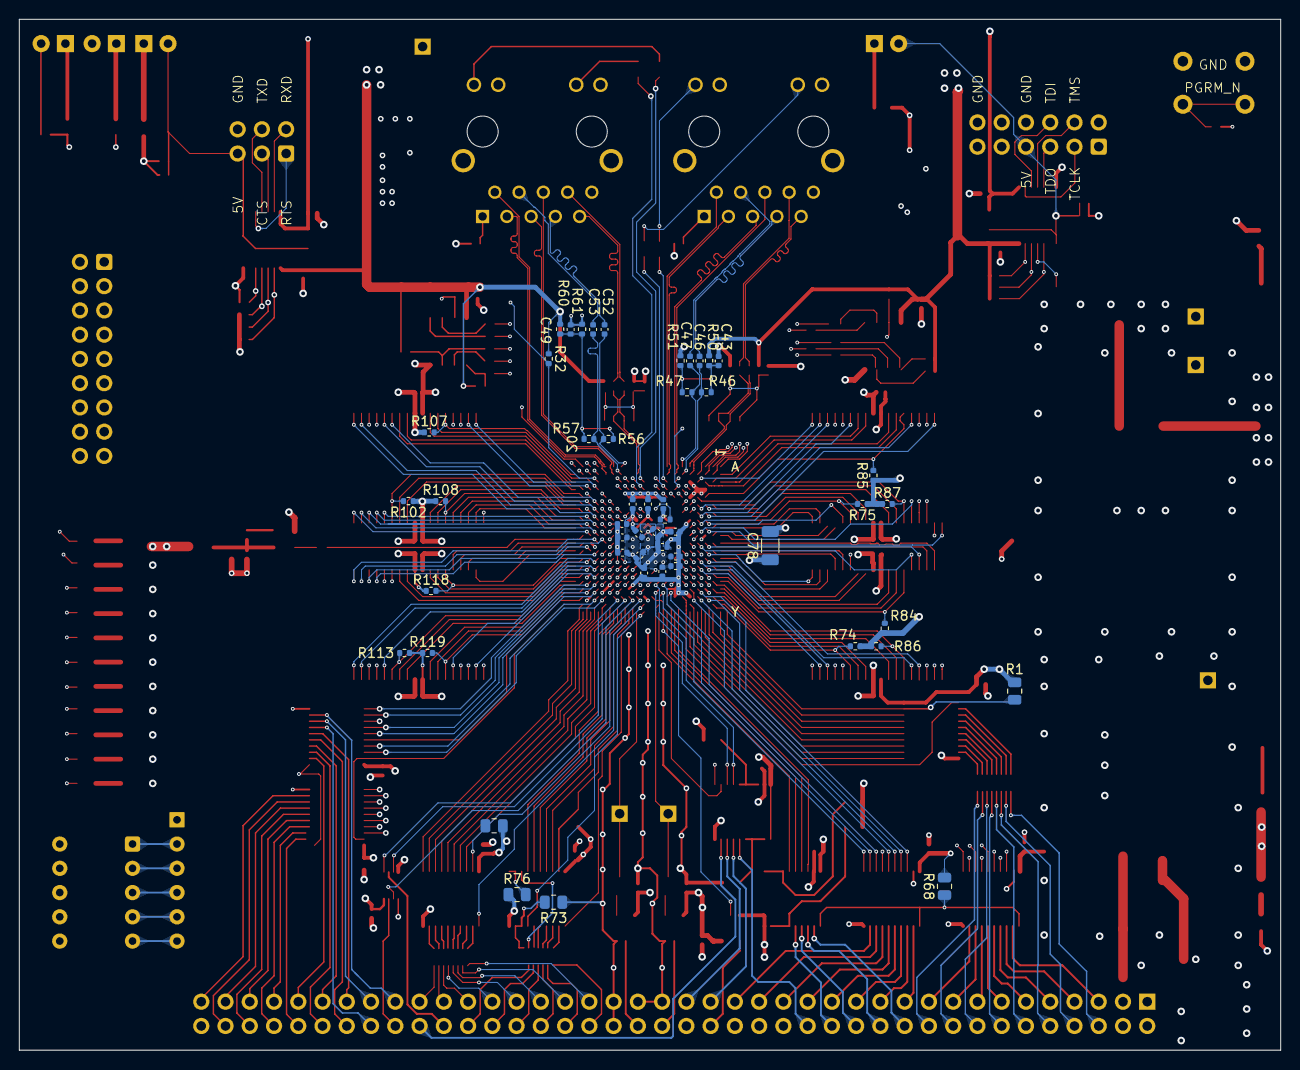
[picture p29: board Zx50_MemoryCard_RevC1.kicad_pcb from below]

Board: 6 copper layers, 132.1 x 107.9 mm, 235 parts (49 on the bottom side), 433 nets.

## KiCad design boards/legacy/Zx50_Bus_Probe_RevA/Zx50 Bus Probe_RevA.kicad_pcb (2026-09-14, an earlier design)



Board: 4 copper layers, 222.1 x 158.1 mm, 72 parts (7 on the bottom side), 154 nets.

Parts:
A1: RaspberryPi_Pico; RaspberryPi_Pico_Common_Unspecified
C1, C2, C3, C4, C5, C6, C7, C8, C9, C10, C11, C12, C13, C14, C15, C16, C17, C18, C19, C20: .1uF; C_Disc_D5.0mm_W2.5mm_P2.50mm
C21: 10uF; CP_Radial_Tantal_D5.0mm_P2.50mm
D1: MCLK; LED_D5.0mm_Horizontal_O1.27mm_Z3.0mm
D2: CLK; LED_D5.0mm_Horizontal_O1.27mm_Z3.0mm
D3: PWR; LED_D5.0mm_Horizontal_O1.27mm_Z3.0mm
J1: Zx50_EdgeConnector; PinSocket_2x40_P2.54mm_Horizontal_Edge
J2: OUT; BNC_Amphenol_B6252HB-NPP3G-50_Horizontal
J3: IN; BNC_Amphenol_B6252HB-NPP3G-50_Horizontal
J4: PIC PGM; PinHeader_1x06_P2.54mm_Horizontal_EDGE
J5: P0; PinHeader_1x03_P2.54mm_Vertical
J6: P1; PinHeader_1x03_P2.54mm_Vertical
J7: P2; PinHeader_1x03_P2.54mm_Vertical
J8: Send/Recv Card; IDC-Header_2x05_P2.54mm_Horizontal_Edge
J9: CH0; PinHeader_1x03_P2.54mm_Vertical
J10: CH1; PinHeader_1x03_P2.54mm_Vertical
J11: CH2; PinHeader_1x03_P2.54mm_Vertical
J12: CH3; PinHeader_1x03_P2.54mm_Vertical
J15: Z80_Addr; PinHeader_2x16_P2.54mm_Vertical_Row_Letter_Last
J16: Z80_Data; PinHeader_2x08_P2.54mm_Vertical_Row_Letter_Last
J17: Z80_Ctrl; PinHeader_2x08_P2.54mm_Vertical_Row_Letter_Last
J18: Clock; PinHeader_2x02_P2.54mm_Vertical_Row_Letter_Last
J19: SH_Data; PinHeader_2x08_P2.54mm_Vertical_Row_Letter_Last
J20: SH_Ctrl; PinHeader_2x08_P2.54mm_Vertical_Row_Letter_Last
LCD1: EA 205G-4NLED; EA_DIG205G-4NLED
R1, R2: 49.9R 1W 1%; R_Axial_DIN0207_L6.3mm_D2.5mm_P10.16mm_Horizontal
R3: 10k; R_Axial_DIN0207_L6.3mm_D2.5mm_P10.16mm_Horizontal
R4: 10K; R_Axial_DIN0207_L6.3mm_D2.5mm_P10.16mm_Horizontal
R5: 2.2k; R_Axial_DIN0207_L6.3mm_D2.5mm_P10.16mm_Horizontal
R6: 3.3k; R_Axial_DIN0207_L6.3mm_D2.5mm_P10.16mm_Horizontal
R7, R8: 2.2K; R_Axial_DIN0207_L6.3mm_D2.5mm_P5.08mm_Vertical
R9: 470; R_Axial_DIN0207_L6.3mm_D2.5mm_P5.08mm_Vertical
R10: 33R; R_Axial_DIN0207_L6.3mm_D2.5mm_P5.08mm_Vertical
U1, U13: MCP23S17_SP; DIP-28_W7.62mm_Socket
U2, U3, U4, U5, U8, U9, U10, U11, U12: CD74HC4051E; DIP-16_W7.62mm_Socket
U6, U7: SN74ABT245BN; DIP-20_W7.62mm_Socket
U14: CD74HC154M96; SOIC-24W_7.5x15.4mm_P1.27mm
U15, U16: OPA356xxD; SOIC-8_3.9x4.9mm_P1.27mm
U17: PIC18F4620-I_P; DIP-40_W15.24mm_Socket
U18: 74AHCT541; DIP-20_W7.62mm_Socket

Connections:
+5V: C1.1, C2.1, C3.1, C4.1, C5.2, C6.1, C7.2, C8.2, C9.2, C10.2, C11.1, C12.1, C13.2, C14.2, C15.2, C16.2, C17.2, C18.1, C19.1, C20.2, C21.1, J1.1 (+5V), J1.2 (+5V), J1.3 (+5V), J1.4 (+5V), J4.2, R3.1, R4.2, R9.1, R10.2, U1.9 (VDD), U2.16 (VCC), U3.16 (VCC), U4.16 (VCC), U5.16 (VCC), U6.20 (VCC), U7.20 (VCC), U8.16 (VCC), U9.16 (VCC), U10.16 (VCC), U11.16 (VCC), U12.16 (VCC), U13.9 (VDD), U13.15 (A0), U14.24 (VCC), U15.7 (V+), U16.7 (V+), U17.11 (VDD), U17.32 (VDD__1), U18.20 (VCC)
/3V3_DISPL: A1.36 (3V3), LCD1.2 (3V3)
/A0: J1.5 (A0), J15.1b, U1.1 (GPB0), U4.13 (A0)
/A1: J1.7 (A1), J15.2b, U1.2 (GPB1), U4.14 (A1)
/A2: J1.9 (A2), J15.3b, U1.3 (GPB2), U4.15 (A2)
/A3: J1.11 (A3), J15.4b, U1.4 (GPB3), U4.12 (A3)
/A4: J1.13 (A4), J15.5b, U1.5 (GPB4), U4.1 (A4)
/A5: J1.15 (A5), J15.6b, U1.6 (GPB5), U4.5 (A5)
/A6: J1.17 (A6), J15.7b, U1.7 (GPB6), U4.2 (A6)
/A7: J1.19 (A7), J15.8b, U1.8 (GPB7), U4.4 (A7)
/A8: J1.21 (A8), J15.9b, U1.21 (GPA0), U5.13 (A0)
/A9: J1.23 (A9), J15.10b, U1.22 (GPA1), U5.14 (A1)
/A10: J1.25 (A10), J15.11b, U1.23 (GPA2), U5.15 (A2)
/A11: J1.27 (A11), J15.12b, U1.24 (GPA3), U5.12 (A3)
/A12: J1.29 (A12), J15.13b, U1.25 (GPA4), U5.1 (A4)
/A13: J1.31 (A13), J15.14b, U1.26 (GPA5), U5.5 (A5)
/A14: J1.33 (A14), J15.15b, U1.27 (GPA6), U5.2 (A6)
/A15: J1.35 (A15), J15.16b, U1.28 (GPA7), U5.4 (A7)
/AN: U2.3 (A), U3.3 (A), U4.3 (A), U5.3 (A), U8.3 (A), U9.3 (A), U10.3 (A), U11.3 (A), U12.3 (A), U15.3 (+), U16.2 (-), U16.6
/AUX: J1.80 (AUX), R4.1, U17.15 (RC0/T1OSO/T13CKI)
/BK_LGT: LCD1.17 (LED_A), R10.1
/CHIP0: U14.23 (A0), U18.17 (Y1)
/CHIP1: U14.22 (A1), U18.16 (Y2)
/CHIP2: U14.21 (A2), U18.15 (Y3)
/CHIP3: U14.20 (A3), U18.14 (Y4)
/CLK: J1.42 (CLK), J18.1b, R8.1, U9.15 (A2), U17.17 (RC2/CCP1/P1A)
/D0: J1.6 (D0), J16.1b, U3.13 (A0), U6.2 (A1)
/D1: J1.8 (D1), J16.2b, U3.14 (A1), U6.3 (A2)
/D2: J1.10 (D2), J16.3b, U3.15 (A2), U6.4 (A3)
/D3: J1.12 (D3), J16.4b, U3.12 (A3), U6.5 (A4)
/D4: J1.14 (D4), J16.5b, U3.1 (A4), U6.6 (A5)
/D5: J1.16 (D5), J16.6b, U3.5 (A5), U6.7 (A6)
/D6: J1.18 (D6), J16.7b, U3.2 (A6), U6.8 (A7)
/D7: J1.20 (D7), J16.8b, U3.4 (A7), U6.9 (A8)
/DISP_CS: A1.22 (GPIO17), LCD1.4 (CS)
/G0: J1.63 (GPIO0), U11.13 (A0)
/G1: J1.65 (GPIO1), U11.14 (A1)
/G2: J1.66 (GPIO2), U11.15 (A2)
/G3: J1.67 (GPIO3), U11.12 (A3)
/G4: J1.68 (GPIO4), U11.1 (A4)
/G5: J1.69 (GPIO5), U11.5 (A5)
/G6: J1.70 (GPIO6), U11.2 (A6)
/G7: J1.71 (GPIO7), U11.4 (A7)
/G8: J1.72 (GPIO8), U12.13 (A0)
/G9: J1.73 (GPIO9), U12.14 (A1)
/G10: J1.74 (GPIO10), U12.15 (A2)
/G11: J1.75 (GPIO11), U12.12 (A3)
/G12: J1.76 (GPIO12), U12.1 (A4)
/G13: J1.77 (GPIO13), U12.5 (A5)
/G14: J1.78 (GPIO14), U12.2 (A6)
/G15: J1.79 (GPIO15), U12.4 (A7)
/IEI: J1.37 (IEI), U8.5 (A5)
/IEO: J1.38 (IEO), U9.13 (A0)
/MCLK: J1.44 (MCLK), J18.2b, R7.1, U9.12 (A3), U17.16 (RC1/T1OSI/CCP2)
/MCLR_N: J4.1, R3.2, U17.1 (~MCLR/VPP/RE3)
/PGC: J4.5, U17.39 (RB6/KBI2/PGC)
/PGD: J4.4, U17.40 (RB7/KBI3/PGD)
/PORT0: U2.11 (S0), U3.11 (S0), U4.11 (S0), U5.11 (S0), U8.11 (S0), U9.11 (S0), U10.11 (S0), U11.11 (S0), U12.11 (S0), U18.13 (Y5)
/PORT1: U2.10 (S1), U3.10 (S1), U4.10 (S1), U5.10 (S1), U8.10 (S1), U9.10 (S1), U10.10 (S1), U11.10 (S1), U12.10 (S1), U18.12 (Y6)
/PORT2: U2.9 (S2), U3.9 (S2), U4.9 (S2), U5.9 (S2), U8.9 (S2), U9.9 (S2), U10.9 (S2), U11.9 (S2), U12.9 (S2), U18.11 (Y7)
/RA0: U7.19 (*OE), U17.2 (RA0/AN0)
/RA1: U7.1 (DIR), U17.3 (RA1/AN1)
/RA2: U6.19 (*OE), U17.4 (RA2/AN2/VREF-/CVREF)
/RA3: U6.1 (DIR), U17.5 (RA3/AN3/VREF+)
/RA4: U1.18 (~RESET), U13.18 (~RESET), U17.6 (RA4/T0CKI/C1OUT)
/RA5: U1.11 (~CS), U13.11 (~CS), U17.7 (RA5/AN4/~SS/HLVDIN/C2OUT)
/RB3: U7.16 (B3), U17.36 (RB3/AN9/CCP2)
/RB4: U7.15 (B4), U17.37 (RB4/KBI0/AN11)
/RB5: J4.6, U7.18 (B1), U17.38 (RB5/KBI1/PGM)
/RD0: U6.18 (B1), U17.19 (RD0/PSP0)
/RD1: U6.17 (B2), U17.20 (RD1/PSP1)
/RD2: U6.16 (B3), U17.21 (RD2/PSP2)
/RD3: U6.15 (B4), U17.22 (RD3/PSP3)
/RD4: U6.14 (B5), U17.27 (RD4/PSP4)
/RD5: U6.13 (B6), U17.28 (RD5/PSP5/P1B)
/RD6: U6.12 (B7), U17.29 (RD6/PSP6/P1C)
/RD7: U6.11 (B8), U17.30 (RD7/PSP7/P1D)
/RE0: U7.17 (B2), U17.8 (RE0/~RD/AN5)
/RE1: U7.14 (B5), U17.9 (RE1/~WR/AN6)
/RE2: U7.13 (B6), U17.10 (RE2/~CS/AN7)
/RX: U17.26 (RC7/RX/DT), U18.18 (Y0)
/SCK: U1.12 (SCK), U13.12 (SCK), U17.18 (RC3/SCK/SCL)
/SD0: J1.47 (SD0), J19.1b, U10.13 (A0), U13.1 (GPB0)
/SD1: J1.49 (SD1), J19.2b, U10.14 (A1), U13.2 (GPB1)
/SD2: J1.51 (SD2), J19.3b, U10.15 (A2), U13.3 (GPB2)
/SD3: J1.53 (SD3), J19.4b, U10.12 (A3), U13.4 (GPB3)
/SD4: J1.55 (SD4), J19.5b, U10.1 (A4), U13.5 (GPB4)
/SD5: J1.57 (SD5), J19.6b, U10.5 (A5), U13.6 (GPB5)
/SD6: J1.59 (SD6), J19.7b, U10.2 (A6), U13.7 (GPB6)
/SD7: J1.61 (SD7), J19.8b, U10.4 (A7), U13.8 (GPB7)
/SDI: U1.14 (SO), U13.14 (SO), U17.23 (RC4/SDI/SDA)
/SDO: U1.13 (SI), U13.13 (SI), U17.24 (RC5/SDO)
/SEL0: U3.6 (~E), U14.1 (S0)
/SEL1: U2.6 (~E), U14.2 (S1)
/SEL2: U9.6 (~E), U14.3 (S2)
/SEL3: U8.6 (~E), U14.4 (S3)
/SEL4: U4.6 (~E), U14.5 (S4)
/SEL5: U5.6 (~E), U14.6 (S5)
/SEL6: U10.6 (~E), U14.7 (S6)
/SEL7: U11.6 (~E), U14.8 (S7)
/SEL8: U12.6 (~E), U14.9 (S8)
/SH_RW: J1.54 (SRW), J20.4b, U9.4 (A7), U13.24 (GPA3)
/SPI_SCK: A1.24 (GPIO18), LCD1.6 (CLK)
/SPI_TX: A1.25 (GPIO19), LCD1.5 (MOSI)
/TX: R5.2, U17.25 (RC6/TX/CK)
/~BUSAK~: J1.62 (~BUSAK~), U8.12 (A3)
/~BUSRQ~: J1.60 (~BUSRQ~), U8.15 (A2)
/~HALT~: J1.40 (~HALT~), U9.14 (A1)
/~INT~: J1.64 (~INT~), J17.8b, U8.1 (A4), U17.33 (RB0/INT0/FLT0/AN12)
/~IORQ~: J1.28 (~IORQ~), J17.4b, U2.12 (A3), U7.5 (A4)
/~M1~: J1.30 (~M1~), J17.5b, U2.1 (A4), U7.6 (A5)
/~MREQ~: J1.26 (~MREQ~), J17.3b, U2.15 (A2), U7.4 (A3)
/~NMI~: J1.36 (~NMI~), U2.4 (A7)
/~RD~: J1.22 (~RD~), J17.1b, U2.13 (A0), U7.2 (A1)
/~RESET~: J1.39 (~RESET~), J17.7b, U7.7 (A6), U8.2 (A6)
/~RFSH~: J1.32 (~RFSH~), U2.5 (A5)
/~SH_BUSY~: J1.58 (~S_BUSY~), J20.6b, U8.14 (A1), U13.26 (GPA5), U17.35 (RB2/INT2/AN8)
/~SH_DONE~: J1.56 (~S_DONE~), J20.5b, U8.13 (A0), U13.25 (GPA4)
/~SH_EN~: J1.52 (~S_EN~), J20.1b, U9.2 (A6), U13.23 (GPA2)
/~SH_INC~: J1.50 (~SINC~), J20.3b, U9.5 (A5), U13.22 (GPA1)
/~SH_STB~: J1.48 (~SSTB~), J20.2b, U9.1 (A4), U13.21 (GPA0)
/~WAIT~: J1.34 (~WAIT~), J17.6b, U2.2 (A6), U17.34 (RB1/INT1/AN10)
/~WR~: J1.24 (~WR~), J17.2b, U2.14 (A1), U7.3 (A2)
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

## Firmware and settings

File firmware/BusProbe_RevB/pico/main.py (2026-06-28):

import select
import sys
import os
import time

import display
from bus import BusController
from pic18_link import PIC18Link

# --- CONFIGURATION ---
APP_VERSION = "RevB-0.5.1"
USE_WIFI = True  # Set to False to drop back to purely USB Serial
TCP_PORT = 5050  # Port for the laptop host script to connect to


class Zx50Console:
    """A lightweight line-processing CLI for MicroPython with optional TCP Socket Server."""

    def __init__(self):
        # Default to True to lock out booting by default
        self.cpu_card_installed = True
        self.pic = PIC18Link(uart_id=0, tx_gpio=0, rx_gpio=1)
        self.bus = BusController()

        self.poll_obj = select.poll()
        self.poll_obj.register(sys.stdin, select.POLLIN)
        self.prompt = "Zx50> "

        # Network state
        self.pico_ip = "127.0.0.1"
        self.server_sock = None
        self.client_sock = None
        self.client_buffer = ""

        if USE_WIFI:
            self._setup_wifi()

    def _get_banner(self):
        """Generates the welcome banner for both USB and TCP clients."""
        mpy_build = os.uname().version
        board_hw = os.uname().machine
        banner = "\n==================================================\n"
        banner += f" Zx50 Bus Probe - Interactive Terminal\n"
        banner += f" Firmware: {APP_VERSION}\n"
        banner += f" Hardware: {board_hw}\n"
        banner += f" Core:     MicroPython {mpy_build}\n"
        if self.server_sock:
            banner += f" Network:  TCP {self.pico_ip}:{TCP_PORT}\n"
        banner += "==================================================\n"
        banner += "Type 'help' for a list of commands.\n"
        return banner

    def _setup_wifi(self):
        """Connects to Wi-Fi and starts a non-blocking TCP server."""
        import network
        import socket
        try:
            import secrets
        except ImportError:
            display.update("NETWORK ERROR", "secrets.py missing!", "Falling back to USB")
            print("ERR: secrets.py not found. Network disabled.")
            return

        display.update("BOOTING...", "Connecting Wi-Fi...", secrets.WIFI['ssid'][:20])

        wlan = network.WLAN(network.STA_IF)
        wlan.active(True)
        wlan.connect(secrets.WIFI['ssid'], secrets.WIFI['password'])

        max_wait = 15
        while max_wait > 0:
            if wlan.status() < 0 or wlan.status() >= 3:
                break
            max_wait -= 1
            time.sleep(1)

        if wlan.status() != 3:
            display.update("NETWORK ERROR", "Failed to connect.", "Check secrets.py")
            print("ERR: Network connection failed.")
            return

        self.pico_ip = wlan.ifconfig()[0]
        print(f"Wi-Fi Connected! IP: {self.pico_ip}")

        # Setup non-blocking TCP Server
        self.server_sock = socket.socket(socket.AF_INET, socket.SOCK_STREAM)
        self.server_sock.setsockopt(socket.SOL_SOCKET, socket.SO_REUSEADDR, 1)
        self.server_sock.bind(('', TCP_PORT))
        self.server_sock.listen(1)
        self.server_sock.setblocking(False)

    def _close_client(self, reason):
        """Safely closes the active client and resets state so accept() can run again."""
        if self.client_sock:
            try:
                self.client_sock.close()
            except:
                pass
            self.client_sock = None
            self.client_buffer = ""
            print(f"\n[TCP Client {reason}]")
            # Restore the prompt to the USB serial terminal
            sys.stdout.write(self.prompt)

    def _check_tcp_client(self):
        """Non-blocking check for new connections or incoming TCP data."""
        if not self.server_sock:
            return

        # 1. Accept new clients only if the previous one is cleared
        if not self.client_sock:
            try:
                self.client_sock, addr = self.server_sock.accept()
                self.client_sock.setblocking(False)
                print(f"\n[TCP Client Connected: {addr[0]}]")

                # Push the welcome banner and prompt to the new client
                welcome_msg = self._get_banner() + "\n" + self.prompt
                self.client_sock.send(welcome_msg.encode('utf-8'))
            except OSError:
                pass  # No new connection pending

        # 2. Read from existing client
        if self.client_sock:
            try:
                data = self.client_sock.recv(1024)
                if data:
                    self.client_buffer += data.decode('utf-8')
                    if '\n' in self.client_buffer:
                        lines = self.client_buffer.split('\n')
                        for line in lines[:-1]:
                            clean_line = line.strip()
                            if clean_line:
                                self._execute(clean_line, is_tcp=True)

                            # Re-verify client exists before sending the prompt back
                            if self.client_sock:
                                try:
                                    self.client_sock.send(self.prompt.encode('utf-8'))
                                except OSError:
                                    pass

                        self.client_buffer = lines[-1]
                else:
                    # Received 0 bytes: The peer has performed an orderly shutdown
                    self._close_client("Disconnected (EOF)")
            except OSError as e:
                # 11 is EAGAIN/EWOULDBLOCK, which is normal for non-blocking recv
                if e.args[0] != 11:
                    self._close_client(f"Connection Error ({e.args[0]})")

    def cmdloop(self):
        """Standard line-processing REPL loop handling both USB and TCP."""
        sys.stdout.write(self._get_banner() + "\n" + self.prompt)

        comm_mode = f"Wi-Fi: {self.pico_ip}" if self.server_sock else "USB Serial Active"
        display.update("IDLE", comm_mode, f"TX: None  RX: None")

        while True:
            self._check_tcp_client()

            poll_res = self.poll_obj.poll(10)
            if poll_res:
                line = sys.stdin.readline().strip()
                if line:
                    self._execute(line, is_tcp=False)
                sys.stdout.write(self.prompt)

    def _send_response(self, response, is_tcp):
        """Routes the output string back to the requestor."""
        out_str = response.strip() + "\n"
        print(response)

        if is_tcp and self.client_sock:
            try:
                self.client_sock.send(out_str.encode('utf-8'))
            except OSError:
                # If we fail to send, the socket is likely broken; clean it up next loop
                pass

    def _execute(self, line, is_tcp=False):
        """Uses reflection to route commands to the correct do_method."""
        parts = line.split()
        if not parts:
            return

        cmd = parts[0].lower()
        args = parts[1:]

        if cmd == "idn?":
            self.do_idn(args, is_tcp)
            return

        if cmd in ("bye", "exit", "quit"):
            if is_tcp and self.client_sock:
                try:
                    self.client_sock.send("OK BYE\n".encode('utf-8'))
                except OSError:
                    pass
                self._close_client("Disconnected via Command")
            else:
                print("OK (USB session remains active)")
            return

        func = getattr(self, f"do_{cmd}", self.default)
        func(args, is_tcp)

    # ==========================================
    # CLI COMMAND DEFINITIONS
    # ==========================================
    def default(self, args, is_tcp):
        self._send_response("ERR UNKNOWN_COMMAND. Type 'help' for a list of commands.", is_tcp)

    def do_help(self, args, is_tcp):
        resp = "Available Subsystems & Commands:\n"
        resp += "  pic   - Commands for the PIC18F4620 Z80 Controller\n"
        resp += "  bus   - Commands for the Multiplexer routing\n"
        resp += "  z80   - Run custom scripts (e.g. 'z80 run myscript')\n"
        resp += "  cpu   - Set CPU presence lock (e.g. 'cpu in' or 'cpu out')\n"
        resp += "  boot  - Safely boot the system (Requires 'cpu out')\n"
        resp += "  idn?  - Get device identity\n"
        resp += "Type 'pic help' or 'bus help' for subsystem commands."
        self._send_response(resp, is_tcp)

    def do_z80(self, args, is_tcp):
        """Dynamically loads and runs a python script stored on the Pico."""
        if not args or args[0].upper() != "RUN":
            self._send_response("ERR SYNTAX_Z80_RUN. Usage: 'z80 run <script_name>'", is_tcp)
            return

        # Default to z80_program.py if no name is provided
        script_name = args[1] if len(args) > 1 else "z80_program"

        # Strip .py if the user accidentally typed it
        if script_name.endswith('.py'):
            script_name = script_name[:-3]

        try:
            # FORCE RELOAD: Remove the module from memory if it was previously loaded.
            # This allows you to `mpremote cp` a new version and run it without rebooting!
            if script_name in sys.modules:
                del sys.modules[script_name]

            # Dynamically import the script
            z80_script = __import__(script_name)

            # Ensure the script has a run() function
            if hasattr(z80_script, 'run'):
                self._send_response(f"OK RUNNING {script_name}.py...", is_tcp)

                # Execute the script, passing the hardware controllers to it
                try:
                    # Create a sender function that captures the current context (is_tcp)
                    output_func = lambda msg: self._send_response(msg, is_tcp)
                    
                    try:
                        # Try calling the new version of run() with the output function
                        result = z80_script.run(self.pic, self.bus, output_func)
                    except TypeError as e:
                        # Fallback for older scripts that don't accept an output function
                        self._send_response(f"WARN: script error: {e}.", is_tcp)
                        result = z80_script.run(self.pic, self.bus)

                    self._send_response(f"OK DONE. Result: {result}", is_tcp)
                except Exception as e:
                    self._send_response(f"ERR RUNNING {script_name}: {e}", is_tcp)
                    return
            else:
                self._send_response(f"ERR NO_RUN_FUNCTION_IN_{script_name}.py", is_tcp)

        except ImportError:
            self._send_response(f"ERR FILE_NOT_FOUND: {script_name}.py", is_tcp)
        except Exception as e:
            # Catch crashes in the custom script so the CLI doesn't die
            self._send_response(f"ERR SCRIPT_EXCEPTION: {e}", is_tcp)

    def do_idn(self, args, is_tcp):
        self._send_response(f"OK Zx50_PROBE_REVB firmware {APP_VERSION} TCP {self.pico_ip}:{TCP_PORT}", is_tcp)

    def do_pic(self, args, is_tcp):
        if not args:
            args = ["help"]
        response = self.pic.handle_command(args)
        self._send_response(response, is_tcp)

    def do_bus(self, args, is_tcp):
        if not args:
            args = ["help"]
        response = self.bus.handle_command(args)
        self._send_response(response, is_tcp)

        if "OK" in response and args and args[0].upper() in ["SELECT", "GHOST"]:
            display.update("ROUTING ACTIVE", f"TX: {self.bus.current_tx_str}", f"RX: {self.bus.current_rx_str}")

    def do_cpu(self, args, is_tcp):
        """Toggles the CPU presence safety lock."""
        if not args:
            state = "INSTALLED (Boot Locked)" if self.cpu_card_installed else "REMOVED (Boot Permitted)"
            self._send_response(f"OK CPU_CARD_STATE: {state}", is_tcp)
            return

        arg = args[0].upper()
        if arg in ["IN", "INSTALLED", "1", "TRUE"]:
            self.cpu_card_installed = True
            self._send_response("OK CPU_CARD_INSTALLED=TRUE. Boot sequence locked out.", is_tcp)
        elif arg in ["OUT", "REMOVED", "0", "FALSE"]:
            self.cpu_card_installed = False
            self._send_response("OK CPU_CARD_INSTALLED=FALSE. Boot sequence permitted.", is_tcp)
        else:
            self._send_response("ERR INVALID_ARG. Use 'cpu in' or 'cpu out'.", is_tcp)

    def do_boot(self, args, is_tcp):
        """Safely executes a system boot if the CPU card is removed."""
        if self.cpu_card_installed:
            self._send_response("ERR BOOT_BLOCKED: CPU Card is installed! Hardware conflict prevented.", is_tcp)
            return

        self._send_response("OK CPU Card not detected. Initiating Boot Sequence...", is_tcp)

        # 1. Turn on the free-running PWM clocks (since the CPU/Mezzanine is missing)
        self.pic.handle_command(["clk", "auto"])
        time.sleep(0.1)  # Give the clock a moment to stabilize on the bus

        # 2. Fire the boot reset pulse sequence
        resp = self.pic.handle_command(["boot"])

        if "OK" in resp:
            self._send_response("OK BOOT COMPLETE. System clock is running.", is_tcp)
        else:
            self._send_response(f"ERR BOOT_FAILED: {resp}", is_tcp)

def main():
    display.init()
    console = Zx50Console()
    console.cmdloop()


if __name__ == '__main__':
    main()

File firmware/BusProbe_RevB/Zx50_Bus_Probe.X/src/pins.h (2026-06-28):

/* * File:   pins.h
 * Author: Marc Mosko
 * Description: Hardware Abstraction Layer for Zx50 Bus Probe Rev B.
 */

#ifndef PINS_H
#define	PINS_H

#include <xc.h>

// ==========================================
// PIC18F27Q43 Direct Pin Definitions
// ==========================================

// --- SPI Bus to I/O Expanders ---
#define SPI_SCK_DIR         TRISCbits.TRISC3
#define SPI_SDO_DIR         TRISCbits.TRISC5
#define SPI_SDI_DIR         TRISCbits.TRISC4

// --- Expander SPI Chip Select (Shared) ---
#define EXP_CS_DIR          TRISAbits.TRISA5
#define EXP_CS_LAT          LATAbits.LATA5

// --- Expander Reset (Shared) ---
#define EXP_RESET_DIR       TRISAbits.TRISA4
#define EXP_RESET_LAT       LATAbits.LATA4

// --- Transceiver Controls (74ABT245) ---
// Data Bus Transceiver (U6)
#define DATA_XCVR_OE_DIR    TRISAbits.TRISA0
#define DATA_XCVR_OE_LAT    LATAbits.LATA0
#define DATA_XCVR_DIR_DIR   TRISAbits.TRISA1
#define DATA_XCVR_DIR_LAT   LATAbits.LATA1

// Address & Control Bus Transceivers (U7, U17, U19)
#define ADDR_XCVR_OE_DIR    TRISAbits.TRISA2
#define ADDR_XCVR_OE_LAT    LATAbits.LATA2
#define ADDR_XCVR_DIR_DIR   TRISAbits.TRISA3
#define ADDR_XCVR_DIR_LAT   LATAbits.LATA3

// Shadow Bus Transceivers (U22, U23)
#define SHADOW_XCVR_OE_DIR  TRISAbits.TRISA6
#define SHADOW_XCVR_OE_LAT  LATAbits.LATA6
#define SHADOW_XCVR_DIR_DIR TRISAbits.TRISA7
#define SHADOW_XCVR_DIR_LAT LATAbits.LATA7

// --- Communication with Raspberry Pi Pico ---
#define PICO_TX_DIR         TRISCbits.TRISC6 
#define PICO_RX_DIR         TRISCbits.TRISC7 
#define PICO_INT_DIR        TRISCbits.TRISC0 
#define PICO_INT_LAT        LATCbits.LATC0

// --- Z80 Bus Control (Directly from PIC) ---
#define Z80_BUSRQ_DIR       TRISBbits.TRISB3
#define Z80_BUSRQ_LAT       LATBbits.LATB3

#define Z80_WAIT_DIR        TRISBbits.TRISB1
#define Z80_WAIT_LAT        LATBbits.LATB1
#define Z80_WAIT_VAL        PORTBbits.RB1

#define Z80_INT_DIR         TRISBbits.TRISB0
#define Z80_INT_LAT         LATBbits.LATB0
#define Z80_INT_VAL         PORTBbits.RB0

#define AUX_PIN_VAL         PORTBbits.RB4

// --- Clock Generation ---
#define Z80_CLK_DIR         TRISCbits.TRISC1 
#define Z80_CLK_LAT         LATCbits.LATC1
#define Z80_MCLK_DIR        TRISCbits.TRISC2 
#define Z80_MCLK_LAT        LATCbits.LATC2

// --- Programming Pins ---
#define PGC_DIR             TRISBbits.TRISB6
#define PGD_DIR             TRISBbits.TRISB7
#define MCLR_PIN            RE3

// ==========================================
// MCP23S17 I/O Expander Register Mapping
// ==========================================

// --- U1: Z80 Address Bus (A0-A15) ---
#define EXP_ADDR_PORTA      GPIOA
#define EXP_ADDR_PORTB      GPIOB

// --- U21: Z80 Data Bus (D0-D7) & Control Signals ---
#define EXP_DATA_PORTA      GPIOA
#define EXP_DATA_PORTB      GPIOB
#define Z80_RD_N_PIN        0 // GPB0
#define Z80_WR_N_PIN        1 // GPB1
#define Z80_MREQ_N_PIN      2 // GPB2
#define Z80_IORQ_N_PIN      3 // GPB3
#define Z80_M1_N_PIN        4 // GPB4
#define Z80_RESET_N_PIN     5 // GPB5
#define Z80_BUSAK_N_PIN     6 // GPB6
#define Z80_RFSH_N_PIN      7 // GPB7

// --- U13: Shadow Bus (SD0-SD7) & Control Signals ---
#define EXP_SHADOW_DATAPORT GPIOA
#define EXP_SHADOW_CTRLPORT GPIOB
#define SH_STB_N_PIN        0 // GPB0
#define SH_INC_N_PIN        1 // GPB1
#define SH_EN_N_PIN         2 // GPB2
#define SH_RW_PIN           3 // GPB3
#define SH_DONE_N_PIN       4 // GPB4
#define SH_BUSY_N_PIN       5 // GPB5

#endif	/* PINS_H */

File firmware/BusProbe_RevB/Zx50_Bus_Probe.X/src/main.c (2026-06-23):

/*
 * File:   main.c
 * Author: Marc Mosko
 *
 * Description: Main application for the Zx50 Bus Probe Rev B.
 */

// =========================================================================
// PIC18F27Q43 Configuration Bits
// =========================================================================
#pragma config FEXTOSC = OFF    // External Oscillator not used
#pragma config RSTOSC = HFINTOSC_64MHZ // Power-on default is 64MHz internal osc
#pragma config CLKOUTEN = OFF   // CLKOUT function is disabled
#pragma config CSWEN = ON       // Allow runtime clock switching
#pragma config FCMEN = ON       // Enable Fail-Safe Clock Monitor
#pragma config MCLRE = EXTMCLR  // Master Clear Enable, RE3 is MCLR
#pragma config LPBOREN = OFF    // Low-power BOR disabled
#pragma config BOREN = ON       // Brown-out Reset enabled
#pragma config BORV = VBOR_2P45 // Brown-out Reset Voltage (2.45V)
#pragma config ZCD = OFF        // Zero-cross detect disabled
#pragma config PPS1WAY = ON     // PPSLOCK may be set once and cleared once
#pragma config STVREN = ON      // Stack Full/Underflow will cause Reset
#pragma config XINST = OFF      // Extended Instruction Set disabled
#pragma config WDTE = OFF       // WDT disabled
#pragma config LVP = OFF        // Low-Voltage Programming disabled
#pragma config CP = OFF         // User NVM program memory code protection off
#pragma config MVECEN = OFF     // Disable Vectored Interrupts (Use legacy mode)

#include <xc.h>
#include <stdbool.h>
#include <stdint.h>
#include "hal.h"
#include "pins.h"
#include "z80_bus.h"
#include "clock.h"
#include "command_queue.h"
#include "cmd.h"
#include "wait.h"

#define DEBOUNCE_THRESHOLD 2500

// Tracks the clock mode so the AUX button knows if it should dispatch cycles
static uint8_t is_sync_clock_active = 0;

// ======
// Check the command queue for a DONE event.  If it exists, send the
// specified response code and optional data.
//
// This is used for both STATUS polls and async completion checks
// ======
static inline bool poll_event(uint8_t resp_code) {
    if (CQ_Get_Head_Status() == STAT_DONE) {
        // Push the completion byte
        UART_Write(resp_code);

        // Push data if it was a read command
        uint8_t read_data;
        if (CQ_Read_Head_Data(&read_data)) {
            UART_Write(read_data);
        }

        // Pop the queue so we don't spam the UART
        CQ_Pop_Head(); 
        return true;
    }
    
    return false;
}

// =========================================================================
// UART Packet Reader
// Has a timeout reading the 4 consecutive bytes, so if a byte is lost
// will not spin forever
// =========================================================================
static inline int read_uart(uint8_t packet[4]) {
    // Q43 uses INTCON0 for the Global Interrupt Enable
    INTCON0bits.GIE = 0;

    uint8_t sync_byte;
    if (UART_Read(&sync_byte) != 0 || sync_byte != SYNC_OK) {
        INTCON0bits.GIE = 1;
        return -1; // No valid packet start
    }

    // Block briefly to grab the 4 payload bytes
    for(int i = 0; i < 4; i++) {
        uint16_t timeout = 50000; // Safety timeout (~2-3 ms)
        while (UART_Read(&packet[i]) != 0) {
            if (--timeout == 0) {
                // Packet stalled or byte dropped! Abort gracefully.
                INTCON0bits.GIE = 1;
                return -1; 
            }
        }
    }

    INTCON0bits.GIE = 1;
    return 0; // Success
}

// =========================================================================
// Status & Polling
// =========================================================================
static inline void Send_Status_Response() {
    cmd_status_t status = CQ_Get_Head_Status();

    if (poll_event(RESP_DONE)) {
        // If we found a DONE, we're finished
        return;
    } else if (status == STAT_PROCESSING || status == STAT_PENDING) {
        UART_Write(RESP_PENDING);
    } else {
        UART_Write(RESP_IDLE);
    }
}

// =========================================================================
// Hardware Switch Debouncing
// =========================================================================
static inline void Process_Hardware_Inputs(uint8_t *debounced_aux, uint16_t *debounce_counter) {
    // Note: Ensure AUX_PIN_VAL is defined in pins.h as PORTBbits.RB4
    uint8_t raw_aux = AUX_PIN_VAL;

    if (raw_aux != *debounced_aux) {
        (*debounce_counter)++;
        if (*debounce_counter > DEBOUNCE_THRESHOLD) {
            *debounced_aux = raw_aux;
            *debounce_counter = 0;

            // Trigger on falling edge. Only dispatch if the auto-sync clock ISN'T running.
            if (*debounced_aux == 0 && !is_sync_clock_active) {
                CQ_Dispatch_Cycle();
            }
        }
    } else {
        *debounce_counter = 0;
    }
}
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

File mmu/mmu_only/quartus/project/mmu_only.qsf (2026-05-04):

# -------------------------------------------------------------------------- #
#
# Copyright (C) 1991-2013 Altera Corporation
# Your use of Altera Corporation's design tools, logic functions 
# and other software and tools, and its AMPP partner logic 
# functions, and any output files from any of the foregoing 
# (including device programming or simulation files), and any 
# associated documentation or information are expressly subject 
# to the terms and conditions of the Altera Program License 
# Subscription Agreement, Altera MegaCore Function License 
# Agreement, or other applicable license agreement, including, 
# without limitation, that your use is for the sole purpose of 
# programming logic devices manufactured by Altera and sold by 
# Altera or its authorized distributors.  Please refer to the 
# applicable agreement for further details.
#
# -------------------------------------------------------------------------- #
#
# Quartus II 64-Bit
# Version 13.0.1 Build 232 06/12/2013 Service Pack 1 SJ Web Edition
# Date created = 09:43:06  April 23, 2026
#
# -------------------------------------------------------------------------- #
#
# Notes:
#
# 1) The default values for assignments are stored in the file:
#		zx50_mmu_only_assignment_defaults.qdf
#    If this file doesn't exist, see file:
#		assignment_defaults.qdf
#
# 2) Altera recommends that you do not modify this file. This
#    file is updated automatically by the Quartus II software
#    and any changes you make may be lost or overwritten.
#
# -------------------------------------------------------------------------- #


set_global_assignment -name FAMILY MAX7000S
set_global_assignment -name DEVICE "EPM7128STC100-15"
set_global_assignment -name TOP_LEVEL_ENTITY zx50_mmu_only
set_global_assignment -name ORIGINAL_QUARTUS_VERSION "13.0 SP1"
set_global_assignment -name PROJECT_CREATION_TIME_DATE "09:43:06  APRIL 23, 2026"
set_global_assignment -name LAST_QUARTUS_VERSION "13.0 SP1"
set_global_assignment -name PROJECT_OUTPUT_DIRECTORY output_files
set_global_assignment -name DEVICE_FILTER_PIN_COUNT 100
set_global_assignment -name ERROR_CHECK_FREQUENCY_DIVISOR "-1"
set_global_assignment -name EDA_SIMULATION_TOOL "ModelSim-Altera (VHDL)"
set_global_assignment -name EDA_OUTPUT_DATA_FORMAT VHDL -section_id eda_simulation
set_global_assignment -name MAX7000_OPTIMIZATION_TECHNIQUE AREA
set_global_assignment -name SYNTH_TIMING_DRIVEN_SYNTHESIS OFF
set_global_assignment -name OPTIMIZE_HOLD_TIMING OFF
set_global_assignment -name OPTIMIZE_MULTI_CORNER_TIMING OFF
set_global_assignment -name FITTER_EFFORT "STANDARD FIT"


# Shatter rigid hard-macros so the Fitter can scatter logic to locked pins
set_global_assignment -name AUTO_CARRY_CHAINS OFF
set_global_assignment -name IGNORE_CARRY_BUFFERS ON
set_global_assignment -name IGNORE_CASCADE_BUFFERS ON

set_global_assignment -name SDC_FILE mmu_only.sdc
set_global_assignment -name VERILOG_FILE ../../git/Zx50/model_rev1/src/zx50_mmu_only.v


set_global_assignment -name MAX7000_DEVICE_IO_STANDARD TTL


# ==========================================
# VERIFIED KICAD PIN ASSIGNMENTS (U8 - ATF1508AS)
# ==========================================

# System Clocks & Control
set_location_assignment PIN_87 -to mclk
set_location_assignment PIN_90 -to zclk
set_location_assignment PIN_89 -to reset_n

# Z80 Backplane Control
set_location_assignment PIN_41 -to b_z80_m1_n
set_location_assignment PIN_96 -to int_n
set_location_assignment PIN_97 -to wait_n
set_location_assignment PIN_37 -to b_z80_mreq_n 
set_location_assignment PIN_40 -to b_z80_iorq_n
set_location_assignment PIN_33 -to b_z80_rd_n 
set_location_assignment PIN_35 -to b_z80_wr_n 

# Z80 Address Bus (A15 down to A0)
set_location_assignment PIN_21 -to z80_a[15]
set_location_assignment PIN_20 -to z80_a[14]
set_location_assignment PIN_19 -to z80_a[13]
set_location_assignment PIN_17 -to z80_a[12]
set_location_assignment PIN_16 -to z80_a[11]
set_location_assignment PIN_14 -to z80_a[10]
set_location_assignment PIN_13 -to z80_a[9]
set_location_assignment PIN_12 -to z80_a[8]
set_location_assignment PIN_10 -to z80_a[7]
set_location_assignment PIN_9 -to z80_a[6]
set_location_assignment PIN_8 -to z80_a[5]
set_location_assignment PIN_7 -to z80_a[4]
set_location_assignment PIN_6 -to z80_a[3]
set_location_assignment PIN_5 -to z80_a[2]
set_location_assignment PIN_2 -to z80_a[1]
set_location_assignment PIN_1 -to z80_a[0]

# Local Shared Data Bus (D7 down to D0)
set_location_assignment PIN_32 -to l_d[7]
set_location_assignment PIN_31 -to l_d[6]
set_location_assignment PIN_30 -to l_d[5]
set_location_assignment PIN_29 -to l_d[4]
set_location_assignment PIN_28 -to l_d[3]
set_location_assignment PIN_27 -to l_d[2]
set_location_assignment PIN_25 -to l_d[1]
set_location_assignment PIN_24 -to l_d[0]

# Shadow Bus Controls
set_location_assignment PIN_47 -to sh_en_n
set_location_assignment PIN_48 -to sh_rw_n
set_location_assignment PIN_46 -to sh_inc_n
set_location_assignment PIN_45 -to sh_stb_n
set_location_assignment PIN_49 -to sh_done_n
set_location_assignment PIN_50 -to sh_busy_n

# Transceiver Controls
set_location_assignment PIN_44 -to sh_c_dir
set_location_assignment PIN_23 -to z80_d_oe_n
set_location_assignment PIN_52 -to sh_data_oe_n
set_location_assignment PIN_22 -to d_dir

# Local Memory Address Bus (A10 down to A0)
set_location_assignment PIN_85 -to l_a[10]
set_location_assignment PIN_84 -to l_a[9]
set_location_assignment PIN_83 -to l_a[8]
set_location_assignment PIN_81 -to l_a[7]
set_location_assignment PIN_80 -to l_a[6]
set_location_assignment PIN_79 -to l_a[5]
set_location_assignment PIN_78 -to l_a[4]
set_location_assignment PIN_77 -to l_a[3]
set_location_assignment PIN_76 -to l_a[2]
set_location_assignment PIN_75 -to l_a[1]
set_location_assignment PIN_72 -to l_a[0]

# ATL Address Bus (A3 down to A0)
set_location_assignment PIN_56 -to atl_a[3]
set_location_assignment PIN_55 -to atl_a[2]
set_location_assignment PIN_54 -to atl_a[1]
set_location_assignment PIN_53 -to atl_a[0]

# ATL Data Bus (D7 down to D0)
set_location_assignment PIN_68 -to atl_d[7]
set_location_assignment PIN_67 -to atl_d[6]
set_location_assignment PIN_65 -to atl_d[5]
set_location_assignment PIN_64 -to atl_d[4]
set_location_assignment PIN_63 -to atl_d[3]
set_location_assignment PIN_61 -to atl_d[2]
set_location_assignment PIN_60 -to atl_d[1]
set_location_assignment PIN_58 -to atl_d[0]

# Memory Control Lines
set_location_assignment PIN_69 -to atl_we_n
set_location_assignment PIN_70 -to atl_oe_n
set_location_assignment PIN_71 -to atl_ce_n
set_location_assignment PIN_93 -to oe_n
set_location_assignment PIN_94 -to we_n

# CORRECTIONS FOR REV A HARDWARE:
set_location_assignment PIN_99 -to ram_ce0_n
set_location_assignment PIN_92 -to ram_ce1_n
set_location_assignment PIN_98 -to rom_ce2_n

set_location_assignment PIN_100 -to hb_led_n
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

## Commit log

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2026-03-14 Add cpu card start and missing files.
    [Zx50_Cpu.kicad_pcb, Zx50_Cpu.kicad_sch]
2026-03-14 final cpu schematic before pcb layout
    [Zx50_Cpu.kicad_sch]
2026-03-16 serial card
    [Zx50_Serial.kicad_pcb, Zx50_Serial.kicad_sch]
2026-03-17 reorg before repo merge
    [2026-03-07 19_18 From Parts Cart JLCPCB Parts.csv, 2026-03-07 20_19 From Parts Cart JLCPCB Parts.csv, Z80home_RevC.csv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]
2026-03-17 updates before brain surgery to reduce pin count
2026-03-17 split off dma code to make it fit in cpld.
2026-03-18 fix dma for 4 bits masked out
2026-03-18 fix wiring loop, do not use an output in wiring logic.
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2026-03-21 rewrite it all to get clean tests and hardware with DMA and ROM.
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2026-03-22 Reorg bus probe code for pycharm rather than vscode.
2026-03-22 Add some fake data to test the analysis notebook.
    [test-data.csv]
2026-03-22 Reorg the pycharm project again. update documentation with current status and software progress.
2026-03-25 add faceplate and display card
    [DIP12_HCMS-396X_BRA.step, DIP12_HCMS-397X_BRA.step, EA_DIP205G-4NLED.stp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]
2026-03-25 reorg documentation.
    [Zx50_FrontPanelDisplay.kicad_pcb]
2026-03-26 working on firmware, now have a real pico to play with.
2026-03-27 lots of hacking to get bus probe running.
    [Zx50 Bus Probe_RevB.kicad_sch, Zx50_BusProbe_RevA.0_bom.csv, Zx50_BusProbe_RevA.0_designators.csv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]
2026-03-27 enable wifi support for the bus probe
    [Zx50 Bus Probe_RevB.kicad_sch]
2026-03-28 Add extra banners and such to tcp server. updates to revb bus probe.
    [Zx50 Bus Probe_RevB.kicad_sch]
2026-03-28 updates for more robust tcp handing.
    [Zx50 Bus Probe_RevB.kicad_sch]
2026-03-29 fix syntax for pico commands.
    [pico_usb.py, pico_wifi.py]
2026-03-30 beef up pico wifi on disconnect handling. Remove .idea directories.
2026-04-08 Many updates and board revisions.
    - Backplane Rev D for better AC termination.
    - BusProbe revision, much smaller card, use surface mount, faster multiplexers.
    - Revised clock mezzanine to reduce ringing.
    [Zx50 Bus Probe_RevA.kicad_sch, Zx50 Bus Probe_RevB.kicad_sch, Zx50Backplane_RevD.6_bom.csv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]
2026-04-11 rewrite cpld code in more structured Amaranth state machine.
    [cpld_mem_RevA.kicad_sch]
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2026-04-25 tell fitter to keep some nets to avoid high fan out
    [zx50_mem_control.v]
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2026-04-25 update some tests that used wrong exit function
    [zx50_mem_control.v]
2026-04-29 revb memory board,
    [Zx50_MemoryCard_RevA1.kicad_pcb, Zx50_MemoryCard_RevA1.kicad_sch, Zx50_MemoryCard_RevB.kicad_pcb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]
2026-04-30 tweeks before refitting with quartus
    [Zx50_MemoryCard_RevB.kicad_pcb, fpga_mem_RevB.kicad_sch]
2026-05-01 more work on revb memory card, plus a diag program for rev a1.
    [Zx50_MemoryCard_RevB.kicad_pcb, fpga_mem_RevB.kicad_sch]
2026-05-02 reorg memory card firmware. create an mmu only version without dma for testing.
2026-05-03 clean up some test benches
    [Zx50_MemoryCard_RevA1.kicad_pcb]
2026-05-04 fixup pic z80 timing. add memory test script to pico
    [Zx50_MemoryCard_RevA1.kicad_pcb, Zx50_MemoryCard_RevB.kicad_pcb, Zx50_MemoryCard_RevB.kicad_sch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]
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2026-05-12 Lots of updates: Work on memory card Rev C with Lattice XO3LF, finish up the front panel card firmware for the pico., add some results for the clock mezzanine Rev B.
    [Zx50 Bus Probe_RevB.kicad_sch, Zx50_Clock_Mezzanine_RevB.kicad_sch, Zx50_FrontPanelCard.kicad_sch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]
2026-05-16 work on rev c1 with lattice lcmxo3lf
    [Zx50_MemoryCard_RevC1.kicad_pcb, Zx50_MemoryCard_RevC1.kicad_sch, Zx50_Memory_Rev_C1.0_bom.csv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]
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2026-05-16 board updates, front panel firmware updates, pic upates for booting
    [Zx50_FrontPanelCard.csv, Zx50_FrontPanelCard.kicad_pcb, Zx50_FrontPanelCard.kicad_sch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]
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2026-05-21 pico async is ok, merge to master. Also add recent work on hw boards
    [HackedInterposer.kicad_pcb, HackedInterposer.kicad_sch, Switch_Interposer_Rev_A_bom.csv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]
2026-05-28 reorg firmware
    [Zx50 Bus Probe_RevB.kicad_sch, Zx50_Backplane_RevD.kicad_pcb, Zx50_MemoryCard_RevC1.kicad_pcb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]
2026-05-30 refactor bus probe firmware for Rev B board
    [Zx50Backplane_RevD.13_bom.csv, Zx50Backplane_RevD.13_designators.csv, Zx50Backplane_RevD.13_positions.csv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]
2026-06-23 fixes for pic uart overflow
    [clock.c, display.py, hal.c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]
2026-06-28 fireware fixes for serial card and getting pico-pic async working better.
    [Zx50_MemoryCard_RevC1.kicad_pcb, Zx50_MemoryCard_RevC1.kicad_sch]
2026-06-28 version 1 of zx50 monitor.
    [Sheet 1-Table 1.csv, Sheet 2-Table 1.csv, Zx50Backplane_RevD.10_bom.csv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]
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2026-07-06 ctc_tick.z80 working, CPU RevB done
    [Zx50_Cpu_RevB.kicad_pcb, Zx50_Cpu_RevB.kicad_sch, Zx50_Serial.kicad_pcb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]
2026-09-14 updates to memory card and other changes
    [Zx50_Cpu_RevB1.kicad_pcb, Zx50_Cpu_RevB1.kicad_sch, Zx50_MemoryCard_RevC1.kicad_pcb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]
2026-09-14 reorganize cards to keep only current or future in top directory
    [2026-03-07 19_18 From Parts Cart JLCPCB Parts.csv, 2026-03-07 20_19 From Parts Cart JLCPCB Parts.csv, Sheet 1-Table 1.csv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]
2026-09-14 move another card to legacy, add hardware config to firmware readme
    [Zx50_Serial.kicad_pcb, Zx50_Serial.kicad_sch]
2026-09-14 more another legacy board, update readme for hardware.
    [Zx50 Bus Probe_RevA.csv, Zx50 Bus Probe_RevA.kicad_pcb, Zx50 Bus Probe_RevA.kicad_sch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]
2026-09-23 cpu revc1
    [Zx50_Cpu_RevB1.kicad_pcb, Zx50_Cpu_RevC1.kicad_pcb, Zx50_Cpu_RevC1.kicad_sch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]
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2026-09-23 init tb now runs against fpu
    [Zx50_Cpu_RevC1.kicad_pcb, coprocessor.kicad_sch]
2026-09-24 revise CPU for 12ns memory
    [Zx50_Cpu_RevC2.kicad_pcb, Zx50_Cpu_RevC2.kicad_sch, coprocessor.kicad_sch]
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2026-09-28 scrap the cpld, go fpga. starting to rewrite the FPU architecture documents.
    [ZX50_CPU_REVC3_bom.csv, ZX50_CPU_REVC3_designators.csv, ZX50_CPU_REVC3_positions.csv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]
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

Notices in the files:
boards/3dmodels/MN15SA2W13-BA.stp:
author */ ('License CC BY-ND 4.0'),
